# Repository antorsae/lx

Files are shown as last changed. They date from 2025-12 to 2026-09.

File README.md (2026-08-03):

# LX521 Polar Analysis Pipeline

A Python pipeline for processing acoustic polar response measurements from REW (Room EQ Wizard) and generating comprehensive visualizations for speaker driver analysis.

**Live Demo:** [https://antorsae.github.io/lx/](https://antorsae.github.io/lx/)

## Features

- Load and process `.mdat` measurement files via REW API
- Apply time gating to remove room reflections
- Support for multiple measurement sets with different naming conventions
- Full 360° polar plots when front and rear measurements are available
- Generate directivity analysis (DI, beamwidth)
- Interactive HTML plots (gzip compressed) and static PNG exports
- Interactive frequency response explorer with IIR EQ, per-driver gain/delay/invert, SUM view, and Hypex Filter Design `.dsp` + CamillaDSP YAML I/O (Config.xml conversion via external tools)
- Crossover match analysis for multi-driver systems
- **REW slot management**: Automatic batch unloading prevents hitting REW's ~100 measurement limit

## Requirements

- Python 3.11+
- [REW (Room EQ Wizard)](https://www.roomeqwizard.com/) with API enabled
- macOS (for automatic REW launch)

## Installation

```bash
# Create virtual environment with uv
uv venv
source .venv/bin/activate

# Install dependencies
uv pip install -r requirements.txt
```

## Configuration

Edit `config.py` to configure measurement sets:

```python
MEASUREMENT_SETS = {
    "andres": {
        "path": Path("measurements/andres"),
        "pattern_type": "andres",  # F{angle}-{driver}.mdat
        "has_rear": False,
        "hdf5_file": "polar_data_andres_l22mg_first_lobe.h5",
        "output_dir": OUTPUT_DIR / "andres",
    },
    "juan-baffleless": {
        # Combined Juan driver measurements (GRS PT6816, SS10F8414G10,
        # L22MG nude, ND25FW4 nude 18mm, L10NEO, MU10RB-SL,
        # SS10F8424G00, L26RO4Y).
        # Multi-source sets merge directories.
        "path": None,
        "sources": [
            {"path": Path("measurements/juan/GRS PT6816 A MIC ON AXIS"), "pattern_type": "juan"},
            {"path": Path("measurements/juan/ScanSpeak 10F8414G10"), "pattern_type": "scanspeak"},
            {"path": Path("measurements/juan/SEAS L22MG NUDE MIC ON AXIS"), "pattern_type": "juan"},
            {"path": Path("measurements/juan/DAYTON ND25FW4 ANIDADOS 18 MM NUDE"), "pattern_type": "juan"},
            {"path": Path("measurements/juan/POLARES L10NEO"), "pattern_type": "juan"},
            {"path": Path("measurements/juan/SEAS MU10RB SL POLARES"), "pattern_type": "juan"},
            {"path": Path("measurements/juan/ScanSpeak 10F8424G00"), "pattern_type": "juan_suffix"},
            {"path": Path("measurements/juan/L26RO4Y POLARES EN BAFFLE CILINDRICO VER NOTA"), "pattern_type": "juan"},
        ],
        "pattern_type": "juan",  # default (ignored when sources defined)
        "has_rear": True,
        "hdf5_file": "polar_data_juan_baffleless.h5",
        "output_dir": OUTPUT_DIR / "juan-baffleless",
        "measurement_metadata_overrides": {
            "L22MG (nude)": {
                "measurement_distance_m": 0.50,
                "measurement_height_reference": "l22mg",
                "notes": "Measurement distance: 50 cm from driver. Mic height: L22MG/LM.",
            },
        },
    },
    "lx521-system": {
        "path": Path("measurements/juan/LX521 POLARES 0_180 GRADOS"),
        "pattern_type": "lx521_system",  # {name} {angle} GRADOS {F|REAR}.mdat
        "has_rear": True,
        "hdf5_file": "polar_data_lx521_system.h5",
        "output_dir": OUTPUT_DIR / "lx521-system",
    },
}
```

### Supported Naming Conventions

| Pattern | Example | Description |
|---|---|---|
| `andres` | `F45-10F8424.mdat` | Front-only measurements |
| `kaspar` | `F0-UM MU10RB (Kaspar DSP).mdat` | Same shape as `andres`, kept separate from its combination-file and diagnostic-HDF5 rules |
| `juan` | `GRS PT6816 45 F.mdat` | Front (F) and Rear (R) measurements |
| `scanspeak` | `SS10F8414G10 45 F.mdat` | Same convention as `juan` |
| `juan_suffix` | `SS10F8424G00 45 F sn 074.mdat` | Same as `juan`, allowing text after `F`/`R` |
| `lx521_system` | `LX521 HIGH MID INV ORIGINAL 45 GRADOS F.mdat` | Full system measurements with GRADOS notation |

Measurement sources may be nested below each configured source directory. This supports source layouts such as `POLARES L10NEO/FRONTALES` and `POLARES L10NEO/TRASERAS`.

## Usage

### Enable REW API

1. Open REW
2. Go to Preferences → API
3. Enable the API server (default port: 4735)

### Run Pipeline

```bash
# Process default measurement set (andres)
python run_pipeline.py

# Process specific measurement set
python run_pipeline.py -m juan-baffleless

# Skip data loading (use existing HDF5)
python run_pipeline.py -m juan-baffleless --skip-loading

# Skip visualization generation
python run_pipeline.py --skip-viz

# Disable smoothing (raw data)
python run_pipeline.py --no-smoothing
```

### Command Line Options

| Option | Description |
|---|---|
| `-m, --measurement-set` | Which measurement set to process (default: andres) |
| `--skip-loading` | Skip REW loading, use existing HDF5 file |
| `--skip-viz` | Skip visualization generation |
| `--no-smoothing` | Disable frequency response smoothing (default: no smoothing) |

### Makefile Automation

```bash
make all              # Full rebuild: data + viz + sync
make data             # Load REW data → HDF5 (skips when HDF5 is newer than .mdat)
make viz              # Regenerate all visualizations (uses existing HDF5)
make viz-andres       # Regenerate only andres set
make sync             # Sync output/ to docs/ + regenerate landing pages
make deploy           # sync + commit + push to GitHub Pages
make help             # Show all targets
```

`make all` now runs `viz` and `sync` in parallel (default `JOBS=8`). Override with `JOBS=4 make all` or `make -j16 all`.

## Output Structure

```
output/
├── data/
│   ├── polar_data_andres_l22mg_first_lobe.h5 # Andres first-lobe validation target
│   ├── polar_data_andres.h5                  # Legacy strongest-lobe diagnostic
│   ├── polar_data_juan_baffleless.h5         # Processed data (juan-baffleless set)
│   ├── polar_data_kaspar.h5                  # Processed data (kaspar set, on-axis only)
│   └── polar_data_lx521_system.h5            # Processed data (lx521-system set)
├── andres/                            # Visualizations for andres set
│   ├── static_plots/
│   │   ├── core/                     # DI, beamwidth, contour plots
│   │   └── polar/                    # Polar diagrams
│   └── interactive/                  # HTML interactive plots (gzip compressed)
├── juan-baffleless/                   # Visualizations for juan-baffleless set
│   ├── static_plots/
│   └── interactive/
├── lx521-system/                      # Visualizations for lx521-system set
│   ├── static_plots/
│   └── interactive/
└── kaspar/                            # On-axis-only set: no static/polar plots
    └── interactive/                   # Frequency response explorer + summary
```

### On-Axis-Only Sets

A set with a single measurement angle sets `"single_angle": True` in its
config entry. Directivity, beamwidth, contour and polar output is skipped
(there is no angular coverage to compute it from), and only the frequency
response explorer and measurement summary are generated. Such a set is still
offered as a loadable overlay in every other set's explorer, but it is not
interpolated onto their angle grids — its curves are simply hidden at angles
it was not measured at.

Per-set `gate_left_ms`, `gate_right_ms` and `smoothing` keys override the
`config.py` defaults, for captures where the default 0.5/3.0 ms gate would
discard the band of interest.

## Pipeline Workflow

1. **Connect to REW API** - Launches REW if not running
2. **Load Measurements** - Reads `.mdat` files for each driver/angle
3. **Auto-fix Timing** - Aligns impulse response peak to t=0
4. **Apply Time Gating** - Removes room reflections (default: 0.5ms / 3.0ms)
5. **Get Frequency Response** - Retrieves magnitude/phase data
6. **Unload from REW** - Frees REW memory slots after each driver (batch unload)
7. **Save to HDF5** - Stores processed data for visualization
8. **Generate Visualizations** - Creates all plots and analysis

## REW Slot Management

REW has a limit of ~100 measurement slots. When processing many drivers, the pipeline automatically unloads measurements after each driver to prevent hitting this limit.

```python
# Manual control (if needed)
from polar_data_loader import PolarDataLoader

loader = PolarDataLoader(data_directory="path/to/data")

# Check current count
print(f"Loaded: {loader.get_measurement_count()}")

# Unload specific measurement
loader.unload_measurement(uuid)

# Unload all measurements
loader.unload_all_measurements()

# Disable batch unload (not recommended for large datasets)
data = loader.load_all_drivers(batch_unload=False)
```

## Generated Visualizations

### Static Plots (PNG)
- Directivity Index (DI) comparison
- Beamwidth curves (-3dB, -6dB)
- Dipole null analysis
- Normalized/Absolute contour plots
- Polar diagrams (single driver and overlaid)
- Crossover match analysis
- Frequency response by angle (absolute and normalized to 0°)

### Interactive Plots (HTML)
- DI comparison with hover info
- Beamwidth comparison
- Contour heatmaps
- Polar explorer with frequency slider and manual entry
- Crossover analysis per frequency
- **Multi-driver frequency response explorer** with:
  - Driver overlay comparison with distinct markers
  - Per-driver gain offsets, delay (us), and invert toggles
  - Angle toggle grid with quick-select buttons
  - SUM display (off / overlay / only) with optional phase
  - **IIR filter editor**: Peaking, HP, LP, Highshelf, Lowshelf filters
  - Visual crossover overlay (LR/BW) and auto-optimize tools
  - Real-time filter simulation on all angles
  - Hypex Filter Design `.dsp` import/export (not miniDSP), Config.xml conversion via external tools, and CamillaDSP-compatible YAML import/export
  - LocalStorage persistence for filters, crossovers, and UI state
  - Optional extra driver datasets (e.g., Juan baffleless) loaded on demand

## File Structure

| File | Description |
|---|---|
| `run_pipeline.py` | Main entry point |
| `config.py` | Configuration settings |
| `polar_data_loader.py` | REW API interface and data loading |
| `generate_visualizations.py` | Plot generation |
| `directivity_calculations.py` | Acoustic calculations |
| `Makefile` | Build automation (data → viz → docs → deploy) |
| `requirements.txt` | Python dependencies |

## Adding New Measurement Sets

1. Add entry to `MEASUREMENT_SETS` in `config.py`
2. If using a new naming pattern, add an entry to `_PATTERN_DEFS` (and/or `_PATTERN_ALIASES`) in `polar_data_loader.py`
3. Run: `python run_pipeline.py -m your_new_set`
4. Run `make sync` to publish regenerated output under `docs/`

## License

MIT

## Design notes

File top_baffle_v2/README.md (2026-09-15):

# Open-baffle experiments — Stock, Slim and Obiwan

Inspired by **Siegfried Linkwitz’s ideas and openness in sharing his work**,
this project explores a compromise in his design: the roughly **7.5 kHz
crossover between the upper midrange and tweeters**. A high crossover helped
preserve the intended dipole radiation pattern through that transition,
leaving the small upper-midrange driver covering roughly **1–7.5 kHz**.
See Linkwitz’s [design rationale](https://www.linkwitzlab.com/LX521/Description.htm)
and [frequency-range discussion](https://www.linkwitzlab.com/LX521/FAQ.htm).

The goal is to explore alternative tweeters, waveguides and baffle shapes
that support **a lower crossover while preserving dipole behavior**. By
handing more of the high-frequency work to the tweeters, we aim to reduce
upper-midrange distortion and improve the performance of the whole system.
Measurements of directivity and distortion, together with listening
comparisons, will determine whether that goal is achieved.

**Stock and Slim** closely follow Linkwitz’s baffle design. **Obiwan** is a
new modular design built as an experimentation platform: interchangeable
tweeter arrangements and quickly removable wings make it easier to compare
drivers, waveguides and acoustic boundaries without rebuilding the entire
baffle.

## Build and print

**The current manufacturing target is the Bambu H2C with two 0.6 mm High
Flow nozzles.** Start with the [H2C file guide](to_print/h2c/README.md) for
STLs, editable projects, audited slices, materials and per-speaker quantities.
`make` now builds the H2C shelf; `make PRINTER=P2S all` selects the earlier
pipeline. The pre-migration source checkpoint and rewritten commit references
are recorded in the [generated-file history guide](docs/GENERATED_HISTORY.md).

H2C uses one LM carrier for Obiwan and one full wing per side, including
Dayton ND25FN-4 waveguide wings. Stock/Slim use one complete LM without the stand, or two
LM pieces with the stand, plus their matching upper module. Driver spacing
and mounting seats remain unchanged. The Dayton ND25FN-4 waveguide has separate PETG-GF/PLA and
PETG Translucent/PLA Translucent projects.

Choose one mounting state and one complete configuration per speaker.

The earlier [P2S build guide](docs/BUILD_GUIDE.md) remains a hardware and
assembly reference. Its generated P2S
[file guide](to_print/FILE_GUIDE.md) lists all 42 choices and actual sliced
job estimates. There are 68 sliced projects and 8 projects requiring GUI
slicing across alternate nozzle/material lanes.

The [complete parts and magnet catalog (PNG)](images/generated/catalog/ALL_ITEMS_MAGNET_CATALOG.png)
shows the 78 pre-H2C part variants, their buried magnet locations and types,
shared parts, alternate tweeters and separate test fixtures. The accompanying
[file map](images/generated/catalog/README.md) identifies every source.

For H2C material mapping and process exceptions, use the generated
[H2C file guide](to_print/h2c/README.md). The shared [print and hardware
policies](docs/PRINT_POLICIES.md) retain the earlier printer details: structural LM/UM infill is 100%, wings
are 10%, and the Dayton ND25FN-4 waveguide uses M3 fasteners. The [current update
report](review/print_policy_update_20260912/SUMMARY.md) links the regenerated
print files, support exceptions and D6 magnet test pair.

Stock is the canonical CAD baseline. Slim is experimental. Obi-Wan and BMR
options are qualification candidates; printed fit, long-term loaded behavior
and acoustic performance are not established by CAD renders or passing code
checks. See the [current test procedure](docs/PETG_GF_QUALIFICATION.md).

## Product comparison

One row per product, each showing both stand states, then one row for the
tweeter options. Every render uses one camera and one declared frame per scale
group, so the panels within a row and the three product rows against each
other are directly comparable. Regenerate the product rows with
`make iso_matrix`; `make h2c_review` also refreshes the upper and wing comparisons.

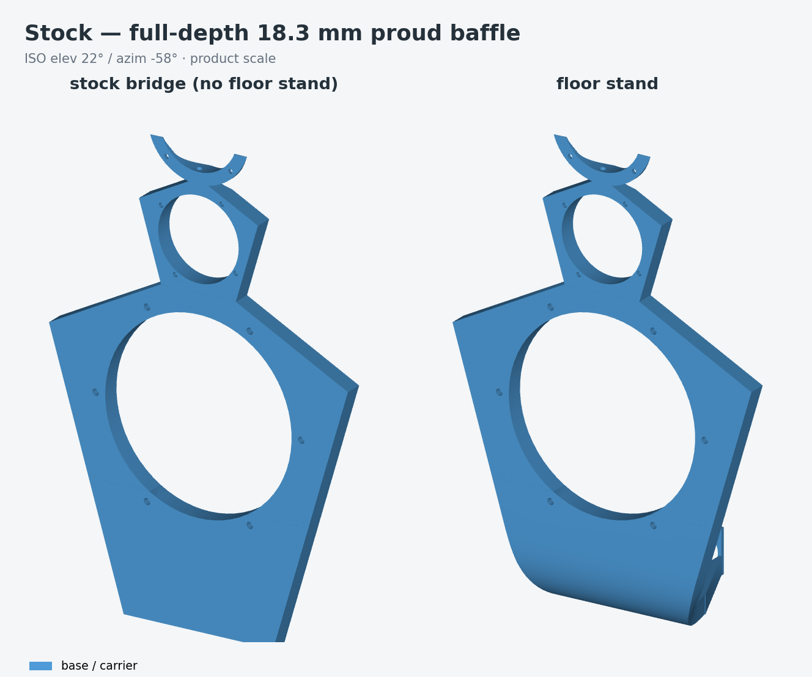
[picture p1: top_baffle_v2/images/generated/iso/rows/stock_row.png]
Stock, both stand states


Stock is the canonical product: the complete 18.3 mm outline, with two core
pieces on H2C without the stand or three with the stand. The earlier P2S
split uses four — [`docs/stock.md`](docs/stock.md).

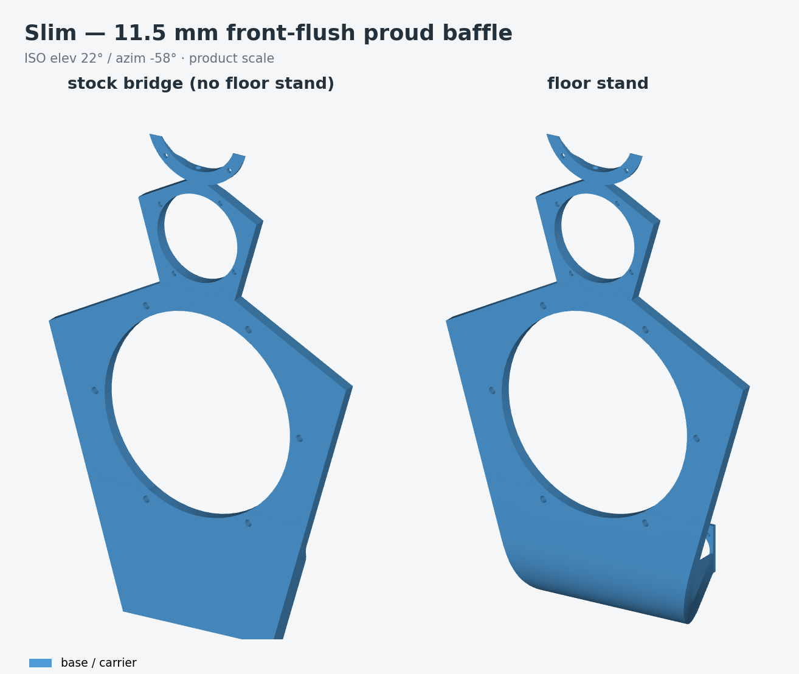
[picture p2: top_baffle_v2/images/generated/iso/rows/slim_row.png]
Slim, both stand states


Slim is the same outline with the acoustic field thinned to 11.5 mm, sharing
one front plane end to end — [`docs/slim.md`](docs/slim.md).

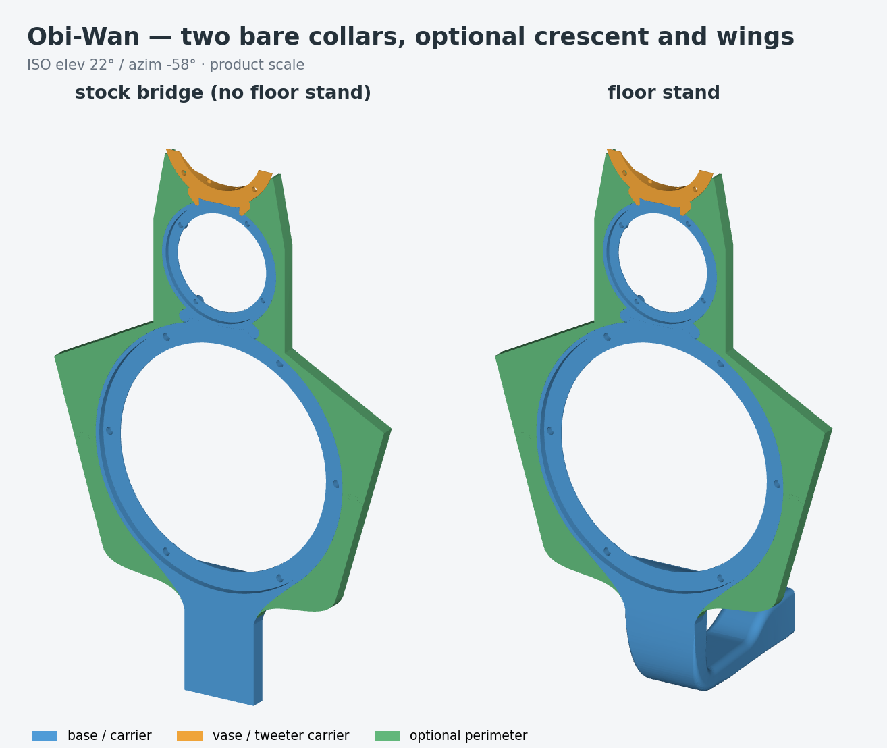
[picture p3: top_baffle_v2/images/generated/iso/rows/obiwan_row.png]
Obi-Wan, both stand states


These two Obiwan panels show the regular UM, ND25FW-4 crescent and flat
wings. The integrated ND25FN-4 upper is a second body choice on the same LM,
shown alongside the regular uppers below — [`docs/obiwan.md`](docs/obiwan.md).

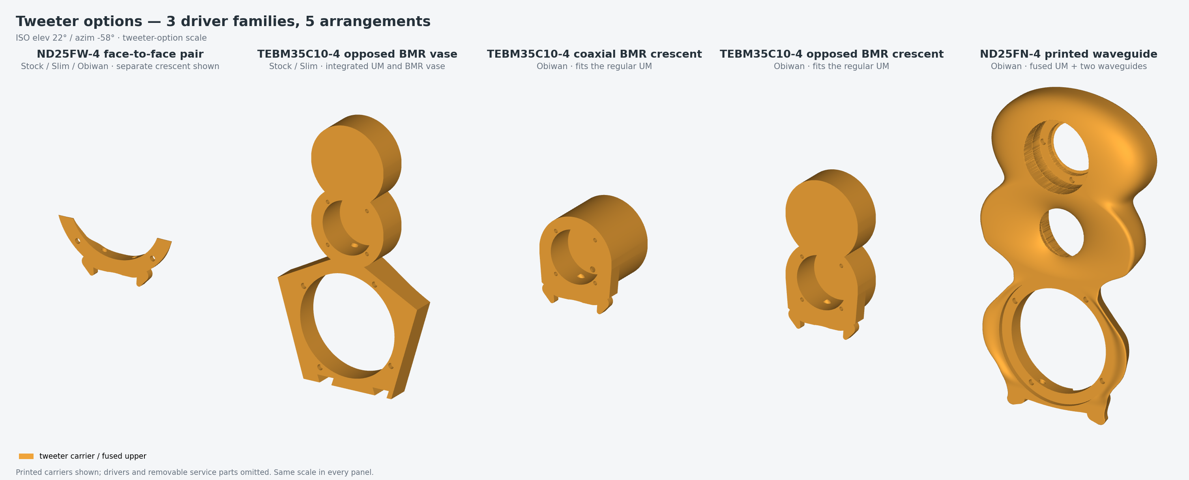
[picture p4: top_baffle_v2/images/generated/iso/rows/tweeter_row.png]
Three tweeter families, five arrangements, at the same scale


Left to right: ND25FW-4 crescent; BMR Stock/Slim vase; BMR Obiwan coaxial
crescent; BMR Obiwan opposed crescent; **ND25FN-4 integrated UM/waveguide**.
These are the actual printed carriers at one scale. Drivers and removable
service caps are omitted so their construction can be compared.

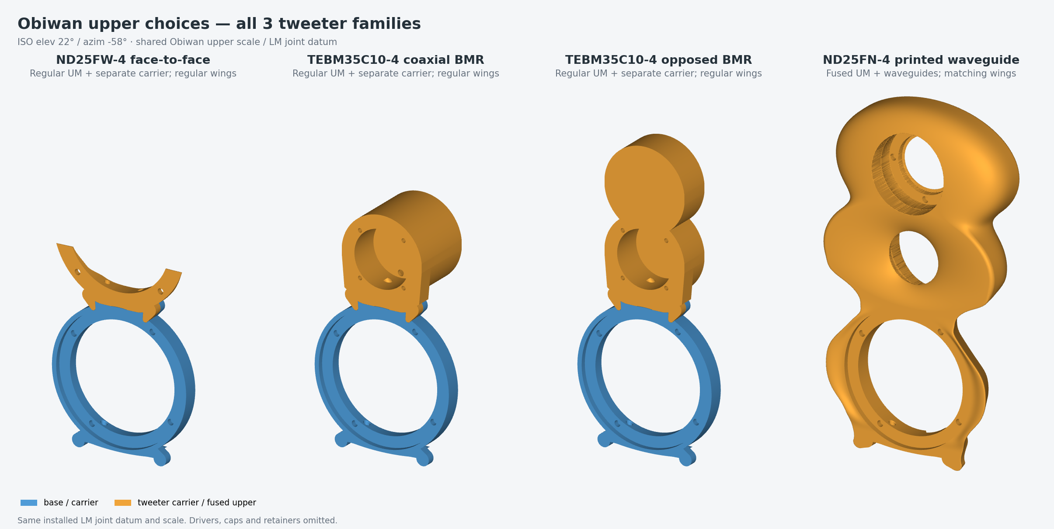
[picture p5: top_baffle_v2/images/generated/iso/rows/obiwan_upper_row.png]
Obiwan complete upper choices, aligned at the common LM joint


The complete Obiwan uppers share the same LM joint datum in this row:
ND25FW-4, coaxial BMR, opposed BMR and ND25FN-4 waveguide. The first three
retain the regular UM; the fourth includes its UM in the curved body.

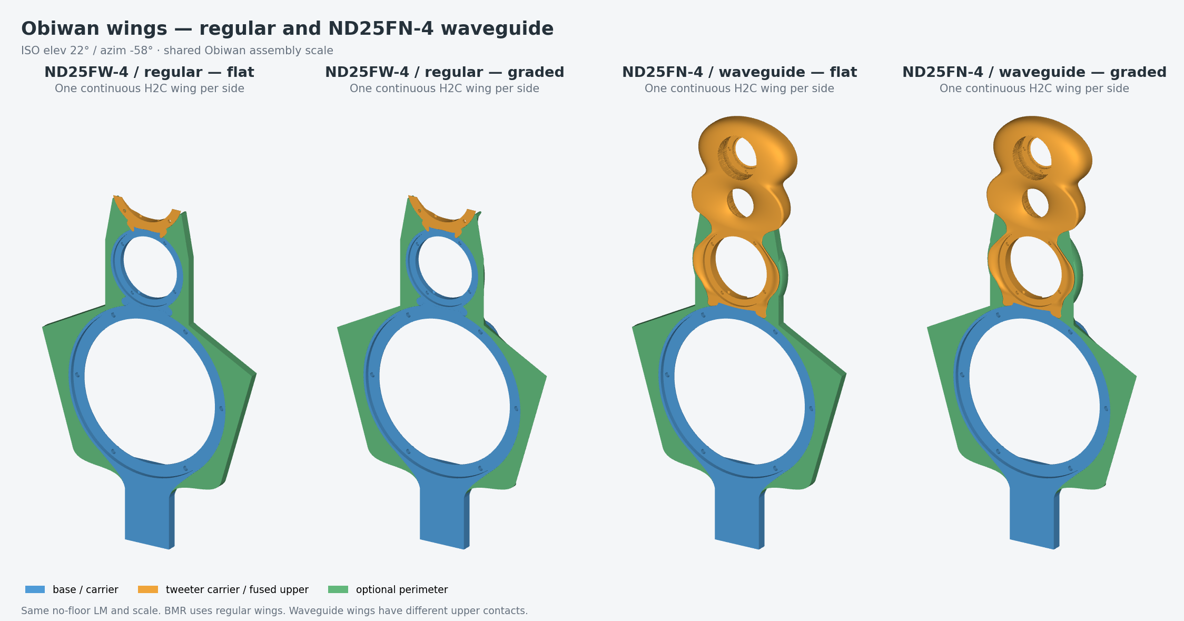
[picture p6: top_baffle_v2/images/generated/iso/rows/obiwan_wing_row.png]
Regular and ND25FN-4 Obiwan assemblies with flat and graded H2C wings


Choose flat or graded wings to match the selected upper. The two regular
wing styles fit ND25FW-4 and BMR. ND25FN-4 uses its own curved upper contacts
and matching wings, shown on the same no-floor-stand LM here.

## Tweeter options

The project offers **three tweeter families**. BMR has multiple mount layouts;
those layouts are alternatives within one driver family.

| Tweeter family | Construction | Stock / Slim | Obiwan |
|---|---|---|---|
| **Dayton ND25FW-4 face-to-face** | Two domes with factory waveguide faceplates | Standard upper module with integral crescent | Separate crescent on the regular UM |
| **Tectonic TEBM35C10-4 BMR** | Two balanced-mode radiators; opposed or coaxial layout | Replace the whole upper module with the opposed-BMR version | Choose the coaxial or opposed BMR crescent on the regular UM |
| **Dayton ND25FN-4 waveguide** | Two faceplate-free domes in printed front/rear waveguides | No compatible upper module currently provided | Replace the whole UM and crescent with one fused body; use the matching waveguide wings |

The **ND25FN-4 waveguide** is the former retained-package design, now named
for its driver and construction. Its organic MU10 surround and tweeter
waveguides form one piece, with an enclosed cable gallery, two service caps
and two M3 retainers. The same body fits both Obiwan stand configurations;
it retains the LM joint and meets the LM front flush without covering it.
H2C provides one continuous matching wing per side, in flat or graded form.
Regular Obiwan wings have different upper contacts and cannot substitute.
Stock/Slim BMR uppers also have different magnet stations: their matching
perimeter is not supplied, so use the standard shoulders or B1 wings only
with ND25FW-4.

Start with the [three-family selection guide](docs/TWEETER_OPTIONS.md) and
[Dayton ND25FN-4 waveguide assembly guide](docs/DAYTON_ND25FN4_WAVEGUIDE.md).
The [H2C file catalog](to_print/h2c/README.md) includes all three families,
with separate PETG-GF/PLA and PETG Translucent/PLA Translucent jobs for the
ND25FN-4 body, accessories and wings. BMR and ND25FN-4 remain qualification
candidates: inclusion and successful slice checks do not establish physical
fit, retention or acoustic performance. The earlier P2S catalog and CAD-only
BMR-slim variants are documented separately in [Variants](docs/VARIANTS.md).

The separate Purifi PTT1.3 experiment remains in
`build/ptt_crescent_PTT1.3T04-HAG-01/`; it is not one of the three supported
selection families in the current H2C print catalog.

## Products

The current print catalog is [H2C](to_print/h2c/README.md). The earlier
product-grouped CAD facade is:
[`artifacts/`](artifacts/README.md).

| Product | Geometry | Optional perimeter | Tweeter options | Status | Doc |
|---|---|---|---|---|---|
| [Stock](artifacts/stock/) | B2, 304.802 x 453.457 x 18.3 mm | A-comp shoulders **or** B1 wings | ND25FW-4 crescent (integral) or TEBM35C10-4 BMR vase | Canonical CAD | [`docs/stock.md`](docs/stock.md) |
| [Slim](artifacts/slim/) | V1L + V1; 11.5 mm front-flush acoustic field, full-depth bottom strip | matching V1 shoulders **or** V1 wings | ND25FW-4 crescent (integral) or TEBM35C10-4 BMR vase | Experimental | [`docs/slim.md`](docs/slim.md) |
| [Obiwan](artifacts/obiwan/) | LM + regular UM or integrated UM/waveguide; floor and stock-bridge states | flat or graded wings matched to the upper | ND25FW-4 crescent, coaxial/opposed BMR crescent, or fused ND25FN-4 waveguide + UM | Candidate; not release-authorized | [`docs/obiwan.md`](docs/obiwan.md) |

The original state-oriented build outputs remain in `build/floor_stand/`,
`build/no_floor_stand/`, and `build/wings/` because the validation pipeline depends on
them. `artifacts/` adds stable names, hashes, and product grouping through
relative links without duplicating large CAD files. See
[`docs/PROJECT_SCOPE.md`](docs/PROJECT_SCOPE.md) for the intent, assumptions,
and release boundary; [`docs/REPOSITORY_STRUCTURE.md`](docs/REPOSITORY_STRUCTURE.md)
documents the implemented source/package and generated-state boundary.

## Use the delivered files

Open the [H2C file guide](to_print/h2c/README.md), choose a compatible
configuration and material lane, and use its editable `.3mf` or audited
`.gcode.3mf`. Those projects retain the supports, infill modifiers and
measured magnet insertion pauses. An STL contains geometry only.

```sh
make h2c_prepare        # prepare H2C projects from current geometry
make h2c_validate       # slice and audit; reuse current verified results
make h2c_review         # upright assembly views
make h2c_docs           # refresh the file and tweeter-family guides
```

The [earlier P2S file guide](to_print/FILE_GUIDE.md) remains available for
that printer. Its material mapping and split wings are specific to P2S.
No ZIP is required for either workflow.

## Develop and regenerate

Use Python with the dependencies in `cad-remote-requirements.lock`. The
vendored driver references are self-contained under `vendor/SEAS/`; no
sibling checkout is needed for those inputs. VTK renders CAD with an actual
depth buffer, and Matplotlib/Pillow compose the comparison panels.

```sh
make PYTHON=<venv>/bin/python             # current H2C pipeline
make PRINTER=P2S artifacts          # relink and rehash the CAD facade
make PRINTER=P2S iso_matrix # regenerate the CAD comparison images
make PRINTER=P2S delivery_refresh # bind already-published files and regenerate the file guide
```

The current H2C pipeline runs locally. The earlier P2S CAD pipeline defaults
to the original maintainer's remote host `osado.lan`; select
`LX_CAD_EXECUTION=local` when running that pipeline on another workstation. Remote execution,
resource limits and promotion are documented in [REMOTE_BUILD.md](docs/REMOTE_BUILD.md).
A source change requires current CAD/slice provenance before republishing;
validation does not silently regenerate or re-certify old geometry.

## Generated artifact layout

Current H2C manufacturing outputs live in `build/h2c/`; the current print
catalog lives in `to_print/h2c/`. Both stand states are included. The earlier
P2S pipeline and the shared source authorities use the following layout:

    build/floor_stand/      LX_STAND_FOOT=1: Stock/Slim fused foot + NL8 panel;
      stl/  *.step  *.png     Obi-Wan integral LM-owned W64 floor stem/foot + NL8 panel
    build/no_floor_stand/   LX_STAND_FOOT=0: Stock/Slim flat piece_bottom + bridge;
      stl/  *.step  *.png     Obi-Wan solid bridge web fused into the LM core
    build/wings/{flat,graded}/    Obi-Wan acoustic wing families
    build/vase_TEBM35C10-4/{stock,slim}/   opposed-BMR vase, full Ø63 lands
    build/bmr_slim_TEBM35C10-4/proud/{stock,slim}/  Ø56-core/lobed vase alternatives
    build/bmr_crescent_TEBM35C10-4/       candidate BMR crescents, both variants
    build/bmr_slim_TEBM35C10-4/           lobed Obi-Wan CAD-only candidates
    build/common/           flag-independent shared outputs
    images/generated/iso/   the product-comparison cells and rows/ images

Each folder contains all proud-family variants and the matching Obi-Wan
core/add-on set. In Stock and Slim, `piece_bottom` is the only functionally
different base piece; the other base STLs can differ by <0.05 mm as
the foot-entry knots move. In Obi-Wan, the UM core is state-independent. The
floor LM owns the integral stand and only the shared upper shoulder; the
no-floor LM owns the complete fused bridge web. Their lower magnet axes are
coincident on that shoulder, but floor mode has no shallow skirt or rail below
it.
`build/common/attachments.step` is flag-independent and is
promoted as one shared file. The `LX_STAND_FOOT` environment flag defaults to 1.

Per-product printable-piece tables live in the product docs. The two
product-independent STL groups are:

| STL in `build/<state>/stl/` | Footprint (mm) | Used by |
|---|---|---|
| `lx521_coupon_*` | small blocks/gauges | calibration, routing, and clocking checks ([`docs/PRINTING.md`](docs/PRINTING.md)) |
| lx521_polar_base_1..2of2 | Ø216 / 169×185 | polar-measurement turntable under the stand foot (floor_stand only) |

## Shared source and evidence map

Geometry modules are listed in each product's doc. These are the shared
entry points:

| File | What |
|---|---|
| `scripts/export_piece_stls.py` | Exports the print-ready proud-family or Obi-Wan core/add-on STLs (`--variant`, `--outdir`) and one exact adjacent, hash-bound `.print.json` authority for every STL |
| `scripts/export_steps.py` | Exports a module's `gen_step()` to STEP via build123d's native exporter (`<module.py> --output <path>`) — no CAD-skill dependency |
| `scripts/gen_product_iso_matrix.py` | Renders the standardized product-comparison ISO set into `images/generated/iso/` from the promoted STEP files; one shared camera, one declared frame per scale group |
| `Makefile` | Generates STEPs/STLs/PNGs for both stand states into `build/floor_stand/` and `build/no_floor_stand/` (see "Generated artifact layout"). Local OCC jobs are serial; the remote executor uses bounded parallel slots, and every CAD subprocess runs through `scripts/run_memory_guarded.py`. |
| `scripts/remote_cad.py` / `cad-remote-requirements.lock` | Content-addressed SSH executor, resumable job control, verified artifact return, and exact remote Python environment |
| `review/captive_magnet_slice_audit/CAPTIVE_MAGNET_PAUSE_MANIFEST.md` | Authoritative per-STL front-face-down orientation, actual sliced open/closing layers, Bambu Custom park/pause/restore events, grouped magnet counts, and local-axis polarity |
| `review/CAPTIVE_MAGNET_ARTIFACT_INVENTORY.md` | Clickable inventory of all 58 magnet-bearing STL records, their 56 locally generated/directly loadable G-code-bearing Bambu 3MF projects, descriptive piece names, and exact magnet counts; also reconciles the 86 transverse and eight exact split-proxy stations |
| `build/<state>/stl/*.stl` and `build/wings/{flat,graded}/stl/*.stl` | The enforced acoustic-print inventory is 39 nonpolar front-face-down STL/sidecar pairs in each stand state plus ten flat and ten graded pairs: 98 exact pairs total. Every acoustic piece is source-X180 with only an optional in-bed Z rotation and its front datum at STL Z=0. A missing, orphaned, stale-hash, tilted, or translation-inconsistent `<stem>.print.json` fails release validation. The two floor polar-index jigs are the sole orientation-sidecar exclusions because they are fixtures with no acoustic front-face datum. |

The generated directories are **candidate packages**, not physical-release
authorization: even `make release` performs CAD, artifact and manifold checks
only, and the Obi-Wan state manifests record `release_authorized: false`.

## Documentation

Products:

- [`docs/stock.md`](docs/stock.md) — Stock: key dimensions, print split,
  proud cable routing, magnet attachment, assembly.
- [`docs/slim.md`](docs/slim.md) — Slim: V1 vase, V1L LM section, the
  keyed 283° UM outlet.
- [`docs/obiwan.md`](docs/obiwan.md) — Obi-Wan: two-collar geometry,
  buried routes, floor/no-floor structure, structural screens, assembly.

Cross-cutting authorities:

- [`docs/PROJECT_SCOPE.md`](docs/PROJECT_SCOPE.md) — intent, three-product
  inventory, CAD brief, assumptions, release boundary.
- [`docs/REPOSITORY_STRUCTURE.md`](docs/REPOSITORY_STRUCTURE.md) — layout and
  the source/generated-state boundary.
- [`docs/VARIANTS.md`](docs/VARIANTS.md) — variant/add-on catalog, envelope
  compatibility matrix, hardware, and retired C7/V0 design history.
- [`docs/PRINTING.md`](docs/PRINTING.md) — filament, slicer profile, coupons,
  fastener torques, insert installation, magnet pauses, print constraints.
- [`docs/REMOTE_BUILD.md`](docs/REMOTE_BUILD.md) — remote executor, cache
  seeding, promotion transaction, memory profiles.
- [`docs/CAPTIVE_MAGNET_SLICING.md`](docs/CAPTIVE_MAGNET_SLICING.md) — pause
  and embed workflow.
- [`docs/obiwan_acoustic_wings_spec.md`](docs/obiwan_acoustic_wings_spec.md) —
  flat/graded wing design authority.
- [`docs/obiwan_physical_qualification.md`](docs/obiwan_physical_qualification.md)
  — fail-closed physical qualification record.
- [`docs/README.md`](docs/README.md) — the complete documentation index.

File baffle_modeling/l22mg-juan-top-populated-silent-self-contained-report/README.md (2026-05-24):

# L22MG Juan Top-Baffle Populated-Silent Modeling Report

Generated: 2026-05-24

## Summary

No current populated-silent model passes the acceptance gate. The full 300-1200 Hz normalized-polar RMS target is `<= 1.5 dB`; the best full-band result is `4.088 dB`.

The dominant blocker is the measured Juan top-baffle target null at `300.293 Hz / 75 deg`. At that point the L22-alone target is `-29.894 dB` normalized, while the naked L22 measurement is `-9.594 dB`; the implied top-minus-nude transfer is `-20.300 dB`. The separate top-baffle combo capture is `-18.024 dB` at the same point, or `+11.870 dB` above the L22-alone target. This is a target-quality/repeatability warning, not an approved data exclusion.

Under the repo's existing diagnostic `target > -20 dB` mask, the best current model is `modal full2 populated` at `1.587 dB`, narrowly ahead of `compact2 populated` at `1.594 dB`. That diagnostic is close to the `1.5 dB` target, but it is not the acceptance calculation.

## Policy Alignment

- Validation source: `output/data/polar_data_juan_baffleless.h5`, driver `L22MG (nude)`.
- Validation target: `output/data/polar_data_juan_lx521_top_raw.h5`, driver `L22MG (LX521 top raw)`.
- Target angles: HDF5 target angles `[0, 15, 30, 45, 60, 75, 90]`; no angular interpolation.
- IR peak policy: `direct_ir_peak_policy=first-strong`, mirrored from the published target artifact.
- Passive treatment: `populated-silent`; passive UM/tweeter driver positions are modeled as populated/solid silent obstructions, not open holes.
- Validation alignment: one global scalar gain plus one global delay only; no angle, band, rear, or source dB fitting.

## Baffle and Measurement Renders

The modeled baffle is the LX521 top baffle with the L22 cutout and populated-silent passive positions. The 3D panel is the OBJ mesh emitted by the current compact2 artifact.

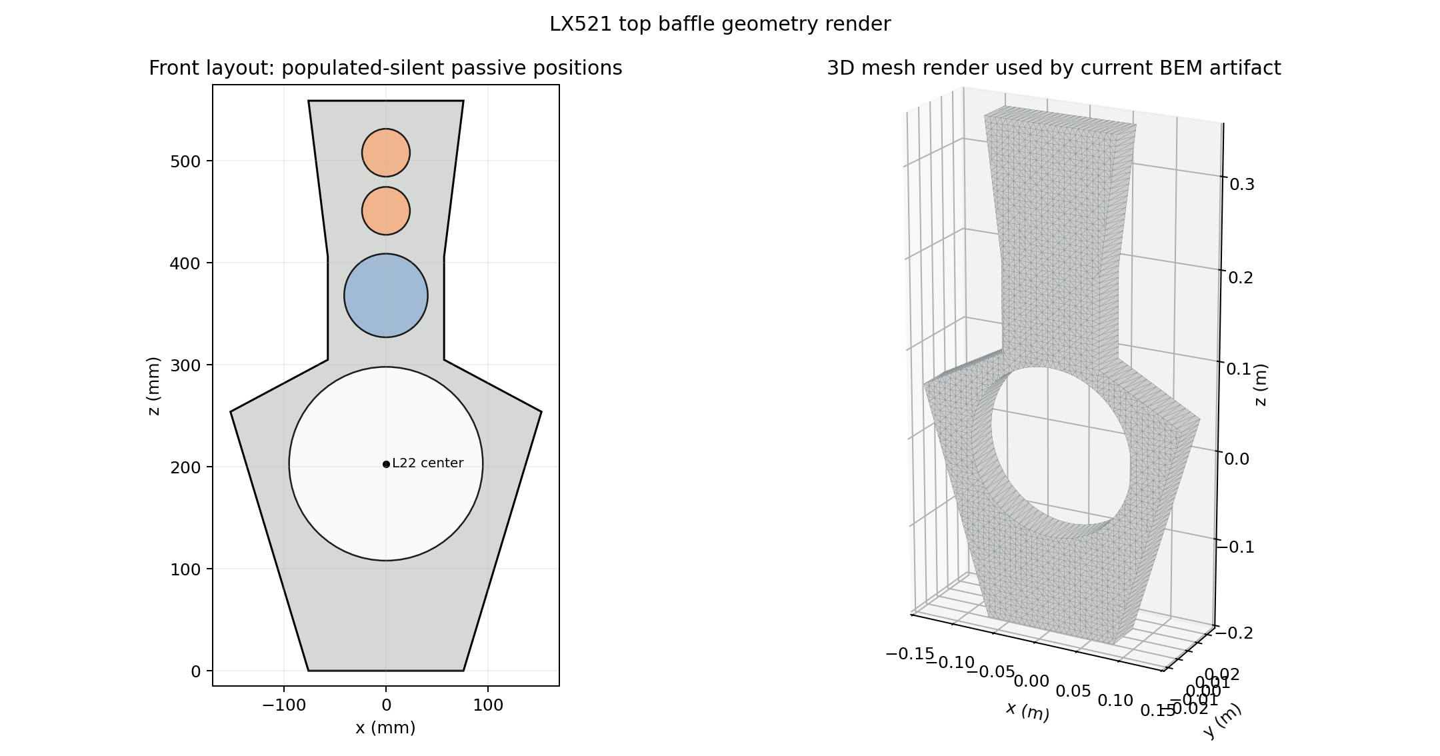
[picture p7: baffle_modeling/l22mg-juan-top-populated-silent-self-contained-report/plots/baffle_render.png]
LX521 top baffle render


The measurement render shows the naked L22 source measurement, the L22-only top-baffle target, the top-baffle combo capture, and the target-minus-naked transfer. The white/black `x` marks the `300.293 Hz / 75 deg` target null.

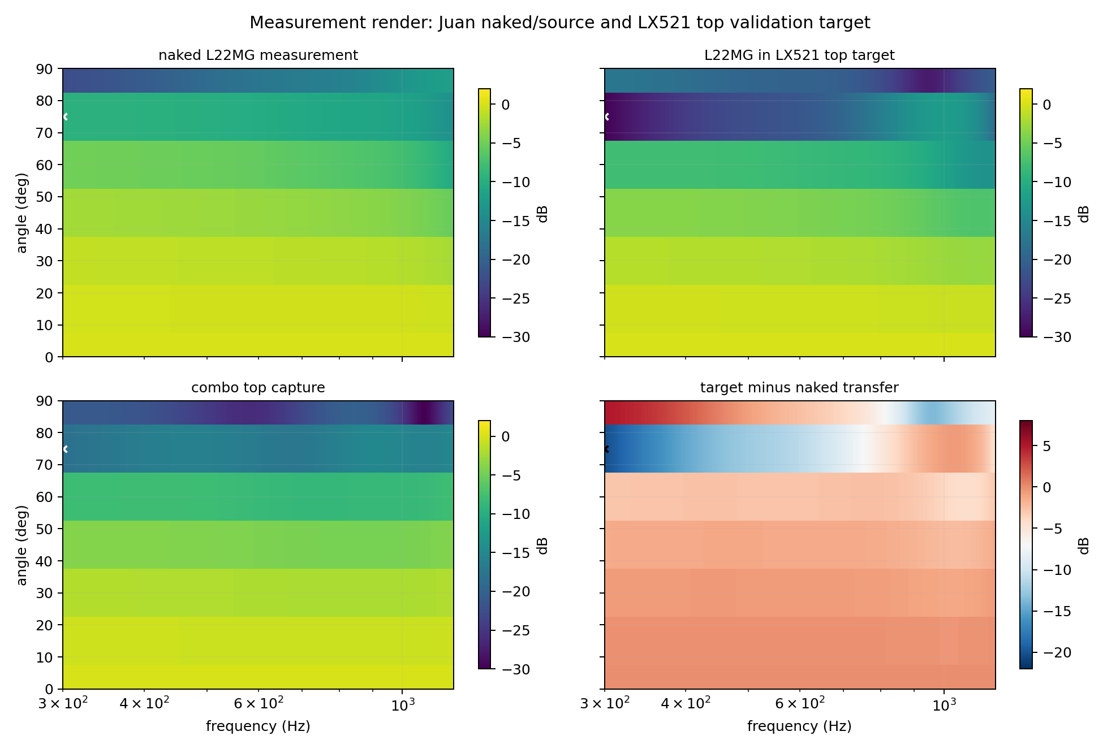
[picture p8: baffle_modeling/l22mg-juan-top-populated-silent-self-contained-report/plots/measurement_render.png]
Measurement render


## Models Tried

| model | intent | full RMS | exact 300/75 removed | deep-null cluster removed | target > -20 dB | <=60 deg | <=80 deg | worst residual |
| --- | --- | ---: | ---: | ---: | ---: | ---: | ---: | --- |
| axisym directivity populated | diagnostic axisymmetric directivity table | 4.088 | 4.086 | 3.702 | 1.792 | 1.383 | 3.302 | +18.779 dB @ 300 Hz / 75 deg |
| compact2 populated | canonical split axisymmetric H1659 compact2 source | 4.219 | 4.217 | 3.826 | 1.594 | 1.009 | 3.497 | +18.476 dB @ 300 Hz / 75 deg |
| modal full2 populated | fuller H1659 modal source | 4.244 | 4.242 | 3.852 | 1.587 | 1.001 | 3.507 | +18.487 dB @ 300 Hz / 75 deg |
| axisym thick30 | thickness sensitivity on axisymmetric source | 4.652 | 4.650 | 4.400 | 2.706 | 1.464 | 3.367 | +16.495 dB @ 300 Hz / 75 deg |
| D65 R25 ACM -20 mm | split discrete monopole cloud/acoustic-center probe | 5.707 | 5.707 | 5.668 | 4.639 | 4.409 | 4.471 | -16.075 dB @ 756 Hz / 60 deg |
| split active surface | split active surface Neumann source | 6.252 | 6.249 | 5.776 | 3.639 | 1.801 | 5.279 | +24.209 dB @ 300 Hz / 75 deg |
| active surface plain | active surface Neumann source | 8.334 | 8.334 | 8.347 | 5.538 | 3.300 | 5.575 | +23.619 dB @ 933 Hz / 90 deg |
| active feature proxy coarse | rear-basket/feature active proxy | 9.279 | 9.277 | 8.861 | 6.362 | 4.625 | 7.104 | +27.834 dB @ 300 Hz / 75 deg |
| active piston | piston-like active source diagnostic | 10.550 | 10.548 | 10.153 | 6.942 | 4.055 | 8.050 | +29.599 dB @ 300 Hz / 75 deg |

The stale width-sweep rerank contained a W405 row at `3.891 dB`, but that row predates the IR-policy metadata alignment and is not promoted here.

## Ranking Plot

The full-band rank favors the axisymmetric directivity diagnostic. The diagnostic `target > -20 dB` mask favors `modal full2 populated`, with `compact2 populated` effectively tied. All bars remain to the right of the `1.5 dB` acceptance gate except the non-acceptance diagnostic values that are still slightly above it.

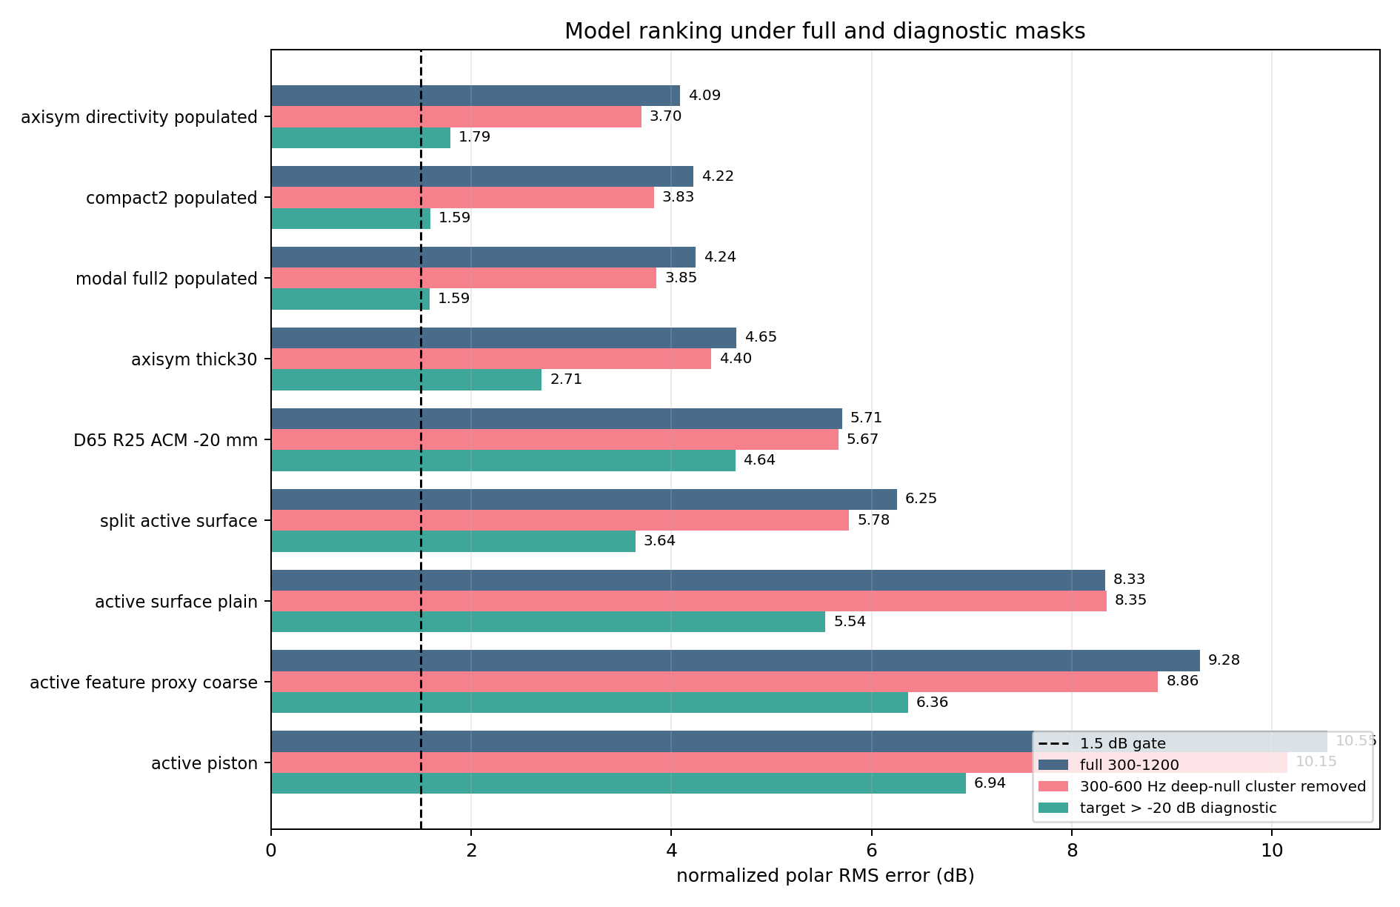
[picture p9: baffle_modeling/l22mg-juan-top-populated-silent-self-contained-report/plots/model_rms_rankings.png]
Model RMS rankings


## Error Maps

All credible current candidates share the same main residual: they do not reproduce the very deep 300 Hz high-angle target null. The active-surface and piston variants introduce larger residual structures elsewhere, so they are not viable improvements.

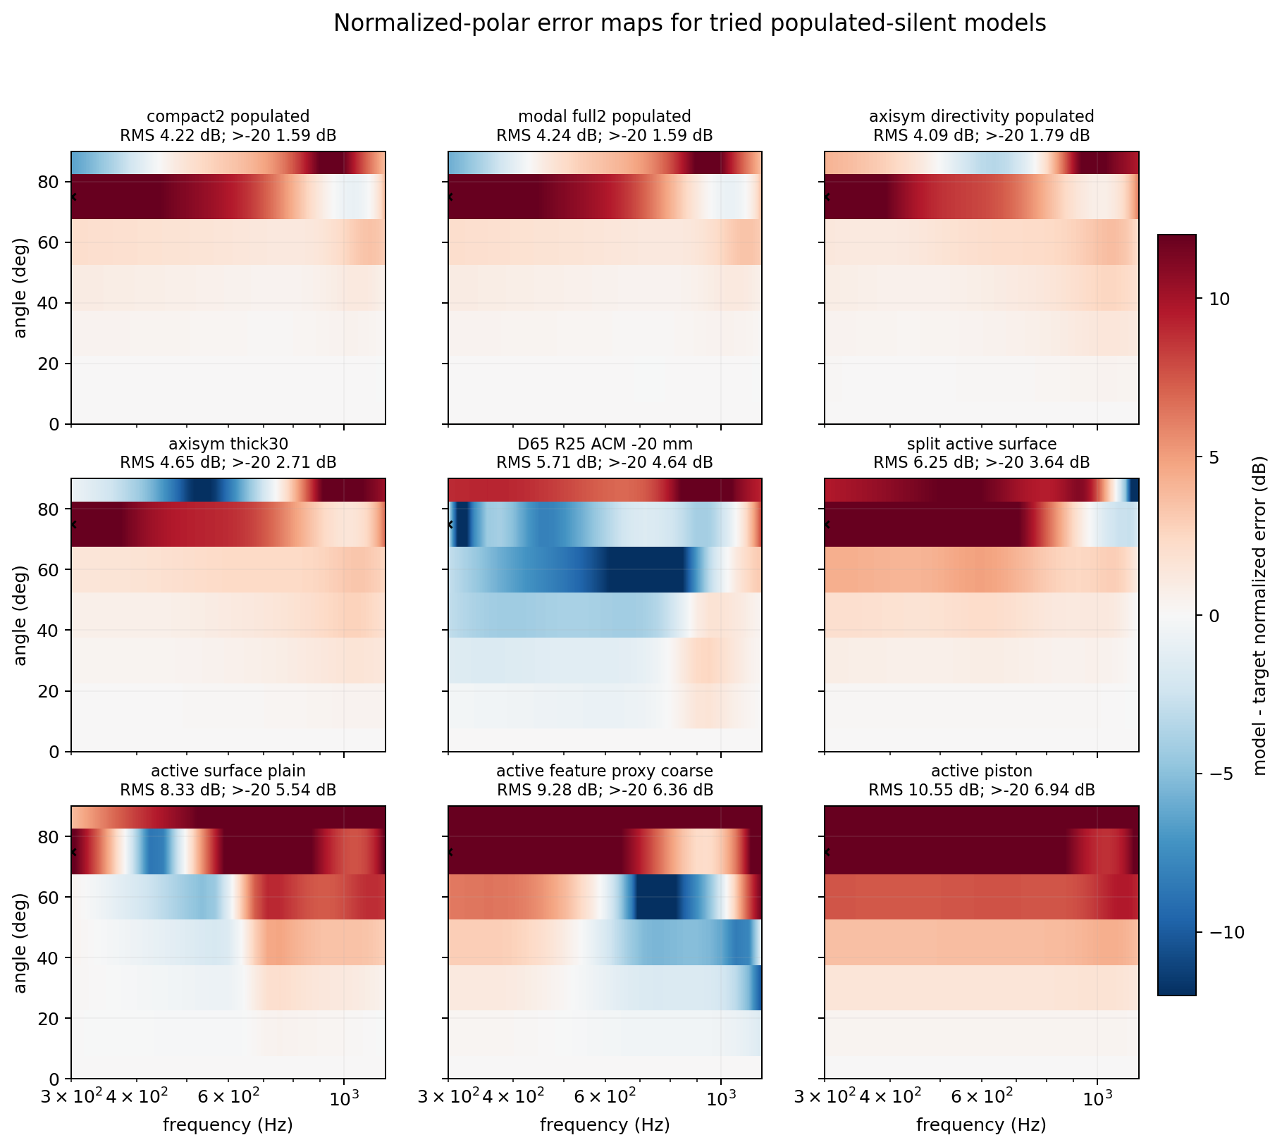
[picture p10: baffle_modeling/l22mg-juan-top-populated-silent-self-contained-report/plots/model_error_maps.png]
Model error maps


## High-Angle Curves

The 60 deg curves are already near the target. The failure starts at 75 deg and remains visible at 90 deg. The top three current candidates are close to each other at 75 deg and miss the 300 Hz null by roughly the same order.

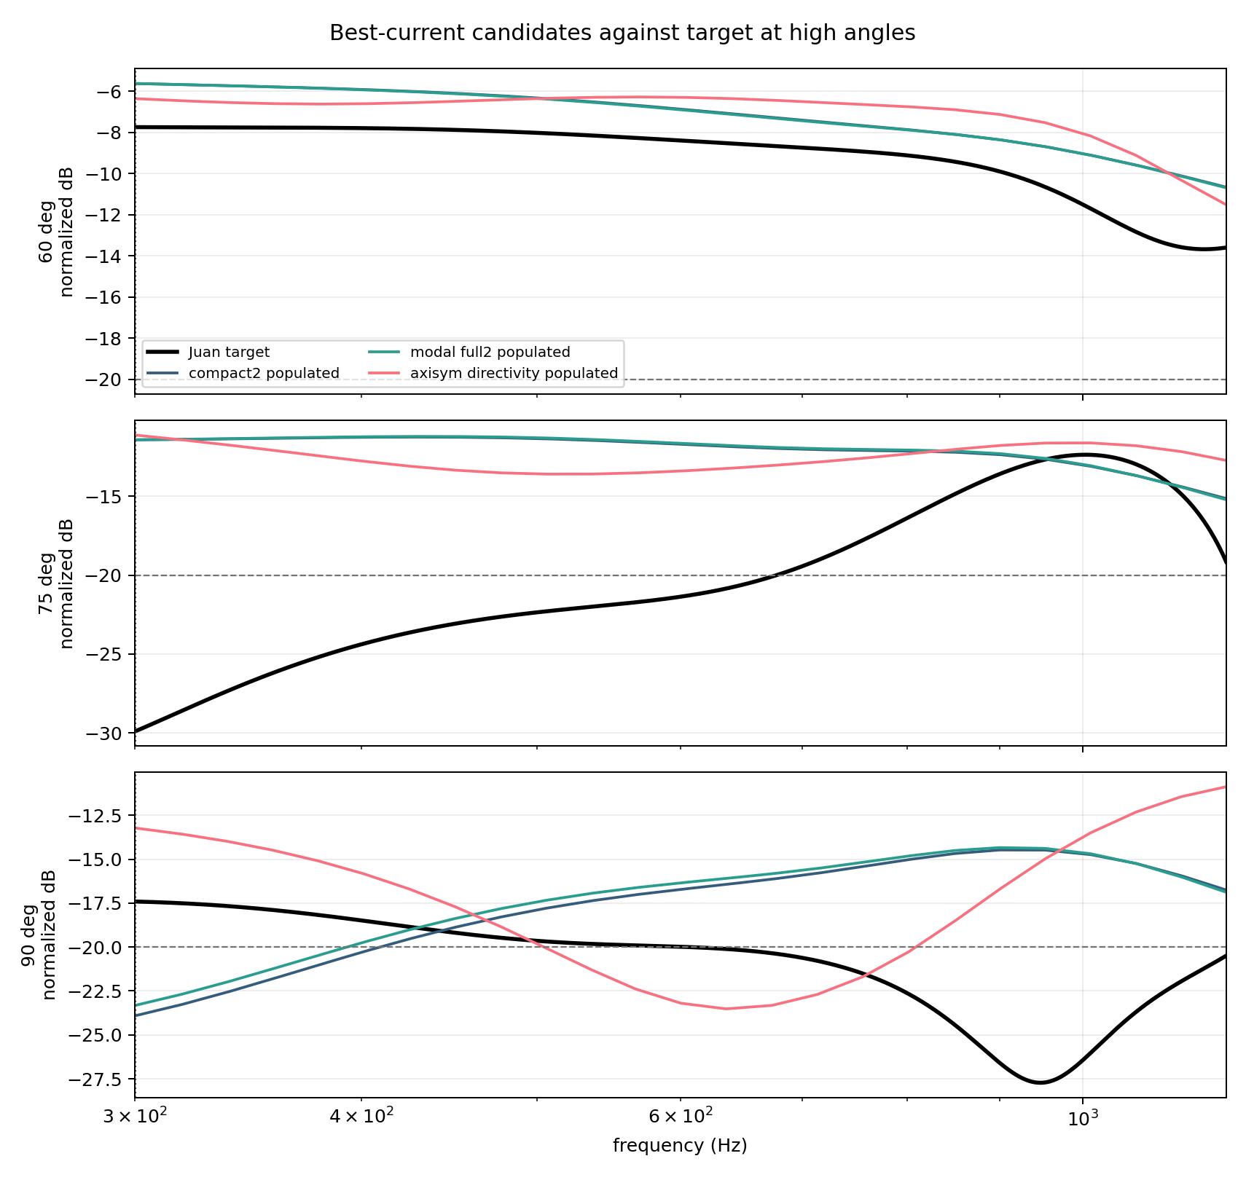
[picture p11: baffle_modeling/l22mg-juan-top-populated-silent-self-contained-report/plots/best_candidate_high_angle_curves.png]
Best candidate high-angle curves


## 300 Hz Target-Null Context

The L22-alone target, naked L22, and top-baffle combo captures disagree most strongly at `75 deg`. This is why removing only the single exact 300 Hz point barely changes the full RMS: the broader high-angle low-frequency region still carries the same target-quality signature.

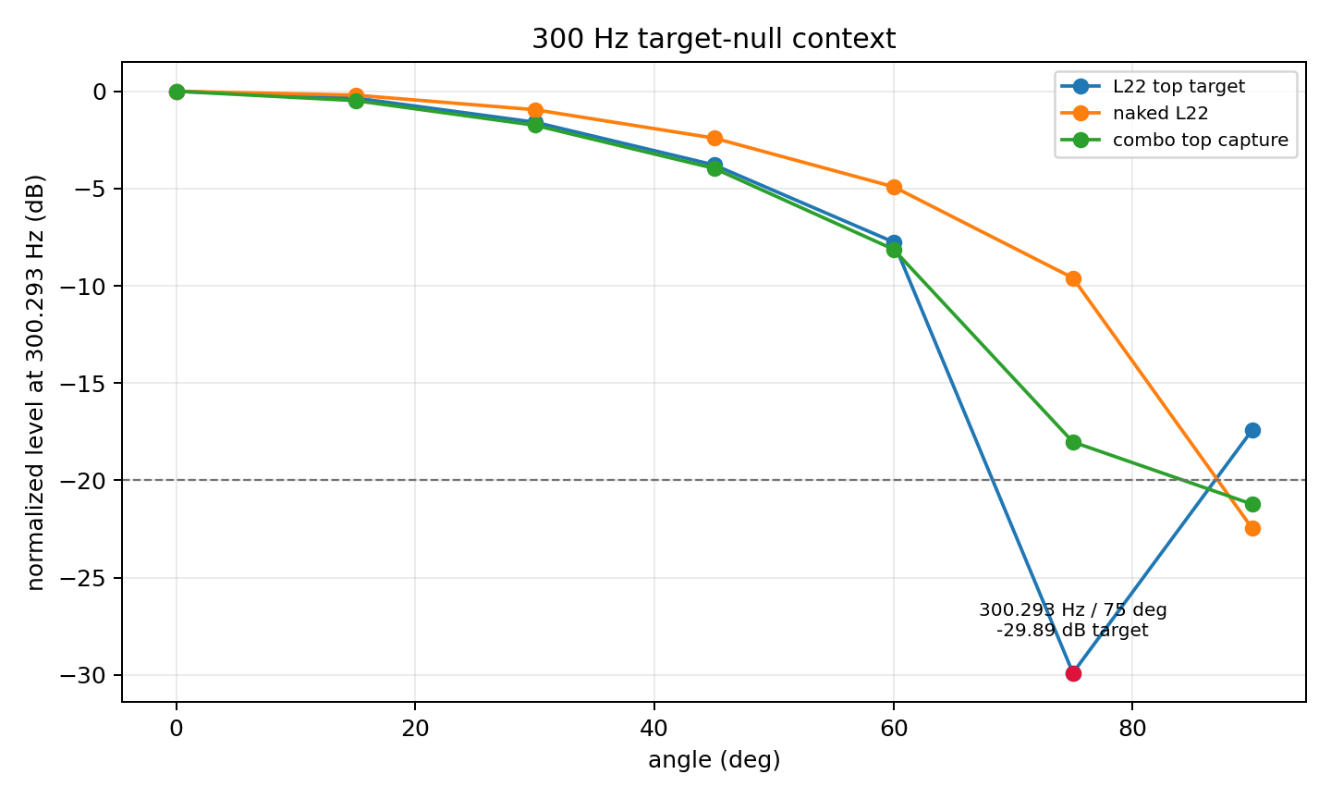
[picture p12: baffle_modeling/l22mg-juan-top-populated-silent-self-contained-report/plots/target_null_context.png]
Target null context


## Interpretation

The best full-band model after the latest iteration is `axisym directivity populated`, but it is diagnostic: the source CV/mesh evidence is not sufficient to treat it as accepted.

The best current candidate under the repo's published diagnostic null mask is `modal full2 populated` at `1.587 dB`. It is the closest to the `1.5 dB` shape gate when deep target nulls are de-emphasized, and it also keeps the through-60 deg RMS at `1.001 dB`. `compact2 populated` is practically tied at `1.594 dB` and remains a conservative baseline.

The active piston, active surface, split active surface, D65 discrete cloud, feature proxy, and thickness variants do not improve the core failure. They either leave the 300 Hz / 75 deg miss in place or add worse residuals elsewhere.

## Conclusion

Do not claim acceptance from this iteration. The honest result is:

- Best literal/full-band rank: `axisym directivity populated`, `4.088 dB` RMS, diagnostic only.
- Best current diagnostic masked rank: `modal full2 populated`, `1.587 dB` RMS with `target > -20 dB`, still above the `1.5 dB` target and not an acceptance mask.
- Best conservative baseline: `compact2 populated`, `1.594 dB` under the same diagnostic mask and `4.219 dB` full-band.

The next iteration should focus on explaining or replacing the Juan L22-only top-baffle high-angle low-frequency target before more source complexity is added. The existing modeling changes are not what limits the pass/fail outcome.

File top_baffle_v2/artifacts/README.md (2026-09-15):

# Product artifact catalog

This is the earlier product-oriented CAD facade. Use the
[current H2C manufacturing catalog](../to_print/h2c/README.md) for current
STLs, projects and slices. The [three-family tweeter guide](../docs/TWEETER_OPTIONS.md)
includes **Dayton ND25FN-4 waveguide**, an integrated Obiwan upper with
matching wings, alongside ND25FW-4 and TEBM35C10-4 BMR.

Three tweeter families and five carrier arrangements at one scale

This is the human-facing inventory for the three supported LX521.4 top-baffle
product choices. Relative symlinks point to validated generator outputs, so
the catalog does not duplicate large STEP or STL files.

| Product | Choose it for | Status |
|---|---|---|
| [`stock/`](stock/) | Full-depth B2 base with either A-comp shoulders or B1 wings | Canonical CAD; physical fit remains the builder's responsibility |
| [`slim/`](slim/) | V1L + V1 front-flush acoustic field with matching thin attachments | Experimental; structural and hardware qualification required |
| [`obiwan/`](obiwan/) | Common LM with regular UM/crescent or integrated ND25FN-4 UM/waveguide, and matching flat/graded wings | Candidate only; release authorization is false |

| Upper family | Printed construction | Current files and documentation |
|---|---|---|
| Dayton ND25FW-4 | Standard Stock/Slim upper or regular Obiwan UM + crescent | [H2C files](../to_print/h2c/README.md) · [Obiwan assembly](../docs/obiwan.md#dayton-nd25fw-4-crescent) |
| Tectonic BMR | Stock/Slim opposed vase or Obiwan coaxial/opposed crescent on regular UM | [H2C files](../to_print/h2c/README.md) · [Mount variants](../docs/TWEETER_OPTIONS.md) |
| Dayton ND25FN-4 waveguide | Obiwan fused UM/body + two caps + two M3 retainers; matching wings | [H2C files](../to_print/h2c/dayton_nd25fn4/) · [Assembly](../docs/DAYTON_ND25FN4_WAVEGUIDE.md) |

Each product directory has a generated `manifest.json` containing SHA-256,
byte size, source path, and role for every linked file. Rebuild or verify the
facade with:

```bash
python3 scripts/build_artifact_catalog.py
python3 scripts/build_artifact_catalog.py --check
```

For manufacturing, use the current H2C projects with their support settings
and magnet pauses. The older linked STLs use their adjacent `.print.json`
orientation authorities. STEP review assemblies are not print plates.

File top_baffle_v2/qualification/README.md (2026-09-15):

# Qualification fixtures — unsliced, not production parts

These fixtures turn the current review findings into measurable checks.
Follow [PETG_GF_QUALIFICATION.md](../docs/PETG_GF_QUALIFICATION.md), record
values in `results_template.csv`, and leave the release status pending until
real evidence supports it.

- `lm_registration.step.py` / `.step`: two native seam ends at the current
  pin pitch, joined by sacrificial braces; the separate STLs retain the
  standalone bottom/top Z rotations (26°/45°); `male_pin_pair.stl` and
  `female_socket_pair.stl` print in the stored front-down orientation.
- `process_witnesses.step.py` / `.step`: `native_route_cover.stl` is a crop
  of current LM CAD. `supported_roof_and_wall_steps.stl` is an accessible
  support-removal/purge specimen with a 0.8 mm roof and 0.8/1.2/1.6 mm walls.
- JSON records identify source hashes, geometry dimensions and STL hashes.
  PNGs are inspected CAD snapshots, not photos of printed results.
- `mesh_review.json` preserves the sampled production mesh review and its
  limitations. No fixture result or physical pass has been recorded.

Use the actual 0.6 mm high-flow GF/PLA process for supported tests and keep a
GF-only control. These STLs contain no supports, material changes or pauses;
slice and inspect them as test fixtures. They contain no captive magnets.
The two registration braces change stiffness and shrink behavior: follow a
coupon pass with full-carrier fit and loaded tests.

CAD brief: millimetres, build plate XY, +Z away from bed. Preserve current
production pin/socket surfaces and pitch; no production mating geometry is
modified. Validate one positive, closed solid per STL, bed fit and visual
snapshots. The native route crop is local evidence; every complete route
still needs a cable-fishing test. The support specimen's wall thicknesses
are deliberate experimental comparisons, not structural design limits.

STEP assemblies are spaced for review; print the separate STLs, each at the
bed origin. These match standalone part rotations. Combo plates add their
own Z rotations; repeat qualification at those placements before transferring
a coupon result to a combo process.

Inspected views: [registration pair](lm_registration_20260905T041039Z.png)
and [route/support witnesses](process_witnesses_20260905T041041Z.png).

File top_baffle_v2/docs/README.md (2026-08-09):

# Documentation index

## Products

- [`stock.md`](stock.md) — Stock: source modules, key dimensions, print
  split, proud cable routing, tweeter options, magnet attachment, assembly.
- [`slim.md`](slim.md) — Slim: the V1 vase, the V1L LM section, and the
  keyed 283° UM outlet. Everything else is inherited from Stock.
- [`obiwan.md`](obiwan.md) — Obi-Wan: two-collar geometry, buried routes,
  floor/no-floor structure, structural screens, wings, combined plates,
  tweeter crescents, assembly.

## Cross-cutting authorities

- [`PROJECT_SCOPE.md`](PROJECT_SCOPE.md) — concise intent, three-product
  inventory, CAD brief, assumptions, and release boundary.
- [`REPOSITORY_STRUCTURE.md`](REPOSITORY_STRUCTURE.md) — current layout,
  artifact contract, and safe source-migration target.
- [`VARIANTS.md`](VARIANTS.md) — detailed geometry, the envelope compatibility
  matrix, hardware, and the retired C7/V0 design history.
- [`PRINTING.md`](PRINTING.md) — material, slicer, insert, magnet, and
  assembly instructions plus the release-form print constraints.
- [`REMOTE_BUILD.md`](REMOTE_BUILD.md) — remote executor, job control, cache
  seeding, promotion transaction, and memory profiles.
- [`CAPTIVE_MAGNET_SLICING.md`](CAPTIVE_MAGNET_SLICING.md) — pause and
  embed workflow.
- [`obiwan_physical_qualification.md`](obiwan_physical_qualification.md) —
  fail-closed physical qualification record.
- [`obiwan_acoustic_wings_spec.md`](obiwan_acoustic_wings_spec.md) — flat/graded
  wing design authority.
- [`obiwan_cad_brief.md`](obiwan_cad_brief.md) — the Obi-Wan CAD brief.

## Historical

- [`SIMPLIFICATION.md`](SIMPLIFICATION.md) and
  [`SIMPLIFICATION_IMPL.md`](SIMPLIFICATION_IMPL.md) — the July 2026
  simplification survey and its implementation plan. Both describe the
  pre-migration tree.
- [`CAPTIVE_MAGNET_MIGRATION_REPORT.md`](CAPTIVE_MAGNET_MIGRATION_REPORT.md) —
  the captive-magnet migration record.

The Make DAG and source-attestation manifests hash these exact paths, so
moving or renaming a file here invalidates otherwise identical candidate
artifacts. Coordinate any move with the manifest migration.

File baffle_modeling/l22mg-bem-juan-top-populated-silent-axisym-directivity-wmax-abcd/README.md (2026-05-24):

# LX521.4 L22MG baffle simulation

This is the current automated workflow for SEAS/LINKWITZ L22MG mounted as the only active source in the LX521.4 top baffle.

## Solver status

- Solver: `dense_neumann_bem`.
- Fidelity label: dense constant-element exterior Neumann BEM for rigid finite-thickness baffle; bounded by panel count and collocation approximation.
- Geometry source: `linkwitz/lx521metric-baffle.pdf` plus the parameterized dimensions in the goal brief.
- Baffle geometry provenance: exact outline vertices, L22 cutout, optional passive holes, modeled cutouts, passive-geometry policy, edge policy, and width-sweep policy are exported as HDF5 metadata.
- Driver STL geometry provenance: `linkwitz/H1659-08_U22REX_P-SL_driver.stl` status `present`; OD 221.0 mm, depth 90.6 mm, front proud height 0.6 mm, rear depth 90.0 mm, and flange overlap past the 190 mm L22 cutout radius 15.5 mm. These dimensions are provenance for H1659-derived approximations, not raw-STL acceptance evidence.
- Frequency range exported: 300-1200 Hz. Results above 5 kHz are intentionally not generated by default.
- Frequency-scope policy: primary-scope diagnostic; acceptance still requires 300-1200 shape and mesh gates.
- Mesh handoff: 4885 vertices, 8204 triangles at h=6.5 mm using `delaunay`; lambda(1200 Hz)=285.8 mm; lambda/6=47.6 mm, lambda/10=28.6 mm.
- Mesh area check: front 0.08091 m2, analytic solid face 0.07223 m2 (front/side area includes added passive UM driver face and passive tweeter driver faces; analytic solid face is baffle only).
- BEM mesh quality: edge median 19.799 mm, p95 33.254 mm, max 39.830 mm; min triangle angle 14.052 deg (p01 14.052 deg); max edge ratio 4.083.
- BEM acoustic mesh: method `delaunay-local`, h=42.0 mm, quadrature order=7, max panels=4000, finite-difference normal-gradient step=1.50 mm. Adaptive controls: boundary h=28.0 mm, local h=28.0 mm, local refinement width=90.0 mm, feature clearance=0.25x local spacing. Near-panel quadrature: q7, subdivisions=1, distance factor=2.50. Target-panel normal-trace averaging: q7, chunk size=128. Linear solver: dense direct LU solve; max relative residual=1.883e-15 at 635.7 Hz (RMS relative residual=1.521e-15). Mesh target at exported max 1200 Hz (lambda=285.8 mm): actual broad/boundary/local h 42.0/28.0/28.0 mm vs lambda/6 47.6 mm and lambda/10 28.6 mm; status `pass` (actual BEM mesh spacing is within lambda/6 broad and lambda/10 boundary/local targets). This is sizing metadata, not convergence proof. Active driver face/frame/STL envelope not included. Passive UM rigid face included: diameter 82.0 mm, height 4.0 mm, mesh h 16.0 mm; the UM position remains a closed baffle patch under the silent-driver face. Passive tweeter rigid faces included: two positions, diameter 47.0 mm, height 3.0 mm, mesh h 12.0 mm; the tweeter baffle positions remain closed under the raised faces.
- Passive aperture treatment: `populated-silent`.
- Populated-silent passive approximation: UM position includes a raised rigid silent-driver face over a closed patch; tweeter positions include raised rigid silent-driver faces over closed patches; no passive holes. This is a rigid silent-driver scatterer approximation, not passive-cone elastic physics.
- Canonical BEM check: `scripts/validate_dense_bem.py` validates the same dense Neumann matrix against analytic rigid-sphere scattering; latest generated report is `docs/l22mg-baffle-bem-canonical/README.md`.
- LX521 BEM caution: canonical sphere validation does not prove the L22MG equivalent-source near field or the coarse rectangular baffle mesh are converged.
- LX521 BEM numeric probe: `scripts/probe_l22mg_bem_numerics.py` checks matrix conditioning at convergence hot spots; the current 1069 Hz / 70 deg lobe movement is not explained by a near-singular matrix in the latest q1/q3 probes.
- Solver upgrade path: `docs/l22mg-bem-upgrade-path/README.md` tracks the non-ad-hoc path: feature-preserving remesh, local hp refinement, and FMM/H-matrix or higher-order BEM before detailed STL acceptance claims.

## HDF5 provenance

### Naked source

- HDF5/driver: `output/data/polar_data_juan_baffleless.h5` / `L22MG (nude)`.
- Distance: 0.5; mic height/reference: l22mg; height note: Measurement distance: 50 cm from driver. Mic height: L22MG/LM..
- Frequency grid: 54559 points, 20.1416-19999.9 Hz, first/last 20.1416/19999.9 Hz.
- Sides/angles: front [0, 15, 30, 45, 60, 75, 90]; rear [0, 15, 30, 45, 60, 75, 90].
- SPL unit metadata: dB SPL; phase unit metadata: unknown; HDF5 has `phase` datasets but no phase-unit attr.
- Gate/window policy: gate_left_ms=0.5; gate_right_ms=3.
- IR peak/timing policy: unknown.
- Smoothing: smoothing_str=None; smoothing=0; front=None; rear=None; normalization: unknown.
- Processing notes: measurement_distance_note: Measurement distance: 50 cm from driver. | measurement_height_note: Measurement distance: 50 cm from driver. Mic height: L22MG/LM. | front: Measurement distance: 50 cm from driver. Mic height: L22MG/LM. | ... 1 more.

### Validation target

- HDF5/driver: `output/data/polar_data_juan_lx521_top_raw.h5` / `L22MG (LX521 top raw)`.
- Distance: 0.5; mic height/reference: l22mg; height note: Measurement distance: 50 cm. Mic height: L22MG/LM. LX521 top baffle mounted; raw/no crossover/no EQ..
- Frequency grid: 54559 points, 20.1416-19999.9 Hz, first/last 20.1416/19999.9 Hz.
- Sides/angles: front [0, 15, 30, 45, 60, 75, 90]; rear [0, 15, 30, 45, 60, 75, 90].
- SPL unit metadata: dB SPL; phase unit metadata: unknown; HDF5 has `phase` datasets but no phase-unit attr.
- Gate/window policy: gate_left_ms=0.5; gate_right_ms=3; timing_first_lobe_window_end_ms=0.8; timing_first_lobe_window_start_ms=-0.5.
- IR peak/timing policy: angles.timing_first_lobe_threshold_fraction=0.5; angles.timing_first_lobe_window_end_ms=0.8; angles.timing_first_lobe_window_start_ms=-0.5; angles.timing_peak_policy=first-strong; angles.timing_peak_selection_reason=first strong near-reference lobe; angles.timing_peak_time_ms=0; direct_ir_peak_policy=first-strong; rear_angles.timing_first_lobe_threshold_fraction=0.5; rear_angles.timing_first_lobe_window_end_ms=0.8; rear_angles.timing_first_lobe_window_start_ms=-0.5; rear_angles.timing_peak_policy=first-strong; rear_angles.timing_peak_selection_reason=first strong near-reference lobe; rear_angles.timing_peak_time_ms=-0.395833.
- Smoothing: smoothing_str=None; smoothing=0; front=None; rear=None; normalization: unknown.
- Processing notes: measurement_distance_note: Measurement distance: 50 cm. Mic height: L22MG/LM. LX521 top baffle mounted; raw/no crossover/no EQ. | measurement_height_note: Measurement distance: 50 cm. Mic height: L22MG/LM. LX521 top baffle mounted; raw/no crossover/no EQ. | front: PB -40 DB / Measurement distance: 50 cm. Mic height: L22MG/LM. LX521 top baffle mounted; raw/no crossover/no EQ. | ... 2 more.

## Source fit

- Nude source HDF5: `output/data/polar_data_juan_baffleless.h5` driver `L22MG (nude)`, front/rear 0-90 deg.
- Source-fit frequency grid: 300-1200 Hz at 12 points/octave.
- Juan front measurement notes: distance=0.5 m; height=reference l22mg; first note=Measurement distance: 50 cm from driver. Mic height: L22MG/LM..
- Juan rear measurement notes: distance=0.5 m; height=reference l22mg; first note=Measurement distance: 50 cm from driver. Mic height: L22MG/LM..
- Juan nude L22MG HDF5 measurement distance: front 0.5 m, rear 0.5 m; equivalent-source fitting uses 0.5 m. Radius policy: matched structured Juan HDF5 measurement_distance_m (front 0.5 m, rear 0.5 m).
- The naked data are treated as the measured field of the real driver on that radius and rotated into an axisymmetric directivity table for this diagnostic.
- Rear phase mode: `dipole`. Rear magnitudes come from Juan's rear capture, but phase is reconstructed as opposite polarity to the front capture because the HDF5 has no stable mutual front/rear timing.
- Rear level correction: none. Juan's rear magnitude is used as stored; no source-level gain knob is available.
- Equivalent source: Axisymmetric Juan directivity table, 13 polar samples, reference radius 0.5 m.
- Acoustic-center offset used by propagation: 0.0 mm.
- This diagnostic rotates Juan's measured complex front/rear angular field about the driver axis and propagates it with spherical spreading/phase from the measurement radius.
- It performs no Andres-derived fitting, no rear/source level correction, and no equivalent point-source inversion.
- Duplicate phi policy: `front` for the shared 90 deg front/rear sample.
- Limitation: a single horizontal naked polar still does not uniquely determine the driver's 3D near field at Andres' UM-height mic.
- Source cross-validation: matched `axisymmetric-directivity-table-front-duplicate` in `docs/l22mg-source-model-cross-validation/source_cv_summary.csv` (rank 1, failed folds 0).
- Source CV held-out normalized SPL RMS: front 1.229 dB, rear 0.984 dB, worst side 1.229 dB over 300-1200 Hz.
- Source CV in-sample fit over 300-1200 Hz: side-worst normalized 0.569 dB; side-worst absolute SPL 0.569 dB; side-worst phase 68.034 deg.
- Source CV interpretation: Juan-only held-out-angle source CV is within 1.5 dB over 300-1200 Hz.
- Source CV recommendation: `diagnostic_only`. Axisymmetric directivity-table propagation is a no-inversion diagnostic; it does not define a unique finite 3D source support for high-fidelity BEM source selection.
- Source CV acceptance gate: fail; Axisymmetric directivity-table propagation is a no-inversion diagnostic; it does not define a unique finite 3D source support for high-fidelity BEM source selection.
- Source off-plane acceptance gate: not required; validation target is at LM/L22MG height, so the Andres UM-height off-plane ambiguity audit is diagnostic only for this run.
- fit_complex_rel_rms_300_5000: 0.575
- fit_front_complex_rel_rms_2000_5000: nan
- fit_front_complex_rel_rms_300_1200: 0.000
- fit_front_complex_rel_rms_300_2000: 0.000
- fit_front_norm_rms_db_2000_5000: nan
- fit_front_norm_rms_db_300_1200: 0.000
- fit_front_norm_rms_db_300_2000: 0.000
- fit_front_phase_rms_deg_2000_5000: nan
- fit_front_phase_rms_deg_300_1200: 0.000
- fit_front_phase_rms_deg_300_2000: 0.000
- fit_front_rms_db_2000_5000: nan
- fit_front_rms_db_300_1200: 0.000
- fit_front_rms_db_300_2000: 0.000
- fit_rear_complex_rel_rms_2000_5000: nan
- fit_rear_complex_rel_rms_300_1200: 0.814
- fit_rear_complex_rel_rms_300_2000: 0.814
- fit_rear_norm_rms_db_2000_5000: nan
- fit_rear_norm_rms_db_300_1200: 0.573
- fit_rear_norm_rms_db_300_2000: 0.573
- fit_rear_phase_rms_deg_2000_5000: nan
- fit_rear_phase_rms_deg_300_1200: 68.034
- fit_rear_phase_rms_deg_300_2000: 68.034
- fit_rear_rms_db_2000_5000: nan
- fit_rear_rms_db_300_1200: 0.573
- fit_rear_rms_db_300_2000: 0.573
- fit_rms_db_2000_5000: nan
- fit_rms_db_300_1200: 0.405
- fit_rms_db_300_2000: 0.405

## Validation target, Wmax 305 mm

- Validation target: `output/data/polar_data_juan_lx521_top_raw.h5` driver `L22MG (LX521 top raw)`, front angles [0, 15, 30, 45, 60, 75, 90], measured distance 0.5 m.
- Validation preset: `juan-top-raw`.
- Validation model angle policy: `target_hdf5_angles` from `output/data/polar_data_juan_lx521_top_raw.h5:L22MG (LX521 top raw)/angles`; solver angles [0, 15, 30, 45, 60, 75, 90], target angles [0, 15, 30, 45, 60, 75, 90], angular interpolation used for validation: no.
- Validation target acceptance gate: pass; validation target is Juan L22MG LX521 top-baffle raw/no-crossover HDF5 at 50 cm and LM/L22MG height.
- Validation target policy: validation target is Juan L22MG LX521 top-baffle raw/no-crossover HDF5 at 50 cm and LM/L22MG height.
- Validation hypothesis: `juan_baffleless_to_juan_top_baffle_l22mg_raw`.
- Validation target processing policy: repo processed Juan LX521 top-baffle raw/no-crossover HDF5 measured at 50 cm and LM/L22MG height; same-room/same-driver comparison against Juan baffleless source data.
- Validation target peak-selection policy: standard Juan HDF5 export path; no Andres IR peak-selection policy is used.
- Direct IR peak policy mirrored into this simulation artifact: `first-strong` from `output/data/polar_data_juan_lx521_top_raw.h5:root direct_ir_peak_policy`. Naked source HDF5 root policy: `unknown`. This keeps generated simulation artifacts aligned with the validation/published HDF5 policy; it does not infer missing naked-source timing metadata.
- Validation target gate/window policy: gate/window policy as stored in the processed Juan HDF5.
- Validation target normalization policy: primary validation compares normalized polar shape, SPL(theta)-SPL(0), at each frequency.
- Andres published-explorer parity status for this target: not applicable/not proven; explorer `not recorded`; 1004 Hz max delta nan dB.
- Validation target measurement notes: distance=0.5 m; height=reference l22mg; first note=PB -40 DB / Measurement distance: 50 cm. Mic height: L22MG/LM. LX521 top baffle mounted; raw/no crossover/no EQ..
- Validation target passive-state provenance: `passive_state_status=unused_um_tweeter_state_unrecorded`, `passive_state_acceptance_use=current_l22_target_but_passive_geometry_not_proven`.
- Simulation mic horizontal polar radius used for validation: 0.5 m.
- Simulation mic z offset for validation: 0.0 mm relative to the L22 center plane, reference `l22`; 3D L22-axis distance at 0 deg is 0.500 m and vertical elevation is 0.00 deg.
- This validation mic height is separate from Juan's naked-source measurement radius and from the allowed scalar gain/delay alignment.
- Normalization rationale: source and target absolute SPL levels are not assumed matched, so primary acceptance compares normalized polar shape, SPL(theta)-SPL(0), at each frequency.
- The scalar gain/delay alignment is applied once for validation; it is not a source-fit knob and cannot change normalized polar/directivity errors.
- Baffle-transfer metrics subtract the nude equivalent source evaluated at the same validation mic height after the same dataset-level reference alignment used for validation.
- That reference alignment is not a rear/source level correction; Juan's rear magnitude remains used as stored, and normalized polar/directivity errors are unchanged.
- Validation target direct timing anchor warning: none in the HDF5 timing metadata. Late in-window target warning: none in the HDF5 timing metadata.
- Validation target high-angle IR peak audit: no Andres raw-IR peak audit is required for the Juan top-baffle target; no timing metadata flags are present in the processed HDF5.
- Allowed alignment applied: scalar gain 5.20 dB and delay 0.058 ms; delay fit uses angles through 60 deg for stable direct-arrival phase alignment.
- Alignment audit: gain is fit only on the 0 deg response over 300-1200 Hz; delay is searched over -1.0 to 1.0 ms across 801 global candidates; angle-dependent, band-specific, source-level, and rear-level correction counts are zero.
- baffle_transfer_rms_db_300_1200: 5.345
- baffle_transfer_rms_db_300_2000: 5.345
- band_2000_5000_covered_max_hz: nan
- band_2000_5000_covered_min_hz: nan
- band_2000_5000_full_coverage: 0.000
- band_2000_5000_point_count: 0.000
- band_2000_5000_requested_max_hz: 5000.000
- band_2000_5000_requested_min_hz: 2000.000
- band_300_1200_covered_max_hz: 1199.707
- band_300_1200_covered_min_hz: 300.293
- band_300_1200_full_coverage: 1.000
- band_300_1200_point_count: 2457.000
- band_300_1200_requested_max_hz: 1200.000
- band_300_1200_requested_min_hz: 300.000
- band_300_2000_covered_max_hz: 1199.707
- band_300_2000_covered_min_hz: 300.293
- band_300_2000_full_coverage: 0.000
- band_300_2000_point_count: 2457.000
- band_300_2000_requested_max_hz: 2000.000
- band_300_2000_requested_min_hz: 300.000
- beamwidth_6_db_rms_error_300_1200: 19.326
- beamwidth_6_db_rms_error_300_2000: 19.326
- complex_rel_rms_2000_5000: nan
- complex_rel_rms_300_1200: 1.761
- complex_rel_rms_300_2000: 1.761
- di_db_rms_error_300_1200: 1.760
- di_db_rms_error_300_2000: 1.760
- f90_f0_mean_error_db_2000_5000: nan
- f90_f0_mean_error_db_300_1200: 3.891
- f90_f0_mean_error_db_300_2000: 3.891
- f90_f0_rms_error_db_2000_5000: nan
- f90_f0_rms_error_db_300_1200: 8.566
- f90_f0_rms_error_db_300_2000: 8.566
- f90_f0_sim_mean_db_2000_5000: nan
- f90_f0_sim_mean_db_300_1200: -17.930
- f90_f0_sim_mean_db_300_2000: -17.930
- f90_f0_target_mean_db_2000_5000: nan
- f90_f0_target_mean_db_300_1200: -21.821
- f90_f0_target_mean_db_300_2000: -21.821
- normalized_polar_max_abs_error_angle_deg_2000_5000: nan
- normalized_polar_max_abs_error_angle_deg_2000_5000_target_above_minus20db: nan
- normalized_polar_max_abs_error_angle_deg_2000_5000_through_60deg: nan
- normalized_polar_max_abs_error_angle_deg_2000_5000_through_80deg: nan
- normalized_polar_max_abs_error_angle_deg_300_1200: 75.000
- normalized_polar_max_abs_error_angle_deg_300_1200_target_above_minus20db: 75.000
- normalized_polar_max_abs_error_angle_deg_300_1200_through_60deg: 60.000
- normalized_polar_max_abs_error_angle_deg_300_1200_through_80deg: 75.000
- normalized_polar_max_abs_error_angle_deg_300_2000: 75.000
- normalized_polar_max_abs_error_angle_deg_300_2000_target_above_minus20db: 75.000
- normalized_polar_max_abs_error_angle_deg_300_2000_through_60deg: 60.000
- normalized_polar_max_abs_error_angle_deg_300_2000_through_80deg: 75.000
- normalized_polar_max_abs_error_db_2000_5000: nan
- normalized_polar_max_abs_error_db_2000_5000_target_above_minus20db: nan
- normalized_polar_max_abs_error_db_2000_5000_through_60deg: nan
- normalized_polar_max_abs_error_db_2000_5000_through_80deg: nan
- normalized_polar_max_abs_error_db_300_1200: 16.984
- normalized_polar_max_abs_error_db_300_1200_target_above_minus20db: 9.396
- normalized_polar_max_abs_error_db_300_1200_through_60deg: 4.529
- normalized_polar_max_abs_error_db_300_1200_through_80deg: 16.984
- normalized_polar_max_abs_error_db_300_2000: 16.984
- normalized_polar_max_abs_error_db_300_2000_target_above_minus20db: 9.396
- normalized_polar_max_abs_error_db_300_2000_through_60deg: 4.529
- normalized_polar_max_abs_error_db_300_2000_through_80deg: 16.984
- normalized_polar_max_abs_error_freq_hz_2000_5000: nan
- normalized_polar_max_abs_error_freq_hz_2000_5000_target_above_minus20db: nan
- normalized_polar_max_abs_error_freq_hz_2000_5000_through_60deg: nan
- normalized_polar_max_abs_error_freq_hz_2000_5000_through_80deg: nan
- normalized_polar_max_abs_error_freq_hz_300_1200: 300.293
- normalized_polar_max_abs_error_freq_hz_300_1200_target_above_minus20db: 1199.707
- normalized_polar_max_abs_error_freq_hz_300_1200_through_60deg: 1077.026
- normalized_polar_max_abs_error_freq_hz_300_1200_through_80deg: 300.293
- normalized_polar_max_abs_error_freq_hz_300_2000: 300.293
- normalized_polar_max_abs_error_freq_hz_300_2000_target_above_minus20db: 1199.707
- normalized_polar_max_abs_error_freq_hz_300_2000_through_60deg: 1077.026
- normalized_polar_max_abs_error_freq_hz_300_2000_through_80deg: 300.293
- normalized_polar_max_abs_error_signed_db_2000_5000: nan
- normalized_polar_max_abs_error_signed_db_2000_5000_target_above_minus20db: nan
- normalized_polar_max_abs_error_signed_db_2000_5000_through_60deg: nan
- normalized_polar_max_abs_error_signed_db_2000_5000_through_80deg: nan
- normalized_polar_max_abs_error_signed_db_300_1200: 16.984
- normalized_polar_max_abs_error_signed_db_300_1200_target_above_minus20db: 9.396
- normalized_polar_max_abs_error_signed_db_300_1200_through_60deg: 4.529
- normalized_polar_max_abs_error_signed_db_300_1200_through_80deg: 16.984
- normalized_polar_max_abs_error_signed_db_300_2000: 16.984
- normalized_polar_max_abs_error_signed_db_300_2000_target_above_minus20db: 9.396
- normalized_polar_max_abs_error_signed_db_300_2000_through_60deg: 4.529
- normalized_polar_max_abs_error_signed_db_300_2000_through_80deg: 16.984
- normalized_polar_rms_db_2000_5000: nan
- normalized_polar_rms_db_2000_5000_clean_timing_angles: nan
- normalized_polar_rms_db_2000_5000_excluding_90deg: nan
- normalized_polar_rms_db_2000_5000_target_above_minus20db: nan
- normalized_polar_rms_db_2000_5000_through_60deg: nan
- normalized_polar_rms_db_2000_5000_through_80deg: nan
- normalized_polar_rms_db_300_1200: 4.503
- normalized_polar_rms_db_300_1200_clean_timing_angles: 4.503
- normalized_polar_rms_db_300_1200_excluding_90deg: 3.380
- normalized_polar_rms_db_300_1200_target_above_minus20db: 2.523
- normalized_polar_rms_db_300_1200_through_60deg: 1.894
- normalized_polar_rms_db_300_1200_through_80deg: 3.380
- normalized_polar_rms_db_300_2000: 4.503
- normalized_polar_rms_db_300_2000_clean_timing_angles: 4.503
- normalized_polar_rms_db_300_2000_excluding_90deg: 3.380
- normalized_polar_rms_db_300_2000_target_above_minus20db: 2.523
- normalized_polar_rms_db_300_2000_through_60deg: 1.894
- normalized_polar_rms_db_300_2000_through_80deg: 3.380
- nude_to_andres_gain_db_for_transfer: 5.799
- on_axis_mean_error_db_2000_5000: nan
- on_axis_mean_error_db_300_1200: 0.000
- on_axis_mean_error_db_300_2000: 0.000
- on_axis_rms_error_db_2000_5000: nan
- on_axis_rms_error_db_300_1200: 2.181
- on_axis_rms_error_db_300_2000: 2.181
- target_timing_clean_angle_count: 7.000
- target_timing_suspect_angle_count: 0.000
- validation_alignment_delay_count: 1.000
- validation_alignment_scalar_gain_count: 1.000
- validation_angle_dependent_gain_correction_count: 0.000
- validation_angular_interpolation_used: 0.000
- validation_band_specific_gain_correction_count: 0.000
- validation_delay_fit_max_angle_deg: 60.000
- validation_delay_fit_max_hz: 2000.000
- validation_delay_fit_min_hz: 300.000
- validation_delay_hit_search_bound: 0.000
- validation_delay_ms: 0.058
- validation_delay_search_max_ms: 1.000
- validation_delay_search_min_ms: -1.000
- validation_delay_search_step_count: 801.000
- validation_gain_db: 5.195
- validation_gain_fit_angle_deg: 0.000
- validation_gain_fit_max_hz: 1200.000
- validation_gain_fit_min_hz: 300.000
- validation_model_angle_count: 7.000
- validation_rear_level_correction_db: 0.000
- validation_source_level_correction_db: 0.000
- validation_target_angle_count: 7.000
- Acceptance check, all required gates (canonical validation target, full 300-1200 coverage, normalized polar RMS <= 1.5 dB, dense-BEM mesh change <= 0.5 dB, Juan-only source CV recommended, and off-plane source ambiguity only when the validation mic is off the L22 plane): fail for this baseline. Target acceptance gate: pass; validation target is Juan L22MG LX521 top-baffle raw/no-crossover HDF5 at 50 cm and LM/L22MG height. Direct timing anchor diagnostic: pass; no stored selected-peak early/rejected/not-first-lobe flags. Late-window target diagnostic: stored HDF5 metadata pass; no large late in-window target peaks. Shape gate: fail (4.503 dB). Mesh gate: not proven; no dense-BEM mesh convergence sweep was run in this invocation. Source CV gate: fail; Axisymmetric directivity-table propagation is a no-inversion diagnostic; it does not define a unique finite 3D source support for high-fidelity BEM source selection. Source off-plane gate: not_required; validation target is on the LM/L22MG height, so Andres UM-height off-plane ambiguity is diagnostic only.
- Shape diagnostic: normalized RMS through 60 deg over covered 300-1200 band is 1.894 dB; through 80 deg is 3.380 dB; all-angle clean-timing RMS is 4.503 dB. target F90-F0 mean -21.82 dB, sim F90-F0 mean -17.93 dB;  worst normalized error is +16.984 dB at 300.3 Hz / 75 deg; through-60 max is 4.529 dB at 1077.0 Hz / 60 deg. F90 remains a high-angle/null-sensitive diagnostic even without a timing flag.
- Primary-scope diagnostic, not acceptance: this invocation does not cover the full 300-2000 Hz primary scope; covered range is 300-1200 Hz.
- Width-sweep status: qualitative only. The 305 mm baseline has not passed all validation gates, so width changes cannot be read as accepted LX521 behavior.
- Width-sweep baseline context: normalized polar RMS 300-1200 Hz = 4.503 dB; through-60 = 1.894 dB; through-80 = 3.380 dB; baffle-transfer RMS = 5.345 dB; DI RMS error = 1.760 dB.
- Width-sweep blockers: mesh gate: not proven; no dense-BEM mesh convergence sweep was run in this invocation; source CV gate: fail; Axisymmetric directivity-table propagation is a no-inversion diagnostic; it does not define a unique finite 3D source support for high-fidelity BEM source selection; source off-plane gate: not_required; validation target is on the LM/L22MG height, so Andres UM-height off-plane ambiguity is diagnostic only.

## Qualitative width sweep

The sweep keeps all geometry fixed except the z=254 mm wide vertices at +/-Wmax/2.

| Wmax mm | F90-F0 mean 300-1200 dB | DI mean 300-1200 dB | -6 dB BW median 300-1200 deg | rear/front norm RMS 300-2000 dB |
| ---: | ---: | ---: | ---: | ---: |
| 205 | -19.65 | 4.73 | 120.6 | 2.46 |
| 305 | -18.42 | 4.90 | 116.6 | 4.15 |
| 405 | -18.48 | 4.63 | 118.2 | 4.69 |
| 505 | -18.86 | 4.15 | 120.6 | 5.51 |

## Convergence

No convergence sweep was run in this invocation. For BEM, repeat the run with multiple `--bem-mesh-h-mm` values and compare the exported normalized polars before treating the result as converged.

## Artifacts

- `output/l22mg-bem-juan-top-populated-silent-axisym-directivity-wmax-abcd/polar_data_l22mg_lx5214_baffle_sim.h5`: repo-compatible simulation HDF5, including `/validation_decomposition` datasets for the per-frequency/angle validation audit.
- `output/l22mg-bem-juan-top-populated-silent-axisym-directivity-wmax-abcd/hdf5_provenance.json`: inspected source/target HDF5 provenance sidecar.
- `output/l22mg-bem-juan-top-populated-silent-axisym-directivity-wmax-abcd/validation_metrics.csv`: metric table against the validation target.
- `output/l22mg-bem-juan-top-populated-silent-axisym-directivity-wmax-abcd/validation_decomposition.csv`: per-frequency/angle measured-baffle, model, synthetic-nude, normalized-error, and baffle-transfer decomposition.
- `output/l22mg-bem-juan-top-populated-silent-axisym-directivity-wmax-abcd/width_sweep_metrics.csv`: sweep table.
- `output/l22mg-bem-juan-top-populated-silent-axisym-directivity-wmax-abcd/lx5214_top_baffle_w305_mesh.obj`: mesh handoff for future BEM.
- `output/l22mg-bem-juan-top-populated-silent-axisym-directivity-wmax-abcd/plots/validation_vs_target.png`: SPL, normalized polar, baffle transfer, DI/beamwidth.
- `output/l22mg-bem-juan-top-populated-silent-axisym-directivity-wmax-abcd/plots/validation_vs_andres.png`: legacy filename alias for the same validation-target plot.
- `output/l22mg-bem-juan-top-populated-silent-axisym-directivity-wmax-abcd/plots/normalized_polar_error.png`: normalized polar error heatmap.
- `output/l22mg-bem-juan-top-populated-silent-axisym-directivity-wmax-abcd/plots/naked_baffle_model_contours.png`: single-image normalized contour comparison for Juan naked L22, the validation target, and the synthetic-baffle model.
- `output/l22mg-bem-juan-top-populated-silent-axisym-directivity-wmax-abcd/plots/width_sweep_summary.png`: sweep curves.
- `output/l22mg-bem-juan-top-populated-silent-axisym-directivity-wmax-abcd/plots/width_sweep_band_table_plot.png`: sweep band summaries.

## Known limits

- Validation alignment uses only one scalar gain and one delay.
- The default BEM source term is an equivalent source fitted from nude polars; source-surface coupling around the real L22 frame/flange is not explicitly modeled.
- `--source-model axisymmetric-directivity` rotates Juan's measured naked angular field into a directivity table and propagates it from the measurement radius. It is a no-inversion source diagnostic, not proof that Juan's horizontal polar uniquely determines Andres' off-plane incident field.
- `--bem-active-piston-source` switches to a flat prescribed-Neumann source disk. Its default strength follows Juan on-axis only and does not fit Juan polar directivity, so it is a source-surface diagnostic rather than an acceptance-grade driver model.
- `--source-model active-surface-modal` switches to a Juan-fitted H1659-shaped prescribed-Neumann source surface. It is a stronger driver-surface diagnostic, but it is still an open rigid acoustic surface, not coupled elastic cone/suspension physics.
- `--source-model split-active-surface-modal` fits independent front/rear H1659-shaped prescribed-Neumann source surfaces to Juan only. The side gap is a source-model discretization parameter, not an Andres-derived correction.
- Legendre BEM runs use a far-field angular model as a near-field multipole expansion; discrete-source BEM runs bound that near field, split-discrete runs separate front/rear components, and split-ring runs expand circular source rings.
- `--include-driver-face` adds a simple rigid surface-mounted annulus, but it is still not a detailed basket/cone/flange model.
- `--include-driver-stl-envelope` uses only a coarse revolved radius envelope from the driver STL for diagnostic obstruction sensitivity. It is not a raw-STL solve, not feature-preserving remeshing, and not an acceptance-grade model.
- `--include-driver-frame` adds a coarse feature-aware rigid frame/basket/motor obstruction from H1659 STL dimensions. `--driver-frame-include-mounting-holes` optionally cuts the STL-derived screw pockets into that flange, but the path still omits cone/surround compliance, elastic coupling, and feature-preserving STL remeshing.
- `--active-driver-feature-proxy` explicitly requests the H1659 acoustic feature-proxy path: rigid frame/flange/motor geometry plus a Juan-fitted prescribed-Neumann acoustic surface, with mounting pockets forced on. Combining `--include-driver-frame` with an active-surface source remains labelled as the same proxy path for legacy runs. The 0.6 mm flange sidewalls default off for this path as an explicit mesh-quality approximation; pass `--driver-frame-include-front-flange-sidewalls` to include them. It is not a scalar correction, not fitted to Andres, not a raw-STL dense solve, and not elastic FEM-BEM.
- Runtime note: the dense BEM cost is dominated by matrix assembly and O(N^3) linear solves per frequency. A Rust rewrite is not the first lever unless profiling shows Python overhead dominates; better mesh sizing, iterative solvers, or an accelerated BEM backend matter more.
- Linear-solver note: `--bem-linear-solver gmres` is an audit/control path in this dense backend. `gmres-matrix-free` avoids storing the dense matrix for targeted larger diagnostics, but it is still an O(N^2) dense-kernel matvec, not FMM-BEM or H-matrix acceleration, and it does not change the source model or validation alignment.
- Acoustic-center note: the automatic phase scan is conservative and falls back to 0 mm when the best fit lands on the +/-40 mm search boundary; use `--acoustic-center-offset-mm` for an explicit nonzero offset study.
- Mesh note: `delaunay-adaptive` keeps the interior at the requested h while sampling the outside edge, cutout, passive holes, and thickness walls at h/2. `delaunay-local` adds a finer point field only near baffle features, and `--bem-auto-mesh` derives broad/local spacings from wavelength plus baffle/cutout feature dimensions.
- Edge fallback strengths are fixed baseline coefficients, not fitted to Andres.
- True BEM acoustic mesh convergence is proven only when a BEM mesh sweep is run and compared; the fallback convergence table checks edge/cutout sampling density only.

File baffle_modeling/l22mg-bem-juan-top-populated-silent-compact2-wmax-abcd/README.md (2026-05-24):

# LX521.4 L22MG baffle simulation

This is the current automated workflow for SEAS/LINKWITZ L22MG mounted as the only active source in the LX521.4 top baffle.

## Solver status

- Solver: `dense_neumann_bem`.
- Fidelity label: dense constant-element exterior Neumann BEM for rigid finite-thickness baffle; bounded by panel count and collocation approximation.
- Geometry source: `linkwitz/lx521metric-baffle.pdf` plus the parameterized dimensions in the goal brief.
- Baffle geometry provenance: exact outline vertices, L22 cutout, optional passive holes, modeled cutouts, passive-geometry policy, edge policy, and width-sweep policy are exported as HDF5 metadata.
- Driver STL geometry provenance: `linkwitz/H1659-08_U22REX_P-SL_driver.stl` status `present`; OD 221.0 mm, depth 90.6 mm, front proud height 0.6 mm, rear depth 90.0 mm, and flange overlap past the 190 mm L22 cutout radius 15.5 mm. These dimensions are provenance for H1659-derived approximations, not raw-STL acceptance evidence.
- Frequency range exported: 300-1200 Hz. Results above 5 kHz are intentionally not generated by default.
- Frequency-scope policy: primary-scope diagnostic; acceptance still requires 300-1200 shape and mesh gates.
- Mesh handoff: 4885 vertices, 8204 triangles at h=6.5 mm using `delaunay`; lambda(1200 Hz)=285.8 mm; lambda/6=47.6 mm, lambda/10=28.6 mm.
- Mesh area check: front 0.08091 m2, analytic solid face 0.07223 m2 (front/side area includes added passive UM driver face and passive tweeter driver faces; analytic solid face is baffle only).
- BEM mesh quality: edge median 19.799 mm, p95 33.254 mm, max 39.830 mm; min triangle angle 14.052 deg (p01 14.052 deg); max edge ratio 4.083.
- BEM acoustic mesh: method `delaunay-local`, h=42.0 mm, quadrature order=7, max panels=4000, analytic source normal derivative. Adaptive controls: boundary h=28.0 mm, local h=28.0 mm, local refinement width=90.0 mm, feature clearance=0.25x local spacing. Near-panel quadrature: q7, subdivisions=1, distance factor=2.50. Target-panel normal-trace averaging: q7, chunk size=128. Linear solver: dense direct LU solve; max relative residual=1.610e-15 at 476.2 Hz (RMS relative residual=1.286e-15). Mesh target at exported max 1200 Hz (lambda=285.8 mm): actual broad/boundary/local h 42.0/28.0/28.0 mm vs lambda/6 47.6 mm and lambda/10 28.6 mm; status `pass` (actual BEM mesh spacing is within lambda/6 broad and lambda/10 boundary/local targets). This is sizing metadata, not convergence proof. Active driver face/frame/STL envelope not included. Passive UM rigid face included: diameter 82.0 mm, height 4.0 mm, mesh h 16.0 mm; the UM position remains a closed baffle patch under the silent-driver face. Passive tweeter rigid faces included: two positions, diameter 47.0 mm, height 3.0 mm, mesh h 12.0 mm; the tweeter baffle positions remain closed under the raised faces.
- Passive aperture treatment: `populated-silent`.
- Populated-silent passive approximation: UM position includes a raised rigid silent-driver face over a closed patch; tweeter positions include raised rigid silent-driver faces over closed patches; no passive holes. This is a rigid silent-driver scatterer approximation, not passive-cone elastic physics.
- Canonical BEM check: `scripts/validate_dense_bem.py` validates the same dense Neumann matrix against analytic rigid-sphere scattering; latest generated report is `docs/l22mg-baffle-bem-canonical/README.md`.
- LX521 BEM caution: canonical sphere validation does not prove the L22MG equivalent-source near field or the coarse rectangular baffle mesh are converged.
- LX521 BEM numeric probe: `scripts/probe_l22mg_bem_numerics.py` checks matrix conditioning at convergence hot spots; the current 1069 Hz / 70 deg lobe movement is not explained by a near-singular matrix in the latest q1/q3 probes.
- Solver upgrade path: `docs/l22mg-bem-upgrade-path/README.md` tracks the non-ad-hoc path: feature-preserving remesh, local hp refinement, and FMM/H-matrix or higher-order BEM before detailed STL acceptance claims.

## HDF5 provenance

### Naked source

- HDF5/driver: `output/data/polar_data_juan_baffleless.h5` / `L22MG (nude)`.
- Distance: 0.5; mic height/reference: l22mg; height note: Measurement distance: 50 cm from driver. Mic height: L22MG/LM..
- Frequency grid: 54559 points, 20.1416-19999.9 Hz, first/last 20.1416/19999.9 Hz.
- Sides/angles: front [0, 15, 30, 45, 60, 75, 90]; rear [0, 15, 30, 45, 60, 75, 90].
- SPL unit metadata: dB SPL; phase unit metadata: unknown; HDF5 has `phase` datasets but no phase-unit attr.
- Gate/window policy: gate_left_ms=0.5; gate_right_ms=3.
- IR peak/timing policy: unknown.
- Smoothing: smoothing_str=None; smoothing=0; front=None; rear=None; normalization: unknown.
- Processing notes: measurement_distance_note: Measurement distance: 50 cm from driver. | measurement_height_note: Measurement distance: 50 cm from driver. Mic height: L22MG/LM. | front: Measurement distance: 50 cm from driver. Mic height: L22MG/LM. | ... 1 more.

### Validation target

- HDF5/driver: `output/data/polar_data_juan_lx521_top_raw.h5` / `L22MG (LX521 top raw)`.
- Distance: 0.5; mic height/reference: l22mg; height note: Measurement distance: 50 cm. Mic height: L22MG/LM. LX521 top baffle mounted; raw/no crossover/no EQ..
- Frequency grid: 54559 points, 20.1416-19999.9 Hz, first/last 20.1416/19999.9 Hz.
- Sides/angles: front [0, 15, 30, 45, 60, 75, 90]; rear [0, 15, 30, 45, 60, 75, 90].
- SPL unit metadata: dB SPL; phase unit metadata: unknown; HDF5 has `phase` datasets but no phase-unit attr.
- Gate/window policy: gate_left_ms=0.5; gate_right_ms=3; timing_first_lobe_window_end_ms=0.8; timing_first_lobe_window_start_ms=-0.5.
- IR peak/timing policy: angles.timing_first_lobe_threshold_fraction=0.5; angles.timing_first_lobe_window_end_ms=0.8; angles.timing_first_lobe_window_start_ms=-0.5; angles.timing_peak_policy=first-strong; angles.timing_peak_selection_reason=first strong near-reference lobe; angles.timing_peak_time_ms=0; direct_ir_peak_policy=first-strong; rear_angles.timing_first_lobe_threshold_fraction=0.5; rear_angles.timing_first_lobe_window_end_ms=0.8; rear_angles.timing_first_lobe_window_start_ms=-0.5; rear_angles.timing_peak_policy=first-strong; rear_angles.timing_peak_selection_reason=first strong near-reference lobe; rear_angles.timing_peak_time_ms=-0.395833.
- Smoothing: smoothing_str=None; smoothing=0; front=None; rear=None; normalization: unknown.
- Processing notes: measurement_distance_note: Measurement distance: 50 cm. Mic height: L22MG/LM. LX521 top baffle mounted; raw/no crossover/no EQ. | measurement_height_note: Measurement distance: 50 cm. Mic height: L22MG/LM. LX521 top baffle mounted; raw/no crossover/no EQ. | front: PB -40 DB / Measurement distance: 50 cm. Mic height: L22MG/LM. LX521 top baffle mounted; raw/no crossover/no EQ. | ... 2 more.

## Source fit

- Nude source HDF5: `output/data/polar_data_juan_baffleless.h5` driver `L22MG (nude)`, front/rear 0-90 deg.
- Source-fit frequency grid: 300-1200 Hz at 12 points/octave.
- Juan front measurement notes: distance=0.5 m; height=reference l22mg; first note=Measurement distance: 50 cm from driver. Mic height: L22MG/LM..
- Juan rear measurement notes: distance=0.5 m; height=reference l22mg; first note=Measurement distance: 50 cm from driver. Mic height: L22MG/LM..
- Juan nude L22MG HDF5 measurement distance: front 0.5 m, rear 0.5 m; equivalent-source fitting uses 0.5 m. Radius policy: matched structured Juan HDF5 measurement_distance_m (front 0.5 m, rear 0.5 m).
- The naked data are treated as the measured field of the real driver on that radius and inverted into an equivalent source; they are not treated as a point-source directivity table.
- Rear phase mode: `dipole`. Rear magnitudes come from Juan's rear capture, but phase is reconstructed as opposite polarity to the front capture because the HDF5 has no stable mutual front/rear timing.
- Rear level correction: none. Juan's rear magnitude is used as stored; no source-level gain knob is available.
- Equivalent source: Split front/rear axisymmetric monopole rings, 292 points, reference radius 0.5 m, regularization 1e-06.
- Acoustic-center offset used by propagation: 0.0 mm.
- Axisymmetric source profile: `h1659-modal-compact-2`.
- Source placement uses smooth radial modal combinations of H1659 cone/surround circular rings rather than one free fitted strength per radius.
- The profile changes only the Juan-fitted equivalent source support; it is not an Andres-derived level/polar correction and it does not add a rigid active-driver scatterer.
- Source conditioning: ridge-regularized normal equations; no SVD truncation.
- Axisymmetric ring basis: 4 fitted ring strengths expanded with 24 azimuth samples per nonzero ring.
- The ring source assumes the naked driver is circularly symmetric; this is more physical than a horizontal-only point cloud but still does not model the frame/flange.
- design_cond_max: 53.5
- design_cond_median: 17.1
- dropped_singular_count_max: 0
- effective_cond_max: 53.5
- effective_cond_median: 17.1
- effective_rank_median: 2.000
- effective_rank_min: 2.000
- singular_min_over_max_min: 0.0187
- source_smoothness_regularization: 0
- source_smoothness_rows_median: 0.000
- source_smoothness_weight_median: 0
- source_svd_rcond: 0
- Source cross-validation: matched `h1659-modal-compact2-az24-reg1e-06` in `docs/l22mg-source-model-cross-validation/source_cv_summary.csv` (rank 3, failed folds 0).
- Source CV held-out normalized SPL RMS: front 3.298 dB, rear 2.877 dB, worst side 3.298 dB over 300-1200 Hz.
- Source CV in-sample fit over 300-1200 Hz: side-worst normalized 2.631 dB; side-worst absolute SPL 2.578 dB; side-worst phase 15.048 deg.
- Source CV interpretation: Juan-only held-out-angle source CV is useful but above the 1.5 dB validation target.
- Source CV recommendation: `recommended_juan_only`. Passes Juan-only thresholds: failed folds <= 0, in-sample side-worst <= 3.000 dB, in-sample absolute side-worst <= 3.000 dB, in-sample phase side-worst <= 30.000 deg, held-out side-worst <= 4.000 dB.
- Source CV acceptance gate: pass; Passes Juan-only thresholds: failed folds <= 0, in-sample side-worst <= 3.000 dB, in-sample absolute side-worst <= 3.000 dB, in-sample phase side-worst <= 30.000 deg, held-out side-worst <= 4.000 dB.
- Source off-plane acceptance gate: not required; validation target is at LM/L22MG height, so the Andres UM-height off-plane ambiguity audit is diagnostic only for this run.
- fit_complex_rel_rms_300_5000: 0.386
- fit_front_complex_rel_rms_2000_5000: nan
- fit_front_complex_rel_rms_300_1200: 0.483
- fit_front_complex_rel_rms_300_2000: 0.483
- fit_front_norm_rms_db_2000_5000: nan
- fit_front_norm_rms_db_300_1200: 2.637
- fit_front_norm_rms_db_300_2000: 2.637
- fit_front_phase_rms_deg_2000_5000: nan
- fit_front_phase_rms_deg_300_1200: 15.108
- fit_front_phase_rms_deg_300_2000: 15.108
- fit_front_rms_db_2000_5000: nan
- fit_front_rms_db_300_1200: 2.581
- fit_front_rms_db_300_2000: 2.581
- fit_rear_complex_rel_rms_2000_5000: nan
- fit_rear_complex_rel_rms_300_1200: 0.253
- fit_rear_complex_rel_rms_300_2000: 0.253
- fit_rear_norm_rms_db_2000_5000: nan
- fit_rear_norm_rms_db_300_1200: 1.257
- fit_rear_norm_rms_db_300_2000: 1.257
- fit_rear_phase_rms_deg_2000_5000: nan
- fit_rear_phase_rms_deg_300_1200: 13.873
- fit_rear_phase_rms_deg_300_2000: 13.873
- fit_rear_rms_db_2000_5000: nan
- fit_rear_rms_db_300_1200: 1.007
- fit_rear_rms_db_300_2000: 1.007
- fit_rms_db_2000_5000: nan
- fit_rms_db_300_1200: 1.959
- fit_rms_db_300_2000: 1.959

## Validation target, Wmax 305 mm

- Validation target: `output/data/polar_data_juan_lx521_top_raw.h5` driver `L22MG (LX521 top raw)`, front angles [0, 15, 30, 45, 60, 75, 90], measured distance 0.5 m.
- Validation preset: `juan-top-raw`.
- Validation model angle policy: `target_hdf5_angles` from `output/data/polar_data_juan_lx521_top_raw.h5:L22MG (LX521 top raw)/angles`; solver angles [0, 15, 30, 45, 60, 75, 90], target angles [0, 15, 30, 45, 60, 75, 90], angular interpolation used for validation: no.
- Validation target acceptance gate: pass; validation target is Juan L22MG LX521 top-baffle raw/no-crossover HDF5 at 50 cm and LM/L22MG height.
- Validation target policy: validation target is Juan L22MG LX521 top-baffle raw/no-crossover HDF5 at 50 cm and LM/L22MG height.
- Validation hypothesis: `juan_baffleless_to_juan_top_baffle_l22mg_raw`.
- Validation target processing policy: repo processed Juan LX521 top-baffle raw/no-crossover HDF5 measured at 50 cm and LM/L22MG height; same-room/same-driver comparison against Juan baffleless source data.
- Validation target peak-selection policy: standard Juan HDF5 export path; no Andres IR peak-selection policy is used.
- Direct IR peak policy mirrored into this simulation artifact: `first-strong` from `output/data/polar_data_juan_lx521_top_raw.h5:root direct_ir_peak_policy`. Naked source HDF5 root policy: `unknown`. This keeps generated simulation artifacts aligned with the validation/published HDF5 policy; it does not infer missing naked-source timing metadata.
- Validation target gate/window policy: gate/window policy as stored in the processed Juan HDF5.
- Validation target normalization policy: primary validation compares normalized polar shape, SPL(theta)-SPL(0), at each frequency.
- Andres published-explorer parity status for this target: not applicable/not proven; explorer `not recorded`; 1004 Hz max delta nan dB.
- Validation target measurement notes: distance=0.5 m; height=reference l22mg; first note=PB -40 DB / Measurement distance: 50 cm. Mic height: L22MG/LM. LX521 top baffle mounted; raw/no crossover/no EQ..
- Validation target passive-state provenance: `passive_state_status=unused_um_tweeter_state_unrecorded`, `passive_state_acceptance_use=current_l22_target_but_passive_geometry_not_proven`.
- Simulation mic horizontal polar radius used for validation: 0.5 m.
- Simulation mic z offset for validation: 0.0 mm relative to the L22 center plane, reference `l22`; 3D L22-axis distance at 0 deg is 0.500 m and vertical elevation is 0.00 deg.
- This validation mic height is separate from Juan's naked-source measurement radius and from the allowed scalar gain/delay alignment.
- Normalization rationale: source and target absolute SPL levels are not assumed matched, so primary acceptance compares normalized polar shape, SPL(theta)-SPL(0), at each frequency.
- The scalar gain/delay alignment is applied once for validation; it is not a source-fit knob and cannot change normalized polar/directivity errors.
- Baffle-transfer metrics subtract the nude equivalent source evaluated at the same validation mic height after the same dataset-level reference alignment used for validation.
- That reference alignment is not a rear/source level correction; Juan's rear magnitude remains used as stored, and normalized polar/directivity errors are unchanged.
- Validation target direct timing anchor warning: none in the HDF5 timing metadata. Late in-window target warning: none in the HDF5 timing metadata.
- Validation target high-angle IR peak audit: no Andres raw-IR peak audit is required for the Juan top-baffle target; no timing metadata flags are present in the processed HDF5.
- Allowed alignment applied: scalar gain 1.08 dB and delay 0.025 ms; delay fit uses angles through 60 deg for stable direct-arrival phase alignment.
- Alignment audit: gain is fit only on the 0 deg response over 300-1200 Hz; delay is searched over -1.0 to 1.0 ms across 801 global candidates; angle-dependent, band-specific, source-level, and rear-level correction counts are zero.
- baffle_transfer_rms_db_300_1200: 4.415
- baffle_transfer_rms_db_300_2000: 4.415
- band_2000_5000_covered_max_hz: nan
- band_2000_5000_covered_min_hz: nan
- band_2000_5000_full_coverage: 0.000
- band_2000_5000_point_count: 0.000
- band_2000_5000_requested_max_hz: 5000.000
- band_2000_5000_requested_min_hz: 2000.000
- band_300_1200_covered_max_hz: 1199.707
- band_300_1200_covered_min_hz: 300.293
- band_300_1200_full_coverage: 1.000
- band_300_1200_point_count: 2457.000
- band_300_1200_requested_max_hz: 1200.000
- band_300_1200_requested_min_hz: 300.000
- band_300_2000_covered_max_hz: 1199.707
- band_300_2000_covered_min_hz: 300.293
- band_300_2000_full_coverage: 0.000
- band_300_2000_point_count: 2457.000
- band_300_2000_requested_max_hz: 2000.000
- band_300_2000_requested_min_hz: 300.000
- beamwidth_6_db_rms_error_300_1200: 9.554
- beamwidth_6_db_rms_error_300_2000: 9.554
- complex_rel_rms_2000_5000: nan
- complex_rel_rms_300_1200: 1.657
- complex_rel_rms_300_2000: 1.657
- di_db_rms_error_300_1200: 0.724
- di_db_rms_error_300_2000: 0.724
- f90_f0_mean_error_db_2000_5000: nan
- f90_f0_mean_error_db_300_1200: 5.093
- f90_f0_mean_error_db_300_2000: 5.093
- f90_f0_rms_error_db_2000_5000: nan
- f90_f0_rms_error_db_300_1200: 7.160
- f90_f0_rms_error_db_300_2000: 7.160
- f90_f0_sim_mean_db_2000_5000: nan
- f90_f0_sim_mean_db_300_1200: -16.728
- f90_f0_sim_mean_db_300_2000: -16.728
- f90_f0_target_mean_db_2000_5000: nan
- f90_f0_target_mean_db_300_1200: -21.821
- f90_f0_target_mean_db_300_2000: -21.821
- normalized_polar_max_abs_error_angle_deg_2000_5000: nan
- normalized_polar_max_abs_error_angle_deg_2000_5000_target_above_minus20db: nan
- normalized_polar_max_abs_error_angle_deg_2000_5000_through_60deg: nan
- normalized_polar_max_abs_error_angle_deg_2000_5000_through_80deg: nan
- normalized_polar_max_abs_error_angle_deg_300_1200: 75.000
- normalized_polar_max_abs_error_angle_deg_300_1200_target_above_minus20db: 75.000
- normalized_polar_max_abs_error_angle_deg_300_1200_through_60deg: 60.000
- normalized_polar_max_abs_error_angle_deg_300_1200_through_80deg: 75.000
- normalized_polar_max_abs_error_angle_deg_300_2000: 75.000
- normalized_polar_max_abs_error_angle_deg_300_2000_target_above_minus20db: 75.000
- normalized_polar_max_abs_error_angle_deg_300_2000_through_60deg: 60.000
- normalized_polar_max_abs_error_angle_deg_300_2000_through_80deg: 75.000
- normalized_polar_max_abs_error_db_2000_5000: nan
- normalized_polar_max_abs_error_db_2000_5000_target_above_minus20db: nan
- normalized_polar_max_abs_error_db_2000_5000_through_60deg: nan
- normalized_polar_max_abs_error_db_2000_5000_through_80deg: nan
- normalized_polar_max_abs_error_db_300_1200: 18.476
- normalized_polar_max_abs_error_db_300_1200_target_above_minus20db: 8.037
- normalized_polar_max_abs_error_db_300_1200_through_60deg: 3.477
- normalized_polar_max_abs_error_db_300_1200_through_80deg: 18.476
- normalized_polar_max_abs_error_db_300_2000: 18.476
- normalized_polar_max_abs_error_db_300_2000_target_above_minus20db: 8.037
- normalized_polar_max_abs_error_db_300_2000_through_60deg: 3.477
- normalized_polar_max_abs_error_db_300_2000_through_80deg: 18.476
- normalized_polar_max_abs_error_freq_hz_2000_5000: nan
- normalized_polar_max_abs_error_freq_hz_2000_5000_target_above_minus20db: nan
- normalized_polar_max_abs_error_freq_hz_2000_5000_through_60deg: nan
- normalized_polar_max_abs_error_freq_hz_2000_5000_through_80deg: nan
- normalized_polar_max_abs_error_freq_hz_300_1200: 300.293
- normalized_polar_max_abs_error_freq_hz_300_1200_target_above_minus20db: 677.856
- normalized_polar_max_abs_error_freq_hz_300_1200_through_60deg: 1122.437
- normalized_polar_max_abs_error_freq_hz_300_1200_through_80deg: 300.293
- normalized_polar_max_abs_error_freq_hz_300_2000: 300.293
- normalized_polar_max_abs_error_freq_hz_300_2000_target_above_minus20db: 677.856
- normalized_polar_max_abs_error_freq_hz_300_2000_through_60deg: 1122.437
- normalized_polar_max_abs_error_freq_hz_300_2000_through_80deg: 300.293
- normalized_polar_max_abs_error_signed_db_2000_5000: nan
- normalized_polar_max_abs_error_signed_db_2000_5000_target_above_minus20db: nan
- normalized_polar_max_abs_error_signed_db_2000_5000_through_60deg: nan
- normalized_polar_max_abs_error_signed_db_2000_5000_through_80deg: nan
- normalized_polar_max_abs_error_signed_db_300_1200: 18.476
- normalized_polar_max_abs_error_signed_db_300_1200_target_above_minus20db: 8.037
- normalized_polar_max_abs_error_signed_db_300_1200_through_60deg: 3.477
- normalized_polar_max_abs_error_signed_db_300_1200_through_80deg: 18.476
- normalized_polar_max_abs_error_signed_db_300_2000: 18.476
- normalized_polar_max_abs_error_signed_db_300_2000_target_above_minus20db: 8.037
- normalized_polar_max_abs_error_signed_db_300_2000_through_60deg: 3.477
- normalized_polar_max_abs_error_signed_db_300_2000_through_80deg: 18.476
- normalized_polar_rms_db_2000_5000: nan
- normalized_polar_rms_db_2000_5000_clean_timing_angles: nan
- normalized_polar_rms_db_2000_5000_excluding_90deg: nan
- normalized_polar_rms_db_2000_5000_target_above_minus20db: nan
- normalized_polar_rms_db_2000_5000_through_60deg: nan
- normalized_polar_rms_db_2000_5000_through_80deg: nan
- normalized_polar_rms_db_300_1200: 4.219
- normalized_polar_rms_db_300_1200_clean_timing_angles: 4.219
- normalized_polar_rms_db_300_1200_excluding_90deg: 3.497
- normalized_polar_rms_db_300_1200_target_above_minus20db: 1.594
- normalized_polar_rms_db_300_1200_through_60deg: 1.009
- normalized_polar_rms_db_300_1200_through_80deg: 3.497
- normalized_polar_rms_db_300_2000: 4.219
- normalized_polar_rms_db_300_2000_clean_timing_angles: 4.219
- normalized_polar_rms_db_300_2000_excluding_90deg: 3.497
- normalized_polar_rms_db_300_2000_target_above_minus20db: 1.594
- normalized_polar_rms_db_300_2000_through_60deg: 1.009
- normalized_polar_rms_db_300_2000_through_80deg: 3.497
- nude_to_andres_gain_db_for_transfer: 3.897
- on_axis_mean_error_db_2000_5000: nan
- on_axis_mean_error_db_300_1200: -0.000
- on_axis_mean_error_db_300_2000: -0.000
- on_axis_rms_error_db_2000_5000: nan
- on_axis_rms_error_db_300_1200: 1.395
- on_axis_rms_error_db_300_2000: 1.395
- target_timing_clean_angle_count: 7.000
- target_timing_suspect_angle_count: 0.000
- validation_alignment_delay_count: 1.000
- validation_alignment_scalar_gain_count: 1.000
- validation_angle_dependent_gain_correction_count: 0.000
- validation_angular_interpolation_used: 0.000
- validation_band_specific_gain_correction_count: 0.000
- validation_delay_fit_max_angle_deg: 60.000
- validation_delay_fit_max_hz: 2000.000
- validation_delay_fit_min_hz: 300.000
- validation_delay_hit_search_bound: 0.000
- validation_delay_ms: 0.025
- validation_delay_search_max_ms: 1.000
- validation_delay_search_min_ms: -1.000
- validation_delay_search_step_count: 801.000
- validation_gain_db: 1.080
- validation_gain_fit_angle_deg: 0.000
- validation_gain_fit_max_hz: 1200.000
- validation_gain_fit_min_hz: 300.000
- validation_model_angle_count: 7.000
- validation_rear_level_correction_db: 0.000
- validation_source_level_correction_db: 0.000
- validation_target_angle_count: 7.000
- Acceptance check, all required gates (canonical validation target, full 300-1200 coverage, normalized polar RMS <= 1.5 dB, dense-BEM mesh change <= 0.5 dB, Juan-only source CV recommended, and off-plane source ambiguity only when the validation mic is off the L22 plane): fail for this baseline. Target acceptance gate: pass; validation target is Juan L22MG LX521 top-baffle raw/no-crossover HDF5 at 50 cm and LM/L22MG height. Direct timing anchor diagnostic: pass; no stored selected-peak early/rejected/not-first-lobe flags. Late-window target diagnostic: stored HDF5 metadata pass; no large late in-window target peaks. Shape gate: fail (4.219 dB). Mesh gate: not proven; no dense-BEM mesh convergence sweep was run in this invocation. Source CV gate: pass; Passes Juan-only thresholds: failed folds <= 0, in-sample side-worst <= 3.000 dB, in-sample absolute side-worst <= 3.000 dB, in-sample phase side-worst <= 30.000 deg, held-out side-worst <= 4.000 dB. Source off-plane gate: not_required; validation target is on the LM/L22MG height, so Andres UM-height off-plane ambiguity is diagnostic only.
- Shape diagnostic: normalized RMS through 60 deg over covered 300-1200 band is 1.009 dB; through 80 deg is 3.497 dB; all-angle clean-timing RMS is 4.219 dB. target F90-F0 mean -21.82 dB, sim F90-F0 mean -16.73 dB;  worst normalized error is +18.476 dB at 300.3 Hz / 75 deg; through-60 max is 3.477 dB at 1122.4 Hz / 60 deg. F90 remains a high-angle/null-sensitive diagnostic even without a timing flag.
- Primary-scope diagnostic, not acceptance: this invocation does not cover the full 300-2000 Hz primary scope; covered range is 300-1200 Hz.
- Width-sweep status: qualitative only. The 305 mm baseline has not passed all validation gates, so width changes cannot be read as accepted LX521 behavior.
- Width-sweep baseline context: normalized polar RMS 300-1200 Hz = 4.219 dB; through-60 = 1.009 dB; through-80 = 3.497 dB; baffle-transfer RMS = 4.415 dB; DI RMS error = 0.724 dB.
- Width-sweep blockers: mesh gate: not proven; no dense-BEM mesh convergence sweep was run in this invocation; source CV gate: pass; Passes Juan-only thresholds: failed folds <= 0, in-sample side-worst <= 3.000 dB, in-sample absolute side-worst <= 3.000 dB, in-sample phase side-worst <= 30.000 deg, held-out side-worst <= 4.000 dB; source off-plane gate: not_required; validation target is on the LM/L22MG height, so Andres UM-height off-plane ambiguity is diagnostic only.

## Qualitative width sweep

The sweep keeps all geometry fixed except the z=254 mm wide vertices at +/-Wmax/2.

| Wmax mm | F90-F0 mean 300-1200 dB | DI mean 300-1200 dB | -6 dB BW median 300-1200 deg | rear/front norm RMS 300-2000 dB |
| ---: | ---: | ---: | ---: | ---: |
| 205 | -19.33 | 5.30 | 113.0 | 0.89 |
| 305 | -17.75 | 5.43 | 111.7 | 1.25 |
| 405 | -18.70 | 5.71 | 107.7 | 2.06 |
| 505 | -19.48 | 5.80 | 105.7 | 2.66 |

## Convergence

No convergence sweep was run in this invocation. For BEM, repeat the run with multiple `--bem-mesh-h-mm` values and compare the exported normalized polars before treating the result as converged.

## Artifacts

- `output/l22mg-bem-juan-top-populated-silent-compact2-wmax-abcd/polar_data_l22mg_lx5214_baffle_sim.h5`: repo-compatible simulation HDF5, including `/validation_decomposition` datasets for the per-frequency/angle validation audit.
- `output/l22mg-bem-juan-top-populated-silent-compact2-wmax-abcd/hdf5_provenance.json`: inspected source/target HDF5 provenance sidecar.
- `output/l22mg-bem-juan-top-populated-silent-compact2-wmax-abcd/validation_metrics.csv`: metric table against the validation target.
- `output/l22mg-bem-juan-top-populated-silent-compact2-wmax-abcd/validation_decomposition.csv`: per-frequency/angle measured-baffle, model, synthetic-nude, normalized-error, and baffle-transfer decomposition.
- `output/l22mg-bem-juan-top-populated-silent-compact2-wmax-abcd/width_sweep_metrics.csv`: sweep table.
- `output/l22mg-bem-juan-top-populated-silent-compact2-wmax-abcd/lx5214_top_baffle_w305_mesh.obj`: mesh handoff for future BEM.
- `output/l22mg-bem-juan-top-populated-silent-compact2-wmax-abcd/plots/validation_vs_target.png`: SPL, normalized polar, baffle transfer, DI/beamwidth.
- `output/l22mg-bem-juan-top-populated-silent-compact2-wmax-abcd/plots/validation_vs_andres.png`: legacy filename alias for the same validation-target plot.
- `output/l22mg-bem-juan-top-populated-silent-compact2-wmax-abcd/plots/normalized_polar_error.png`: normalized polar error heatmap.
- `output/l22mg-bem-juan-top-populated-silent-compact2-wmax-abcd/plots/naked_baffle_model_contours.png`: single-image normalized contour comparison for Juan naked L22, the validation target, and the synthetic-baffle model.
- `output/l22mg-bem-juan-top-populated-silent-compact2-wmax-abcd/plots/width_sweep_summary.png`: sweep curves.
- `output/l22mg-bem-juan-top-populated-silent-compact2-wmax-abcd/plots/width_sweep_band_table_plot.png`: sweep band summaries.

## Known limits

- Validation alignment uses only one scalar gain and one delay.
- The default BEM source term is an equivalent source fitted from nude polars; source-surface coupling around the real L22 frame/flange is not explicitly modeled.
- `--source-model axisymmetric-directivity` rotates Juan's measured naked angular field into a directivity table and propagates it from the measurement radius. It is a no-inversion source diagnostic, not proof that Juan's horizontal polar uniquely determines Andres' off-plane incident field.
- `--bem-active-piston-source` switches to a flat prescribed-Neumann source disk. Its default strength follows Juan on-axis only and does not fit Juan polar directivity, so it is a source-surface diagnostic rather than an acceptance-grade driver model.
- `--source-model active-surface-modal` switches to a Juan-fitted H1659-shaped prescribed-Neumann source surface. It is a stronger driver-surface diagnostic, but it is still an open rigid acoustic surface, not coupled elastic cone/suspension physics.
- `--source-model split-active-surface-modal` fits independent front/rear H1659-shaped prescribed-Neumann source surfaces to Juan only. The side gap is a source-model discretization parameter, not an Andres-derived correction.
- Legendre BEM runs use a far-field angular model as a near-field multipole expansion; discrete-source BEM runs bound that near field, split-discrete runs separate front/rear components, and split-ring runs expand circular source rings.
- `--include-driver-face` adds a simple rigid surface-mounted annulus, but it is still not a detailed basket/cone/flange model.
- `--include-driver-stl-envelope` uses only a coarse revolved radius envelope from the driver STL for diagnostic obstruction sensitivity. It is not a raw-STL solve, not feature-preserving remeshing, and not an acceptance-grade model.
- `--include-driver-frame` adds a coarse feature-aware rigid frame/basket/motor obstruction from H1659 STL dimensions. `--driver-frame-include-mounting-holes` optionally cuts the STL-derived screw pockets into that flange, but the path still omits cone/surround compliance, elastic coupling, and feature-preserving STL remeshing.
- `--active-driver-feature-proxy` explicitly requests the H1659 acoustic feature-proxy path: rigid frame/flange/motor geometry plus a Juan-fitted prescribed-Neumann acoustic surface, with mounting pockets forced on. Combining `--include-driver-frame` with an active-surface source remains labelled as the same proxy path for legacy runs. The 0.6 mm flange sidewalls default off for this path as an explicit mesh-quality approximation; pass `--driver-frame-include-front-flange-sidewalls` to include them. It is not a scalar correction, not fitted to Andres, not a raw-STL dense solve, and not elastic FEM-BEM.
- Runtime note: the dense BEM cost is dominated by matrix assembly and O(N^3) linear solves per frequency. A Rust rewrite is not the first lever unless profiling shows Python overhead dominates; better mesh sizing, iterative solvers, or an accelerated BEM backend matter more.
- Linear-solver note: `--bem-linear-solver gmres` is an audit/control path in this dense backend. `gmres-matrix-free` avoids storing the dense matrix for targeted larger diagnostics, but it is still an O(N^2) dense-kernel matvec, not FMM-BEM or H-matrix acceleration, and it does not change the source model or validation alignment.
- Acoustic-center note: the automatic phase scan is conservative and falls back to 0 mm when the best fit lands on the +/-40 mm search boundary; use `--acoustic-center-offset-mm` for an explicit nonzero offset study.
- Mesh note: `delaunay-adaptive` keeps the interior at the requested h while sampling the outside edge, cutout, passive holes, and thickness walls at h/2. `delaunay-local` adds a finer point field only near baffle features, and `--bem-auto-mesh` derives broad/local spacings from wavelength plus baffle/cutout feature dimensions.
- Edge fallback strengths are fixed baseline coefficients, not fitted to Andres.
- True BEM acoustic mesh convergence is proven only when a BEM mesh sweep is run and compared; the fallback convergence table checks edge/cutout sampling density only.

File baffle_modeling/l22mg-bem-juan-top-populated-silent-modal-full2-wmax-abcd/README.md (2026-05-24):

# LX521.4 L22MG baffle simulation

This is the current automated workflow for SEAS/LINKWITZ L22MG mounted as the only active source in the LX521.4 top baffle.

## A/B/C/D Wmax Shoulder Sweep

This run uses the current best physically grounded candidate source, `h1659-modal-full-2`, with the `populated-silent` passive treatment. Only the symmetric LX521 `Wmax` shoulder point is moved; the L22 cutout, neck, top, bottom, passive locations, source fit, target, IR peak policy, and validation angle grid are unchanged.

| variant | Wmax | meaning | full RMS | exact 300/75 removed | deep-null cluster removed | target >= -20 dB | <=60 deg | <=80 deg | worst residual |
| --- | ---: | --- | ---: | ---: | ---: | ---: | ---: | ---: | --- |
| A | 205 mm | closest shoulder | 4.209 | 4.207 | 3.833 | 1.912 | 1.265 | 3.536 | +18.081 dB @ 300 Hz / 75 deg |
| B | 305 mm | actual LX521 | 4.244 | 4.242 | 3.852 | 1.587 | 1.001 | 3.507 | +18.487 dB @ 300 Hz / 75 deg |
| C | 405 mm | wide shoulder | 3.904 | 3.902 | 3.492 | 1.323 | 0.605 | 3.238 | +18.182 dB @ 300 Hz / 75 deg |
| D | 505 mm | widest shoulder | 3.780 | 3.777 | 3.352 | 1.374 | 0.524 | 3.156 | +18.234 dB @ 300 Hz / 75 deg |

Result: widening the shoulder helps. D gives the best full-band and deep-null-cluster-removed RMS, while C gives the best `target >= -20 dB` diagnostic RMS. None of the four passes the formal full-band gate because all still miss the 300 Hz / 75 deg target null by about 18 dB.

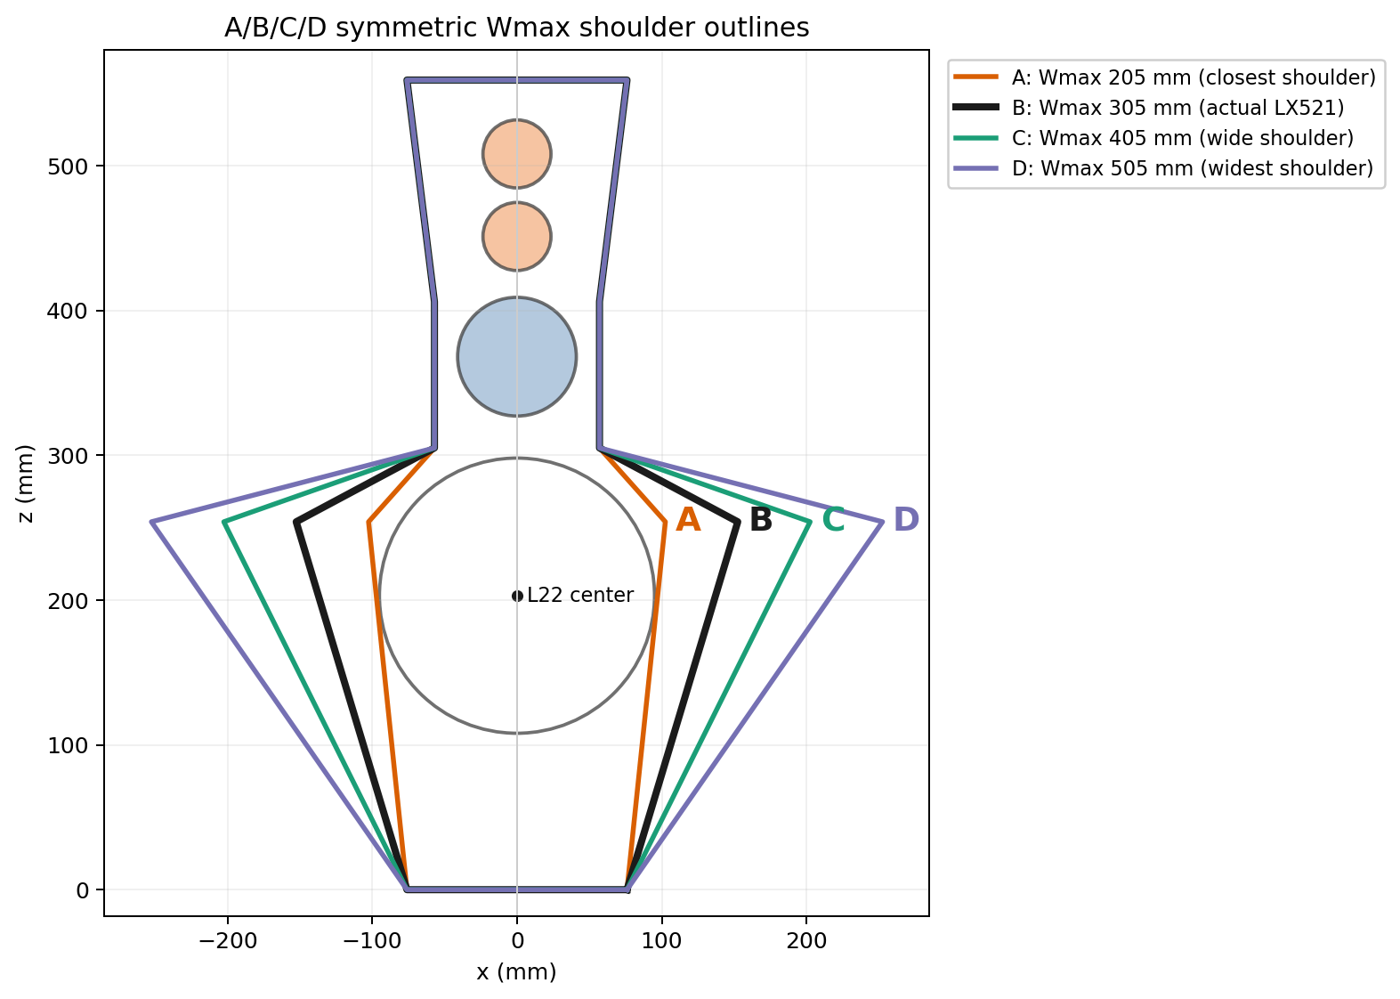
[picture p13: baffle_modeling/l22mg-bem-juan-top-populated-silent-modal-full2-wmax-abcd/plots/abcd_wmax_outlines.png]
A/B/C/D Wmax shoulder outlines


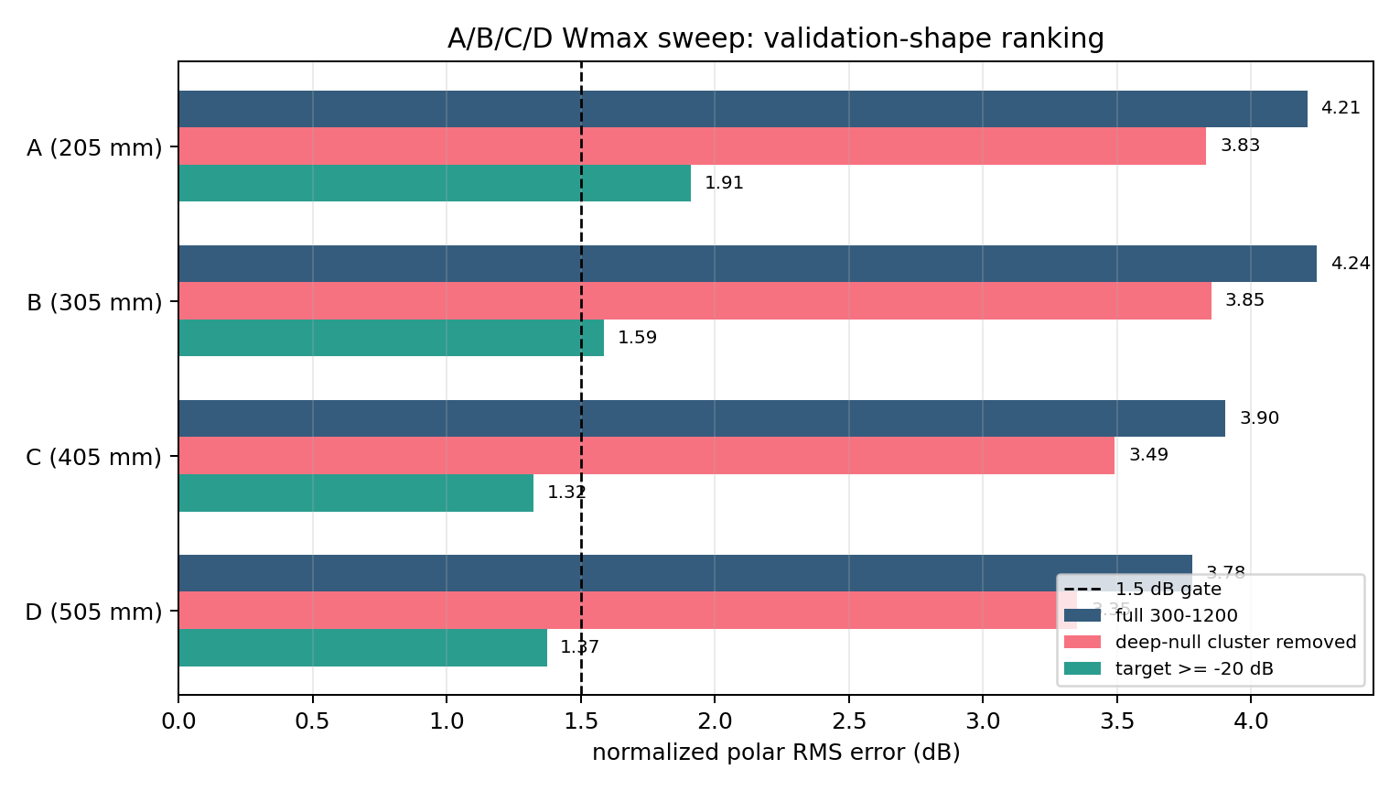
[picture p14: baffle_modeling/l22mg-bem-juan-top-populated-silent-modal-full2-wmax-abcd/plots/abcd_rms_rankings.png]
A/B/C/D RMS rankings


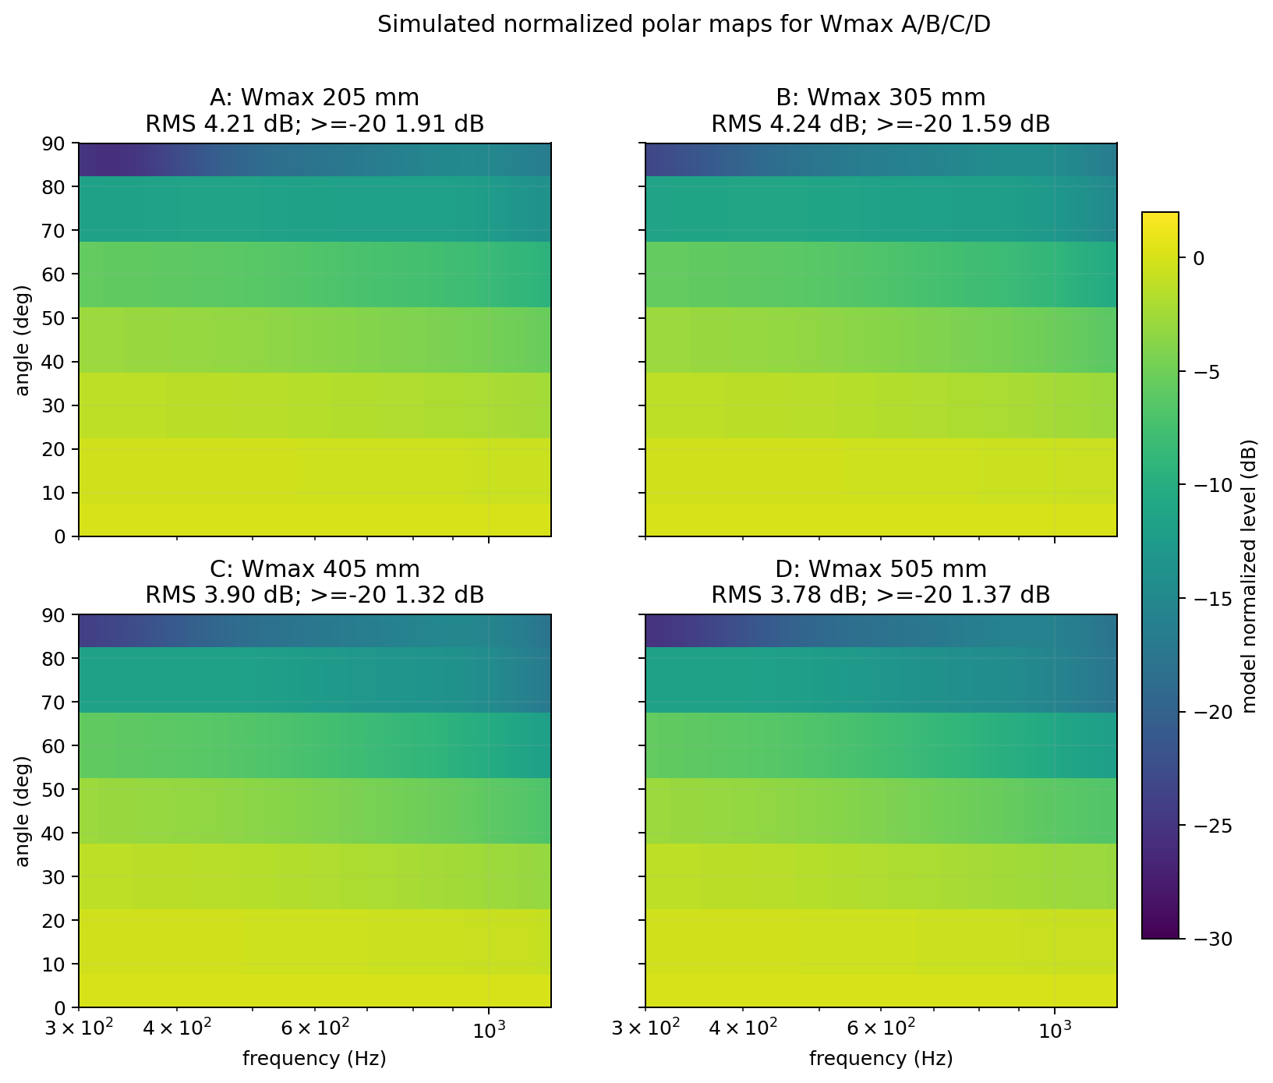
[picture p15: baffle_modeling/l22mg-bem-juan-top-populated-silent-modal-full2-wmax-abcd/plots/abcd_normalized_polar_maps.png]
A/B/C/D normalized polar maps


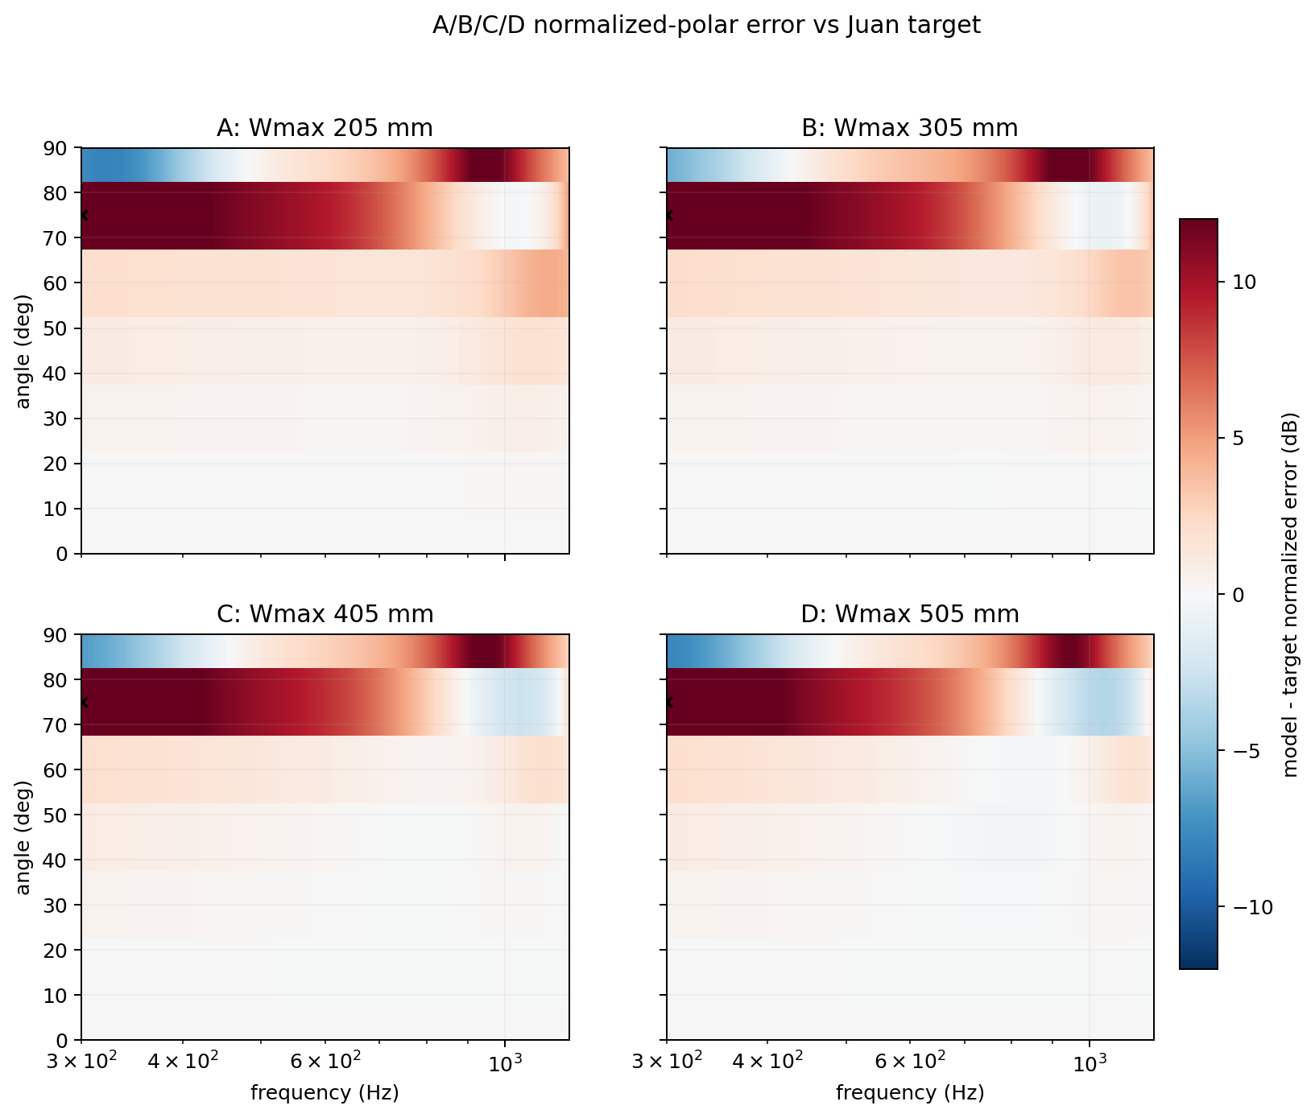
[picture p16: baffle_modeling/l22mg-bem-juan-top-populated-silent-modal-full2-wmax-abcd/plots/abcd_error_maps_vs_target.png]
A/B/C/D normalized-polar error maps


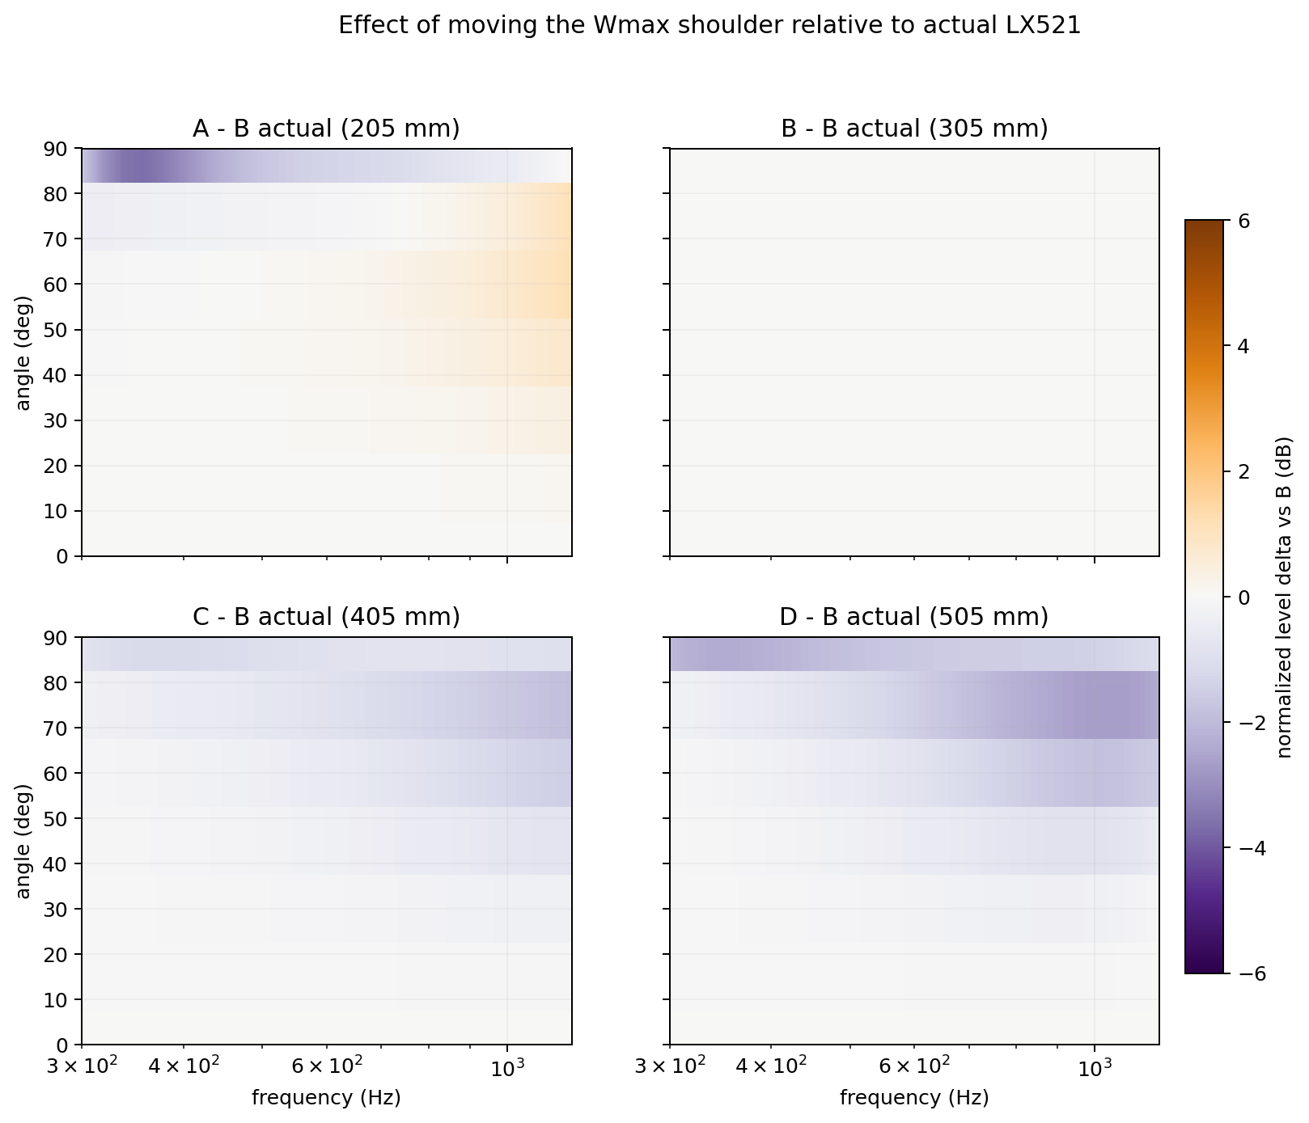
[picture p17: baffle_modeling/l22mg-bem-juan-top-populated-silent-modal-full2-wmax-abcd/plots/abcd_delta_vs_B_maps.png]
A/B/C/D delta versus B actual LX521


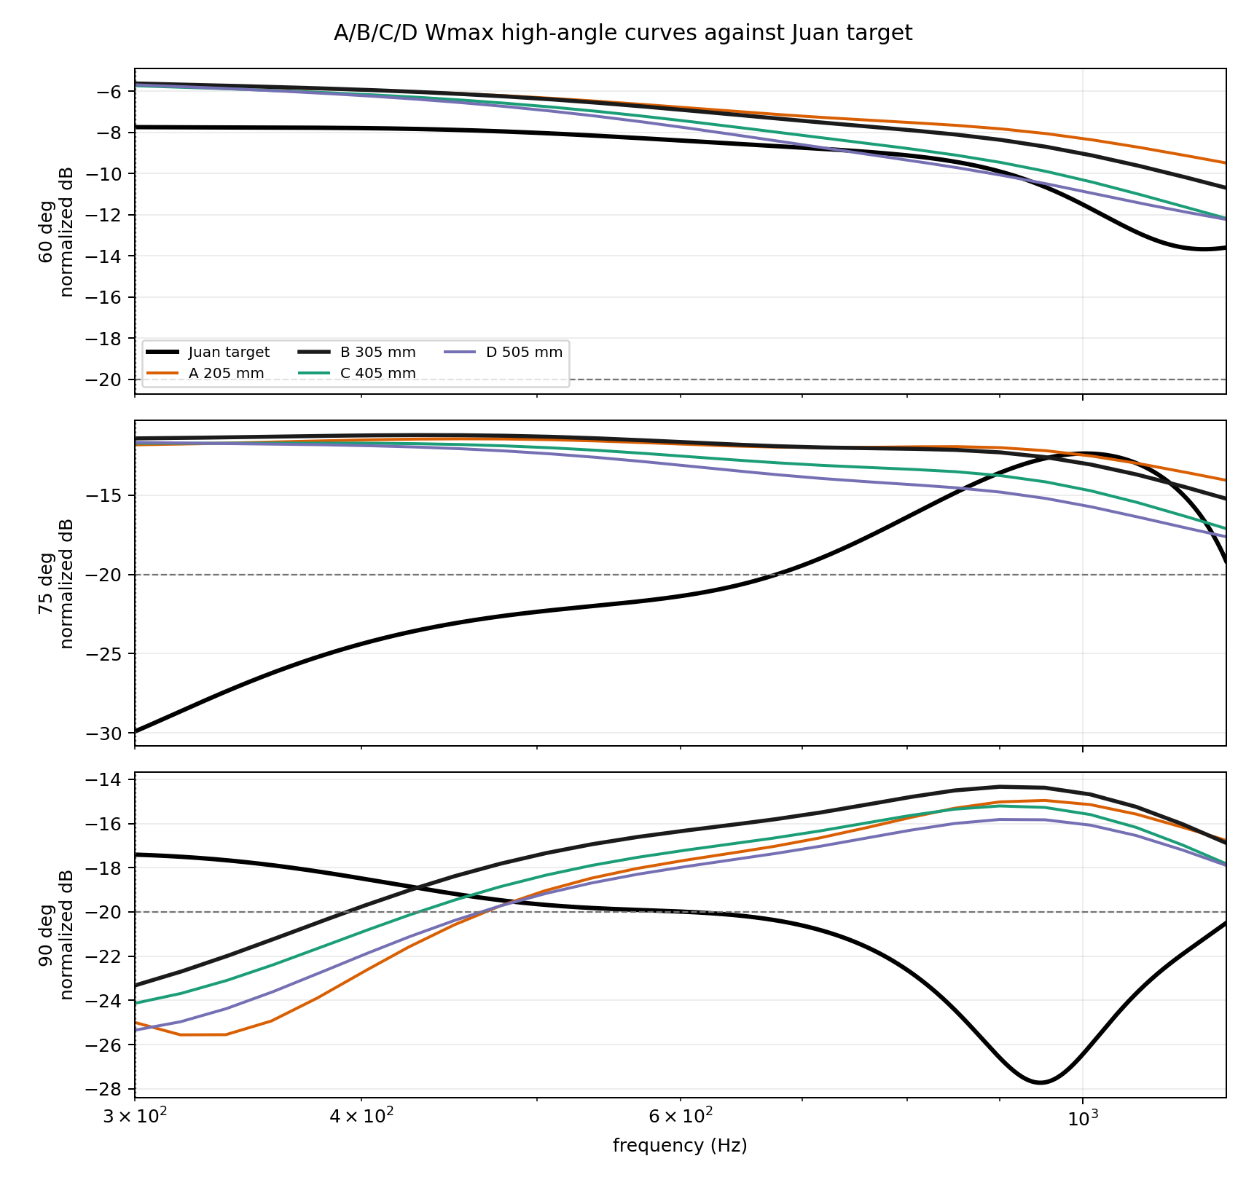
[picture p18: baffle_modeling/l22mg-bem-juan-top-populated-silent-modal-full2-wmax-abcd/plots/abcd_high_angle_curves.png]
A/B/C/D high-angle curves


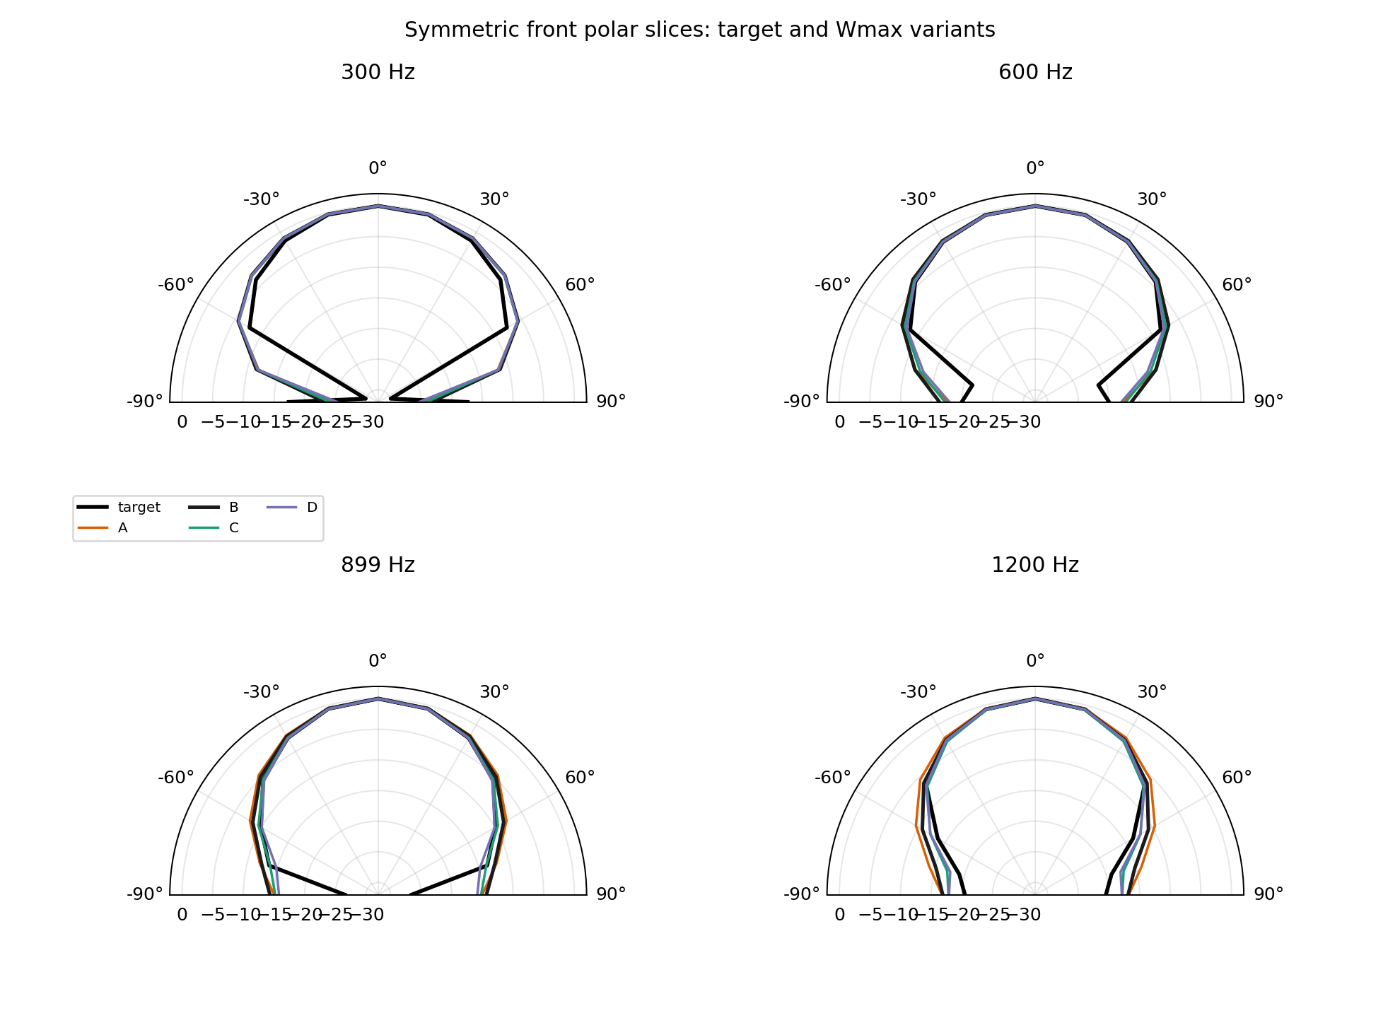
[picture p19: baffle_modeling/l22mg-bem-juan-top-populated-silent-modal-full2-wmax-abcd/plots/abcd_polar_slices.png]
A/B/C/D symmetric front polar slices


Supporting CSV: `abcd_width_validation_summary.csv`.

## Solver status

- Solver: `dense_neumann_bem`.
- Fidelity label: dense constant-element exterior Neumann BEM for rigid finite-thickness baffle; bounded by panel count and collocation approximation.
- Geometry source: `linkwitz/lx521metric-baffle.pdf` plus the parameterized dimensions in the goal brief.
- Baffle geometry provenance: exact outline vertices, L22 cutout, optional passive holes, modeled cutouts, passive-geometry policy, edge policy, and width-sweep policy are exported as HDF5 metadata.
- Driver STL geometry provenance: `linkwitz/H1659-08_U22REX_P-SL_driver.stl` status `present`; OD 221.0 mm, depth 90.6 mm, front proud height 0.6 mm, rear depth 90.0 mm, and flange overlap past the 190 mm L22 cutout radius 15.5 mm. These dimensions are provenance for H1659-derived approximations, not raw-STL acceptance evidence.
- Frequency range exported: 300-1200 Hz. Results above 5 kHz are intentionally not generated by default.
- Frequency-scope policy: primary-scope diagnostic; acceptance still requires 300-1200 shape and mesh gates.
- Mesh handoff: 4885 vertices, 8204 triangles at h=6.5 mm using `delaunay`; lambda(1200 Hz)=285.8 mm; lambda/6=47.6 mm, lambda/10=28.6 mm.
- Mesh area check: front 0.08091 m2, analytic solid face 0.07223 m2 (front/side area includes added passive UM driver face and passive tweeter driver faces; analytic solid face is baffle only).
- BEM mesh quality: edge median 19.799 mm, p95 33.254 mm, max 39.830 mm; min triangle angle 14.052 deg (p01 14.052 deg); max edge ratio 4.083.
- BEM acoustic mesh: method `delaunay-local`, h=42.0 mm, quadrature order=7, max panels=4000, analytic source normal derivative. Adaptive controls: boundary h=28.0 mm, local h=28.0 mm, local refinement width=90.0 mm, feature clearance=0.25x local spacing. Near-panel quadrature: q7, subdivisions=1, distance factor=2.50. Target-panel normal-trace averaging: q7, chunk size=128. Linear solver: dense direct LU solve; max relative residual=1.567e-15 at 476.2 Hz (RMS relative residual=1.280e-15). Mesh target at exported max 1200 Hz (lambda=285.8 mm): actual broad/boundary/local h 42.0/28.0/28.0 mm vs lambda/6 47.6 mm and lambda/10 28.6 mm; status `pass` (actual BEM mesh spacing is within lambda/6 broad and lambda/10 boundary/local targets). This is sizing metadata, not convergence proof. Active driver face/frame/STL envelope not included. Passive UM rigid face included: diameter 82.0 mm, height 4.0 mm, mesh h 16.0 mm; the UM position remains a closed baffle patch under the silent-driver face. Passive tweeter rigid faces included: two positions, diameter 47.0 mm, height 3.0 mm, mesh h 12.0 mm; the tweeter baffle positions remain closed under the raised faces.
- Passive aperture treatment: `populated-silent`.
- Populated-silent passive approximation: UM position includes a raised rigid silent-driver face over a closed patch; tweeter positions include raised rigid silent-driver faces over closed patches; no passive holes. This is a rigid silent-driver scatterer approximation, not passive-cone elastic physics.
- Canonical BEM check: `scripts/validate_dense_bem.py` validates the same dense Neumann matrix against analytic rigid-sphere scattering; latest generated report is `docs/l22mg-baffle-bem-canonical/README.md`.
- LX521 BEM caution: canonical sphere validation does not prove the L22MG equivalent-source near field or the coarse rectangular baffle mesh are converged.
- LX521 BEM numeric probe: `scripts/probe_l22mg_bem_numerics.py` checks matrix conditioning at convergence hot spots; the current 1069 Hz / 70 deg lobe movement is not explained by a near-singular matrix in the latest q1/q3 probes.
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

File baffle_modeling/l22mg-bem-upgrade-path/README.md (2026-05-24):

# L22MG BEM solver upgrade path

This note records the non-ad-hoc path for moving beyond the current dense constant-panel BEM validation backend. It is generated from the current driver-STL audit and acceptance scorecards so source radius, target geometry, and blocker status do not drift from the validation artifacts.
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

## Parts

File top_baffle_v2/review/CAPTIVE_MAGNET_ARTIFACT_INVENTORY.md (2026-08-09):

# Captive-magnet artifact inventory

Generated from the authoritative release catalog and the successful full
Bambu P2S slice release of 2026-07-24. There are no Rhino `.3dm` files in this
release; the directly loadable files are G-code-bearing Bambu
`.gcode.3mf` projects. Each ready project already contains its exact
`PausePrint` event, front-face-down arrangement, Arachne profile, and verified
process settings.

The 56 ready projects and their raw G-code live in the local, Git-ignored
`captive_magnet_slice_audit/slices/` workspace (about 1.3 GB). Regenerate that
workspace on a Bambu Studio host with `make bambu_slice_release`; the compact,
tracked manifest below is the release authority.

The machine-readable authority is
[`captive_magnet_pause_manifest.json`](captive_magnet_slice_audit/captive_magnet_pause_manifest.json),
with the human-readable insertion/polarity table in
[`CAPTIVE_MAGNET_PAUSE_MANIFEST.md`](captive_magnet_slice_audit/CAPTIVE_MAGNET_PAUSE_MANIFEST.md).

## Floor stand

| STL / directly loadable Bambu project | Descriptive piece | Magnets |
|---|---|---:|
| [`lx521_top_addonA_1of4_shoulder_top_left.stl`](../floor_stand/stl/lx521_top_addonA_1of4_shoulder_top_left.stl) · [ready 3MF](captive_magnet_slice_audit/slices/floor_stand_A_lx521_top_addonA_1of4_shoulder_top_left/ready/ready_to_print.gcode.3mf) | Stock A shoulder — top-left, 1 of 4 | 1 |
| [`lx521_top_addonA_2of4_shoulder_top_right.stl`](../floor_stand/stl/lx521_top_addonA_2of4_shoulder_top_right.stl) · [ready 3MF](captive_magnet_slice_audit/slices/floor_stand_A_lx521_top_addonA_2of4_shoulder_top_right/ready/ready_to_print.gcode.3mf) | Stock A shoulder — top-right, 2 of 4 | 1 |
| [`lx521_top_addonA_3of4_shoulder_bottom_left.stl`](../floor_stand/stl/lx521_top_addonA_3of4_shoulder_bottom_left.stl) · [ready 3MF](captive_magnet_slice_audit/slices/floor_stand_A_lx521_top_addonA_3of4_shoulder_bottom_left/ready/ready_to_print.gcode.3mf) | Stock A shoulder — bottom-left, 3 of 4 | 1 |
| [`lx521_top_addonA_4of4_shoulder_bottom_right.stl`](../floor_stand/stl/lx521_top_addonA_4of4_shoulder_bottom_right.stl) · [ready 3MF](captive_magnet_slice_audit/slices/floor_stand_A_lx521_top_addonA_4of4_shoulder_bottom_right/ready/ready_to_print.gcode.3mf) | Stock A shoulder — bottom-right, 4 of 4 | 1 |
| [`lx521_top_addonB1_1of2_wing_left.stl`](../floor_stand/stl/lx521_top_addonB1_1of2_wing_left.stl) · [ready 3MF](captive_magnet_slice_audit/slices/floor_stand_B1_lx521_top_addonB1_1of2_wing_left/ready/ready_to_print.gcode.3mf) | Stock B1 wing — left, 1 of 2 | 2 |
| [`lx521_top_addonB1_2of2_wing_right.stl`](../floor_stand/stl/lx521_top_addonB1_2of2_wing_right.stl) · [ready 3MF](captive_magnet_slice_audit/slices/floor_stand_B1_lx521_top_addonB1_2of2_wing_right/ready/ready_to_print.gcode.3mf) | Stock B1 wing — right, 2 of 2 | 2 |
| [`lx521_top_base_4of4_vase_b2.stl`](../floor_stand/stl/lx521_top_base_4of4_vase_b2.stl) · [ready 3MF](captive_magnet_slice_audit/slices/floor_stand_B2_lx521_top_base_4of4_vase_b2/ready/ready_to_print.gcode.3mf) | Stock B2 vase/top, 4 of 4 | 4 |
| [`lx521_top_obiwan_optional_lm_keyed_1of2_bottom.stl`](../floor_stand/stl/lx521_top_obiwan_optional_lm_keyed_1of2_bottom.stl) · [ready 3MF](captive_magnet_slice_audit/slices/floor_stand_Obi-Wan-split_lx521_top_obiwan_optional_lm_keyed_1of2_bottom/ready/ready_to_print.gcode.3mf) | Obi-Wan keyed LM bottom — LM-lower pair, integral floor state | 2 |
| [`lx521_top_obiwan_optional_lm_keyed_2of2_top.stl`](../floor_stand/stl/lx521_top_obiwan_optional_lm_keyed_2of2_top.stl) · [ready 3MF](captive_magnet_slice_audit/slices/floor_stand_Obi-Wan-split_lx521_top_obiwan_optional_lm_keyed_2of2_top/ready/ready_to_print.gcode.3mf) | Obi-Wan keyed LM top — LM-upper pair | 2 |
| [`lx521_top_obiwan_core_1of2_lm_carrier.stl`](../floor_stand/stl/lx521_top_obiwan_core_1of2_lm_carrier.stl) · **no direct P2S 3MF; use the two keyed LM projects above** | Obi-Wan LM monolith/core, P2S-oversize; exact split-proxy coverage | 4 |
| [`lx521_top_obiwan_core_2of2_um_carrier.stl`](../floor_stand/stl/lx521_top_obiwan_core_2of2_um_carrier.stl) · [ready 3MF](captive_magnet_slice_audit/slices/floor_stand_Obi-Wan_lx521_top_obiwan_core_2of2_um_carrier/ready/ready_to_print.gcode.3mf) | Obi-Wan UM carrier/core, 2 of 2 | 2 |
| [`lx521_top_v1addonA_shoulder_bottom_left.stl`](../floor_stand/stl/lx521_top_v1addonA_shoulder_bottom_left.stl) · [ready 3MF](captive_magnet_slice_audit/slices/floor_stand_V1-A_lx521_top_v1addonA_shoulder_bottom_left/ready/ready_to_print.gcode.3mf) | Slim V1 A shoulder — bottom-left | 1 |
| [`lx521_top_v1addonA_shoulder_bottom_right.stl`](../floor_stand/stl/lx521_top_v1addonA_shoulder_bottom_right.stl) · [ready 3MF](captive_magnet_slice_audit/slices/floor_stand_V1-A_lx521_top_v1addonA_shoulder_bottom_right/ready/ready_to_print.gcode.3mf) | Slim V1 A shoulder — bottom-right | 1 |
| [`lx521_top_v1addonA_shoulder_top_left.stl`](../floor_stand/stl/lx521_top_v1addonA_shoulder_top_left.stl) · [ready 3MF](captive_magnet_slice_audit/slices/floor_stand_V1-A_lx521_top_v1addonA_shoulder_top_left/ready/ready_to_print.gcode.3mf) | Slim V1 A shoulder — top-left | 1 |
| [`lx521_top_v1addonA_shoulder_top_right.stl`](../floor_stand/stl/lx521_top_v1addonA_shoulder_top_right.stl) · [ready 3MF](captive_magnet_slice_audit/slices/floor_stand_V1-A_lx521_top_v1addonA_shoulder_top_right/ready/ready_to_print.gcode.3mf) | Slim V1 A shoulder — top-right | 1 |
| [`lx521_top_v1addonB1_wing_left.stl`](../floor_stand/stl/lx521_top_v1addonB1_wing_left.stl) · [ready 3MF](captive_magnet_slice_audit/slices/floor_stand_V1-B1_lx521_top_v1addonB1_wing_left/ready/ready_to_print.gcode.3mf) | Slim V1 B1 wing — left | 2 |
| [`lx521_top_v1addonB1_wing_right.stl`](../floor_stand/stl/lx521_top_v1addonB1_wing_right.stl) · [ready 3MF](captive_magnet_slice_audit/slices/floor_stand_V1-B1_lx521_top_v1addonB1_wing_right/ready/ready_to_print.gcode.3mf) | Slim V1 B1 wing — right | 2 |
| [`lx521_top_v1l_4of4_vase_b2.stl`](../floor_stand/stl/lx521_top_v1l_4of4_vase_b2.stl) · [ready 3MF](captive_magnet_slice_audit/slices/floor_stand_V1L_lx521_top_v1l_4of4_vase_b2/ready/ready_to_print.gcode.3mf) | V1L full-slim-set vase/top, 4 of 4 | 4 |
| [`lx521_coupon_1_fit_plate.stl`](../floor_stand/stl/lx521_coupon_1_fit_plate.stl) · [ready 3MF](captive_magnet_slice_audit/slices/floor_stand_coupon1_lx521_coupon_1_fit_plate/ready/ready_to_print.gcode.3mf) | Captive-magnet fit plate, coupon 1 | 1 |

## No floor stand

| STL / directly loadable Bambu project | Descriptive piece | Magnets |
|---|---|---:|
| [`lx521_top_addonA_1of4_shoulder_top_left.stl`](../no_floor_stand/stl/lx521_top_addonA_1of4_shoulder_top_left.stl) · [ready 3MF](captive_magnet_slice_audit/slices/no_floor_stand_A_lx521_top_addonA_1of4_shoulder_top_left/ready/ready_to_print.gcode.3mf) | Stock A shoulder — top-left, 1 of 4 | 1 |
| [`lx521_top_addonA_2of4_shoulder_top_right.stl`](../no_floor_stand/stl/lx521_top_addonA_2of4_shoulder_top_right.stl) · [ready 3MF](captive_magnet_slice_audit/slices/no_floor_stand_A_lx521_top_addonA_2of4_shoulder_top_right/ready/ready_to_print.gcode.3mf) | Stock A shoulder — top-right, 2 of 4 | 1 |
| [`lx521_top_addonA_3of4_shoulder_bottom_left.stl`](../no_floor_stand/stl/lx521_top_addonA_3of4_shoulder_bottom_left.stl) · [ready 3MF](captive_magnet_slice_audit/slices/no_floor_stand_A_lx521_top_addonA_3of4_shoulder_bottom_left/ready/ready_to_print.gcode.3mf) | Stock A shoulder — bottom-left, 3 of 4 | 1 |
| [`lx521_top_addonA_4of4_shoulder_bottom_right.stl`](../no_floor_stand/stl/lx521_top_addonA_4of4_shoulder_bottom_right.stl) · [ready 3MF](captive_magnet_slice_audit/slices/no_floor_stand_A_lx521_top_addonA_4of4_shoulder_bottom_right/ready/ready_to_print.gcode.3mf) | Stock A shoulder — bottom-right, 4 of 4 | 1 |
| [`lx521_top_addonB1_1of2_wing_left.stl`](../no_floor_stand/stl/lx521_top_addonB1_1of2_wing_left.stl) · [ready 3MF](captive_magnet_slice_audit/slices/no_floor_stand_B1_lx521_top_addonB1_1of2_wing_left/ready/ready_to_print.gcode.3mf) | Stock B1 wing — left, 1 of 2 | 2 |
| [`lx521_top_addonB1_2of2_wing_right.stl`](../no_floor_stand/stl/lx521_top_addonB1_2of2_wing_right.stl) · [ready 3MF](captive_magnet_slice_audit/slices/no_floor_stand_B1_lx521_top_addonB1_2of2_wing_right/ready/ready_to_print.gcode.3mf) | Stock B1 wing — right, 2 of 2 | 2 |
| [`lx521_top_base_4of4_vase_b2.stl`](../no_floor_stand/stl/lx521_top_base_4of4_vase_b2.stl) · [ready 3MF](captive_magnet_slice_audit/slices/no_floor_stand_B2_lx521_top_base_4of4_vase_b2/ready/ready_to_print.gcode.3mf) | Stock B2 vase/top, 4 of 4 | 4 |
| [`lx521_top_obiwan_optional_lm_keyed_1of2_bottom.stl`](../no_floor_stand/stl/lx521_top_obiwan_optional_lm_keyed_1of2_bottom.stl) · [ready 3MF](captive_magnet_slice_audit/slices/no_floor_stand_Obi-Wan-split_lx521_top_obiwan_optional_lm_keyed_1of2_bottom/ready/ready_to_print.gcode.3mf) | Obi-Wan keyed LM bottom — LM-lower pair, no-floor bridge state | 2 |
| [`lx521_top_obiwan_optional_lm_keyed_2of2_top.stl`](../no_floor_stand/stl/lx521_top_obiwan_optional_lm_keyed_2of2_top.stl) · [ready 3MF](captive_magnet_slice_audit/slices/no_floor_stand_Obi-Wan-split_lx521_top_obiwan_optional_lm_keyed_2of2_top/ready/ready_to_print.gcode.3mf) | Obi-Wan keyed LM top — LM-upper pair | 2 |
| [`lx521_top_obiwan_core_1of2_lm_carrier.stl`](../no_floor_stand/stl/lx521_top_obiwan_core_1of2_lm_carrier.stl) · **no direct P2S 3MF; use the two keyed LM projects above** | Obi-Wan LM monolith/core, P2S-oversize; exact split-proxy coverage | 4 |
| [`lx521_top_obiwan_core_2of2_um_carrier.stl`](../no_floor_stand/stl/lx521_top_obiwan_core_2of2_um_carrier.stl) · [ready 3MF](captive_magnet_slice_audit/slices/no_floor_stand_Obi-Wan_lx521_top_obiwan_core_2of2_um_carrier/ready/ready_to_print.gcode.3mf) | Obi-Wan UM carrier/core, 2 of 2 | 2 |
| [`lx521_top_v1addonA_shoulder_bottom_left.stl`](../no_floor_stand/stl/lx521_top_v1addonA_shoulder_bottom_left.stl) · [ready 3MF](captive_magnet_slice_audit/slices/no_floor_stand_V1-A_lx521_top_v1addonA_shoulder_bottom_left/ready/ready_to_print.gcode.3mf) | Slim V1 A shoulder — bottom-left | 1 |
| [`lx521_top_v1addonA_shoulder_bottom_right.stl`](../no_floor_stand/stl/lx521_top_v1addonA_shoulder_bottom_right.stl) · [ready 3MF](captive_magnet_slice_audit/slices/no_floor_stand_V1-A_lx521_top_v1addonA_shoulder_bottom_right/ready/ready_to_print.gcode.3mf) | Slim V1 A shoulder — bottom-right | 1 |
| [`lx521_top_v1addonA_shoulder_top_left.stl`](../no_floor_stand/stl/lx521_top_v1addonA_shoulder_top_left.stl) · [ready 3MF](captive_magnet_slice_audit/slices/no_floor_stand_V1-A_lx521_top_v1addonA_shoulder_top_left/ready/ready_to_print.gcode.3mf) | Slim V1 A shoulder — top-left | 1 |
| [`lx521_top_v1addonA_shoulder_top_right.stl`](../no_floor_stand/stl/lx521_top_v1addonA_shoulder_top_right.stl) · [ready 3MF](captive_magnet_slice_audit/slices/no_floor_stand_V1-A_lx521_top_v1addonA_shoulder_top_right/ready/ready_to_print.gcode.3mf) | Slim V1 A shoulder — top-right | 1 |
| [`lx521_top_v1addonB1_wing_left.stl`](../no_floor_stand/stl/lx521_top_v1addonB1_wing_left.stl) · [ready 3MF](captive_magnet_slice_audit/slices/no_floor_stand_V1-B1_lx521_top_v1addonB1_wing_left/ready/ready_to_print.gcode.3mf) | Slim V1 B1 wing — left | 2 |
| [`lx521_top_v1addonB1_wing_right.stl`](../no_floor_stand/stl/lx521_top_v1addonB1_wing_right.stl) · [ready 3MF](captive_magnet_slice_audit/slices/no_floor_stand_V1-B1_lx521_top_v1addonB1_wing_right/ready/ready_to_print.gcode.3mf) | Slim V1 B1 wing — right | 2 |
| [`lx521_top_v1l_4of4_vase_b2.stl`](../no_floor_stand/stl/lx521_top_v1l_4of4_vase_b2.stl) · [ready 3MF](captive_magnet_slice_audit/slices/no_floor_stand_V1L_lx521_top_v1l_4of4_vase_b2/ready/ready_to_print.gcode.3mf) | V1L full-slim-set vase/top, 4 of 4 | 4 |
| [`lx521_coupon_1_fit_plate.stl`](../no_floor_stand/stl/lx521_coupon_1_fit_plate.stl) · [ready 3MF](captive_magnet_slice_audit/slices/no_floor_stand_coupon1_lx521_coupon_1_fit_plate/ready/ready_to_print.gcode.3mf) | Captive-magnet fit plate, coupon 1 | 1 |

## Shared Obi-Wan wings

| STL / directly loadable Bambu project | Descriptive piece | Magnets |
|---|---|---:|
| [`lx521_top_obiwan_wing_ac_left_1of3_lm_lower.stl`](../wings/ac/stl/lx521_top_obiwan_wing_ac_left_1of3_lm_lower.stl) · [ready 3MF](captive_magnet_slice_audit/slices/shared_Obi-Wan-Ac_obiwan_wing_ac_left_1of3_lm_lower/ready/ready_to_print.gcode.3mf) | Obi-Wan Ac wing — left LM-lower segment, 1 of 3 | 1 |
| [`lx521_top_obiwan_wing_ac_left_2of3_lm_upper.stl`](../wings/ac/stl/lx521_top_obiwan_wing_ac_left_2of3_lm_upper.stl) · [ready 3MF](captive_magnet_slice_audit/slices/shared_Obi-Wan-Ac_obiwan_wing_ac_left_2of3_lm_upper/ready/ready_to_print.gcode.3mf) | Obi-Wan Ac wing — left LM-upper segment, 2 of 3 | 1 |
| [`lx521_top_obiwan_wing_ac_left_3of3_um.stl`](../wings/ac/stl/lx521_top_obiwan_wing_ac_left_3of3_um.stl) · [ready 3MF](captive_magnet_slice_audit/slices/shared_Obi-Wan-Ac_obiwan_wing_ac_left_3of3_um/ready/ready_to_print.gcode.3mf) | Obi-Wan Ac wing — left UM segment, 3 of 3 | 1 |
| [`lx521_top_obiwan_wing_ac_left_b_1of2_lm_lower.stl`](../wings/ac/stl/lx521_top_obiwan_wing_ac_left_b_1of2_lm_lower.stl) · [ready 3MF](captive_magnet_slice_audit/slices/shared_Obi-Wan-Ac_obiwan_wing_ac_left_b_1of2_lm_lower/ready/ready_to_print.gcode.3mf) | Obi-Wan Ac wing B — left LM-lower segment, 1 of 2 | 1 |
| [`lx521_top_obiwan_wing_ac_left_b_2of2_lm_um_upper.stl`](../wings/ac/stl/lx521_top_obiwan_wing_ac_left_b_2of2_lm_um_upper.stl) · [ready 3MF](captive_magnet_slice_audit/slices/shared_Obi-Wan-Ac_obiwan_wing_ac_left_b_2of2_lm_um_upper/ready/ready_to_print.gcode.3mf) | Obi-Wan Ac wing B — left fused LM/UM upper, 2 of 2 | 2 |
| [`lx521_top_obiwan_wing_ac_right_1of3_lm_lower.stl`](../wings/ac/stl/lx521_top_obiwan_wing_ac_right_1of3_lm_lower.stl) · [ready 3MF](captive_magnet_slice_audit/slices/shared_Obi-Wan-Ac_obiwan_wing_ac_right_1of3_lm_lower/ready/ready_to_print.gcode.3mf) | Obi-Wan Ac wing — right LM-lower segment, 1 of 3 | 1 |
| [`lx521_top_obiwan_wing_ac_right_2of3_lm_upper.stl`](../wings/ac/stl/lx521_top_obiwan_wing_ac_right_2of3_lm_upper.stl) · [ready 3MF](captive_magnet_slice_audit/slices/shared_Obi-Wan-Ac_obiwan_wing_ac_right_2of3_lm_upper/ready/ready_to_print.gcode.3mf) | Obi-Wan Ac wing — right LM-upper segment, 2 of 3 | 1 |
| [`lx521_top_obiwan_wing_ac_right_3of3_um.stl`](../wings/ac/stl/lx521_top_obiwan_wing_ac_right_3of3_um.stl) · [ready 3MF](captive_magnet_slice_audit/slices/shared_Obi-Wan-Ac_obiwan_wing_ac_right_3of3_um/ready/ready_to_print.gcode.3mf) | Obi-Wan Ac wing — right UM segment, 3 of 3 | 1 |
| [`lx521_top_obiwan_wing_ac_right_b_1of2_lm_lower.stl`](../wings/ac/stl/lx521_top_obiwan_wing_ac_right_b_1of2_lm_lower.stl) · [ready 3MF](captive_magnet_slice_audit/slices/shared_Obi-Wan-Ac_obiwan_wing_ac_right_b_1of2_lm_lower/ready/ready_to_print.gcode.3mf) | Obi-Wan Ac wing B — right LM-lower segment, 1 of 2 | 1 |
| [`lx521_top_obiwan_wing_ac_right_b_2of2_lm_um_upper.stl`](../wings/ac/stl/lx521_top_obiwan_wing_ac_right_b_2of2_lm_um_upper.stl) · [ready 3MF](captive_magnet_slice_audit/slices/shared_Obi-Wan-Ac_obiwan_wing_ac_right_b_2of2_lm_um_upper/ready/ready_to_print.gcode.3mf) | Obi-Wan Ac wing B — right fused LM/UM upper, 2 of 2 | 2 |
| [`lx521_top_obiwan_wing_ae_left_1of3_lm_lower.stl`](../wings/ae/stl/lx521_top_obiwan_wing_ae_left_1of3_lm_lower.stl) · [ready 3MF](captive_magnet_slice_audit/slices/shared_Obi-Wan-Ae_obiwan_wing_ae_left_1of3_lm_lower/ready/ready_to_print.gcode.3mf) | Obi-Wan Ae wing — left LM-lower segment, 1 of 3 | 1 |
| [`lx521_top_obiwan_wing_ae_left_2of3_lm_upper.stl`](../wings/ae/stl/lx521_top_obiwan_wing_ae_left_2of3_lm_upper.stl) · [ready 3MF](captive_magnet_slice_audit/slices/shared_Obi-Wan-Ae_obiwan_wing_ae_left_2of3_lm_upper/ready/ready_to_print.gcode.3mf) | Obi-Wan Ae wing — left LM-upper segment, 2 of 3 | 1 |
| [`lx521_top_obiwan_wing_ae_left_3of3_um.stl`](../wings/ae/stl/lx521_top_obiwan_wing_ae_left_3of3_um.stl) · [ready 3MF](captive_magnet_slice_audit/slices/shared_Obi-Wan-Ae_obiwan_wing_ae_left_3of3_um/ready/ready_to_print.gcode.3mf) | Obi-Wan Ae wing — left UM segment, 3 of 3 | 1 |
| [`lx521_top_obiwan_wing_ae_left_b_1of2_lm_lower.stl`](../wings/ae/stl/lx521_top_obiwan_wing_ae_left_b_1of2_lm_lower.stl) · [ready 3MF](captive_magnet_slice_audit/slices/shared_Obi-Wan-Ae_obiwan_wing_ae_left_b_1of2_lm_lower/ready/ready_to_print.gcode.3mf) | Obi-Wan Ae wing B — left LM-lower segment, 1 of 2 | 1 |
| [`lx521_top_obiwan_wing_ae_left_b_2of2_lm_um_upper.stl`](../wings/ae/stl/lx521_top_obiwan_wing_ae_left_b_2of2_lm_um_upper.stl) · [ready 3MF](captive_magnet_slice_audit/slices/shared_Obi-Wan-Ae_obiwan_wing_ae_left_b_2of2_lm_um_upper/ready/ready_to_print.gcode.3mf) | Obi-Wan Ae wing B — left fused LM/UM upper, 2 of 2 | 2 |
| [`lx521_top_obiwan_wing_ae_right_1of3_lm_lower.stl`](../wings/ae/stl/lx521_top_obiwan_wing_ae_right_1of3_lm_lower.stl) · [ready 3MF](captive_magnet_slice_audit/slices/shared_Obi-Wan-Ae_obiwan_wing_ae_right_1of3_lm_lower/ready/ready_to_print.gcode.3mf) | Obi-Wan Ae wing — right LM-lower segment, 1 of 3 | 1 |
| [`lx521_top_obiwan_wing_ae_right_2of3_lm_upper.stl`](../wings/ae/stl/lx521_top_obiwan_wing_ae_right_2of3_lm_upper.stl) · [ready 3MF](captive_magnet_slice_audit/slices/shared_Obi-Wan-Ae_obiwan_wing_ae_right_2of3_lm_upper/ready/ready_to_print.gcode.3mf) | Obi-Wan Ae wing — right LM-upper segment, 2 of 3 | 1 |
| [`lx521_top_obiwan_wing_ae_right_3of3_um.stl`](../wings/ae/stl/lx521_top_obiwan_wing_ae_right_3of3_um.stl) · [ready 3MF](captive_magnet_slice_audit/slices/shared_Obi-Wan-Ae_obiwan_wing_ae_right_3of3_um/ready/ready_to_print.gcode.3mf) | Obi-Wan Ae wing — right UM segment, 3 of 3 | 1 |
| [`lx521_top_obiwan_wing_ae_right_b_1of2_lm_lower.stl`](../wings/ae/stl/lx521_top_obiwan_wing_ae_right_b_1of2_lm_lower.stl) · [ready 3MF](captive_magnet_slice_audit/slices/shared_Obi-Wan-Ae_obiwan_wing_ae_right_b_1of2_lm_lower/ready/ready_to_print.gcode.3mf) | Obi-Wan Ae wing B — right LM-lower segment, 1 of 2 | 1 |
| [`lx521_top_obiwan_wing_ae_right_b_2of2_lm_um_upper.stl`](../wings/ae/stl/lx521_top_obiwan_wing_ae_right_b_2of2_lm_um_upper.stl) · [ready 3MF](captive_magnet_slice_audit/slices/shared_Obi-Wan-Ae_obiwan_wing_ae_right_b_2of2_lm_um_upper/ready/ready_to_print.gcode.3mf) | Obi-Wan Ae wing B — right fused LM/UM upper, 2 of 2 | 2 |

## Count reconciliation

| Scope | Catalog artifacts | Catalog magnet stations | Direct ready projects | Direct insertions |
|---|---:|---:|---:|---:|
| Floor stand | 19 | 35 | 18 | 31 |
| No floor stand | 19 | 35 | 18 | 31 |
| Shared wings | 20 | 24 | 20 | 24 |
| **Total** | **58** | **94** | **56** | **86** |

All 86 directly sliced insertions are transverse sites. The remaining eight
catalog stations are the two four-magnet Obi-Wan
LM monoliths; they duplicate the exact keyed-half cavities for audit coverage
and have no P2S project. Floor/no-floor, Ac/Ae, and monolith/keyed split are
alternative choices, so 94 is an audit-inventory count rather than a bill of
materials. A physical Obi-Wan build using either LM form and one wing family
uses 12 magnets: six in the carrier and six in the wing receivers.

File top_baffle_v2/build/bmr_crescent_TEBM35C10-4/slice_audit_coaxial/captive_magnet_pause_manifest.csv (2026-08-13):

artifact_id | state | variant | part | print_orientation | group | sites | magnet_count | last_completely_open_layer_z_mm | cavity_bury_roof_start_plane_z_mm | first_closing_layer_z_mm | pause_marker_z_mm | minimum_seated_below_last_open_layer_mm | minimum_seated_below_first_closing_layer_mm | print_insertion_direction_xyz | insertion_instruction | stl | stl_sha256 | gcode | gcode_sha256 | audited_bambu_3mf | audited_bambu_3mf_sha256 | ready_project | ready_project_output_fingerprint | discovery_gcode | discovery_gcode_sha256 | discovery_bambu_3mf | discovery_bambu_3mf_sha256 | bambu_arrange_rz_degrees | polarity
shared:Obiwan-TEBM35C10-4-BMR-crescent:obiwan_bmr_crescent_TEBM35C10-4 | shared | Obiwan-TEBM35C10-4-BMR-crescent | obiwan_bmr_crescent_TEBM35C10-4 | front_face_down | 1 | tebm_front_left_base; tebm_front_right_base | 2 | 5.8 | 5.80 | 5.96 | 5.96 | 0.09999990000004733 | 0.25999990000004747 | [0.0,0.0,-1.0] | insert vertically downward from above the paused part (+Z side) through the open loading chimney along print -Z | /Users/antor/gh/lx/top_baffle_v2/build/bmr_crescent_TEBM35C10-4/obiwan_bmr_crescent_TEBM35C10-4.stl | 18ef6af2177b370238b49462ef77cf17faf0c55cf3cedf694e1681f2bb9b8d09 | /Users/antor/gh/lx/top_baffle_v2/build/bmr_crescent_TEBM35C10-4/slice_audit_coaxial/slices/shared_Obiwan-TEBM35C10-4-BMR-crescent_obiwan_bmr_crescent_TEBM35C10-4/ready/plate_1.gcode | 8b4ff38854e93fb8ecda76fd061ec24aa5a8546e68db7bf582e88e4342b8f90a | /Users/antor/gh/lx/top_baffle_v2/build/bmr_crescent_TEBM35C10-4/slice_audit_coaxial/slices/shared_Obiwan-TEBM35C10-4-BMR-crescent_obiwan_bmr_crescent_TEBM35C10-4/ready/ready_to_print.gcode.3mf | 1dd0e012b292f7af7a64b1bc720a5ce36610672bd9dddd95b8768e0e246c6cdb | True | 56b031462a3a4940632623f6143b1ef37d15b20fd94e130fac5ea46c45d4a5ec | /Users/antor/gh/lx/top_baffle_v2/build/bmr_crescent_TEBM35C10-4/slice_audit_coaxial/slices/shared_Obiwan-TEBM35C10-4-BMR-crescent_obiwan_bmr_crescent_TEBM35C10-4/plate_1.gcode | 58ebf9d05d939a55ea14be44346b2e8ac89862f87a252700d8e649c65d5d6d48 | /Users/antor/gh/lx/top_baffle_v2/build/bmr_crescent_TEBM35C10-4/slice_audit_coaxial/slices/shared_Obiwan-TEBM35C10-4-BMR-crescent_obiwan_bmr_crescent_TEBM35C10-4/audited_slice_project.3mf | be86408c4f0e6036dcdf5646e394da14a96c1ab827e15c2cd8a09e2f879d087c | 0.0 | [{"site":"tebm_front_left_base","print_marked_pole_axis_xyz":[-1.0,0.0,0.0],"installed_marked_pole_axis_xyz":[-1.0,0.0,0.0],"instruction":"marked/N pole points OUT from the pod along installed_marked_pole_axis_xyz; verify the future mating piece uses the opposite interface-facing pole before burial"},{"site":"tebm_front_right_base","print_marked_pole_axis_xyz":[1.0,0.0,0.0],"installed_marked_pole_axis_xyz":[1.0,0.0,0.0],"instruction":"marked/N pole points OUT from the pod along installed_marked_pole_axis_xyz; verify the future mating piece uses the opposite interface-facing pole before burial"}]

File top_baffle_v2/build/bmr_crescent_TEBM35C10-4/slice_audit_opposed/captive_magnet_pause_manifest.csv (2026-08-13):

artifact_id | state | variant | part | print_orientation | group | sites | magnet_count | last_completely_open_layer_z_mm | cavity_bury_roof_start_plane_z_mm | first_closing_layer_z_mm | pause_marker_z_mm | minimum_seated_below_last_open_layer_mm | minimum_seated_below_first_closing_layer_mm | print_insertion_direction_xyz | insertion_instruction | stl | stl_sha256 | gcode | gcode_sha256 | audited_bambu_3mf | audited_bambu_3mf_sha256 | ready_project | ready_project_output_fingerprint | discovery_gcode | discovery_gcode_sha256 | discovery_bambu_3mf | discovery_bambu_3mf_sha256 | bambu_arrange_rz_degrees | polarity
shared:Obiwan-TEBM35C10-4-BMR-crescent-opposed:obiwan_bmr_crescent_opposed_TEBM35C10-4 | shared | Obiwan-TEBM35C10-4-BMR-crescent-opposed | obiwan_bmr_crescent_opposed_TEBM35C10-4 | front_face_down | 1 | tebm_lower_left_base; tebm_lower_right_base; tebm_upper_left_base; tebm_upper_right_base | 4 | 5.8 | 5.80 | 5.96 | 5.96 | 0.09999990000005088 | 0.259999900000051 | [0.0,0.0,-1.0] | insert vertically downward from above the paused part (+Z side) through the open loading chimney along print -Z | /Users/antor/gh/lx/top_baffle_v2/build/bmr_crescent_TEBM35C10-4/obiwan_bmr_crescent_opposed_TEBM35C10-4.stl | 617bafd03e36d0db1e2f905303b45b3f16615ea16e075ddcb8dc4d40aed5ae65 | /Users/antor/gh/lx/top_baffle_v2/build/bmr_crescent_TEBM35C10-4/slice_audit_opposed/slices/shared_Obiwan-TEBM35C10-4-BMR-crescent-opposed_obiwan_bmr_crescent_opposed_TEBM35C10-4/ready/plate_1.gcode | ccbcb9432b293b1e0e190a6f21abbb5cf22e2a217b775c5b7412cc30c3e6ef4d | /Users/antor/gh/lx/top_baffle_v2/build/bmr_crescent_TEBM35C10-4/slice_audit_opposed/slices/shared_Obiwan-TEBM35C10-4-BMR-crescent-opposed_obiwan_bmr_crescent_opposed_TEBM35C10-4/ready/ready_to_print.gcode.3mf | d75b97f918d934deb68f1cb9454ff7aef40ce78c911e6b5ca21f76574c3d3b41 | True | ed8ac4fe4a1bba8082fc15a86b2276c41ed0960c786e2773f1f0c5f948dd5202 | /Users/antor/gh/lx/top_baffle_v2/build/bmr_crescent_TEBM35C10-4/slice_audit_opposed/slices/shared_Obiwan-TEBM35C10-4-BMR-crescent-opposed_obiwan_bmr_crescent_opposed_TEBM35C10-4/plate_1.gcode | 1533467c12bfa1900ecf82f5ec0e2e173f19dd3db8759fe52f0965dcba74c1ce | /Users/antor/gh/lx/top_baffle_v2/build/bmr_crescent_TEBM35C10-4/slice_audit_opposed/slices/shared_Obiwan-TEBM35C10-4-BMR-crescent-opposed_obiwan_bmr_crescent_opposed_TEBM35C10-4/audited_slice_project.3mf | 3ae1d8aaef2dd0e741ca9a2951a4a58ad03bbdaff90768e716eb17b746465a8d | 0.0 | [{"site":"tebm_lower_left_base","print_marked_pole_axis_xyz":[-1.0,0.0,0.0],"installed_marked_pole_axis_xyz":[-1.0,0.0,0.0],"instruction":"marked/N pole points OUT from the pod along installed_marked_pole_axis_xyz; verify the future mating piece uses the opposite interface-facing pole before burial"},{"site":"tebm_lower_right_base","print_marked_pole_axis_xyz":[1.0,0.0,0.0],"installed_marked_pole_axis_xyz":[1.0,0.0,0.0],"instruction":"marked/N pole points OUT from the pod along installed_marked_pole_axis_xyz; verify the future mating piece uses the opposite interface-facing pole before burial"},{"site":"tebm_upper_left_base","print_marked_pole_axis_xyz":[-1.0,0.0,0.0],"installed_marked_pole_axis_xyz":[-1.0,0.0,0.0],"instruction":"marked/N pole points OUT from the pod along installed_marked_pole_axis_xyz; verify the future mating piece uses the opposite interface-facing pole before burial"},{"site":"tebm_upper_right_base","print_marked_pole_axis_xyz":[1.0,0.0,0.0],"installed_marked_pole_axis_xyz":[1.0,0.0,0.0],"instruction":"marked/N pole points OUT from the pod along installed_marked_pole_axis_xyz; verify the future mating piece uses the opposite interface-facing pole before burial"}]

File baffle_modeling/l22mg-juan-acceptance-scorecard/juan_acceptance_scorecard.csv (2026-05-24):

criterion | status | blocks_acceptance | evidence
overall_acceptance | fail | yes | Selected artifact `compact2-h32-h21-h28-h18-targetavg7-meshtarget-conv-smoke` from `output/l22mg-bem-juan-top-h1659-modal-compact2-solid-passive-h32-h21-h28-h18-q7near-targetavg7-meshtarget-conv-smoke`; normalized polar RMS 3.920 dB over 300-1200 Hz.
target_provenance | pass | no | HDF5 `output/data/polar_data_juan_lx521_top_raw.h5`, driver `L22MG (LX521 top raw)`, hypothesis `juan_baffleless_to_juan_top_baffle_l22mg_raw`.
measurement_geometry | pass | no | Juan source radius 0.500 m; target distance 0.500 m; mic reference `l22`, horizontal radius 0.500 m, z offset 0.000 mm.
angle_grid | pass | no | Policy `target_hdf5_angles`; model angles [0, 15, 30, 45, 60, 75, 90]; target angles [0, 15, 30, 45, 60, 75, 90]; interpolation used `False`.
validation_alignment_policy | pass | no | Gain 1.362 dB and delay 0.000 ms; scalar gain count 1, delay count 1, angle-dependent gain count 0, band-specific gain count 0, rear/source level corrections 0.000 / 0.000 dB. exactly one global scalar gain and one global delay are allowed for validation alignment; no angle-dependent, band-specific, rear-level, or source-level dB corrections are applied
coverage | pass | no | Covered band 300.2929915487766-1199.7071272432804 Hz; full coverage `True`.
normalized_polar_shape | fail | yes | All-angle RMS 3.920 dB vs 1.5 dB target; through-60 0.875 dB; through-80 3.491 dB; worst +19.102 dB at 300 Hz / 75 deg.
target_quality_masked_shape_diagnostic | diagnostic_only | no | Diagnostic only, not an acceptance metric: excluding the stored target-polar-quality cluster at 75 deg from 300.293-383.423 Hz removes 228 points and gives all-angle RMS 3.461 dB, through-60 0.875 dB, through-80 2.858 dB; remaining worst +13.956 dB at 384 Hz / 75 deg. Full-data acceptance remains unchanged.
mesh_convergence | fail | yes | Max normalized-polar movement 0.672 dB vs 0.5 dB gate.
mesh_target_wavelength_sizing | pass | no | Reference 1200 Hz; actual broad/boundary/local h = 32.000/21.000/21.000 mm; limits broad lambda/6 47.639 mm and boundary/local lambda/10 28.583 mm. BEM mesh spacing is within the recorded wavelength sizing targets: actual BEM mesh spacing is within lambda/6 broad and lambda/10 boundary/local targets
bem_linear_solver | pass | no | Solver `direct`, max relative residual 1.049e-15.
source_cv | pass | no | Source model id `h1659-modal-compact2-az24-reg1e-06`; Juan-only held-out side-worst 3.298 dB; recommendation `recommended_juan_only`.
source_offplane_generalization | pass | no | not required for acceptance because validation target is on the LM/L22MG height; Andres UM-height off-plane ambiguity remains diagnostic
target_measurement_quality | not_proven | yes | Juan target-null repeatability: Juan measured target has -20.300 dB top-minus-nude transfer at 300.293 Hz / 75 deg; multi-driver top capture is +11.870 dB relative to L22-alone target; this is also the artifact's worst normalized-polar residual; Juan front/rear consistency: Juan measured front-minus-rear baffle-transfer delta is -21.300 dB at 300.293 Hz / 75 deg; front-minus-rear normalized delta is -20.440 dB; multi-driver top capture is +11.870 dB relative to L22-alone front; this is also the artifact's worst normalized-polar residual; target polar quality: measured target has -29.894 dB normalized null at 300.293 Hz / 75 deg; cluster width 83.1 Hz; adjacent-angle contrast 17.315 dB; same-angle local contrast -0.589 dB; this is also the artifact's worst normalized-polar residual
target_null_repeatability | warning | yes | Juan measured target has -20.300 dB top-minus-nude transfer at 300.293 Hz / 75 deg; multi-driver top capture is +11.870 dB relative to L22-alone target; this is also the artifact's worst normalized-polar residual
target_front_rear_consistency | warning | yes | Juan measured front-minus-rear baffle-transfer delta is -21.300 dB at 300.293 Hz / 75 deg; front-minus-rear normalized delta is -20.440 dB; multi-driver top capture is +11.870 dB relative to L22-alone front; this is also the artifact's worst normalized-polar residual
target_polar_quality | warning | yes | measured target has -29.894 dB normalized null at 300.293 Hz / 75 deg; cluster width 83.1 Hz; adjacent-angle contrast 17.315 dB; same-angle local contrast -0.589 dB; this is also the artifact's worst normalized-polar residual
passive_geometry | not_proven | yes | Juan L22MG top-baffle target is L22-only; the validation target HDF5 records `passive_state_status=unused_um_tweeter_state_unrecorded` and `passive_state_acceptance_use=current_l22_target_but_passive_geometry_not_proven`, which is an explicit unknown, not evidence for open holes, covered patches, or mounted inactive drivers. See `docs/l22mg-juan-top-passive-state-audit/README.md` and diagnostic sensitivity `docs/l22mg-juan-top-passive-state-band-sensitivity/README.md`
driver_stl_geometry_provenance | pass | no | STL `linkwitz/H1659-08_U22REX_P-SL_driver.stl` status `present`; OD 221.000 mm, depth 90.600 mm, front proud height 0.600 mm, rear depth 90.000 mm, flange overlap past L22 cutout radius 15.500 mm. STL dimensions are recorded for provenance of H1659-derived face/frame/source geometry; recording these dimensions is not a raw-STL solve, feature-preserving remesh, or acceptance proof
audit_outputs | pass | no | Contour plot present `True`; decomposition CSV `pass`; HDF5 group `pass`.
width_sweep_status | qualitative_only | no | Width sweep CSV `output/l22mg-bem-juan-top-h1659-modal-compact2-solid-passive-h32-h21-h28-h18-q7near-targetavg7-meshtarget-conv-smoke/width_sweep_metrics.csv`; interpretation: The 305 mm baseline did not pass all current validation gates, so this width sweep is diagnostic only and cannot be read as accepted LX521 width behavior. Required widths present `False`; widths 305; missing required widths `205,405`. Baseline 305 mm 300-1200 metrics: F90-F0 -18.108 dB, DI 5.590 dB, beamwidth 112.410 deg, sensitivity 75.047 dB, rear/front symmetry 1.540 dB. Separate qualitative width-sweep deliverable `output/l22mg-bem-juan-top-h1659-modal-compact2-current-width-sweep-h42-h28-q7near-targetavg7` reports widths 205,255,305,355,405 mm; required 205/305/405 present `True`; recommended 205/255/305/355/405 present `True`; current-radius evidence `True`; deliverable status `qualitative_only`; 305 mm all-angle RMS 4.214 dB. This separate sweep remains qualitative and does not change the selected artifact acceptance status.

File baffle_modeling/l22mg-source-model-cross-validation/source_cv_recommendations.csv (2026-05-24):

rank | model_id | source_model | rear_phase_mode | recommendation_status | recommendation_reason | cv_side_worst_fold_rms_db_300_1200 | in_sample_side_worst_norm_rms_db_300_1200 | in_sample_side_worst_abs_rms_db_300_1200 | in_sample_side_worst_phase_rms_deg_300_1200 | fit_front_norm_rms_db_300_1200 | fit_rear_norm_rms_db_300_1200 | fit_front_rms_db_300_1200 | fit_rear_rms_db_300_1200 | fit_front_phase_rms_deg_300_1200 | fit_rear_phase_rms_deg_300_1200 | failed_fold_count | source_count | basis_count | source_point_profile | half_depth_mm | ring_radii_mm | front_depth_mm | rear_depth_mm | front_ring_radii_mm | rear_ring_radii_mm | regularization | smoothness_regularization | svd_rcond | active_surface_mode_count | active_surface_basis_kind | active_surface_azimuth_count | active_surface_quadrature_order | active_surface_side_gap_mm | active_surface_rear_basket_mode_count
3 | h1659-modal-compact2-az24-reg1e-06 | split-profile-ring | dipole | recommended_juan_only | Passes Juan-only thresholds: failed folds <= 0, in-sample side-worst <= 3.000 dB, in-sample absolute side-worst <= 3.000 dB, in-sample phase side-worst <= 30.000 deg, held-out side-worst <= 4.000 dB. | 3.29837556830052 | 2.6313590599354084 | 2.5779584887807063 | 15.048220136071363 | 2.6313590599354084 | 1.2258531038469413 | 2.5779584887807063 | 0.9744356054264341 | 15.048220136071363 | 13.734357858633057 | 0 | 292 | 4 | h1659-modal-compact-2 |  |  |  |  |  |  | 1e-06 |  |  |  | modal
4 | h1659-modal-full2-az24-reg1e-06 | split-profile-ring | dipole | recommended_juan_only | Passes Juan-only thresholds: failed folds <= 0, in-sample side-worst <= 3.000 dB, in-sample absolute side-worst <= 3.000 dB, in-sample phase side-worst <= 30.000 deg, held-out side-worst <= 4.000 dB. | 3.3001618737677805 | 2.6822386556549738 | 2.628811786383559 | 15.13392272666505 | 2.6822386556549738 | 1.2614326095356279 | 2.628811786383559 | 1.0074197648570797 | 15.13392272666505 | 13.88907671239139 | 0 | 484 | 4 | h1659-modal-full-2 |  |  |  |  |  |  | 1e-06 |  |  |  | modal
6 | h1659-modal-compact3-az24-reg1e-06 | split-profile-ring | dipole | recommended_juan_only | Passes Juan-only thresholds: failed folds <= 0, in-sample side-worst <= 3.000 dB, in-sample absolute side-worst <= 3.000 dB, in-sample phase side-worst <= 30.000 deg, held-out side-worst <= 4.000 dB. | 3.768144015569058 | 2.2148930283780937 | 2.1835432699492974 | 14.029297746176718 | 2.2148930283780937 | 1.1713502189438696 | 2.1835432699492974 | 0.9336087957852311 | 14.029297746176718 | 13.529452509458283 | 0 | 438 | 6 | h1659-modal-compact-3 |  |  |  |  |  |  | 1e-06 |  |  |  | modal
7 | h1659-modal-full4-az24-reg1e-06-svd1e-05 | split-profile-ring | dipole | recommended_juan_only | Passes Juan-only thresholds: failed folds <= 0, in-sample side-worst <= 3.000 dB, in-sample absolute side-worst <= 3.000 dB, in-sample phase side-worst <= 30.000 deg, held-out side-worst <= 4.000 dB. | 3.799651035683976 | 1.050088912320182 | 1.0388725493052466 | 12.998901566223541 | 1.050088912320182 | 0.9523097814704011 | 1.0388725493052466 | 0.8683867136403252 | 12.998901566223541 | 12.920951074479007 | 0 | 968 | 8 | h1659-modal-full-4 |  |  |  |  |  |  | 1e-06 |  | 1e-05 |  | modal
8 | h1659-profile-ring-full-az24-reg1e-06-svd1e-05 | split-profile-ring | dipole | recommended_juan_only | Passes Juan-only thresholds: failed folds <= 0, in-sample side-worst <= 3.000 dB, in-sample absolute side-worst <= 3.000 dB, in-sample phase side-worst <= 30.000 deg, held-out side-worst <= 4.000 dB. | 3.841842676762428 | 1.0905265392069612 | 1.0303709149873315 | 12.298195305203269 | 0.8548204220443274 | 1.0905265392069612 | 0.8452311812700046 | 1.0303709149873315 | 12.297965536672582 | 12.298195305203269 | 0 | 242 | 12 | h1659-acoustic-full |  |  |  |  |  |  | 1e-06 |  | 1e-05 |  | modal
9 | h1659-profile-ring-full-az24-reg1e-06 | split-profile-ring | dipole | recommended_juan_only | Passes Juan-only thresholds: failed folds <= 0, in-sample side-worst <= 3.000 dB, in-sample absolute side-worst <= 3.000 dB, in-sample phase side-worst <= 30.000 deg, held-out side-worst <= 4.000 dB. | 3.8441835762148298 | 1.0902869353140128 | 1.0301010645195778 | 12.297853262050523 | 0.8547934313314776 | 1.0902869353140128 | 0.8452022319404184 | 1.0301010645195778 | 12.297853262050523 | 12.29738702440896 | 0 | 242 | 12 | h1659-acoustic-full |  |  |  |  |  |  | 1e-06 |  |  |  | modal
1 | axisymmetric-directivity-table-front-duplicate | axisymmetric-directivity | dipole | diagnostic_only | Axisymmetric directivity-table propagation is a no-inversion diagnostic; it does not define a unique finite 3D source support for high-fidelity BEM source selection. | 1.2292624299400832 | 0.5687227244669742 | 0.5687227244669747 | 68.0336051416609 | 7.269262770027132e-15 | 0.5687227244669742 | 5.132981030276421e-15 | 0.5687227244669747 | 1.978307069726565e-15 | 68.0336051416609 | 0 | 13 | 13 | measured_axisymmetric_directivity |  |  |  |  |  |  |  |  |  |  | modal
2 | diagnostic-legendre-o8 | legendre | dipole | diagnostic_only | Legendre angular smoothing can be useful as a diagnostic, but it is not a finite driver/source support for high-fidelity BEM source selection. | 2.2006585177202242 | 9.203238235802512 | 9.144851283078523 | 62.25220610629696 | 9.203238235802512 | 8.925349627952757 | 9.144851283078523 | 8.844030546885874 | 23.73809326506579 | 62.25220610629696 | 0 | 0 | 0 | symmetric-depth-rings |  |  |  |  |  |  |  |  |  |  | modal
5 | measured-phase-h1659-modal-full2-az24-reg1e-06 | split-profile-ring | measured | rejected_bad_insample_fit | Juan in-sample side-worst normalized RMS 5.967 dB exceeds 3.000 dB. | 3.4940176483861665 | 5.966672444121461 | 6.200199218100268 | 62.847174804023616 | 2.6822386556549738 | 5.966672444121461 | 2.628811786383559 | 6.200199218100268 | 15.13392272666505 | 62.847174804023616 | 0 | 484 | 4 | h1659-modal-full-2 |  |  |  |  |  |  | 1e-06 |  |  |  | modal
13 | split-active-surface-compact-m4-az16-gap30-q3-reg1e-06-svd1e-05 | split-active-surface-modal | measured | rejected_bad_insample_fit | Juan in-sample side-worst normalized RMS 3.766 dB exceeds 3.000 dB. | 4.531193744828727 | 3.7660813909885853 | 4.046282413554309 | 42.5701322794002 | 2.517849474082636 | 3.7660813909885853 | 2.5533264567297986 | 4.046282413554309 | 42.5701322794002 | 37.21709048858433 | 0 | 8 | 8 | h1659-acoustic-compact |  |  |  |  |  |  | 1e-06 |  | 1e-05 | 4 | modal | 16 | 3 | 30.0
14 | measured-phase-h1659-modal-full4-az24-reg1e-06-svd1e-05 | split-profile-ring | measured | rejected_bad_insample_fit | Juan in-sample side-worst normalized RMS 5.119 dB exceeds 3.000 dB. | 5.010712010410166 | 5.118591204425127 | 5.207304731894543 | 38.86057814438738 | 1.050088912320182 | 5.118591204425127 | 1.0388725493052466 | 5.207304731894543 | 12.998901566223541 | 38.86057814438738 | 0 | 968 | 8 | h1659-modal-full-4 |  |  |  |  |  |  | 1e-06 |  | 1e-05 |  | modal
15 | split-active-surface-compact-m4-az16-gap16-q3-reg1e-06-svd1e-05 | split-active-surface-modal | dipole | rejected_bad_insample_fit | Juan in-sample side-worst normalized RMS 7.807 dB exceeds 3.000 dB. | 5.468231913668781 | 7.80708846984502 | 7.740582124372561 | 54.561206434144324 | 7.80708846984502 | 7.623636288913384 | 7.740582124372561 | 7.509649833535143 | 29.49280724887613 | 54.561206434144324 | 0 | 8 | 8 | h1659-acoustic-compact |  |  |  |  |  |  | 1e-06 |  | 1e-05 | 4 | modal | 16 | 3 | 16.0
21 | active-surface-compact-m3-az16-q3-reg1e-06-svd1e-05 | active-surface-modal | dipole | rejected_bad_insample_fit | Juan in-sample side-worst normalized RMS 6.111 dB exceeds 3.000 dB. | 7.695928651581942 | 6.110858458899992 | 5.4729403020869825 | 67.33020682734711 | 2.1455372055423214 | 6.110858458899992 | 2.2234067564206614 | 5.4729403020869825 | 67.33020682734711 | 32.4059440907193 | 0 | 3 | 3 | h1659-acoustic-compact |  |  |  |  |  |  | 1e-06 |  | 1e-05 | 3 | modal | 16 | 3
23 | measured-phase-h1659-profile-ring-compact-az24-reg1e-06 | split-profile-ring | measured | rejected_bad_insample_fit | Juan in-sample side-worst normalized RMS 4.595 dB exceeds 3.000 dB. | 8.414833451881314 | 4.59509967195541 | 4.332562375989909 | 24.57179824348774 | 0.8653203154998468 | 4.59509967195541 | 0.8562072300949246 | 4.332562375989909 | 12.28264666638224 | 24.57179824348774 | 0 | 146 | 8 | h1659-acoustic-compact |  |  |  |  |  |  | 1e-06 |  |  |  | modal
24 | measured-phase-h1659-profile-ring-full-az24-reg1e-06 | split-profile-ring | measured | rejected_bad_insample_fit | Juan in-sample side-worst normalized RMS 4.653 dB exceeds 3.000 dB. | 8.557332024702612 | 4.652795109637316 | 4.383073273698403 | 24.630410022139017 | 0.8547934313314776 | 4.652795109637316 | 0.8452022319404184 | 4.383073273698403 | 12.297853262050523 | 24.630410022139017 | 0 | 242 | 12 | h1659-acoustic-full |  |  |  |  |  |  | 1e-06 |  |  |  | modal
10 | h1659-profile-ring-compact-az24-reg1e-06 | split-profile-ring | dipole | rejected_weak_cv | Juan held-out side-worst normalized RMS 4.090 dB exceeds 4.000 dB. | 4.0900264152490715 | 1.0925572044675098 | 1.0328271344427737 | 12.28264666638224 | 0.8653203154998468 | 1.0925572044675098 | 0.8562072300949246 | 1.0328271344427737 | 12.28264666638224 | 12.268863818042647 | 0 | 146 | 8 | h1659-acoustic-compact |  |  |  |  |  |  | 1e-06 |  |  |  | modal
11 | h1659-modal-full3-az24-reg1e-06 | split-profile-ring | dipole | rejected_weak_cv | Juan held-out side-worst normalized RMS 4.090 dB exceeds 4.000 dB. | 4.0904855311997395 | 2.18409462940999 | 2.155968641386649 | 13.920467476644095 | 2.18409462940999 | 1.2042961173057771 | 2.155968641386649 | 0.9654800131551793 | 13.920467476644095 | 13.60792656655033 | 0 | 726 | 6 | h1659-modal-full-3 |  |  |  |  |  |  | 1e-06 |  |  |  | modal
12 | h1659-profile-ring-compact-az24-reg1e-06-svd1e-05 | split-profile-ring | dipole | rejected_weak_cv | Juan held-out side-worst normalized RMS 4.092 dB exceeds 4.000 dB. | 4.091601022081739 | 1.0925572044660374 | 1.0328271344407687 | 12.282651230759521 | 0.8653177118419157 | 1.0925572044660374 | 0.8562046997773363 | 1.0328271344407687 | 12.282651230759521 | 12.26886381805273 | 0 | 146 | 8 | h1659-acoustic-compact |  |  |  |  |  |  | 1e-06 |  | 1e-05 |  | modal
16 | h1659-profile-compact-split-discrete-d45-r0_40_75-reg1e-06-svd1e-05 | split-discrete | dipole | rejected_weak_cv | Juan held-out side-worst normalized RMS 6.649 dB exceeds 4.000 dB. | 6.649235667020322 | 1.386646227987682 | 1.3723132558843645 | 11.159362042371033 | 1.386646227987682 | 1.1605338253872535 | 1.3723132558843645 | 1.1493190389509425 | 11.159362042371033 | 10.977509534404689 | 0 | 14 | 14 | h1659-acoustic-compact | 45.0 | 0,40,75 |  |  |  |  | 1e-06 |  | 1e-05 |  | modal
17 | asym-split-discrete-f45-r55-r0_35_70_95-reg1e-06-svd1e-05 | split-discrete | dipole | rejected_weak_cv | Juan held-out side-worst normalized RMS 6.793 dB exceeds 4.000 dB. | 6.793252571234323 | 2.65629404694396 | 2.6272062551136224 | 15.473842382008115 | 2.403629532132933 | 2.65629404694396 | 2.381093284497877 | 2.6272062551136224 | 14.888741264596408 | 15.473842382008115 | 0 | 14 | 14 | asymmetric_depth_rings |  |  | 45.0 | 55.0 | 0,35,70,95 | 0,35,70,95 | 1e-06 |  | 1e-05 |  | modal
18 | asym-split-discrete-f45-r55-front35-rear25-reg1e-06-svd1e-05 | split-discrete | dipole | rejected_weak_cv | Juan held-out side-worst normalized RMS 6.815 dB exceeds 4.000 dB. | 6.814654810505503 | 2.6386246441174777 | 2.6121304252683335 | 15.338327737679718 | 2.403629532132933 | 2.6386246441174777 | 2.381093284497877 | 2.6121304252683335 | 14.888741264596408 | 15.338327737679718 | 0 | 16 | 16 | asymmetric_depth_rings |  |  | 45.0 | 55.0 | 0,35,70,95 | 0,25,50,75,95 | 1e-06 |  | 1e-05 |  | modal
19 | d55-split-discrete-r0_25_50_75_95-reg1e-06-svd1e-05 | split-discrete | dipole | rejected_weak_cv | Juan held-out side-worst normalized RMS 6.874 dB exceeds 4.000 dB. | 6.874229771208863 | 2.6386246441174777 | 2.6121304252683335 | 15.338327737679718 | 2.53735215131827 | 2.6386246441174777 | 2.51777851859631 | 2.6121304252683335 | 15.283396428297948 | 15.338327737679718 | 0 | 18 | 18 | symmetric-depth-rings | 55.0 | 0,25,50,75,95 |  |  |  |  | 1e-06 |  | 1e-05 |  | modal
20 | h1659-profile-full-split-discrete-d45-r0_40_75-reg1e-06-svd1e-05 | split-discrete | dipole | rejected_weak_cv | Juan held-out side-worst normalized RMS 6.893 dB exceeds 4.000 dB. | 6.89261028372341 | 1.3970608352575566 | 1.3828032167795299 | 11.102550821775395 | 1.3970608352575566 | 1.1693387151462253 | 1.3828032167795299 | 1.1587163510772667 | 11.102550821775395 | 10.9897150682388 | 0 | 22 | 22 | h1659-acoustic-full | 45.0 | 0,40,75 |  |  |  |  | 1e-06 |  | 1e-05 |  | modal
22 | measured-phase-split-discrete-d45-r0_40_75-reg1e-06 | split-discrete | measured | rejected_weak_cv | Juan held-out side-worst normalized RMS 7.707 dB exceeds 4.000 dB. | 7.707403227127374 | 2.862234970147041 | 2.6669073048844703 | 27.75883123683443 | 2.5413041727005856 | 2.862234970147041 | 2.507494244720231 | 2.6669073048844703 | 16.23373975871606 | 27.75883123683443 | 0 | 10 | 10 | symmetric-depth-rings | 45.0 | 0,40,75 |  |  |  |  | 1e-06 |  |  |  | modal
25 | stable-split-discrete-d45-r0_40_75-reg1e-06 | split-discrete | dipole | rejected_weak_cv | Juan held-out side-worst normalized RMS 8.622 dB exceeds 4.000 dB. | 8.6219574254496 | 2.6417089752262717 | 2.597715541263958 | 16.308285322309622 | 2.5413041727005856 | 2.6417089752262717 | 2.507494244720231 | 2.597715541263958 | 16.23373975871606 | 16.308285322309622 | 0 | 10 | 10 | symmetric-depth-rings | 45.0 | 0,40,75 |  |  |  |  | 1e-06 |  |  |  | modal
26 | current-wide-split-discrete-d45-r0_35_70_95-reg1e-06-svd1e-05 | split-discrete | dipole | rejected_weak_cv | Juan held-out side-worst normalized RMS 8.810 dB exceeds 4.000 dB. | 8.810187953561085 | 2.4996240766548543 | 2.4694379891703324 | 14.960913682536928 | 2.403629532132933 | 2.4996240766548543 | 2.381093284497877 | 2.4694379891703324 | 14.888741264596408 | 14.960913682536928 | 0 | 14 | 14 | symmetric-depth-rings | 45.0 | 0,35,70,95 |  |  |  |  | 1e-06 |  | 1e-05 |  | modal
27 | wide-split-discrete-d45-r0_35_70_95-reg1e-06 | split-discrete | dipole | rejected_weak_cv | Juan held-out side-worst normalized RMS 8.810 dB exceeds 4.000 dB. | 8.810212182470925 | 2.4995958805861838 | 2.4694070971981357 | 14.960163100042283 | 2.4035884360917716 | 2.4995958805861838 | 2.381049112033957 | 2.4694070971981357 | 14.887999593471601 | 14.960163100042283 | 0 | 14 | 14 | symmetric-depth-rings | 45.0 | 0,35,70,95 |  |  |  |  | 1e-06 |  |  |  | modal
28 | split-ring-d45-r0_25_50_75_95-az48-reg1e-06-svd1e-05 | split-ring | dipole | rejected_weak_cv | Juan held-out side-worst normalized RMS 9.274 dB exceeds 4.000 dB. | 9.2742085969056 | 2.936219347092238 | 2.951808628913937 | 17.49722465689258 | 2.789678661570972 | 2.936219347092238 | 2.8270908428411983 | 2.951808628913937 | 17.49722465689258 | 17.449164796044524 | 0 | 386 | 10 | symmetric-depth-rings | 45.0 | 0,25,50,75,95 |  |  |  |  | 1e-06 |  | 1e-05 |  | modal
29 | split-ring-d45-r0_35_70_95-az24-reg1e-06 | split-ring | dipole | rejected_weak_cv | Juan held-out side-worst normalized RMS 9.279 dB exceeds 4.000 dB. | 9.279425642743409 | 2.944094740572186 | 2.9580075344487335 | 17.54463056530474 | 2.797038515610811 | 2.944094740572186 | 2.8330822109954843 | 2.9580075344487335 | 17.54463056530474 | 17.49899792781987 | 0 | 146 | 8 | symmetric-depth-rings | 45.0 | 0,35,70,95 |  |  |  |  | 1e-06 |  |  |  | modal

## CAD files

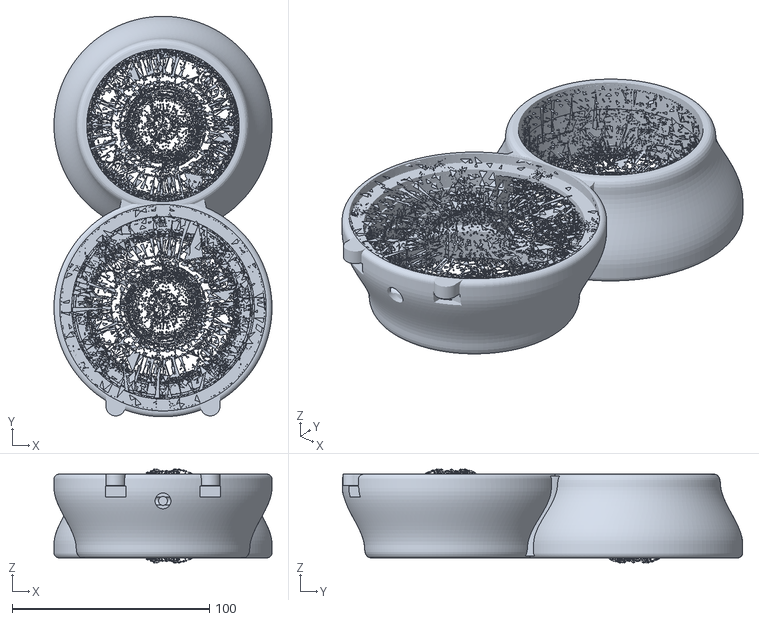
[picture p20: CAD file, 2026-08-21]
top_baffle_v2/build/ptt_crescent_PTT1.3T04-HAG-01/review_assembly.stl
110.6 x 203.1 x 47.6

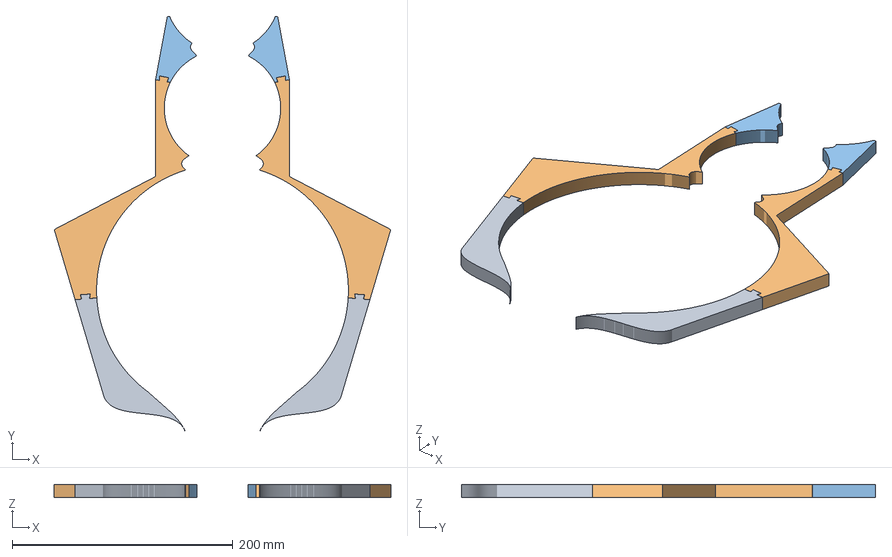
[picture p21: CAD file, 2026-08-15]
top_baffle_v2/build/wings/flat/obiwan_wing_flat_assembled.step
304.8 x 374.9 x 11.5 mm
obiwan_wing_flat_left_1_of_3_lm_lower
obiwan_wing_flat_left_2_of_3_lm_upper
obiwan_wing_flat_left_3_of_3_um
obiwan_wing_flat_right_1_of_3_lm_lower
obiwan_wing_flat_right_2_of_3_lm_upper
obiwan_wing_flat_right_3_of_3_um

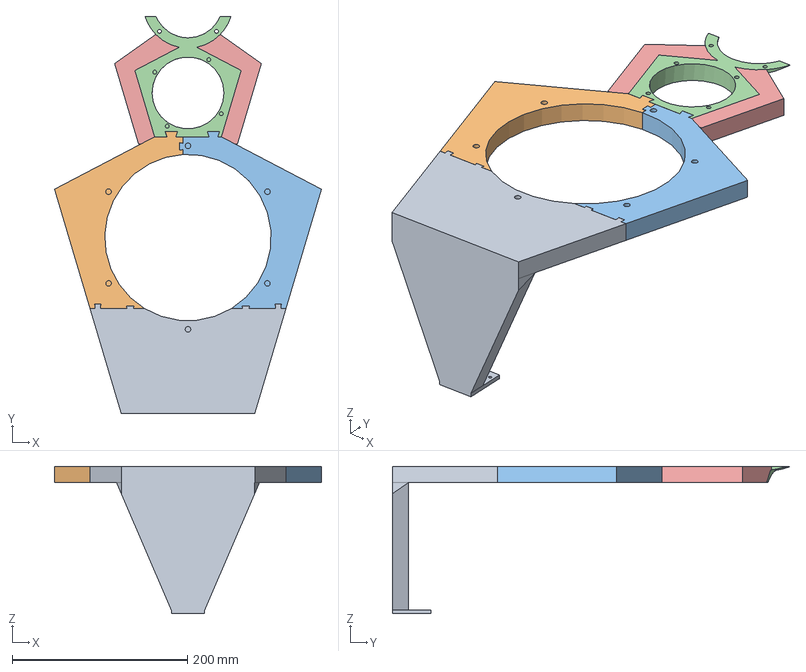
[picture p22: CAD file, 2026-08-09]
top_baffle_v2/floor_stand/top_baffle_nd25fw4_b1_assembled.step
304.8 x 453.5 x 168.3 mm
piece_bottom
piece_mid_left
piece_mid_right
piece_top_b2
attach_b1_wing_left
attach_b1_wing_right

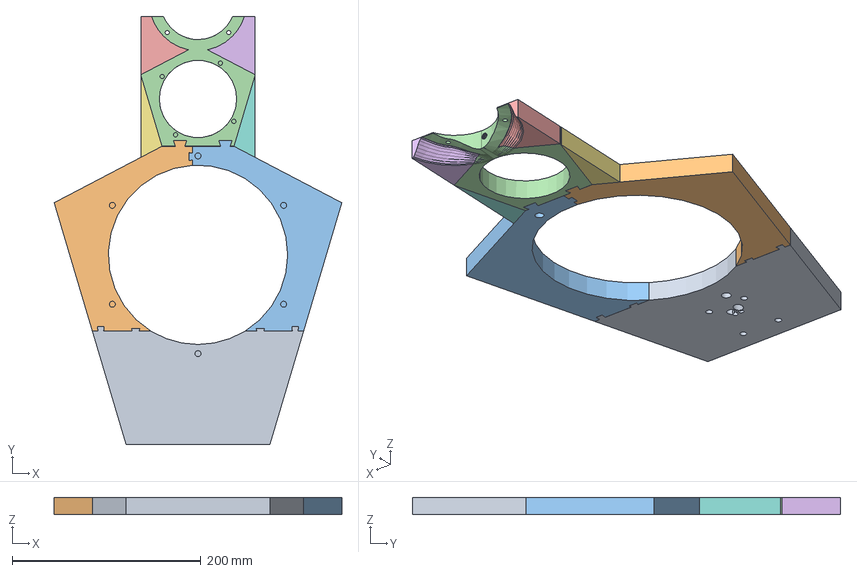
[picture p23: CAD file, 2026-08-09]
top_baffle_v2/no_floor_stand/top_baffle_nd25fw4_a_comp_assembled.step
304.8 x 453.5 x 18.3 mm
piece_bottom
piece_mid_left
piece_mid_right
piece_top_b2
attach_a_shoulder_top_left
attach_a_shoulder_top_right
attach_a_shoulder_bottom_left
attach_a_shoulder_bottom_right

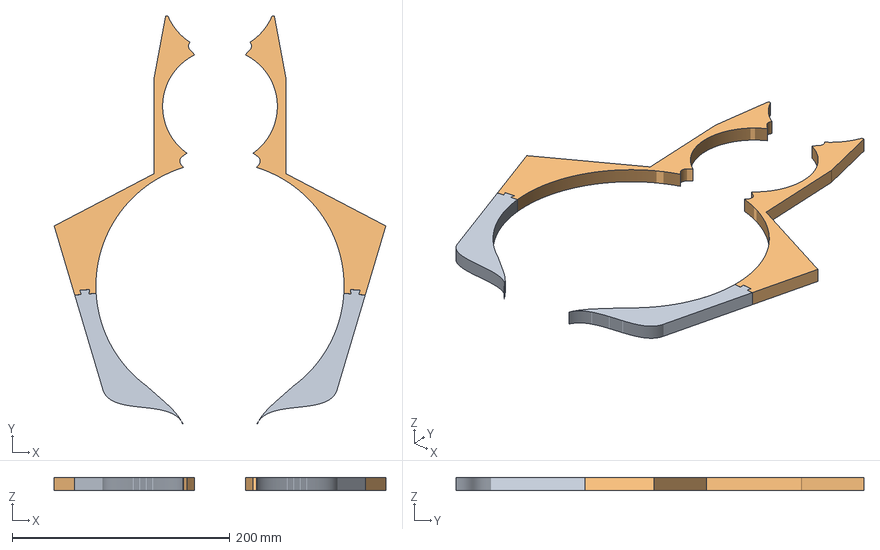
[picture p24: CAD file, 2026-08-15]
top_baffle_v2/build/wings/flat/obiwan_wing_flat_assembled_split2.step
304.8 x 374.9 x 11.5 mm
obiwan_wing_flat_left_split2_1_of_2_lm_lower
obiwan_wing_flat_left_split2_2_of_2_lm_um_upper
obiwan_wing_flat_right_split2_1_of_2_lm_lower
obiwan_wing_flat_right_split2_2_of_2_lm_um_upper

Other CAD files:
top_baffle_v2/artifacts/obiwan/wings/flat/cad/print_assembly.step
top_baffle_v2/artifacts/stock/cad/base_print_assembly.step
top_baffle_v2/artifacts/obiwan/states/no_floor/cad/review_assembly.step
top_baffle_v2/artifacts/obiwan/wings/graded/cad/print_assembly.step
top_baffle_v2/artifacts/slim/cad/base_print_assembly.step
top_baffle_v2/artifacts/stock/cad/shoulders_assembly.step
top_baffle_v2/floor_stand/top_baffle_nd25fw4_a_comp_assembled.step
top_baffle_v2/artifacts/obiwan/states/floor/cad/review_assembly.step
top_baffle_v2/artifacts/stock/cad/wings_assembly.step
top_baffle_v2/no_floor_stand/top_baffle_nd25fw4_b1_assembled.step
top_baffle_v2/artifacts/obiwan/states/floor/cad/attachments.step
top_baffle_v2/artifacts/obiwan/states/floor/stl/obiwan_core_2_of_2_um_carrier.stl
top_baffle_v2/artifacts/obiwan/states/no_floor/cad/core.step
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

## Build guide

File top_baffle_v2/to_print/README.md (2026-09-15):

# P2S print shelf

**Current printer: [H2C](h2c/README.md).** Its catalog includes all three
tweeter families: ND25FW-4, TEBM35C10-4 BMR and ND25FN-4 printed waveguide.
This page retains the earlier P2S files and split arrangement.

Three tweeter families and five arrangements at the same scale

Start with the [build guide](../docs/BUILD_GUIDE.md), then use the generated
[file guide and estimates](FILE_GUIDE.md) to choose exact files.

| Tweeter family | Earlier P2S selection | Files |
|---|---|---|
| Dayton ND25FW-4 | Standard Stock/Slim upper or regular Obiwan UM + crescent | [Regular shelf and estimates](FILE_GUIDE.md) |
| Tectonic TEBM35C10-4 BMR | Regular Obiwan UM + coaxial/opposed crescent; Stock/Slim BMR vase has separate source delivery | [Obiwan shelf](FILE_GUIDE.md) · [Other BMR mounts](../docs/VARIANTS.md) |
| Dayton ND25FN-4 waveguide | Fused UM/body + two caps + two M3 retainers + matching optional upper wings | [PETG-GF + PLA jobs](../candidates/nd25fn4_crescent/print/README.md) · [PETG Translucent + PLA jobs](../candidates/nd25fn4_crescent/print_translucent/README.md) |

ND25FN-4 keeps 15% tweeter gyroid / 100% UM infill and native magnet
pauses. Its six-job material bundles have their own manifests; the regular
shelf counts below cover the earlier ND25FW-4/BMR selection inventory.

The shelf contains **42 choices**: 11 Stock, 11 Slim and 20 Obi-Wan. Across
alternative material/nozzle lanes there are **68 sliced projects and
8 GUI projects**. These are alternatives, not the number to print.
`delivery_manifest.json` binds every project to its source STL and authority,
records hashes and settings, and includes geometry audits for GUI projects.
Existing slice provenance is retained in the lane manifests.

| Directory | Delivery |
|---|---|
| `<family>/stl` | Shared source meshes, one per choice |
| `<family>/3mf_04` | Audited PLA Basic jobs for a 0.4 mm nozzle |
| `<family>/3mf_06hf` | Audited PLA Basic jobs for a 0.6 mm high-flow nozzle |
| `obiwan/3mf_06hf_petg-gf` | Audited PETG-GF wing combos for 0.6 mm high flow |
| `obiwan/3mf_06hf_petg-gf_pla` | PETG-GF core projects requiring GUI slicing; PLA interfaces where support is enabled |

Open sliced `.gcode.3mf` jobs with the matching nozzle and preserve the
audited orientation/pauses. Open `_GUI.3mf` projects, assign material slots,
slice and inspect/export the result. A geometry-audited GUI project has no
audited toolpaths until this last step is completed. Core combos contain
four parts without a floor stand and five with one, including its NL8 lid.
They replace the corresponding individual files. Wing combos replace four
split2 pieces; flat and graded are mutually exclusive.

Obi-Wan remains a physical-qualification candidate. See the
[PETG-GF test procedure](../docs/PETG_GF_QUALIFICATION.md). No printer is
contacted by these commands.

```sh
make PRINTER=P2S to_print_validate  # read-only: inventory, hashes, source and GUI geometry
make PRINTER=P2S delivery_refresh  # bind an audited shelf and update the file guide
make PRINTER=P2S delivery_package  # validate, zip actual files and verify checksums
```

Publishers remain available through `make PRINTER=P2S to_print`, `make PRINTER=P2S to_print_06hf`,
`make PRINTER=P2S obiwan_petg_gui_projects` and `make PRINTER=P2S obiwan_petg_wing_plates`. They may
regenerate files and require current CAD/slice provenance. Run
`make PRINTER=P2S delivery_refresh` after publishing. Validation never repairs files,
creates slice workspaces, or touches promotion stamps.

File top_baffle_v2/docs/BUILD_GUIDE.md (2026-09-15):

# Build your top baffle — earlier P2S arrangement

For the current H2C printer, start with the [H2C file guide](../to_print/h2c/README.md)
and [three-family tweeter selection](TWEETER_OPTIONS.md). The integrated
[Dayton ND25FN-4 waveguide](DAYTON_ND25FN4_WAVEGUIDE.md) is an Obiwan upper
option with its own matching wings. Quantities and splits below describe
the earlier P2S arrangement.

Obiwan upper choices: ND25FW-4, coaxial BMR, opposed BMR and ND25FN-4 waveguide

Choose the shape, mounting state and tweeter before opening a print file.
These are DIY CAD designs for an LX521.4 modification. Stock is the canonical
CAD baseline; Slim is experimental; Obi-Wan and the BMR options require
physical qualification. No measured acoustic advantage is claimed here.

| Choice | What you get | Main parts for one speaker on P2S |
|---|---|---|
| Stock | Full-depth 18.3 mm baffle | 01 bottom in one stand state, 02 and 03 middle pieces, 04 vase |
| Slim | 11.5 mm acoustic field with a full-depth lower strip | The matching Slim 01, 02, 03 and 04 |
| Obiwan / ND25FW-4 | Regular UM and separate crescent | Keyed LM bottom + top, regular UM + ND25FW-4 crescent |
| Obiwan / TEBM35C10-4 BMR | Regular UM and chosen BMR crescent | Same keyed LM pair + regular UM + coaxial **or** opposed BMR crescent |
| Obiwan / ND25FN-4 waveguide | Fused organic UM/waveguide | Same keyed LM pair + fused body + 2 caps + 2 M3 retainers; [print files](../candidates/nd25fn4_crescent/print/README.md) |

Add the NL8 service lid to each Obiwan floor configuration. Stock/Slim rows
use ND25FW-4 by default; their opposed-BMR upper replaces the whole vase.

Stock and Slim can be bare, or use their matching four A shoulders,
or their matching pair of B1 wings. Choose one perimeter system. Obi-Wan can
be bare, or use four flat split2 pieces, or four graded split2 pieces. Its
wing combo replaces those four separate jobs. Split3 is retired from the shelf.

For regular ND25FW-4 Obiwan, the core combo replaces 01+02+03+04. The floor combo also
contains the NL8 service lid (five parts). Print a combo or its contents,
then repeat that selection for the second speaker. A complete winged
regular ND25FW-4 Obiwan has eight printed parts without a floor stand,
nine with one. ND25FN-4 uses its fused body and accessories instead of
the regular UM/crescent, and matching upper wing sections above the common
lower wing sections. Its accessories plate already contains both caps and
both retainers. Do not also print the regular core combo for that upper.

## Pick the files

Use the generated [file guide](../to_print/FILE_GUIDE.md) for exact links,
lane, stand state, slicer time and filament estimates. Estimates are
per job; GUI jobs have no estimate until sliced. The catalog has 42 choices
and 76 projects across alternate lanes. This is not a shopping quantity.

| Folder | Material / nozzle | What to do |
|---|---|---|
| `3mf_04` | PLA Basic / 0.4 mm | Open the sliced `.gcode.3mf`; preserve its orientation and magnet pauses |
| `3mf_06hf` | PLA Basic / 0.6 mm high flow | Same workflow, with the matching installed nozzle |
| `3mf_06hf_petg-gf` | TINMORRY PETG-GF / 0.6 mm high flow | Sliced flat or graded wing combo; support is off |
| `3mf_06hf_petg-gf_pla` | TINMORRY PETG-GF / 0.6 mm high flow, PLA interface where support is enabled | Open `_GUI.3mf`, assign slots, slice and audit the exported result before printing |

GUI core combos, LM bottoms and UM carriers use six walls and 100% zig-zag infill,
normal/snug support, PETG-GF support bodies and PLA interfaces at zero top
Z gap. The standalone LM top also uses 100% structural infill with support; the crescent and lid
use 30% gyroid with support off.
Saved settings and the delivery manifest are the exact authority.
Do not substitute a generic PETG profile or an installed same-name preset.

## Hardware to prepare

Counts below are **one speaker / stereo pair**, with the default ND25FW-4 pair.
The [insert catalog](INSERT_CATALOG.md) identifies each bore and insert size.
Confirm screw engagement with the actual driver flange and washer stack;
do not bottom a screw in a blind insert.

| Configuration | M5 inserts | M3 inserts | M2 inserts |
|---|---|---|---|
| Stock or Slim, bridge | 10 / 20 | 5 / 10 | 0 / 0 |
| Obi-Wan, bridge | 10 / 20 | 8 / 16 | 3 / 6 |
| Obi-Wan, floor | 8 / 16 | 12 / 24 | 3 / 6 |

For each Obi-Wan speaker, prepare six LM driver screws (M5), four UM driver
screws (M3), two LM–UM and two UM–crescent joint screws (M3), and three
M2 × 8 ties. The floor adds four NL8 screws (M3) and two floor-anchor
fasteners (M5); the bridge adds four bridge fasteners (M5). Stock/Slim
use the corresponding driver/bridge fasteners and one M3 vase-seam fastener.
Their integral-floor mounting hardware depends on the external stand and
must be counted from that stand's drawing.

The ND25FW-4 pair uses four M4 through-clamp screws and nuts per speaker (eight
for stereo), not heat-set inserts. Prepare one LM driver, one UM driver and
 two tweeters per speaker, the chosen connector, actual speaker leads and
compatible external stand/bridge. CAD driver references are fit proxies;
confirm the installed driver's terminals and flange.

A winged regular Obiwan uses twelve D5 × 2 magnets per speaker (24 stereo): six
in the core and six in the wings. Bare collars can retain their six buried
magnets for future wings. For Stock/Slim, count the selected jobs' sites in
the pause manifest; unused alternative files do not add hardware.
An opposed-BMR vase or either two-driver BMR crescent adds eight M2 driver
inserts and screws per speaker (16 stereo) and replaces the ND25 carrier
and pair. Stock/Slim BMR vases are separate CAD deliverables outside this
42-choice shelf. BMR-slim and PTT1.3 remain separate candidates.

| Upper-specific hardware | ND25FW-4 | TEBM35C10-4 BMR | ND25FN-4 waveguide |
|---|---|---|---|
| Tweeter retention per speaker | Four M4 through-clamps | Eight M2 driver inserts and screws | Two retainers, six M3 × 8 screws and six Hanglife M3 × 5 × 4 inserts |
| UM/crescent connection | Separate M3 half-laps and M2 ties | Same regular UM service joint | Fused; no separate upper joint hardware |
| Wing interface magnets | D5: Ø5 × 2 N52 | Same regular UM/wings; extra BMR pod magnets have no supplied mate | Four D6: Ø6 × 3 N45 in body; four mating D6 across wing pair; LM and lower-wing contacts remain D5 |

The ND25FN-4 body has twelve M3 insert sites in total: four MU10, two LM
receivers and six retainers. Its common LM/UM M2 tie remains. A complete
winged speaker uses eight D6 plus eight D5 magnets. Follow its
[assembly order](DAYTON_ND25FN4_WAVEGUIDE.md#assembly-order) and selected
material guide; the regular-upper assembly steps below do not describe its caps.

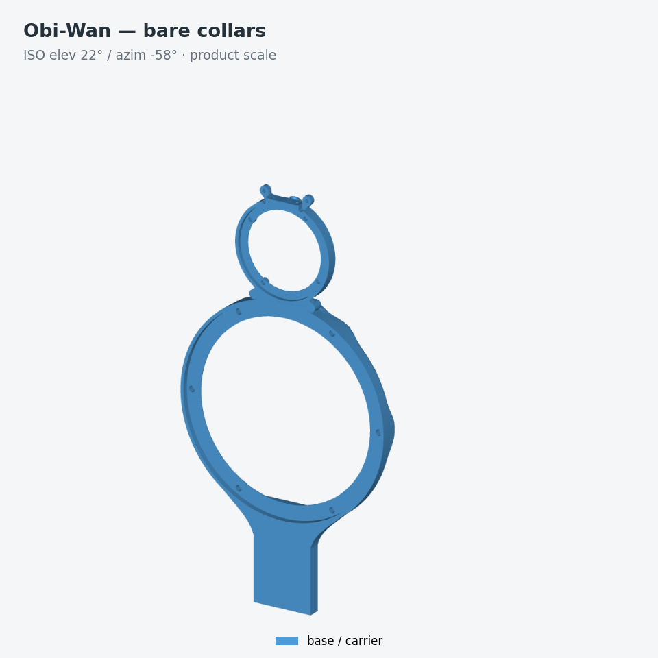
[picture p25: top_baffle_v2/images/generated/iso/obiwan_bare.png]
Bare Obi-Wan collars


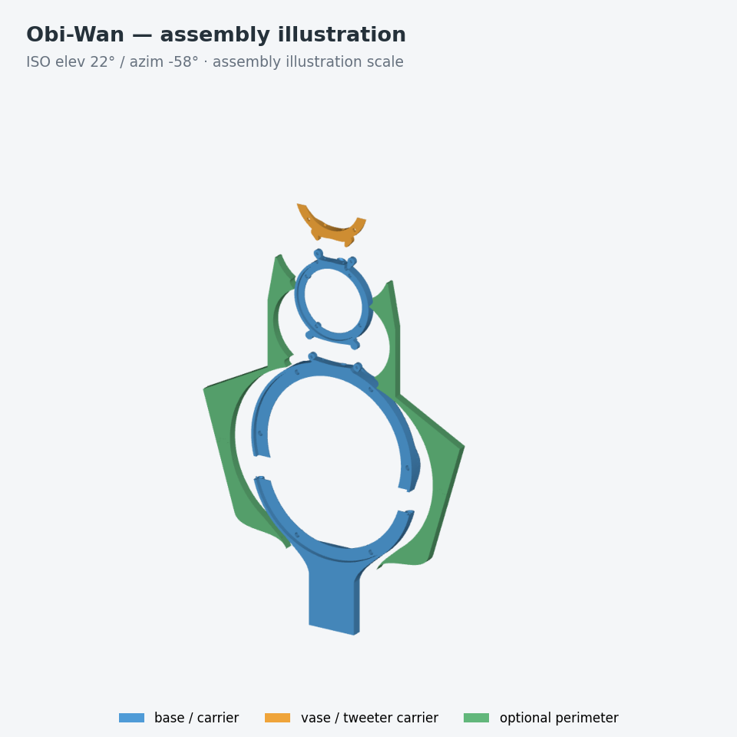
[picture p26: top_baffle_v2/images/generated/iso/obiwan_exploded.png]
Exploded assembly illustration


Exploded offsets are illustrative, not assembly clearances.

## Print and assemble

1. Record the project hash, printer/nozzle, filament lot and drying history.
   Run the [PETG-GF qualification procedure](PETG_GF_QUALIFICATION.md)
   before committing to a structural build.
2. Preserve front-face-down orientation. For a GUI project, inspect both
   pin paths, blind insert bores, cable mouths, support removal access,
   material changes, prime-tower clearance and the pause in sliced preview.
3. Follow the selected job's pause count. Core combos pause at Z=5.96 mm
   for six magnets; standalone core parts have only their own sites.
   Mark a reference magnet, test every mating pair for attraction, and use
   the site's marked-pole direction in the pause manifest. Seat magnets
   below the next extrusion before resuming; do not infer polarity from
   left/right appearance. Photograph placements before burial.
4. Remove accessible support and fish the actual cables through every
   route before installing drivers. Reject a blocked route or trapped
   support. Install heat-set inserts in individual parts before assembly.
5. Dry-fit the keyed LM seam on a flat reference surface. Pins register
   the halves; the driver flange and its normal fasteners complete the load
   path. Fit LM–UM and UM–crescent joints and their ties without forcing.
6. Join wing dovetails coplanar on the same flat reference. Follow the wing
   adhesive-gallery procedure in [Obi-Wan](obiwan.md), then test magnetic
   attachment. Magnets receive no structural load credit.
7. Check screw engagement, cable clearance and front-plane alignment with
   the real drivers. Complete separate floor/bridge loaded tests and
   photograph the assembly before recording a physical pass.

## Evidence and sharing

The [qualification record](obiwan_physical_qualification.md) is pending.
The test worksheet records measured values and photo/measurement paths.
CAD renders illustrate configuration and assembly; they are not photographs
or acoustic test results. Publish response/polar comparisons only after
recording driver, crossover, microphone geometry and the baseline.

`make delivery_package` creates `dist/lx521-print-pack.zip` with actual STL
and 3MF bytes, this guide, estimates, qualification assets and SHA-256
checksums. Extracting it does not require the repository's symlinks.
The `artifacts/` facade is for browsing the source checkout; do not distribute
that symlink tree on its own.

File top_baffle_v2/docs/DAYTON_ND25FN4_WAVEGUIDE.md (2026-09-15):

# Dayton ND25FN-4 waveguide — integrated Obiwan upper

The **Dayton ND25FN-4 waveguide** is the project's third tweeter family,
alongside the Dayton ND25FW-4 face-to-face pair and Tectonic TEBM35C10-4 BMR.
It combines the MU10 upper-mid (UM) carrier and two printed tweeter
waveguides into one organic body. The lower tweeter faces front; the upper
one faces rear. Two removable caps and two retainers provide service access.

Obiwan upper comparison: ND25FW-4, coaxial BMR, opposed BMR and ND25FN-4 waveguide

The ND25FN-4 is the rightmost upper, aligned to the same LM joint and scale
as the other three arrangements. These views show the exported printed
parts with drivers and service caps omitted. See the
[three-family selection table](TWEETER_OPTIONS.md) for compatibility.

The ND25FN-4 is a 4-ohm, 25 mm silk-dome element supplied without a
faceplate, intended for custom mounting. Its nominal envelope is Ø41 mm
with a 21 mm depth and Ø34 mm cutout. The ND25FW-4 has a different mounting
arrangement; the two drivers are not interchangeable in these printed parts.
[Dayton Audio specifications and 3D reference](https://www.daytonaudio.com/product/1194/nd25fn-4-1-neo-silk-dome-tweeter-element-4-ohm).

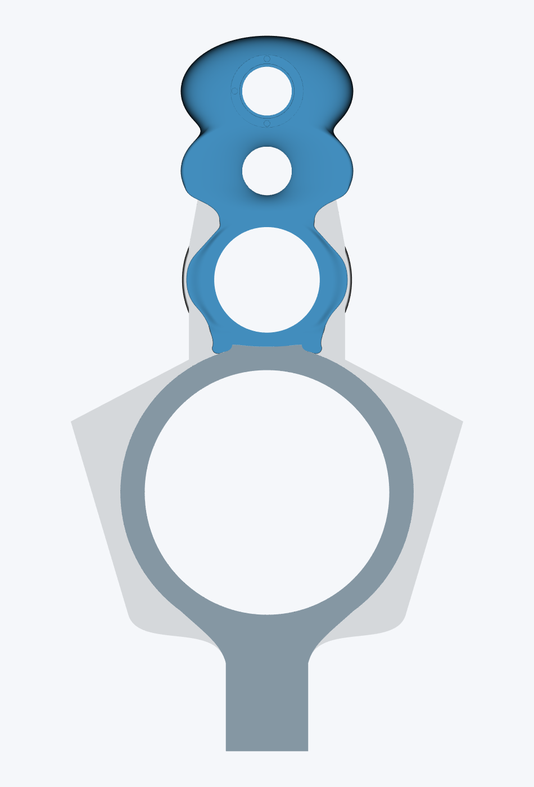
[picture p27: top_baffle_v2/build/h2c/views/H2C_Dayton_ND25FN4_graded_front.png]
Actual H2C assembly with matching continuous graded wings


## Compatibility and quantities

Use this upper with **Obiwan only**. No Stock or Slim adapter is currently
provided. It replaces both the regular UM collar and its separate tweeter
crescent. The fused body is identical for the floor-stand and no-floor-stand
configurations; choose the appropriate LM carrier underneath it.

| Part per speaker | Quantity | Selection |
|---|---:|---|
| Obiwan H2C LM carrier | 1 | Floor stand or no floor stand |
| ND25FN-4 fused UM/waveguide body | 1 | Shared between stand states |
| ND25FN-4 service cap | 2 | Included on one accessories plate |
| ND25FN-4 M3 retainer | 2 | Included on the same accessories plate |
| Matching continuous left and right wings | 1 of each, optional | Choose flat **or** graded |
| Dayton ND25FN-4 tweeter element | 2 | Front/rear pair |
| MU10 UM driver | 1 | Existing project driver |

Print one accessories plate per speaker: it already contains two caps and
two retainers. Double the quantities for a stereo pair. Caps and retainers
remain separate service parts.

**Regular Obiwan wings do not match this upper.** The ND25FN-4 wings follow
the curved body and have two Ø6 mm UM contacts per side. Regular wings
have a different upper interface. The H2C matching wing is continuous from
LM to UM; the older P2S delivery used separate upper and lower sections.

## H2C print files

Open the [current H2C file catalog](../to_print/h2c/README.md) and select the
`dayton_nd25fn4` group. It contains separate projects and audited slices for:

- **Tinmorry PETG-GF + PLA:** [file folder](../to_print/h2c/dayton_nd25fn4/petg_gf_pla/).
- **PETG Translucent + PLA Translucent:** [file folder](../to_print/h2c/dayton_nd25fn4/petg_translucent_pla/).

The canonical body is
[`h2c_dayton_nd25fn4_body.stl`](../to_print/h2c/STL/dayton_nd25fn4/h2c_dayton_nd25fn4_body.stl).
The [cap](../to_print/h2c/STL/dayton_nd25fn4/h2c_dayton_nd25fn4_cap.stl) and
[retainer](../to_print/h2c/STL/dayton_nd25fn4/h2c_dayton_nd25fn4_retainer.stl)
are single-part STLs. The full wing filenames begin
`h2c_dayton_nd25fn4_wing_` in the [H2C STL folder](../to_print/h2c/STL/).

Use the prepared `.3mf` or audited `.gcode.3mf` to retain the material mapping,
modifiers, support exclusions and measured magnet pauses. An imported STL
alone does not carry those settings. No ZIP is needed.

The H2C jobs use two **0.6 mm High Flow nozzles**: model material on the
left and PLA interfaces on the right. They use an Engineering Plate with
glue at 70 °C, a 5 mm outer brim and no raft. Earlier P2S AMS slot numbers
are not H2C nozzle assignments. The H2C jobs retain native machine priming
and standby programs; the earlier same-nozzle purge workaround is specific
to P2S.

| Region | Current infill policy |
|---|---|
| Structural UM portion | 100% zig-zag, matching the regular UM |
| Tweeter portion of the same body | 15% gyroid, applied by a modifier |
| Matching wings | 10% gyroid |
| Caps and retainers | 15% gyroid |

Six walls are used throughout. PETG forms support bases; PLA forms three
dense, zero-gap interface layers above and below. Both cap ceilings receive
PLA directly underneath them; retainers print without support. The red
nonprinting volumes exclude supports from the cable gallery, magnet loading
paths and all 12 insert interiors. Actual extrusion is audited after slicing.

The translucent body uses Classic, outer-first walls to reduce exterior
line-width changes around buried magnets. A smooth physical finish remains
a print qualification item. PETG Translucent with PLA Translucent is an
explicit custom-material exception to Bambu's narrower mutual-support guide;
it is not vendor-qualified by that guide. See the generated
[H2C policies and exceptions](../to_print/h2c/README.md#policy-exceptions).

## Magnets and fasteners

| Location | Magnets |
|---|---|
| Fused body | 4 × Ø6 × 3 mm N45, buried at the curved UM shoulders |
| Each matching full wing: upper contacts | 2 × Ø6 × 3 mm N45 |
| Each matching full wing: LM contacts | 2 × Ø5 × 2 mm N52 |
| Obiwan LM contacts | Existing Ø5 × 2 mm N52 |

One body plus a wing pair takes **eight Ø6 × 3 mm magnets**. The Ø5 and Ø6
sizes are not substitutes. The larger upper pockets follow the sloping
surface and preserve an uninterrupted exterior cover. Install the magnets
at the embedded, slice-derived pauses, with matching polarity and full
seating. Do not copy pause heights from older P2S files: H2C wing orientation
and closure timing differ. [Selection and pocket details](../candidates/nd25fn4_crescent/MAGNET_SELECTION.md).

Use the existing **Hanglife HLTI-M3-001, M3 × 5 × 4 mm inserts**: M3 thread,
Ø5 mm metal outside diameter and 4 mm length. The shared printed pilot is
Ø4.6 × 4 mm. The body contains 12 M3 insert sites: four for MU10, two for
LM receivers and six for tweeter retainers. The two retainers use **six
M3 × 8 mm socket-head screws** in total. The original LM/UM M2 tie remains
its documented separate exception. Retain the cap seals, two 53 × 2 mm
O-rings and the specified driver gasket/pad sets.
[Hardware measurements](../candidates/nd25fn4_crescent/hardware_validation.json)
and [insert inventory](INSERT_CATALOG.md).

## Assembly order

1. Print one body, one accessories plate and the optional matching wing pair
   from a single material lane. Install the magnets at the embedded pauses,
   checking polarity against their mates before burial.
2. Remove supports and confirm that the enclosed cable gallery, cap seats
   and insert interiors are clear. Install the twelve M3 inserts in the
   individual body, using the specified Ø5 × 4 mm metal inserts and blind
   Ø4.6 × 4 mm pilots. Keep the common LM/UM M2 tie as its separate hardware
   convention.
3. Rehearse the actual UM terminals and tweeter leads before closing the
   assembly. Route the shared tweeter cable through the covered LM handoff
   and enclosed upper gallery, keeping the UM lead on its own service path.
4. Mate the body to the selected LM at the preserved half-laps. Fit the
   existing LM-to-UM fasteners and service tie, retain the 0.20 mm axial
   clearance, and verify the lower front is flush and leaves the LM face
   uncovered. The H2C LM is one piece; older P2S LM halves must first be
   assembled according to their keyed-split instructions.
5. Fit the MU10 and both ND25FN-4 elements with their specified gaskets and
   pads. Secure the two retainers with six M3 × 8 screws, then fit the two
   service caps and 53 × 2 mm O-rings. Check screw engagement and cap sealing
   on the real parts before final tightening.
6. Fit the optional ND25FN-4 wings and check all upper and LM magnetic
   contacts. Complete the actual driver, cable, material and loaded-retention
   checks recorded by the project before treating the assembly as qualified.

## Geometry and verification

The surround has a broad shallow bowl, front wider than rear, with an
inclined outer wall, rounded lower waist and a smooth UM-to-tweeter loft.
The cable gallery is enclosed inside the surround. Solid backing beneath
the MU10 seat and a covered LM cable handoff are retained.

Installed axes are X lateral, Y up and Z forward. The LM and lower UM front
faces meet at Z18.30 mm. The shared receiver axes, 0.20 mm half-lap clearance,
driver seats and service tie are preserved. Native H2C LM checks verify
both stand states for interference, screw alignment, front-face step and
LM front occlusion. [Interface report](../build/h2c/obiwan_interface_validation.json).

The tweeter axes are 62 mm apart. The lower tweeter axis is approximately
84.57 mm above the MU10 axis. Tweeter depth is 35.8 mm; the UM's projecting
bowl makes the complete body approximately 38.2 mm deep. The tightened
spacing and altered flare/surround require acoustic validation; the shape
alone does not establish directivity or crossover performance.

[Front view](../build/h2c/views/H2C_Dayton_ND25FN4_graded_front.png) ·
[Rear oblique view](../build/h2c/views/H2C_Dayton_ND25FN4_flat_rear_oblique.png) ·
[Original surface and routing evidence](../candidates/nd25fn4_crescent/README.md).
The H2C views use the actual exported geometry, with drivers omitted.

The current catalog reports digital slice qualification separately from
physical qualification. The user has printed an earlier body, but the
H2C hardware/material trial, loaded retention and acoustic qualification
remain pending.

## Source identity and rebuilding

“V4” was the supplied package's revision label, not a separate product name.
Current H2C deliverables use **Dayton ND25FN-4 waveguide** and
`dayton_nd25fn4`. Historical source/archive filenames retain their original
revision strings so the approved input hashes and prior print evidence
remain traceable. The rename does not alter the approved body, cap or
retainer geometry.

The naming/provenance mapping lives in
[`h2c/dayton.py`](../src/lx521_baffle/h2c/dayton.py); the three-family registry
lives in [`tweeter_options.py`](../src/lx521_baffle/tweeter_options.py).
The H2C build produces the continuous matching wings and verifies the
retained meshes against their original sources. From the project root:

```sh
make h2c_prepare
make h2c_validate
make h2c_review
make h2c_docs
```

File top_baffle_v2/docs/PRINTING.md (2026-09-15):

# Printing the top baffle — current selections and earlier PLA reference

For current **H2C / 0.6 HF** files, use the [H2C print catalog](../to_print/h2c/README.md)
and [generated print policies](PRINT_POLICIES.md). The earlier P2S selection
and assembly reference is [BUILD_GUIDE.md](BUILD_GUIDE.md).

ND25FW-4, coaxial BMR, opposed BMR and ND25FN-4 waveguide Obiwan uppers

| Upper family | H2C main prints | Upper hardware / infill |
|---|---|---|
| ND25FW-4 | Stock/Slim vase or regular Obiwan UM + crescent | M4 driver clamp; structural UM 100%, regular crescent 30% |
| TEBM35C10-4 BMR | Stock/Slim opposed vase or regular Obiwan UM + coaxial/opposed crescent | Documented M2 driver hardware exception; use the selected job's policy |
| ND25FN-4 waveguide | Fused Obiwan UM/body + two caps + two M3 retainers | Hanglife M3 × 5 × 4 inserts; 100% UM / 15% tweeter region and accessories; [complete guide](DAYTON_ND25FN4_WAVEGUIDE.md) |

All H2C wings use 10% gyroid and must match the selected upper interface.
ND25FN-4 has separate PETG-GF/PLA and PETG Translucent/PLA Translucent projects.
The project files retain supports, modifiers and measured magnet pauses.

## Earlier 0.4 mm PLA reference

Use
[PETG_GF_QUALIFICATION.md](PETG_GF_QUALIFICATION.md) for current material testing.
The PLA strength calculations below are historical analytical screens, not
physical qualification of the PETG-GF process.

Settings and engineering numbers for printing the piece sets in
Bambu PLA Tough+, PLA Basic, PLA Lite, PLA Matte, or PLA Silk+ on a 0.4 mm
nozzle, for both `build/floor_stand/` and
`build/no_floor_stand/`. Proud-family pieces and the Obi-Wan collars are
covered separately where their geometry diverges. Everything here
combines manufacturer data, published reference tests, conservative
assumptions and analytical screens. None substitutes for owner-specific
coupon and assembly proof. PLA's governing weakness for this job is
**preload creep**.

## Loads and fasteners

Drivers are the LX521.4 production SEAS customs: "W22" rows = the
U22REX/P-SL (H1659-08), "10F" rows = the MU10RB-SL (H1658-04) — same
cutout/pilot geometry, real flanges O220.6 x 6.0 / O98 x 4.0
(owner-measured; see the Obi-Wan recess note below).

The baffle carries ~3.2 kg of drivers: W22 ~2.6 kg on six inserts,
10F 0.43 kg on four, and the ND25 pair ~0.2 kg clamped. Static load per
W22 driver insert is ~5 N against an assumed 600 N conservative pull-out
capacity for an M5 x 5.8 x O6.3 heat-set in PLA (published reference tests:
900-1400 N), so the analytic driver-mount margin is >100x. The Obi-Wan
bridge-web load case is treated explicitly below. PLA still relaxes
30-50 % of bolt preload over the first days.

| Fastener | Spec | Torque | Notes |
|---|---|---|---|
| W22 | M5 x 14 pan + flat washer into M5 x 5.8 x O6.3 heat-set (unchanged 6.8 mm total bore: O6.5 x 2.0 entry, then O6.4) | 0.8–1.0 N·m | Stock, Slim and Obi-Wan share the 0/60/120/180/240/300° clock; wave washers; re-torque at 24 h and ~2 weeks |
| W22 on **Obi-Wan** | **M5 x 12** pan + flat washer into carrier heat-sets | 0.8–1.0 N·m | all six 0/60/120/180/240/300° sites are ordinary blind carrier inserts in both states; each keeps its 6.2 mm total depth and uses an O6.5 x 2.0 entry followed by O6.4; floor mode has no secondary support inserts or long through-screws |
| 10F | M3 x 8 into M3 thread × Ø5 × L4 heat-set (bore O4.6 x 4.0) | 0.30–0.40 N·m | short engagement — do not overdrive |
| Proud bridge (no-stand) | M5 machine screw from the bridge (behind) into M5 x 5.8 x O6.3 heat-set (unchanged 6.8 mm total: O6.5 x 2.0 entry, then O6.4, from the REAR face) | hand-snug | 4 off; same insert as the W22, set from the rear. Stock/Slim use Obi-Wan's exact three-port D20 cable interface relative to these inserts: LM `(-0.35,64.76)`, shared T `(-4.75,55.91)`, UM `(3.17,55.91)`. |
| Proud mid-right-to-vase seam | **M3 x 20 socket-cap**, no washer, through a Ø3.4 radial passage into one M3 thread × Ø5 × L4 heat-set in a blind Ø4.6 x 4.0 vase receiver | hand-snug | axis `(x,z)=(0,12.55)`, +Y from the LM cutout. Ø6.2 x 3.4 head pocket clears a normal D5.5 x H3.0 socket head and hides it completely after W22 installation. Nominal insert engagement 3.381 mm; tip-to-floor margin 0.619 mm. Do not substitute M3 x 25. |
| Obi-Wan LM-to-UM half-laps | 2 x rear-driven M3 screws through the LM's standalone Ø3.4 clearance bores into M3 thread × Ø5 × L4 heat-set inserts installed in the UM's standalone rear-opening Ø4.6 x 4.0 blind receivers | hand-snug | x=±32, y=315.770; the closure-web/base teardrops remain nominal Ø9, while the complete Z-owned cylindrical functional bosses are locally Ø9.8. The UM receivers retain a 1.9 mm acoustic-front floor and the Z-halves retain a 0.20 mm axial gap. Select screw length for full insert engagement without bottoming. No washer, nut, or front bolt head belongs to this interface. |
| Obi-Wan fused bridge plate | four stock holes at (±20,20)/(±20,70), rear-opening unchanged 6.8 mm-total bores with Ø6.5 x 2.0 entries followed by Ø6.4 | hand-snug for fit; final torque only after proof test | no-floor LM only; 62 mm insert core with soft cubic shoulders; LM/T/UM entries packed inside the D20 support opening as LM above, T lower-left, UM lower-right at z=5.3; solid acoustic front; immutable 40 × 50 pattern; no geometry behind the existing LM pads; magnets receive zero load credit |
| Obi-Wan optional LM keyed seam | Ø1.60 pins; right Ø1.80 socket, left 1.84 × 1.80 socket; 0.10 radial / 0.25 end clearance; ≥0.38 radial / ≥0.50 end wall in native ring, no exterior lands | registration only | Current dimensions and 0.6-mm coupon acceptance: [qualification procedure](PETG_GF_QUALIFICATION.md). Driver flange and normal fasteners splice the seam. |
| Regular Obiwan UM-to-tweeter half-laps (ND25FW-4/BMR) | 2 x rear-driven M3 screws through the UM's standalone Ø3.4 clearance bores into M3 thread × Ø5 × L4 heat-set inserts installed in the crescent's standalone rear-opening Ø4.6 x 4.0 blind receivers | hand-snug | x=±24, y=421.5; nominal Ø9 closure-base teardrops, complete local Ø9.8 Z-owned functional bosses, 0.20 mm axial gap, complete 360° receiver walls, and 1.9 mm acoustic-front floors. Install both inserts in the individual crescent before assembly; no front bolt head or cross-owner receiver wall. |
| Regular Obiwan LM/UM alignment magnets | Six D5 × 2 N52 magnets in captive Ø5.20 × 2.10 surface-normal cavities | — | LM has four: preserve the upper ring-radial 64°/116° axes and the lower pair at cubic parameter `u=0.50` on the shared curved shoulder. The right visible datum is `(x,y,z)=(45.285011,89.190370,15.10)` with outward normal `(0.706451,-0.707762)`; the left is its exact X mirror. UM keeps its 50.5°/129.5° axes; all six stations share source Z=15.10. Every station has 0.52 mm axial skins (the dual 0.4/0.6-nozzle single-bead value) and a 45° support-free roof. The R113.0/R51.7 structural rings have continuous exposed R113.94/R52.64 side fairings, clipped only inside the existing LM--UM and T--UM cusp/service regions; the LM--UM stop preserves the 0.40 mm gap. Ring cavity datums sit at structural radius +0.79 mm; ring and shoulder cavity datums are 0.15 mm beneath their exposed surfaces. There is no magnet-local backing, boss, relief, rear cap, flat, or visible cue: the magnet-free exterior is immutable. Magnets are fully buried at the manifest pause, never glued or externally accessible. Flat/graded have matching captive LM-lower, LM-upper, and UM receivers. Their mating surfaces are flush with zero physical air gap; the receiver's 0.05 mm allowance is a solid standoff. Nominal paired magnet-face separation is 1.24 mm at LM-lower, LM-upper, and UM. Alignment/anti-rattle only: **zero structural load credit**. |
| ND25FW-4 tweeter pair | M4 through-bolts + nyloc + wave washer; length = septum + faceplates (stock 18.3 septum → ~M4 x 35; V1/Obi-Wan crescent → ~M4 x 30 — verify stacked) | snug, ~0.5 N·m | clamps the 4.0 mm crescent seat; recheck after a week |
| Optional TEBM35C10-4 BMR pair | 8 × M2 screws into M2 × 4 × Ø3.2 heat-set inserts | hand-snug; establish on a coupon | lower BMR mounts from the acoustic front and upper BMR from the rear; each pocket has a 1.2 mm blind opposite wall. Use the Stock BMR vase only with Stock receivers and the Slim BMR vase only with Slim/V1L receivers. Both print front-face-down with supports explicitly disabled; four same-height captive side magnets share one audited insertion pause. |
| ND25FN-4 waveguide pair | Six M3 × 8 screws and six Hanglife HLTI-M3-001 M3 × 5 × 4 inserts across two retainers | Verify actual engagement; do not bottom out | Ø4.6 × 4 mm printed pilots; fused body has twelve M3 insert sites including MU10 and LM receivers. Separate UM-to-tweeter half-laps are absent. |
| ND25FN-4 upper/wing magnets | Four Ø6 × 3 N45 in body; two matching D6 in each full wing | — | Each full wing also has two Ø5 × 2 N52 LM contacts. Complete winged speaker: eight D6 + eight D5. Install at the selected project’s measured pauses; [assembly guide](DAYTON_ND25FN4_WAVEGUIDE.md). |

**Installing the inserts:** soldering iron at 230–250 °C, press
slowly and square, stop flush. The bores carry +1.0 mm melt room by
design. For the regular UM and separate crescent, before bringing any joint halves together, install both LM-to-UM M3
inserts through the rear/mating openings of the individual UM print and both
UM-to-tweeter M3 inserts through the rear/mating openings of the individual
crescent. Every Ø4.6 x 4.0 receiver must remain fully surrounded by its local
Ø9.8 functional boss and retain its 1.9 mm solid front floor; reject any
insert that cracks, laterally opens, moves, or marks the acoustic face.

For the integrated ND25FN-4 body, use its [insert inventory and assembly
order](DAYTON_ND25FN4_WAVEGUIDE.md#assembly-order): its retainer pilots are
4 mm blind bores and it has no UM-to-crescent half-laps. The regular
joint-boss dimensions above do not describe all twelve body insert sites.

### Obi-Wan structural screens

The fused bridge web and four-hole group use a conservative **4.0 kg**
installed mass, y=230 mm center of mass, and 70 mm rear offset.
Bambu's published XY flexural
strength is 65 MPa for PLA Tough+; this screen deliberately uses much
lower 18 MPa short-duration and 8 MPa sustained allowables for printed
anisotropy, stress concentrations, and creep. The softly blended plate has a
62 mm insert core and occupies z=5.3..18.3, ending at the deepest existing
LM-pad rear datum with no added rear projection. The structural model deducts
the complete Ø9/Ø8.2/Ø6.0 D20-packed entry lumens and credits only a
**38.8 × 13.0 mm** section; exact 0.01 mm sampled cuts retain at least 45.73 mm.
Its in-plane/rear section moduli are **3261.8/1092.9 mm³**. Conservatively
summing the two bending stresses gives about **4.40/13.19/21.99 MPa** and
safety factors **1.82/1.36/0.82** at sustained 1g/8 MPa, transient 3g/18 MPa,
and transient 5g/18 MPa. The physical 68° lower-ring cradle
extends to z=5.3 with the web, but the existing ring lip starts at z=6.8;
the calculation therefore credits only the actual 11.5 mm-deep monolithic
interface. After conservatively deducting one Ø8.2 UM tunnel plus the
complete Ø6.0 tweeter tunnel, its effective width is **118.5 mm**, with
in-plane/rear section moduli of **26908.4/2611.6 mm³** and biaxial safety
factors of approximately **6.37/4.78/2.87**. The combined
normal-plus-rear worst insert reaction is **434.2 N** at 5g, retaining
**1.38** assumed pull-out safety factor. Magnets contribute 0 N. The
material-property reference is the
[Bambu PLA Tough+ data sheet](https://us.store.bambulab.com/products/pla-tough-upgrade?id=624483921975980068).

The floor state has no separate support. Its LM carrier owns a full-depth W64
stem, W64 × 18.3 foot over z=−150..18.3, convex constant-thickness Option-B
transition with a 41 mm minimum centreline radius, three buried lanes and
rear NL8 panel. World floor Y=0 puts the LM axis exactly **200.981 mm** above
the floor. A closed-form rectangle-minus-lumens screen deducts the complete
Ø9 LM, Ø8.2 UM and Ø6 shared-T lane sections from the root and uses the
same 4.0 kg/y=230/rear-offset=70 mm load model:

| Material | Vertical 1g/3g/5g SF | Anchored lateral 1g/3g/5g SF | 1g diagnostic deflection | Result |
|---|---:|---:|---:|---|
| Bambu PLA Tough+ | 3.05 / 1.97 / 1.18 | 4.22 / 2.73 / 1.64 | 1.18 mm | analytical pass |
| Bambu PLA Basic | 4.39 / 2.78 / 1.67 | 6.09 / 3.85 / 2.31 | 1.05 mm | analytical pass |
| Bambu PLA Lite | 2.69 / 1.73 / **1.04** | 3.73 / 2.40 / 1.44 | 1.40 mm | **FAIL at vertical 5g; provisional data** |
| Bambu PLA Matte | 2.78 / 1.79 / 1.08 | 3.85 / 2.49 / 1.49 | 1.49 mm | analytical pass |
| Bambu PLA Silk+ | 3.23 / 2.09 / 1.25 | 4.47 / 2.90 / 1.74 | 1.17 mm | analytical pass |

These use deliberately derated project allowables, not unmodified Bambu
coupon values. PLA Lite is provisional because no product-specific official
TDS was available. Source records are Bambu's
[Tough+ V3](https://store.bblcdn.eu/s8/default/f0874452d01249dba4ab6fc68ca972e4/BambuPLA_Tough_TechnicalData_Sheet_%282%29.pdf),
[Basic V3](https://store.bblcdn.eu/s8/default/073e722a4aa44f7cbfdc419d597475cc/Bambu_PLA_Basic_Technical_Data_Sheet.pdf),
[Matte V3](https://store.bblcdn.eu/s8/default/82bab351a9494e318ab485f7c31a01b3/Bambu_PLA_Matte_Technical_Data_Sheet.pdf),
[Silk+ V1](https://store.bblcdn.eu/s8/default/d0de0f57694b406dbf3e9b2345b7dbb9/Bambu_PLA_Silk__Technical_Data_Sheet.pdf),
and the provisional
[PLA Pure comparison sheet](https://store.bblcdn.com/s7/default/ecb663b46ebb4fb984786d33befb8d2f/PLA_Pure_TDS.pdf)
used as a fail-closed Lite proxy. The screen is **closed-form analytical work, not FEA,
certification, or release authority**. All stresses include an explicit
**1.25 root geometry/model factor**. PLA Lite fails the 1.05 vertical-5g
threshold and is not accepted; the other four meet the 2.0/1.5/1.05 at
1g/3g/5g and ≤2.0 mm at 1g only with the required **100% local-solid modifier
through the complete stem/root**. Sparse infill receives no structural credit.
Magnets and both optional concealed split pins/sockets receive 0 N structural
credit.

The two LM-to-UM insert-fastened ears and the two tweeter-interface ears carry
only the upper assembly, not the LM/stand.
The ledgered 0.43 kg MU + 0.20 kg tweeters plus printed/hardware allowance
gives a **0.85 kg** case over conservative 120 mm plan and 70 mm rear
levers. Both D4.6-receiver interfaces co-govern with contact factors of about
**2.85/2.14/1.28** at 1g/3g/5g; the M3 screw-tension factor is about **1.28**
at 5g. Those numbers are analytical screens, not qualification of either
heat-set installation, receiver wall, or 1.9 mm front floor. Each interface
reaches approximately **393.9 N per insert** in the 5g pullout-demand case
and therefore remains subject to physical pullout qualification. Magnets
contribute 0 N to every
calculation.

These screens cover the modeled bridge/integral-root reactions, minimum
printed transfer sections, ear neck/net/bearing areas and M3 shear. They
do **not** independently qualify the NL8 panel, stock bridge,
installation substrate, real insert process, or a changed print orientation.
Those items remain inside the system proof-test boundary.

They also do not transfer automatically from the canonical monolithic LM to
the optional LM keyed split. Its two concealed Ø1.60 +Y pins and
right-round/left-X-relieved blind sockets are registration aids with no
standalone retention/load credit. The round+relieved pair prevents redundant
pitch constraint. The horizontal pins are four nominal 0.4 mm nozzle widths
and their sockets sit in small exterior lands outside the LM recess. That
print form remains pending until sliced pin/land/wall paths, actual U22 fit,
process-matched fit, full seating, front-datum coplanarity, UM/T route-seam
continuity and cable pull-through, and the complete driver-installed 1g/3g/5g
proof have passed and been recorded.

This calculation is a screening model, not permission to hang drivers
from an untested print. Before service, every final combination of
filament batch, slicer settings, frame, carrier, inserts, and fasteners must
pass a documented physical proof test through the distributed 4 kg
sustained-1g, 3g and 5g bridge/integral-stand cases in the governing normal and
rear-moment directions. The upper joints must simultaneously carry their
actual 0.85 kg distributed mass at the stated lever arms.
Prefer a dummy mass rather than valuable drivers. Apply **39.23 / 117.68 /
196.13 N** (4/12/20 kgf equivalent) through the modeled center of mass,
including its 230 mm
plan coordinate and 70 mm rear offset; simply hanging 4 kg at a mount
does not reproduce the screened moments. Record load, fixture, duration,
temperature, deflection, insert motion, cracks, and post-test torque.
Ramp each load over at least 10 s; hold sustained 1g for 24 h, 3g for
60 s, and 5g for 10 s before the unloaded inspection; reject any
permanent movement or damage. The integral floor candidate must additionally
hold **2× service load for 24 h at 35 °C**, with no crack or whitening and
unloaded residual set no greater than **0.5 mm or 10% of loaded deflection**,
then hold **1.5× service load for at least 168 h** for the creep gate.
Record the exact per-state candidate identity, print/insert process,
fixture, load history, temperature, deflection, damage inspection and
release signoff in `obiwan_physical_qualification.md`.

**Temperature limit:** Bambu publishes a **61 °C heat-deflection
temperature (0.45 MPa)** for PLA Tough+; that is not a guaranteed Tg or
an assembly service rating. Indoors near room temperature is the only
condition screened here.
Direct summer sun on a dark baffle or a closed car will creep the W22
mounts, bridge-web interface, and tweeter clamp. The safety factors above are
room-temperature values and are invalid near 60 °C. If the speakers may
see elevated temperatures, choose a suitable material before printing
and repeat the structural proof test at the actual maximum service
temperature; substituting PETG/ASA does not preserve the PLA calculation
automatically.

**Anti-tip is mandatory.** The W64 foot reaches material-strength limits only
after the assembly has already become unstable: calculated free-standing tip
thresholds are about **0.139g lateral, 0.348g rearward, and 0.384g forward**.
Install a positively attached tether or anchor before fitting valuable
drivers or putting the speaker into service. The foot and magnets are not a
safety restraint.

## Orientation — the setting that matters most

**Proud family:** print every baffle piece front face down. The front plane is
the reliable datum while V1/V1L sculpt or step the rear. For the
floor-stand `piece_bottom` (223.8 × 125 × 168.3), front-down leaves the
150 mm foot rising as a self-standing wall. Smooth/satin PEI gives a
clean front; textured PEI gives uniform grain.

Current LM registration: Ø1.60 pins at x=±108.920904, z=14.30 mm, 2.40 mm engagement and 0.50 mm root overlap. Right socket Ø1.80; left 1.84 × 1.80 mm with 0.02 mm X relief per side. Radial clearance 0.10 mm, blind-end clearance 0.25 mm, pitch 217.841807 mm. The native ring retains ≥0.38 mm radial and ≥0.50 mm blind-end wall without exterior lands. Preserve lumens, driver/recess and wing clearance; verify the 0.6 mm GF toolpaths and the actual coupon/full assembly. The pins register only; the driver flange and normal LM fasteners complete the load path. See [the current qualification procedure](PETG_GF_QUALIFICATION.md).

For the keyed split, the shelf also provides the mutually exclusive
`obiwan_01_02_03_04_LM_UM_combo_no_floor_stand` and
`obiwan_01_02_03_04_LM_UM_combo_floor_stand` single-plate alternatives to
the corresponding four individual 01/02/03/04 projects. They do not
regenerate or fuse geometry: four released, same-state front-down STLs are
translated to locked positions inside one Bambu object. Each project carries
the three released state-specific duct blockers, all four support fields
pinned globally and per object, and one six-magnet pause at Z=5.96 mm. Both
combined core projects use the hash-pinned saved TINMORRY PETG-GF preset and
six walls. Both projects print 100% zig-zag: the floor project always did,
to preserve its integral-floor bottom's contract, and the no-floor project was
raised from 40% gyroid to match, which leaves its 100%-solid zig-zag parameter
modifier through the complete `01a` bridge/root redundant rather than wrong.
Promotion requires exact four-volume (no-floor) or five-volume (floor, including lid)
project/STL equivalence, actual support under every carrier, no support under
the tweeter footprint, and zero support-bead collisions against every LM/UM
functional duct. Never print a combined plate with its individual 01, 02, 03,
or 04 files, and never mix the two stand states.

**Support may not be sealed into a blind pocket, and the blockers now cover
the joint ears.** Printed front-face-down, the M3 joint receivers open toward
the plate, so `support_on_build_plate_only` does not protect them. Measured
on the four-piece core plate, each of the six D4.6 ears carried a support
column fully enclosed on every layer from Z 7.08 to 12.20 mm -- 5.1 mm of
PETG welded to PETG exactly where a heat-set insert goes. The duct and
cavity audits could not see it: they check named geometry, and nothing named
the bores. `obiwan_support_blocker.py` now emits one tool per ear over the
whole joint span, alongside the duct tools it always had.

Two things follow. Support type is back to `normal(auto)` + `snug`: tree at
a 1 mm branch distance drove 139_325 support extrusions into closed pockets
against 14_307 for normal -- ten times the material packed into those bores,
because tree branches lean into cavities while normal support projects
straight down -- and it cost 2.6 h of print time. And
`_enclosed_support_audit` in `artifact_emit.py` measures the shape directly
rather than trusting names: at each layer it marks where the part extrudes,
then asks of every support point whether part material exists on both sides
in X *and* Y. Both plate builders fail closed on it, bounding the height of
a fully-enclosed run (3 mm) and the bulk of enclosed support relative to the
part's own extrusion count (0.06). The first bound catches a packed bore,
the second catches tree-style bulk; the tree and normal slices measured
0.187 and 0.019 respectively.

**The wing combo plates print PETG-GF too, and they are ordinary ready-to-
print deliveries.** `make obiwan_petg_wing_plates` slices both split2 wing
plates -- flat and graded, four pieces and one six-magnet pause each -- into
`to_print/obiwan/3mf_06hf_petg-gf/`. The wings print support-off by their own
contract: their profile,
`captive_magnet_slicing_profile_petg_gf_wings_06hf.json`, carries no support
recipe and therefore no PLA interface filament, so one filament is loaded
and the CLI slices normally. Each profile is scoped by `artifact_scope` to
the artifacts it may print -- six structural pieces, eight split2 wing
pieces, disjoint -- and `build_obiwan_wing_plate.py` now enforces that
scope, which it previously did not: the structural profile could be pointed
at a wing plate and would slice it under a support recipe the wings never
wanted.

**Flow ceilings come from TINMORRY's own profile, mirrored into both
variant columns.** Their store page states 240--270 °C, a 65--75 °C bed and
"< 250 mm/s", but no volumetric figure; the authoritative numbers live in
their Bambu profile, vendored verbatim with its hash under
`vendor/TINMORRY/` (see that directory's `PROVENANCE.md`). Every filament
value there is a two-slot vector -- Standard variant, then High Flow -- and
TINMORRY filled only the Standard slot, leaving High Flow as `nil` so it
inherits `Generic PETG-CF @BBL P2S`: 11.5 mm³/s, 255 °C and a 0.95 flow
ratio, none of it measured on this material. Because the lane pins the
hotend to High Flow, that is exactly the column being selected, so
`repo_overrides.filament` mirrors the vendor's Standard figures into both
slots: 12 mm³/s, 260 °C, 0.93 flow ratio. Do not read the ceiling as a
speed lever -- 12 is 4% above the 11.5 it replaces, worth 116 → 121 mm/s at
0.62 × 0.16 mm. Wall count, infill density and support density set the
print time.

**PETG-GF + PLA mapping is normalized and checked against actual extrusion.**
The shared adapter completes all four per-filament map vectors, pins High
Flow and sizes the purge matrix for the loaded materials. Native slices now
produce GF model/support paths and PLA contact paths. Changing only the
variant fields is insufficient. The regular core shelf still supplies
unsliced GUI projects; use the slice audit after exporting them. See
[generated print policies](PRINT_POLICIES.md) for the recipe, exceptions,
source ownership and the linked Bambu issue. Slicer exit status alone does
not establish correct material use.

For the flat and graded B wing splits, the shelf also provides
`obiwan_flat_wings_split2_combo` and
`obiwan_graded_wings_split2_combo` as mutually exclusive single-plate
alternatives to their four individual B projects. Each rigidly rotates and
translates the four exact released front-face-down STLs without
regenerating, changing, or fusing their geometry. The locked footprint is
248.813 × 248.815 mm on the 256 mm bed, with 3.587 mm minimum inter-part gap
and 3.592 mm minimum edge clearance. Use the ready project: it has 10% gyroid,
all four support fields pinned off globally and per object, zero support
feature blocks, and one Z=5.96 mm pause for all six wing magnets. Promotion
requires exact 3MF/STL equivalence (15,692 triangles for flat; 958,546 for graded),
an identity outer
placement, and passing toolpath audits for all four captive-cavity regions.
Never print either plate together with its four individual B files.
Flat/graded wings and shoulders do not carry the LM/UM cantilever load.
PLA Basic is the standard wing/shoulder lane; the two wing combos also have
a separate support-free PETG-GF lane. Do not apply the structural-core
support recipe to wings.

The UM route is covered only in LM, T is covered in
LM/UM, and their specified rear continuations are free; the short LM lead is
also intentionally free inside a rear-open subtractive clearance, not a
printed micro-duct. Keep generated support out of functional buried-route
mouths/free-cable clearance, the NL8 service cavity, and every rear bump.

Every released nonpolar STL—including all ten production coupons and every
flat/graded segment—must travel with its exact adjacent `<stem>.print.json`. That
record hash-binds the mesh to its X180 plus optional in-bed-Z transform and
origin translation. Treat a missing, extra/orphaned, hash-stale, tilted, or
translation-inconsistent sidecar as a hard stop; run `scripts/check_manifold.py` on
the release STL directory before slicing. Do not substitute a sidecar from
another state or a similarly named piece.

## Bambu Studio profile (0.4 nozzle)

The settings below are the general structural profile. For every captive-
magnet part, the authoritative pause audit overrides the general layer height:
use the pinned **P2S 0.4 mm / 0.16 mm High Quality / Arachne wall** profile and
the exact first-closing-layer Z values in the generated pause manifest. Do not
reuse a 0.20-mm pause height or derive one by scaling.

* **Layer height:** **0.16 mm** for every generated captive-magnet job.
* **Walls: 6 loops maximum** (2.4 mm where geometry permits) for ordinary
  parts. Both standalone Obi-Wan keyed LM bottoms (`01a` no-floor and `01b`
  floor) and both combined `01+02+03+04` core plates use **8 loops** under
  their PETG-GF structural profile. The wall setting makes the material
  around every insert bore, dovetail key, and knife edge fully solid.
  Every 0.52 mm captive-magnet retaining skin is the exception: Arachne must
  slice it as exactly one bounded variable-width bead/traversal, never six
  paths. *Detect thin wall: on* remains pinned and the actual toolpath is
  audited independently. Transverse skin widths have a nominal
  0.42--0.78 mm bound (0.78 is the inset/curved-face wedge ceiling; the
  per-lane pinned Arachne minimum bead — 100% of nozzle at 0.4 mm, 85%
  at 0.6 mm — keeps every wedge a single bead); the audit permits only a 0.005 mm lower-side Arachne
  tolerance (effective floor 0.415 mm), and the pinned release reaches
  0.415656 mm at its narrowest path. The orthogonal 0.45 mm-era coupon spacing was
  deterministically 0.484336 mm at 0.16 mm layers; angled Obi-Wan LM/UM skins
  reached 0.586 mm and the legacy V1 adaptive inner bead reached the full-run
  maximum of 0.661027 mm. The audit selects a skin by its cavity-facing bead
  edge within 0.06 mm of nominal, then still requires exactly one path in
  every scan bin; a secondary overlapping-path guard rejects anything except
  the bounded same-path V1 edge return. Each transverse station must retain at least 2.0 mm of
  path-width-aware free loading slot (observed full-run range
  2.047--2.083 mm). Axial skin widths remain nominally 0.42--0.65 mm with only
  a 0.000005 mm lower serialization tolerance (observed maximum 0.631 mm), and
  only while the sliced loading aperture remains
  at least D5.0. A two-component axial ring is accepted only as two long,
  non-overlapping cyclic intervals with complementary ray coverage and
  endpoint-local seam anomalies whose two physical junctions retain bead-
  footprint contact within the 0.52 mm connectivity cap—not as disconnected
  arcs or a full ring plus a stray path.
  Top/bottom **6/5** layers; *Ensure vertical shell thickness: All*.
* **Infill:** gyroid, **30 %** for proud mids/vase and the Obi-Wan collars,
  **40 % for the proud piece_bottom in both stand states** (foot standing
  moment ~8 N·m, or bridge bolts), and **40 % for the Obi-Wan fused bridge
  web and tweeter crescent/direct joint ears**. For the no-floor Obi-Wan
  `01a`, use six walls and a **100% local-solid modifier** through the
  complete W64 stem/root; do not depend on nominal infill through the root or around
  the three buried lanes. *Detect narrow internal solid
  infill: on.* The generated job embeds and audits that **100% zig-zag
  parameter modifier**, and now runs global **100% zig-zag** as well, so the
  modifier pins the root region to what the whole part already prints. The
  integral-floor keyed-bottom job always used global **100% zig-zag**; note
  that zig-zag rather than gyroid is mandatory at 100%, because Bambu
  rejects gyroid at that density.
* **Support:** off for every job except both optional keyed LM halves and the
  UM carrier in both floor states. Those generated projects pin **Enable
  support: on**,
  **On build plate only: on**, **Support critical regions only: on**, and
  **Remove small overhangs: on**, both globally and per object. Each project
  embeds a hash-bound blocker over every functional duct segment owned by that
  carrier. Do not broaden support manually: promotion requires a zero-collision
  audit between deposited support beads and the functional duct volumes.
  Bambu Studio's `floating cantilever` warning is a hard release failure even
  though the CLI describes it as non-critical.
  Every other generated project pins the same four settings off globally and
  per object, then verifies that its G-code emits no support feature.
* **Strength tuning:** nozzle 225 °C (top-middle of the Tough range —
  hotter = better layer adhesion), bed 55–60 °C, **max fan 60 %**
  (overhang fan 100 %), outer wall <=120 mm/s, keep the filament
  profile's volumetric limit (~12–16 mm³/s). Strength lives in layer
  adhesion, not speed. The PETG-GF structural-core jobs instead use the
  vendor's own figures, taken from TINMORRY's Bambu profile at
  <https://github.com/TINMORRY/TINMORRY-filament-profile-for-Bambu-printers>
  and vendored with its hash under `vendor/TINMORRY/` — 260 °C nozzle, 80 °C
  textured bed, 0.93 flow ratio, and 12 mm³/s maximum volumetric speed. Do
  not copy this material/profile to flat/graded wings or shoulders.
* **Dimensional fits:** proud regular through-thickness dovetails use 0.05 mm
  in-plan female clearance; tune compensation until coupon 2 slides snugly
  through coupon 1 without forcing the seam open. Insert bores
  are nominal. Use *Precise wall: on*, **elephant-foot compensation
  0.15 mm**, and start X-Y hole compensation at **+0.05** for general fit
  coupons only. Captive-magnet artifacts require **0.00 mm**: +0.05 mm was
  observed to delete the then-0.45 mm retaining skin.

### Captive-magnet pause procedure

All released magnet-bearing parts print **front-face-down**. The approved
system encloses each actual D5.0 × 2.0 disc in an Ø5.20 × 2.10 cavity with
0.52 mm plastic at each axial face, a vertically open loading cradle, and a
self-supporting 45° roof. There is no magnet glue and no external access
opening. Stock, slim, and Obi-Wan paired transverse stations all use source
Z=**15.10 mm**. Their magnet-free exterior is immutable: no cavity operation
may add a local backing, boss, relief, rear cap, flat, or visible pocket cue.
The mating surfaces are flush with **0 mm physical air gap**. The receiver's
0.05 mm allowance is a solid internal spacing standoff, not an air-gap cutter.
Stock lower stations are therefore **1.09 mm** apart. The `standard_curved`
upper base datum is recessed 0.14 mm inside
the unchanged host, giving **1.23 mm**. Obi-Wan LM-upper and UM ring datums are
0.15 mm beneath their smooth carrier fairings, and the Obi-Wan LM-lower datum
is 0.15 mm beneath its smooth shared shoulder; all three interfaces therefore
give **1.24 mm** to matching flat/graded receivers. The slim upper station is
contained by a broad, symmetric,
smooth rear-taper shelf rather than a local magnet-shaped patch. The D5 × 2
cavities and both 0.52 mm Arachne one-bead skins are unchanged.

Use the exact part/variant rows in
[`CAPTIVE_MAGNET_PAUSE_MANIFEST.md`](../review/captive_magnet_slice_audit/CAPTIVE_MAGNET_PAUSE_MANIFEST.md). Pause at the listed
Bambu Studio marker—the first layer whose toolpath begins closing the roof,
after the last completely open layer—not at a height inferred from CAD alone.
Before starting, mark one pole of every magnet and stage each site in manifest
order. At the pause:

1. From above the paused part (its print +Z side), insert exactly the listed
   count vertically downward along print -Z
   (`print_insertion_direction_xyz = [0, 0, -1]`), with the listed
   local-axis polarity.
2. Confirm every disc lies fully seated below the completed layer and cannot
   protrude into the next-layer nozzle path.
3. Remove tools and loose magnets from the build volume, then resume.

Polarity cannot be inspected or corrected after burial. Mirrored parts do not
automatically use the same visible face. The physically validated coupon
regression for the P2S 0.4 mm nozzle / 0.16 mm profile is the common
**LM/UM Z=5.96 mm** marker; never reuse it for a different geometry or
orientation. V0 also prints front-face-down. Its legacy orphan sites at
`(±46.000, 324.000)` were completely detached from the B2 flare, so—there
being no released mate—the first correction moved both to
`(±37.697, 326.470)`. Do not use that interim pair: the left station violated
the T-route rule, while the outboard right land required a visible rear-bevel
backfill. The release uses symmetric **`(±6.690, 321.290)`** centres below the
D82 cutout and between the seam-B integral-joint stations. The minimum qualified residuals
across the pair are 1.088 mm beyond the cutout rule, 12.847 mm beyond the
nearest-pilot rule, 1.089 mm beyond the grown seam rule, and 18.579 mm beyond
every route rule. Each complete R3.20 land already exists in the immutable
post-bevel host; the cavity operation adds no local keep, backing, boss, rear
block, or visible location cue. The rear axes, 45° conical closures, both
0.52 mm skins, and provisional marked-pole directions remain unchanged. V0
still has no released mating part or pairing polarity.

The floor and no-floor canonical Obi-Wan LM monoliths intentionally have no P2S
pause rows: neither fits the bed front-face-down. The manifest identifies each
as not P2S-printable and binds its four source-identical cavity contracts to
the same-state keyed bottom/top halves. Use only the actual keyed-half pause
rows on a P2S. A monolith proxy-coverage row is not a G-code pause and must
never be entered manually in Bambu Studio.

Print the applicable stable `stl/lx521_coupon_*.stl` files before the
large parts:

1. `lx521_coupon_1_fit_plate.stl` — clearance-grown regular female dovetail,
   stepped M5 bore (Ø6.5 for the first 2.0 mm, then Ø6.4 to the unchanged
   6.8 mm total depth), Ø4.6 insert bore, and the released
   V1-upper captive-magnet regression station. Print
   it front-face-down and use the exact pause generated for its own sliced
   G-code; its former exposed-pocket inspection notch has been deleted so the
   45° roof retains the full post-apex seal. This is an **unpaired** regression
   station: install the marked/N pole along source -Y, which is print +Y under
   its X180/Z0 transform. There is no mating magnet and no attraction claim.
2. `lx521_coupon_2_fit_key.stl` — matching loose full-thickness male dovetail.
   It contains no magnet and does not define a polarity pair with coupon 1.
3. `lx521_coupon_3_fish_entry.stl` — no-foot entry cluster and Ø6.8
   tweeter-pair merge.
4. `lx521_coupon_4_um_outlet_proud.stl` — the real B2 outline and the
   complete stock B2/V1 proud Ø8.2/G1/R14 rear outlet at
   (33.446, 301.492). It does **not** represent the keyed V1L outlet.
5. `lx521_coupon_5_fish_ts_dive.stl` — proud-family tweeter notch
   passage.
6. `lx521_coupon_6_fish_foot.stl` — stand-foot R14 elbow pair.
7. `lx521_coupon_7_recess_seat.stl` — actual Obi-Wan LM-core seat sector
   and rear insert pad.
   Put the U22 cone-up on its magnet and
   lower the coupon front-face-down over the flange edge; check
   face-to-flange level with a straightedge, then perform the real
   M5×12 insert/pad clamp test.
8. `lx521_coupon_8_fish_ts_oval_proud.stl` — complete proud-family
   round-to-oval tweeter passage; dry-fish both AWG24 pairs.
9. `lx521_coupon_9_um_faston_clocking.stl` — D104 gauge marking the
   238/328-degree mounting screws and their 283-degree terminal
   midpoint. Place it against the physical MU and record where the
   actual tabs, boots, and carrier land.
12. `lx521_coupon_12_obiwan_closed_bore_bump.stl` — state-specific Obi-Wan
    LM-collar sector around the 300° axis, including the enclosed tunnel and
    full-width solid saddle from conduit roof to the ordinary blind insert
    floor; there is no trapped hollow and no cable is exposed.

Before any captive-magnet production run, also print and slice the dedicated
reference in `coupons/obiwan_ae_embed/`. Its source and README define the proven
cradle/skin/roof implementation and the common 5.96 mm regression marker.
The proud family uses a short curved split grommet that follows the final R14 bore;
print `stock_um_grommet_half_{a,b}.stl` and test it with
coupon 4. That grommet fits B2/C7/V0/V1 only; do not fit it to V1L.
V1L has no separate coupon in this set: its printed `mid_right` is the
dry-fishing and physical service-fit article for the 283-degree exit.
Use `slim_um_grommet_half_{a,b}.stl`, not the proud
halves. The V1L TPU insert follows the keyed R14 with a Ø8 body around a
Ø7.1 bore, enters 2.5 mm, and seats its Ø13 × 2 flange on the z=6.8 rear
face. Test both halves around the measured cable and in the printed
`mid_right`; the analytic model clears the Faston motion box, but the
real terminals and boots remain the release gate.
Obi-Wan has no printed grommet or tunnel clip. Any selected external cable
retention remains **physical-fit pending** and must clear the buried-route
mouth, free cable, driver and Faston service envelopes with the measured UM cable.

* **Proud internal voids:** the cable ducts (Ø3.8–9.3, arched ceilings)
  self-support on the flat pieces. For the floor-stand bottom, preview
  the connector channel's ~38 mm ceiling. The generated projects keep support
  disabled; they are rejected if any support feature is emitted. If a future
  revision enables support, it must first add a hash-bound blocker for every
  duct and pass the support-toolpath-versus-duct collision gate.
* **Obi-Wan collar recesses (front-down = seat floor is a ceiling over
  the bed):** the LM and UM annuli bridge 6.0 / 4.0 mm above the bed.
  Use the generated, audited project rather than repainting support. Its
  remove-small-overhang/critical-region/build-plate-only policy and embedded
  duct blockers are part of the release contract. The seat surface is a
  supported face: expect ±0.1–0.2 roughness — the drivers hide it,
  but FLUSHNESS depends on the real seat depth. Print coupon block
  **7_recess_seat** first, drop the actual driver flange edge into
  it, and caliper front-face-to-flange: adjust `LM_FLANGE_T_MM` /
  `UM_FLANGE_T_MM` in `src/lx521_baffle/flush.py` and rebuild if
  either sits proud or sunk. The datasheets disagree with the measured
  thicknesses (U22 drawing 5.5±0.2 vs 6.0 measured; MU10 drawing
  5.4±0.2 vs 4.0 measured), so re-measure both physical flanges. The
  mirrored Ø6 tweeter tunnel runs in the rear web and does not
  reduce the flush seating surface.
* **Obi-Wan routes:** preview the physical Ø7.0 UM cable inside its Ø8.2
  LM-owned passage and the Ø5.2 T cable inside its Ø6.0 LM/UM-owned passage
  at fine layer resolution. The UM cable must run free behind the UM carrier
  with no printed rear duct; T must run free behind the tweeter crescent with
  no crescent-owned printed arc. The true minimum non-load wall on each
  surviving buried span is 0.8 mm and the seat roof is 0.85 mm. In no-floor
  state verify all three LM/T/UM entries are open inside the D20 support
  opening, with LM above, T lower-left, and UM lower-right. Pull the D7.8 LM
  reference through its nominal Ø9 branch and common R14 handoff; in floor
  state verify the corresponding buried Ø9 continuation through the integral
  stem. Confirm the LM-owned UM/T lumens finish at R112.95 and their covers at
  R113.75 beneath the uninterrupted R113.8 carrier exterior, retaining a
  0.85 mm solid outside skin with no groove. Block support from every
  functional mouth/free-cable span and
  inspect the complete solid-backed rear bumps. Use the routing PNG's nominal
  diametric u-z sections—not only its longitudinal station plot—to confirm each
  conduit roof is joined solidly to its blind-bore floor. Verify the 82.95°
  physical crown crossing has T above UM and retains the 2.00 mm
  physical-cable gap; there is no two-duct separator web to inspect. Then
  follow T around the covered 328°/58° UM-carrier bumps to its flush exit,
  after which it remains free behind the crescent. All six LM insert bypasses
  retain ordinary blind-bore floors and all surrounding saddle material
  remains solid. Any support strand
  left in a tunnel reduces cable space. Measure the actual cables before
  relying on a retainer or strain relief.
* **Obi-Wan terminal gate:** do not treat the STEP proxy as hardware CAD.
  Use coupon 9 and the real MU driver to verify the 283-degree clock,
  tab/boot volume, polarity order, and real withdrawal direction before
  printing the UM collar and any nearby add-ons. There is no printed
  UM-carrier rear duct or D82 mouth: the free cable follows the modeled R15
  approach to that immutable service axis with a clockwise circumferential
  193° tangent, then continues exact-G1 through R20. The fit
  STEP's closed Ø98/Ø80/Ø60 body keep-out proves clearance to the known
  terminal-less body, but cannot prove the omitted tabs. Its W22 keepout
  records a conservative proxy placement from hash-pinned
  `E0022_W22EX001.stp` SHA-256
  `7fc2be551c86006e11c32a570b046772987cb86dcf65350f77c6e34709aa5ab6`,
  using +90° about X and translation `(0,200.981,-47.498931)`: native +Y
  maps to world +Z, native +Z maps to world -Y, and native max-Y lands at
  front z=18.3. The cached native bounds map to world
  `(-110.5,90.481,-84.498931)..(110.5,311.481,18.3)`. The guarded W22
  geometry phase imports that exact STEP, verifies the transform/bounds, and
  proves the stepped proxy contains it. This still does not qualify the
  installed custom U22 or any leads.
  `PHYSICAL_MEASURE_REQUIRED = True`. The 12 mm maximum modeled pull
  equals the provisional exposed-tab length, so it has zero positive
  release overtravel margin and qualification remains pending.
  Complete `obiwan_physical_qualification.md` against the real hardware and
  structural proof loads for each stand state; the pending record is
  checksum-bound into generated candidate manifests but authorizes no release.
* **Proud seam:** align it on the outline's rear/hidden edges —
  keep it off the V0/C7 knife bevels and the front perimeter.
* **Proud floor-stand foot junction (required):** the foot meets the plate
  at a SHARP 90° inside corner with no gusset (the duct elbows own the
  corner interior), and printed front-down the joint loads layer
  adhesion in tension with a x2-3 stress concentration. At 30-40 %
  infill a hard knock or carrying the speaker by the baffle peaks the
  corner near the layer-adhesion limit. Fix in the slicer: add a
  **height-range modifier over print-z 12-32 mm with 100 % infill**
  (Bambu Studio: right-click the part > Add height range). That makes
  the joint cross-section solid (~5x the bending margin) for ~60 g.
  Handle the finished speaker by the FOOT, not the baffle top.

## Polar-index base (measurement turntable)

`build/floor_stand/stl/lx521_polar_base_{1of2_base,2of2_rotor}.stl`: print
both flat, no supports, PLA+ (30 % infill, 4-5 walls). The rotor's
fenced pocket takes the foot's floor footprint (0.4/side clearance;
NL8 plug gap at the rear); the base's two flex-arm noses click into
the rotor's 72-socket underside ring: 5-deg steps, firmer at the
10-deg majors, scale readable against the rotor's front notch. The
rotation axis sits 84.15 mm behind the front baffle plane (footprint
center — stability over eccentricity); correct per-angle mic distance
in post with r = 84.15 if you want absolute polars, or ignore it for
variant-vs-variant comparisons (identical bias). Double-side tape the
base to the stand; mark tape position for cross-session repeats.

These are non-acoustic measurement-jig parts with no baffle/front-face datum;
they are outside the acoustic build-plate texture contract. Do not X180 either
jig part: that would put the base spigot/detent noses or rotor fence into the
build plate. Accordingly these two floor-only polar STLs are the sole release
exception and intentionally have no `.print.json` sidecars.

## Cable fishing protocol

### Proud family

1. **Dry-fish each piece immediately after printing.** Every duct is
   open at a seam, so a collapsed segment should cost one piece rather
   than an assembled baffle.
2. **Thread during glue-up.** Keep `mid_right` front-face-down on a flat datum;
   slide `mid_left` along local Z to engage seam C, then engage the bottom's
   four seam-A males and lower the vase's two female seam-B pockets onto the
   mid-piece males. The regular dovetails align mating duct mouths while the
   crossings retain funnel relief. Never flex a tooth sideways.
3. Use ~1.5 mm nylon trimmer line or a guitar string as the leader,
   soldered and heat-shrunk to the pair; do not create a taped lump.
   The LM bundle remains the tightest nominal fit. Use only a
   plastic-safe dry lubricant or a small amount of silicone grease.
4. In floor-stand form, fish T2 first (the higher z=9.5 feeder), then T1
   beside it through the shared Ø6.8 step. In no-floor form, both pairs use
   the one Ø6 rear mouth at `(-4.75,55.91)`, matching Obi-Wan; pull them
   sequentially through that shared trunk rather than looking for the deleted
   legacy second T entry.
5. For B2/C7/V0/V1, dry-fish
   `lx521_coupon_4_um_outlet_proud.stl` with the actual UM cable. The
   route is Ø8.2 from main through its G1 R14 rear turn, so the estimated
   Ø7 cable has 0.6 mm nominal radial slack and no discrete corner. Then
   rehearse the snug LM segment and the second tweeter pair through the
   merge.
6. For V1L, dry-fish the actual printed `piece_mid_right`; coupon 4 and
   its curved R14 grommet are the wrong geometry. Verify that the
   physical aperture is centered at Q=(13.497063, 307.618796, 6.8),
   radius 60.0 mm on the 283-degree terminal axis. The nominal cutter
   continues outside to (11.080158, 308.797599, −2.0); do not use that
   endpoint as the aperture center. Rehearse the measured cable, edge
   protection, dedicated V1L split TPU grommet, service loop, boots, and
   physically measured Faston withdrawal against the real MU. Install the two grommet
   halves only after the cable passes the dry-fishing rehearsal. The
   tail is wholly in `piece_mid_right`, so no special fishing or
   modification of the top/vase is required.

### Obi-Wan

Obi-Wan has a UM passage buried only in LM, a T passage buried in LM/UM, free
rear spans behind UM and the tweeter crescent, and a separate un-ducted LM
lead. Rehearse every cable before the drivers or optional modules hide the
working area:

Before cable fishing, install the two LM-to-UM inserts in the standalone UM
carrier, then dry-assemble LM, UM, and the tweeter crescent on one flat
front-face datum. The complementary full-depth junction webs must meet
with only their designed fit seams; reject a visible triangular/cusp void,
front step, thin membrane, or enclosed pocket at either LM–UM or T–UM. The
central T free-cable mouth is intentional and must remain unobstructed. At
x=±32, verify that each LM Ø3.4 passage is open in the individual LM print,
each UM Ø4.6 x 4.0 receiver is fully enclosed by its local Ø9.8 functional
boss in the individual UM print, and the UM acoustic face remains closed by its
1.9 mm floor.

1. Place the measured D7.8 LM cable over the modeled 20.15 mm free span at 269.5°
   behind the carrier; do not add a printed micro-duct. Confirm it seats in the
   rear-open subtractive clearance, remains clear of the LM/web and, in floor
   state, pulls freely through its Ø9 buried
   integral-stem continuation. Add external retention that does not refill
   the modeled clearance or load the cable termination.
2. In no-floor mode, begin the UM cable at the centered bridge rear mouth
   `(5,82,5.3)`; floor mode begins in the Ø8.2 buried stem lane. Fish it through
   each covered LM-owned pad bump, then let it exit to a free span behind the
   UM carrier. Confirm the UM carrier has no printed rear duct or D82 mouth.
   Keep the free Ø7.0 cable below the physical crown crossing, follow its R15
   terminal approach to the 283° reference, and continue through R20 to
   the named Y breakout. Verify its 4 mm-long OD8 collar and both OD4
   branches fit, then verify the provisional Ø3.2/R8 slack leads enter
   their own low-profile flag Fastons. Exercise one connector at a time at
   0/3/6/9/12 mm while the other stays installed, without loading either
   tab.
3. In no-floor mode, begin the tweeter bundle at `(-5,82,5.3)`; floor mode
   begins in the Ø6 buried stem lane. Fish it through the crown above the UM
   cable and the covered 328°/58° pilot bumps. Confirm the LM-to-UM T
   ownership mouths are flush, then let T exit the UM-owned passage and run
   free behind the tweeter crescent. The crescent has no printed cable arc,
   conduit, socket, or horn. If the crescent is used, position the free cable
   before bolting the direct ears at x=±24, y=421.5; do not trap it behind the
   blind-M3 joint.
4. Obi-Wan has no printed UM grommet. Fit only the selected external cable
   retention after successful dry-fishing, and keep it out of the buried-route
   mouths, free cable paths, and Faston pull envelope.

The CAD proxy assumes non-overlapping 8.5 mm receptacles and 9.5 mm
low-profile flag boots at 11 mm pitch. `PHYSICAL_MEASURE_REQUIRED` remains
true because the MU mesh omits the terminals. Connect physical hardware
only after measuring those widths, terminal clock, polarity order, flag
orientation, cable and Y-breakout fit, and pull-off stroke. The 12 mm
modeled endpoint is equal to the provisional 12 mm exposed tab and has no
positive release overtravel; it is not proof of disengagement. Oversize
straight boots are not equivalent: choose a measured compatible flag
connector or revise the service geometry.

## Assembly notes that interact with the material

### Proud family

* Glue the seams with 5–30 min **epoxy** (open time to seat the
  dovetail keys). Magnets are not glued: they must already be captive under
  their printed roofs using the manifest pause procedure above. No solvent
  bonding — PLA ignores acetone.
* After the first loud listening session, re-torque all driver screws
  once — that is when the PLA under the flanges finishes settling.
* For V1/V1L: knock-test the assembled trunk before trusting the W22
  on the 11.5 mm section long-term. At ~25 % of stock bending
  stiffness the bridge or integral stand remains important.
* For V1L specifically: inspect and dry-fish its keyed 283-degree outlet
  before seam glue or driver installation. The real MU terminal tabs are
  absent from the reference mesh, so the physical Fastons, boots,
  removal stroke, cable, and dedicated V1L split grommet remain
  mandatory release checks even when the analytic route checks pass.

### Obi-Wan barebone

Before hardware assembly, inspect
`obiwan_split.step` for the mandatory core,
`obiwan_lm_split.step` if the optional two-print LM form is
selected,
`obiwan_attachments.step` for the selected printed
modules, and `obiwan_assembled.step` with
`um_fit.step` for the service keep-clear. The last
two contain reference geometry and are not an instruction to print the
Faston proxy.

Current LM registration: Ø1.60 pins at x=±108.920904, z=14.30 mm, 2.40 mm engagement and 0.50 mm root overlap. Right socket Ø1.80; left 1.84 × 1.80 mm with 0.02 mm X relief per side. Radial clearance 0.10 mm, blind-end clearance 0.25 mm, pitch 217.841807 mm. The native ring retains ≥0.38 mm radial and ≥0.50 mm blind-end wall without exterior lands. Preserve lumens, driver/recess and wing clearance; verify the 0.6 mm GF toolpaths and the actual coupon/full assembly. The pins register only; the driver flange and normal LM fasteners complete the load path. See [the current qualification procedure](PETG_GF_QUALIFICATION.md).

For the P2S, choose the two keyed halves: the canonical monolith is retained
for a verified larger-format printer only and is not sliced by the P2S captive
magnet pipeline. The split stations are exact same-state cavity-audit proxies
for the monolith as well as the actual P2S prints; follow their own G-code
pause rows. No monolith pause is synthesized.

1. Complete coupons 7, 9, and 12, then measure the real MU
   terminal carrier, tabs, boots, and cable. Stop if the physical parts
   exceed the modeled service space.
2. Install all six rotated LM carrier inserts at 0/60/120/180/240/300° in
   both states; every site is an ordinary blind carrier bore. Floor mode has
   no secondary support heat-sets or through-clearance sites. Install the four
   UM driver inserts, then install two additional M3 inserts through the
   standalone UM carrier's rear/mating openings at x=±32, y=315.770. Those
   joint inserts belong wholly to the UM print in blind Ø4.6 x 4.0 receivers
   inside local Ø9.8 functional bosses, with a 1.9 mm front floor. Install the
   two crescent M3 inserts through that standalone print's rear/mating
   openings at x=±24, y=421.5; each must likewise sit in a complete local
   Ø9.8 boss with an independently printable 360° receiver wall and 1.9 mm
   front floor. No-floor
   additionally owns four rear-opening bridge inserts in the 62 mm solid web;
   each unchanged 6.8 mm-total bore starts at z=5.3 with a Ø6.5 × 2.0
   rear entry followed by Ø6.4 and leaves the existing 6.2 mm front floor. Set every
   insert square and reject any cracked, loose, or over-melted boss.
3. During printing, bury six D5×2 magnets in the Ø5.20×2.10
   surface-normal captive cavities at the exact manifest pauses. LM uses
   four: preserve the upper ring-radial 64°/116° axes and the validated
   nearest-insert/route clearances, then fit the lower captive pair at the
   shared shoulder's cubic midpoint. The right visible datum is
   `(x,y,z)=(45.285011,89.190370,15.10)` with outward normal
   `(0.706451,-0.707762)`; the left is its exact X mirror. Confirm that these
   coincident floor/no-floor datums remain clear of lower inserts, buried
   routes, and the
   bridge/integral-stand load path. Upper LM and UM use that same source
   Z=15.10; UM keeps the 50.5°/129.5° axes. Verify the R113.0/R51.7 structural rings and continuous exposed
   R113.8/R52.5 side fairings, clipped only inside the existing LM--UM and
   T--UM cusp/service regions, with the 0.40 mm LM--UM inter-carrier gap open.
   Each ring cavity datum is structural radius
   +0.65 mm, 0.15 mm beneath the exposed surface; there must be no
   magnet-local backing, boss, relief, rear cap, flat, or visible cue. Verify
   unchanged 0.52 mm axial skins, a
   continuous loading cradle, and the support-free 45° closing roof in sliced
   preview with Arachne. The mating surfaces must remain flush with zero air
   gap; the receiver's 0.05 mm spacing allowance is solid material. Nominal
   paired magnet-face separation is 1.10 mm at LM-lower, LM-upper, and UM.
   Use the manifest's marked local-axis polarity for
   every carrier and mating receiver; do not infer it from mirroring. These magnets
   align and suppress rattle only;
   assign them **zero load capacity** in every assembly and test. For flat/graded,
   verify three coaxial receiver pairs per side: LM lower, LM upper, and UM.
4. After the two UM-owned joint inserts have been installed and inspected in
   the individual UM print, put both collars front-face-down on one flat
   reference. Engage the two rounded half-lap ears at x=±32.0, y=315.770;
   preserve their 0.20 mm axial gap. Drive two M3 screws from the LM rear,
   through the LM's Ø3.4 clearance bores, into the UM inserts. Tighten evenly
   without bottoming the screws while holding both front faces coplanar. Do
   not add washers/nuts or drill through the UM front floor. Verify
   the 165.100 mm driver-center spacing before loading the drivers.
5. In floor mode, inspect the integral W64 stem/foot and convex R41-minimum
   Option-B transition, fish all
   three buried floor lanes, fit the NL8 receptacle through the rear panel and
   confirm the service cavity remains usable. Install a positive anti-tip
   tether or anchor before loading the assembly; the W64 foot is not a safety
   restraint. In no-floor mode, bolt the stock bridge directly to the immutable
   (±20,20)/(±20,70) pattern in the fused front-flush web; there is no separate
   no-floor keel. Feed UM/T through the plate's centered rear mouths before
   the bridge blocks access. The floor LM has no bridge tail. Confirm every closed
   solid-backed cable bump clears real hardware before tightening. Magnets
   remain alignment/anti-rattle aids, never a load path. Add only the remaining
   optional modules needed. Attach the tweeter
   crescent directly at x=±24, y=421.5, preserve the 0.20 mm axial gap, and
   drive two M3 screws through the UM's standalone Ø3.4 passages into the
   pre-installed crescent inserts; no bolt head
   may break the acoustic front. Obi-Wan has no printed grommet; keep the
   selected external cable retention outside the buried-route mouths and free
   cable paths; do not rely on it until its physical cable/retention fit passes.
   Keep every module clear of all driver, service, buried-route, and free
   cable envelopes.
6. Rotate the physical MU to the equivalent mounting orientation that
   puts its terminal carrier on the free rear-UM lead and the
   **283-degree service axis**, verified with coupon 9 and the routing sheet,
   exactly between the 238- and 328-degree screw positions. Fit and
   remove each measured low-profile flag Faston separately with the
   cables and adjacent modules in place; its polarity-specific Ø3.2 lead
   must clear the installed opposite connector and both drivers at each
   one-at-a-time 0/3/6/9/12 mm review state. Record the physical release
   stroke: the modeled 12 mm endpoint has zero positive overtravel beyond
   the provisional exposed tab and does not itself prove disengagement.
7. Follow the Obi-Wan cable-fishing protocol above. Confirm every covered
   LM-pad bump, the physical T-over-UM crown crossing, and the covered
   328°/58° T-route bumps follow the modeled smooth curves without a kink.
   Confirm the UM span is free behind the UM carrier and the T span is free
   behind the crescent, with neither deleted duct recreated by support or
   retention. Use the true
   local u-z views to confirm the full solid saddle to each bore floor. Add the
   chosen retention/strain relief (one form is mandatory) and connect the
   Fastons only after this inspection. Cable load must be reacted away
   from the MU tabs.
8. Before entrusting drivers to the carrier, proof-test the finished
   carrier/web-or-integral-stand/insert/fastener system with a dummy 4.0 kg mass through the
   sustained-1g, 3g, and 5g cases in the governing normal and
   rear-moment directions. Follow the documentation and rejection
   criteria in “Obi-Wan structural screens”; magnets receive no credit.
   For floor mode, also complete the 2×/24 h/35 °C proof and the
   1.5×/≥168 h creep gate, and record the installed anti-tip anchor/tether.
   For the optional LM split, install the representative LM driver or an
   equivalent flange-and-all-fasteners splice during the complete 1g/3g/5g
   proof; give both concealed pins/sockets no standalone retention or load
   credit and record the prior slicer-path gate, two-pin fit, full-seat,
   coplanarity, route-seam and cable-pull-through evidence with the result.
   Repeat after any filament, slicer, material, insert-process, or
   service-temperature change.
9. Mount the drivers, apply the same low torques in the table, and
   re-check collar coplanarity and all fasteners after 24 hours and the
   first loud session.

## Release-form print constraints

These constraints moved here from the project README during the product-first restructure. The per-product geometry they refer to lives in [`stock.md`](stock.md), [`slim.md`](slim.md), and [`obiwan.md`](obiwan.md).

Current LM registration: Ø1.60 pins at x=±108.920904, z=14.30 mm, 2.40 mm engagement and 0.50 mm root overlap. Right socket Ø1.80; left 1.84 × 1.80 mm with 0.02 mm X relief per side. Radial clearance 0.10 mm, blind-end clearance 0.25 mm, pitch 217.841807 mm. The native ring retains ≥0.38 mm radial and ≥0.50 mm blind-end wall without exterior lands. Preserve lumens, driver/recess and wing clearance; verify the 0.6 mm GF toolpaths and the actual coupon/full assembly. The pins register only; the driver flange and normal LM fasteners complete the load path. See [the current qualification procedure](PETG_GF_QUALIFICATION.md).

### Magnet insertion and the print sidecar

Print every released baffle/acoustic part front-face-down, including
non-magnet pieces such as the Obi-Wan tweeter crescent. For magnet-bearing parts,
pause at the listed Bambu Studio marker, which is the first layer whose
toolpath begins closing the roof after the last fully open layer. At the pause, insert the exact
count vertically downward from the +Z side along print -Z, with the polarity
shown in the manifest; ensure every disc is fully seated below the completed
layer, clear the toolpath, and resume. Do not use the
coupon's common **LM/UM 5.96 mm** regression marker for unrelated parts; that
value applies only to matching Obi-Wan coupon geometry on the tested P2S 0.4
mm / 0.16 mm profile.

The sibling `.print.json` beside each released nonpolar STL is mandatory
machine-readable print authority, not optional documentation. It binds the
exact STL hash and size to X180 plus an optional bed-normal Z rotation and the
origin translation. Keep each pair together and rerun `scripts/check_manifold.py`
after copying artifacts; do not print a missing, orphaned, hash-stale, tilted,
or translation-inconsistent pair. The only release STLs intentionally without
this acoustic/front-down sidecar are the floor-state polar base and rotor,
which are measurement jigs with their own flat orientation.

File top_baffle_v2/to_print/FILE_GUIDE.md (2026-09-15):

# P2S files and slicer estimates

Generated from `catalog.json` and `delivery_manifest.json`; run `make PRINTER=P2S delivery_refresh` to update.

For the current printer, use the [H2C file catalog](h2c/README.md). The three families below are alternative upper selections, with their own compatible parts.

Three tweeter families and five carrier arrangements at one scale

| Tweeter family | Earlier P2S selection | Print guide |
|---|---|---|
| Dayton ND25FW-4 | Stock/Slim standard vase or regular Obiwan UM + crescent | Jobs below |
| Tectonic TEBM35C10-4 BMR | Obiwan coaxial/opposed crescent on regular UM; separate Stock/Slim BMR vase delivery | Obiwan jobs below; [other mounts](../docs/VARIANTS.md) |
| Dayton ND25FN-4 waveguide | Fused Obiwan UM/body + two caps + two M3 retainers; matching optional wings | [PETG-GF + PLA](../candidates/nd25fn4_crescent/print/README.md) · [PETG Translucent + PLA](../candidates/nd25fn4_crescent/print_translucent/README.md) |

The ND25FN-4 material bundles have their own manifests and estimates. Counts below describe the earlier regular ND25FW-4/BMR shelf.

42 choices; 68 sliced projects and 8 GUI projects across all lanes. These are alternatives, not a per-speaker part count.

Times and grams are slicer estimates per job, including its encoded setup/purge where reported. GUI estimates remain pending until sliced. Multiply the chosen jobs by two for stereo.

| Part / plate | Lane | State | Delivery | Time | Filament (g) |
|---|---|---|---|---|---|
| [Stock LM lower, 1 of 3 — no-floor stand](stock/3mf_04/stock_01_LM_bottom_1_of_3_no_floor_stand.gcode.3mf) | pla04 | no_floor_stand | Sliced | 10h 38m 9s | 218.59 |
| [Stock LM lower, 1 of 3 — no-floor stand](stock/3mf_06hf/stock_01_LM_bottom_1_of_3_no_floor_stand_06hf.gcode.3mf) | pla06hf | no_floor_stand | Sliced | 5h 37m 38s | 216.11 |
| [Stock LM lower, 1 of 3 — floor stand](stock/3mf_04/stock_01_LM_bottom_1_of_3_floor_stand.gcode.3mf) | pla04 | floor_stand | Sliced | 18h 15m 36s | 367.37 |
| [Stock LM lower, 1 of 3 — floor stand](stock/3mf_06hf/stock_01_LM_bottom_1_of_3_floor_stand_06hf.gcode.3mf) | pla06hf | floor_stand | Sliced | 10h 1m 58s | 353.22 |
| [Stock LM middle-left, 2 of 3](stock/3mf_04/stock_02_LM_mid_left_2_of_3.gcode.3mf) | pla04 | shared | Sliced | 5h 22m 25s | 115.84 |
| [Stock LM middle-left, 2 of 3](stock/3mf_06hf/stock_02_LM_mid_left_2_of_3_06hf.gcode.3mf) | pla06hf | shared | Sliced | 3h 2m 30s | 113.87 |
| [Stock LM middle-right, 3 of 3 — shared](stock/3mf_04/stock_03_LM_mid_right_3_of_3.gcode.3mf) | pla04 | shared | Sliced | 5h 30m 28s | 119.49 |
| [Stock LM middle-right, 3 of 3 — shared](stock/3mf_06hf/stock_03_LM_mid_right_3_of_3_06hf.gcode.3mf) | pla06hf | shared | Sliced | 3h 9m 33s | 116.92 |
| [Stock UM vase/top, 1 of 1](stock/3mf_04/stock_04_UM_vase_1_of_1.gcode.3mf) | pla04 | shared | Sliced | 3h 15m 11s | 68.21 |
| [Stock UM vase/top, 1 of 1](stock/3mf_06hf/stock_04_UM_vase_1_of_1_06hf.gcode.3mf) | pla06hf | shared | Sliced | 1h 59m 0s | 66.32 |
| [Stock A shoulder bottom-left, 1 of 4](stock/3mf_04/stock_05_A_shoulder_bottom_left_1_of_4.gcode.3mf) | pla04 | shared | Sliced | 46m 51s | 14.85 |
| [Stock A shoulder bottom-left, 1 of 4](stock/3mf_06hf/stock_05_A_shoulder_bottom_left_1_of_4_06hf.gcode.3mf) | pla06hf | shared | Sliced | 30m 1s | 14.18 |
| [Stock A shoulder top-left, 2 of 4](stock/3mf_04/stock_06_A_shoulder_top_left_2_of_4.gcode.3mf) | pla04 | shared | Sliced | 55m 14s | 17.38 |
| [Stock A shoulder top-left, 2 of 4](stock/3mf_06hf/stock_06_A_shoulder_top_left_2_of_4_06hf.gcode.3mf) | pla06hf | shared | Sliced | 35m 2s | 16.98 |
| [Stock A shoulder bottom-right, 3 of 4](stock/3mf_04/stock_07_A_shoulder_bottom_right_3_of_4.gcode.3mf) | pla04 | shared | Sliced | 46m 43s | 14.86 |
| [Stock A shoulder bottom-right, 3 of 4](stock/3mf_06hf/stock_07_A_shoulder_bottom_right_3_of_4_06hf.gcode.3mf) | pla06hf | shared | Sliced | 29m 55s | 14.18 |
| [Stock A shoulder top-right, 4 of 4](stock/3mf_04/stock_08_A_shoulder_top_right_4_of_4.gcode.3mf) | pla04 | shared | Sliced | 55m 32s | 17.37 |
| [Stock A shoulder top-right, 4 of 4](stock/3mf_06hf/stock_08_A_shoulder_top_right_4_of_4_06hf.gcode.3mf) | pla06hf | shared | Sliced | 34m 55s | 16.97 |
| [Stock B1 wing left, 1 of 2](stock/3mf_04/stock_09_B1_wing_left_1_of_2.gcode.3mf) | pla04 | shared | Sliced | 1h 48m 56s | 36.99 |
| [Stock B1 wing left, 1 of 2](stock/3mf_06hf/stock_09_B1_wing_left_1_of_2_06hf.gcode.3mf) | pla06hf | shared | Sliced | 1h 3m 39s | 36.17 |
| [Stock B1 wing right, 2 of 2](stock/3mf_04/stock_10_B1_wing_right_2_of_2.gcode.3mf) | pla04 | shared | Sliced | 1h 48m 55s | 37.00 |
| [Stock B1 wing right, 2 of 2](stock/3mf_06hf/stock_10_B1_wing_right_2_of_2_06hf.gcode.3mf) | pla06hf | shared | Sliced | 1h 3m 53s | 36.19 |
| [Slim LM lower, 1 of 3 — no-floor stand](slim/3mf_04/slim_01_LM_bottom_1_of_3_no_floor_stand.gcode.3mf) | pla04 | no_floor_stand | Sliced | 9h 36m 20s | 200.59 |
| [Slim LM lower, 1 of 3 — no-floor stand](slim/3mf_06hf/slim_01_LM_bottom_1_of_3_no_floor_stand_06hf.gcode.3mf) | pla06hf | no_floor_stand | Sliced | 5h 6m 47s | 197.83 |
| [Slim LM lower, 1 of 3 — floor stand](slim/3mf_04/slim_01_LM_bottom_1_of_3_floor_stand.gcode.3mf) | pla04 | floor_stand | Sliced | 16h 12m 51s | 334.10 |
| [Slim LM lower, 1 of 3 — floor stand](slim/3mf_06hf/slim_01_LM_bottom_1_of_3_floor_stand_06hf.gcode.3mf) | pla06hf | floor_stand | Sliced | 9h 7m 18s | 320.51 |
| [Slim LM middle-left, 2 of 3](slim/3mf_04/slim_02_LM_mid_left_2_of_3.gcode.3mf) | pla04 | shared | Sliced | 3h 37m 0s | 81.85 |
| [Slim LM middle-left, 2 of 3](slim/3mf_06hf/slim_02_LM_mid_left_2_of_3_06hf.gcode.3mf) | pla06hf | shared | Sliced | 2h 8m 38s | 80.41 |
| [Slim LM middle-right, 3 of 3 — shared](slim/3mf_04/slim_03_LM_mid_right_3_of_3.gcode.3mf) | pla04 | shared | Sliced | 3h 40m 30s | 84.69 |
| [Slim LM middle-right, 3 of 3 — shared](slim/3mf_06hf/slim_03_LM_mid_right_3_of_3_06hf.gcode.3mf) | pla06hf | shared | Sliced | 2h 13m 2s | 82.60 |
| [Slim UM vase/top, 1 of 1](slim/3mf_04/slim_04_UM_vase_1_of_1.gcode.3mf) | pla04 | shared | Sliced | 2h 19m 5s | 46.81 |
| [Slim UM vase/top, 1 of 1](slim/3mf_06hf/slim_04_UM_vase_1_of_1_06hf.gcode.3mf) | pla06hf | shared | Sliced | 1h 27m 27s | 45.70 |
| [Slim A shoulder bottom-left, 1 of 4](slim/3mf_04/slim_05_A_shoulder_bottom_left_1_of_4.gcode.3mf) | pla04 | shared | Sliced | 33m 43s | 9.83 |
| [Slim A shoulder bottom-left, 1 of 4](slim/3mf_06hf/slim_05_A_shoulder_bottom_left_1_of_4_06hf.gcode.3mf) | pla06hf | shared | Sliced | 22m 48s | 9.43 |
| [Slim A shoulder top-left, 2 of 4](slim/3mf_04/slim_06_A_shoulder_top_left_2_of_4.gcode.3mf) | pla04 | shared | Sliced | 40m 36s | 11.94 |
| [Slim A shoulder top-left, 2 of 4](slim/3mf_06hf/slim_06_A_shoulder_top_left_2_of_4_06hf.gcode.3mf) | pla06hf | shared | Sliced | 26m 48s | 11.71 |
| [Slim A shoulder bottom-right, 3 of 4](slim/3mf_04/slim_07_A_shoulder_bottom_right_3_of_4.gcode.3mf) | pla04 | shared | Sliced | 33m 40s | 9.84 |
| [Slim A shoulder bottom-right, 3 of 4](slim/3mf_06hf/slim_07_A_shoulder_bottom_right_3_of_4_06hf.gcode.3mf) | pla06hf | shared | Sliced | 22m 43s | 9.44 |
| [Slim A shoulder top-right, 4 of 4](slim/3mf_04/slim_08_A_shoulder_top_right_4_of_4.gcode.3mf) | pla04 | shared | Sliced | 40m 35s | 11.93 |
| [Slim A shoulder top-right, 4 of 4](slim/3mf_06hf/slim_08_A_shoulder_top_right_4_of_4_06hf.gcode.3mf) | pla06hf | shared | Sliced | 26m 49s | 11.71 |
| [Slim B1 wing left, 1 of 2](slim/3mf_04/slim_09_B1_wing_left_1_of_2.gcode.3mf) | pla04 | shared | Sliced | 1h 13m 59s | 24.39 |
| [Slim B1 wing left, 1 of 2](slim/3mf_06hf/slim_09_B1_wing_left_1_of_2_06hf.gcode.3mf) | pla06hf | shared | Sliced | 45m 34s | 23.95 |
| [Slim B1 wing right, 2 of 2](slim/3mf_04/slim_10_B1_wing_right_2_of_2.gcode.3mf) | pla04 | shared | Sliced | 1h 13m 37s | 24.39 |
| [Slim B1 wing right, 2 of 2](slim/3mf_06hf/slim_10_B1_wing_right_2_of_2_06hf.gcode.3mf) | pla06hf | shared | Sliced | 45m 32s | 23.96 |
| [Obi-Wan keyed LM bottom, 1 of 2 — no-floor stand](obiwan/3mf_06hf_petg-gf_pla/obiwan_01_LM_bottom_keyed_1_of_2_no_floor_stand_GUI.3mf) | petg_gf_gui | no_floor_stand | Slice in GUI | Pending slice | Pending slice |
| [Obi-Wan keyed LM bottom, 1 of 2 — floor stand](obiwan/3mf_06hf_petg-gf_pla/obiwan_01_LM_bottom_keyed_1_of_2_floor_stand_GUI.3mf) | petg_gf_gui | floor_stand | Slice in GUI | Pending slice | Pending slice |
| [Obi-Wan keyed LM top, 2 of 2 — shared](obiwan/3mf_06hf_petg-gf_pla/obiwan_02_LM_top_keyed_2_of_2_GUI.3mf) | petg_gf_gui | shared | Slice in GUI | Pending slice | Pending slice |
| [Obi-Wan UM carrier, 1 of 1 — shared](obiwan/3mf_06hf_petg-gf_pla/obiwan_03_UM_carrier_1_of_1_GUI.3mf) | petg_gf_gui | shared | Slice in GUI | Pending slice | Pending slice |
| [Obi-Wan tweeter crescent, 1 of 1](obiwan/3mf_06hf_petg-gf_pla/obiwan_04_T_tweeter_crescent_1_of_1_GUI.3mf) | petg_gf_gui | shared | Slice in GUI | Pending slice | Pending slice |
| [Obi-Wan NL8 service-trough snap lid, 1 of 1 — floor stand](obiwan/3mf_06hf_petg-gf_pla/obiwan_NL8_service_lid_1_of_1_GUI.3mf) | petg_gf_gui | floor_stand | Slice in GUI | Pending slice | Pending slice |
| [Obi-Wan no-floor-stand 01+02+03+04 locked combo plate](obiwan/3mf_06hf_petg-gf_pla/obiwan_01_02_03_04_LM_UM_combo_no_floor_stand_GUI.3mf) | petg_gf_gui | no_floor_stand | Slice in GUI | Pending slice | Pending slice |
| [Obi-Wan floor-stand 01+02+03+04 locked combo plate](obiwan/3mf_06hf_petg-gf_pla/obiwan_01_02_03_04_LM_UM_combo_floor_stand_GUI.3mf) | petg_gf_gui | floor_stand | Slice in GUI | Pending slice | Pending slice |
| [Obi-Wan flat wing split2, LM lower-left, 1 of 2](obiwan/3mf_04/obiwan_05_split2_flat_wing_LM_lower_left_1_of_2.gcode.3mf) | pla04 | shared | Sliced | 48m 29s | 19.71 |
| [Obi-Wan flat wing split2, LM lower-left, 1 of 2](obiwan/3mf_06hf/obiwan_05_split2_flat_wing_LM_lower_left_1_of_2_06hf.gcode.3mf) | pla06hf | shared | Sliced | 33m 7s | 18.86 |
| [Obi-Wan flat wing split2, fused LM/UM upper-left, 2 of 2](obiwan/3mf_04/obiwan_06_split2_flat_wing_LM_UM_upper_left_2_of_2.gcode.3mf) | pla04 | shared | Sliced | 1h 29m 8s | 40.33 |
| [Obi-Wan flat wing split2, fused LM/UM upper-left, 2 of 2](obiwan/3mf_06hf/obiwan_06_split2_flat_wing_LM_UM_upper_left_2_of_2_06hf.gcode.3mf) | pla06hf | shared | Sliced | 57m 54s | 38.78 |
| [Obi-Wan flat wing split2, LM lower-right, 1 of 2](obiwan/3mf_04/obiwan_08_split2_flat_wing_LM_lower_right_1_of_2.gcode.3mf) | pla04 | shared | Sliced | 48m 21s | 19.64 |
| [Obi-Wan flat wing split2, LM lower-right, 1 of 2](obiwan/3mf_06hf/obiwan_08_split2_flat_wing_LM_lower_right_1_of_2_06hf.gcode.3mf) | pla06hf | shared | Sliced | 32m 57s | 18.89 |
| [Obi-Wan flat wing split2, fused LM/UM upper-right, 2 of 2](obiwan/3mf_04/obiwan_09_split2_flat_wing_LM_UM_upper_right_2_of_2.gcode.3mf) | pla04 | shared | Sliced | 1h 30m 34s | 40.34 |
| [Obi-Wan flat wing split2, fused LM/UM upper-right, 2 of 2](obiwan/3mf_06hf/obiwan_09_split2_flat_wing_LM_UM_upper_right_2_of_2_06hf.gcode.3mf) | pla06hf | shared | Sliced | 58m 23s | 38.84 |
| [Obi-Wan flat split2 left/right wings, locked four-piece combo plate](obiwan/3mf_04/obiwan_flat_wings_split2_combo.gcode.3mf) | pla04 | shared | Sliced | 6h 30m 33s | 147.31 |
| [Obi-Wan flat split2 left/right wings, locked four-piece combo plate](obiwan/3mf_06hf/obiwan_flat_wings_split2_combo_06hf.gcode.3mf) | pla06hf | shared | Sliced | 3h 45m 51s | 144.60 |
| [Obi-Wan flat split2 left/right wings, locked four-piece combo plate](obiwan/3mf_06hf_petg-gf/obiwan_flat_wings_split2_combo_06hf_petg-gf.gcode.3mf) | petg_gf_wings | shared | Sliced | 4h 29m 57s | 137.11 |
| [Obi-Wan graded wing split2, LM lower-left, 1 of 2](obiwan/3mf_04/obiwan_11_split2_graded_wing_LM_lower_left_1_of_2.gcode.3mf) | pla04 | shared | Sliced | 47m 1s | 17.74 |
| [Obi-Wan graded wing split2, LM lower-left, 1 of 2](obiwan/3mf_06hf/obiwan_11_split2_graded_wing_LM_lower_left_1_of_2_06hf.gcode.3mf) | pla06hf | shared | Sliced | 31m 21s | 16.62 |
| [Obi-Wan graded wing split2, fused LM/UM upper-left, 2 of 2](obiwan/3mf_04/obiwan_12_split2_graded_wing_LM_UM_upper_left_2_of_2.gcode.3mf) | pla04 | shared | Sliced | 1h 24m 18s | 34.18 |
| [Obi-Wan graded wing split2, fused LM/UM upper-left, 2 of 2](obiwan/3mf_06hf/obiwan_12_split2_graded_wing_LM_UM_upper_left_2_of_2_06hf.gcode.3mf) | pla06hf | shared | Sliced | 53m 30s | 31.95 |
| [Obi-Wan graded wing split2, LM lower-right, 1 of 2](obiwan/3mf_04/obiwan_14_split2_graded_wing_LM_lower_right_1_of_2.gcode.3mf) | pla04 | shared | Sliced | 46m 30s | 17.67 |
| [Obi-Wan graded wing split2, LM lower-right, 1 of 2](obiwan/3mf_06hf/obiwan_14_split2_graded_wing_LM_lower_right_1_of_2_06hf.gcode.3mf) | pla06hf | shared | Sliced | 31m 35s | 16.66 |
| [Obi-Wan graded wing split2, fused LM/UM upper-right, 2 of 2](obiwan/3mf_04/obiwan_15_split2_graded_wing_LM_UM_upper_right_2_of_2.gcode.3mf) | pla04 | shared | Sliced | 1h 24m 34s | 34.16 |
| [Obi-Wan graded wing split2, fused LM/UM upper-right, 2 of 2](obiwan/3mf_06hf/obiwan_15_split2_graded_wing_LM_UM_upper_right_2_of_2_06hf.gcode.3mf) | pla06hf | shared | Sliced | 53m 32s | 31.91 |
| [Obi-Wan graded split2 left/right wings, locked four-piece combo plate](obiwan/3mf_04/obiwan_graded_wings_split2_combo.gcode.3mf) | pla04 | shared | Sliced | 5h 13m 55s | 118.72 |
| [Obi-Wan graded split2 left/right wings, locked four-piece combo plate](obiwan/3mf_06hf/obiwan_graded_wings_split2_combo_06hf.gcode.3mf) | pla06hf | shared | Sliced | 3h 5m 15s | 114.02 |
| [Obi-Wan graded split2 left/right wings, locked four-piece combo plate](obiwan/3mf_06hf_petg-gf/obiwan_graded_wings_split2_combo_06hf_petg-gf.gcode.3mf) | petg_gf_wings | shared | Sliced | 3h 57m 1s | 115.16 |
| [CANDIDATE Obi-Wan BMR crescent, coaxial TEBM35C10-4 pair, 1 of 1 — both drivers on one axis 86.413 mm from the MU10 axis; buries two captive magnets. Not release-authorized: absent from the released catalog and the release inventory, pending physical qualification.](obiwan/3mf_04/obiwan_17_BMR_crescent_coaxial_1_of_1.gcode.3mf) | pla04 | shared | Sliced | 3h 29m 36s | 80.17 |
| [CANDIDATE Obi-Wan BMR crescent, opposed TEBM35C10-4 pair, 1 of 1 — the two drivers fire back to back across a shared 2.40 mm partition; buries four captive magnets. Not release-authorized: absent from the released catalog and the release inventory, pending physical qualification.](obiwan/3mf_04/obiwan_18_BMR_crescent_opposed_1_of_1.gcode.3mf) | pla04 | shared | Sliced | 3h 14m 14s | 74.09 |

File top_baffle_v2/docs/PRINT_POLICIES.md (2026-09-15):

# Shared print roles and hardware — earlier P2S process

For current H2C nozzle mapping, materials and support settings, use the [H2C file guide](../to_print/h2c/README.md). The shared infill and hardware roles below also apply to H2C; the single-nozzle process details are the earlier P2S calibration. [Three tweeter families](TWEETER_OPTIONS.md) · [ND25FN-4 waveguide](DAYTON_ND25FN4_WAVEGUIDE.md).

Generated by `scripts/generate_print_policy_docs.py` from [print_policy.json](../print_policy.json).
Policy SHA-256: `6f618bf4754fa1343e3721655b608370cbc1dd4731c77432eb32aa49d170a84c`.

Bambu Lab P2S, hardened 0.6 mm High Flow nozzle; 0.16 mm layers, 0.20 mm first layer. 6 walls, 10 top layers and 5 bottom layers come from the shared Tinmorry profile. Infill percentages describe sparse regions; the slicer still makes skins and narrow regions solid.

| Part / region | Infill | Pattern |
|---|---:|---|
| lm bottom | 100% | zig-zag |
| lm top | 100% | zig-zag |
| Regular UM | 100% | zig-zag |
| core combo | 100% | zig-zag |
| regular wing | 10% | gyroid |
| ND25FN-4 matching wings | 10% | gyroid |
| ND25FN-4 structural UM | 100% | zig-zag |
| ND25FN-4 tweeter region | 15% | gyroid |
| ND25FN-4 caps / retainers | 15% | gyroid |
| ND25FW-4 / BMR separate crescent | 30% | gyroid |

## Materials and support

| Material role | Material | Slicer filament | G-code tool |
|---|---|---:|---|
| model | TINMORRY PETG-GF | 1 | T0 |
| interface | Bambu PLA Basic | 2 | T1 |

GF forms the model and support body; PLA forms the dense top contact. 3 PLA contact layers, 0 mm top gap and 0 mm contact spacing are configured. A preview showing one selected layer is not a count of the complete interface stack. Material assignment is also checked against positive extrusion under the actual T0/T1 commands.

Purge is 560 mm³ in each direction. Flushing: objects disabled, infill disabled, supports disabled. PLA flushing is limited to 12 mm³/s, independently of PLA's printing flow limit. Bottom contact retains 3 layers with a 0.18 mm gap and 0.5 mm spacing; it is a recorded exception, not the same finish as top contact.

The [reported Bambu workaround](https://github.com/bambulab/BambuStudio/issues/11893#issuecomment-5575014503) concerns nozzle variant/mapping inconsistencies. Here all four per-filament maps are completed together, High Flow is pinned, and purge dimensions match the loaded filament count. Merely changing the variant fields was insufficient in our reproduction. Native export XML newlines are encoded so GUI reopening retains magnet pauses.

The Tinmorry recipe is frozen in `vendor/TINMORRY/resolved_P2S_06HF_PETG_GF.json` and hash-checked. The GUI user preset can change without silently changing this recipe.

User-requested calibration after a PETG-GF to PLA blockage: double the previous 280 mm3 purge in both directions and limit PLA flushing to 12 mm3/s. Printing flow limits and temperatures are unchanged. Physical changeover test pending. Actual native changeover requests are checked by `scripts/audit_changeover.py`.

## Inserts and screws

The Dayton ND25FN-4 waveguide now uses 6 M3×8 socket-head screws, Ø3.4 mm retainer clearance holes and Ø4.6 mm × 4 mm blind insert bores, matching the shared M3 bore convention. The screw circle is Ø50.2 mm. The new retainer is Ø55.9 mm and passes through the unchanged Ø56.4 mm cap entry. The driver-side insert ligament is 1.60 mm; the retainer clearance-hole edge ligament is 1.15 mm. The cap, O-ring and driver seating surfaces are retained. Use the new body and retainers together; the imported M2 retention coupon is historical and does not qualify this M3 revision.

Use the existing **Hanglife HLTI-M3-001 — M3 x 5 x 4** inserts: M3 internal thread, Ø5 mm outside and 4 mm long. The Ø4.6 mm value describes our printed pilot, not the metal insert diameter. It leaves 0.4 mm nominal diametral interference for heat-setting. This records the established project bore convention; the supplied package drawing specifies the insert dimensions. The 4 mm inserts match the existing 4 mm-deep bores. The M3×8 screw engages 3.7 mm and stops 0.3 mm before the blind floor; 8 mm is the screw length under its head. The actual Ø5 mm insert envelope leaves 1.40 mm to the Dayton ND25FN-4 waveguide driver cavity. [User-supplied package drawing](../vendor/HANGLIFE/M3x5x4_reference.png).

Regular LM M5 stepped insert bores, M3 driver/joint bores, and M2 auxiliary ties remain their own functional interfaces. Through holes and thread-forming pilots are not insert pockets. See [the insert inventory](INSERT_CATALOG.md) for those separate counts.

There is no universal solid-infill modifier around every insert or magnet. Structural LM/UM regions use the densities above; a 6-wall shell still applies in the 15% tweeter region and 10% wings. The no-floor bridge-root 100% modifier is retained as an explicit structural safeguard.

## Magnets

| Location | Disc | Grade | Selection |
|---|---|---|---|
| Regular Obi-Wan and preserved LM connections | Ø5 × 2 mm | N52 | Superimanes D-05-02-N52 |
| Crescent UM and matching upper wing connections; eight discs per assembly | Ø6 × 3 mm | N45 | Superimanes D-06-03 |

**The magnets are not all the same model.** The preserved LM connections remain D5×2 N52. The crescent UM/upper-wing pairs use D6×3 N45: four in the body and two in each selected upper wing. Do not substitute one size into the other pocket. Both are alignment/retention features with zero structural load credit.

D5 uses the shared qualified roof/skin geometry and single-traversal toolpath checks. D6 uses inclined, buried pockets and a swept loading-path check. The new D6 gate samples every cavity layer at ≤0.06 mm boundary spacing and verifies actual model beads, width bounds and insertion timing. In the seated-disc working region, the cavity-facing wall must have 1 connected footprint and at least 50% footprint overlap with the prior model layer. These are digital screening criteria, not bond-strength measurements. A same-geometry crop coupon is provided separately. Digital passage does not establish physical extrusion, pause bonding, insertion or retention; those remain pending a coupon print.

## Exceptions and blocker review

| Exception | Scope | Reason / required check |
|---|---|---|
| `regular_wings_no_support` | regular_wing | Existing print pose and D5 roof contract; no PLA is loaded or required. Fail if support extrusion exists. |
| `crescent_wings_supported` | crescent_wing | Curved replacement wings have different geometry. GF supports with PLA contact; cavity blockers must exclude trapped support. |
| `caps_full_ceiling` | crescent_accessories | Disable critical-only and small-overhang removal so the entire 44.6 mm cap ceiling receives three full PLA contact layers. |
| `tweeter_lightweight` | crescent_body | Nonprinting modifier above installed Y=421 mm overrides UM 100% with tweeter 15% gyroid. |
| `bottom_contact_legacy` | supported | Bottom contact retains 0.18 mm gap and 0.5 mm spacing. It is not equivalent to the dense zero-gap top contact; review if supports are allowed to start on model surfaces. |
| `bridge_root_solid` | no_floor_stand_lm_bottom | Local 100% bridge-root modifier remains as an explicit structural safeguard; redundant with current global 100%. |
| `insert_and_duct_blockers` | supported | Block only functional bore and route volumes. Check actual support bead intersection, not blocker count or colour. |
| `rear_T_bore_layer_boundary` | crescent_body | Report sub-half-layer PLA contact at the mouth separately from support inside the cylindrical bore; retain a numerical bound and witness. |
| `D6_physical_qualification` | crescent_D6 | Digital boundary, width and loading checks plus a same-geometry coupon are necessary; extrusion, insertion, pause bonding and retention require a physical print. |
| `service_entry_support_columns` | crescent_body | Block the complete projected cable entry until it leaves the enlarged M3 service chamber; a short fixed sample range allowed adjacent support to grow sideways into the bore. Actual duct clearance is a mandatory gate. |
| `auxiliary_bores_orientation` | regular_NL8_and_M2_ties | These holes lack dedicated bore blockers. NL8 opens away from the bed; ties rely on their enclosed position and support settings. Fresh slices are checked by scripts/audit_auxiliary_support.py. Recheck if orientation or support scope changes. |

The crescent body has 12 insert sites: four UM, two LM receivers and six tweeter M3 bores. Its support exclusions follow each complete bore to the blind floor; the obsolete narrow tip cavities are gone. Cable passages and magnet loading cavities are excluded separately. Native red blocker volumes are nonprinting tools, not physical plugs.

Remaining physical checks: insert installation, retaining-wall extrusion, magnet seating/polarity, bonding after each pause, PLA removal and cap/LM assembly fit. Acoustic performance is not qualified by mesh or slicer checks.

## Code ownership

| Responsibility | Authority |
|---|---|
| Material indices, mapping, purge volumes, PLA flush flow, infill roles, exceptions, Dayton ND25FN-4 waveguide M3 dimensions | `print_policy.json`; `src/lx521_baffle/print_policy.py` |
| Native changeover volume and flow requests | `scripts/audit_changeover.py` |
| Frozen filament and complete process overrides | `captive_magnet_slicing_profile_petg_gf_06hf.json`; separate support-off wing profile |
| Regular cavity geometry and qualification | `magnet_contract.py`, `magnets.py`, `gcode_analysis.py`, `artifact_emit.py` |
| Regular support exclusions | `scripts/obiwan_support_blocker.py` |
| Dayton ND25FN-4 waveguide bore, duct and angled magnet exclusions | `candidates/nd25fn4_crescent/prepare_print.py` |
| Dayton ND25FN-4 waveguide caps: full ceiling coverage | `cap_support_check.py` |
| D6 model-bead boundary/width gate | `scripts/captive_wall_audit.py` |
| Dayton ND25FN-4 waveguide insertion and internal loading relief | `print_magnets.py`, `prepare_magnet_loading.py` |
| Source-bound D5 release inventory | `generate_captive_magnet_catalog.py --existing-local`; no remote rebuild claimed |
| Shelf geometry/process catalog | `manage_delivery.py refresh` |

The original [September 12 audit](../review/print_policy_audit_20260912/SUMMARY.md) remains historical. Current regeneration evidence is in `review/print_policy_update_20260912/`.

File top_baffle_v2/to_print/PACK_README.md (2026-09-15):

# LX521.4 top-baffle print pack

Start with [the build guide](docs/BUILD_GUIDE.md), then choose exact jobs from
[the file guide and estimates](to_print/FILE_GUIDE.md).

This pack contains actual STL/3MF files and adjacent orientation/plate
records. There are 42 choices: 68 sliced projects and eight GUI projects
across alternate lanes. Print a selected configuration, not every file.
PETG-GF `_GUI.3mf` projects require slicing and auditing in Bambu Studio.

The [qualification fixtures and procedure](docs/PETG_GF_QUALIFICATION.md)
are included. Obi-Wan remains a candidate: physical fit, print-process,
loaded and acoustic measurements are pending. Rendered images are CAD
illustrations, not photos of printed results.

Verify the downloaded archive with `python verify_package.py <archive.zip>`
and compare its external `.sha256` file. `SHA256SUMS.json` identifies the
individual payload files. Keep STL orientation records beside their meshes.

This is a print pack, not the complete source/CAD build repository. Some
engineering-reference links in the detailed docs require that repository.
The GUI slice audit command likewise requires its code, pinned Bambu
profiles and G-code validator. No printer is contacted by verification.

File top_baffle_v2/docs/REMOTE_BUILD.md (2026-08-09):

# Remote build execution, caching, and memory profiles

The ordinary interface is remote-first: `make` snapshots the working tree,
runs the same Makefile on `osado.lan`, and promotes only hash-verified
artifacts back. This file is the authority for that executor, its cache
semantics, and the memory profiles that bound it. The public target list and
the local-only goals are summarised in the
[project README](../README.md#quickstart).

## Public remote targets

Regenerate through the remote executor (the default):

    make
    make floor_stand
    make floor_obiwan  # focused integral-floor Obi-Wan release and strict QA
    make obiwan_release  # both Obi-Wan states + flat/graded, concurrent on osado
    make obiwan_wings  # flat + graded STEP/STL families, built concurrently
    make vase_tebm35c10_4_cad  # both Stock and Slim BMR-vase CAD children

## Job control and snapshot semantics

`make` snapshots the exact current working-tree inputs, runs in an isolated
job on `osado.lan`, and promotes only hash-verified artifacts back into this
directory. The pinned Python 3.12.12 environment is content-addressed and
reused remotely. Jobs survive a lost SSH connection; the printed job id can
be inspected or resumed with:

    python3 scripts/remote_cad.py status JOB_ID
    python3 scripts/remote_cad.py resume JOB_ID
    python3 scripts/remote_cad.py cancel JOB_ID

For a deliberately detached launch use
`python3 scripts/remote_cad.py run --detach TARGET`; ordinary `make` waits and fetches
automatically, while Ctrl-C detaches without killing the remote cgroup.

The client accepts only documented public Make targets; Make-variable
assignments and private file targets are rejected. `make manifold` includes
the current local candidate in its content-addressed snapshot so osado checks
those exact files. `make clean` mirrors the local target and preserves
`review/` snapshots.

The remote job has a hard 512 GiB aggregate systemd cgroup limit and a 64 GiB
host-free floor. It uses sixteen parallel guarded recipe slots by default,
with the remaining 448 GiB divided equally (28 GiB each). Set
`LX_CAD_REMOTE_JOBS=N` to tune the slot count; the aggregate cap cannot be
relaxed. `LX_CAD_REMOTE_HOST` and `LX_CAD_REMOTE_ROOT` override `osado.lan`
and `~/temp/lx-cad` respectively.

## Incremental cache seeding

Successful remote builds are incremental across isolated jobs.  After an
artifact archive has passed hash verification, local promoted-root QA and the
atomic local promotion transaction, its complete remote worktree is published
as a verified Make-cache seed keyed by both the environment lock identity and
the measured Python/runtime attestation.  A
fresh job clones that seed (using a filesystem reflink when available), checks
every cached byte, mode and mtime, then overlays the exact immutable source
snapshot.  Unchanged source mtimes are retained; changed/new sources are made
newer than every cached target; a removed source rejects the seed and leaves
the job's source-only cold tree intact.  GNU Make remains the sole dependency
engine—checksums only establish a trustworthy input tree.

The first build for an environment is cold.  Later no-change builds reuse
generated CAD and the remote-only selector `.ok` targets; a source edit
invalidates only the Make prerequisite groups it reaches.  Obi-Wan-only carrier,
attachment, bridge and split edits no longer invalidate legacy-family CAD.
Focused jobs return generated files whose bytes changed plus the explicit
public result of the requested target.  In particular, `floor_obiwan` and
`no_floor_obiwan` always return every file named by their hash-bound release
manifest, `common` always returns its STEP, and `obiwan_wings` always returns
the flat/graded design map and both wing artifact trees; a warm-cache Make no-op
therefore also reconstructs a fresh or locally deleted output tree. Complete
targets return their declared
output roots in full and always include their top-level PNG/STEP/catalog
outputs.  Cache corruption is deleted and falls back to the source-only cold
snapshot.  For the exact same immutable source hash, a newer successful
focused job publishes a coverage union: its own files, modes and mtimes win,
while files absent from it are retained from the previous verified seed.  A
narrow concurrent job therefore cannot evict richer CAD or check coverage.
Complete-root targets remain authoritative for their roots, `clean` never
unions, and source-hash changes replace rather than combine cache worktrees, so
represented deletions are not resurrected.  Any source-file deletion also
forces a true cold build, because generic Make prerequisites cannot prove which
inherited generated files belonged only to that source.  A focused job that
removes an inherited generated artifact fails closed instead of publishing an
unrepresentable per-file deletion, and cache publication recomputes the exact
artifact delta.  Failed, canceled, unfetched or locally rejected jobs never
publish a cache, and completion ordering prevents a late fetch from replacing
a newer seed.  This does not change job IDs, snapshot immutability,
status/resume/cancel behavior, artifact hashing or promotion rollback
semantics.

After verified download, promoted STL topology is checked again locally. That
defense-in-depth pass uses eight Make-jobserver workers inside the existing
single 8 GiB aggregate promotion guard. This private mesh-only path cannot run
CAD/OCC targets; ordinary `LX_CAD_EXECUTION=local` remains strictly serial.

The osado profile also removes workstation-only computational fragmentation:
the clearance and Obi-Wan selectors are ordinary Make prerequisites, so the same
jobserver bounds checks and artifact writers together. The Obi-Wan suite imports
LM, UM and tweeter BREPs only from each state's Make-owned, hash-validated native
stage; its private cache contains only test-only shell witnesses absent from that
stage, so assertion-only edits cannot rebuild carriers. It then evaluates
complete shell/cable/service witnesses. The exact assembled-junction sweep
still checks every Bambu 0.20/0.16-mm layer in both stand states, but Make
owns sixteen complementary state/layer-shard stamps. Each shard checks both
junctions and sections their shared UM owner/route only once, while the
sixteen guarded slots remain full instead of running serially. The two
state-specific base BREP gates are independent Make stamps as well;
V1L builds its shared split geometry once; and each state's V1L/Obi-Wan STLs are
meshed in one guarded process. Physical print-bed splits and mating interfaces
remain unchanged. Explicit local mode keeps the segmented, one-heavy-part-at-
a-time implementations needed by the 8 GiB workstation process-tree cap.

Strict STL topology QA is likewise one GNU Make stamp target per mesh, so
osado checks independent meshes concurrently through that same jobserver.
Each state's sweep starts as soon as that state's last artifact lands, so its
47 floor or 45 no-floor mesh checks can overlap remaining work in the other
state. The final combined node does metadata only: it still validates exact
inventories, print sidecars, review artifacts, manifests, and cross-state
differences every time without repeating any of the 92 state mesh checks.
Focused `floor_obiwan`/`no_floor_obiwan` sweeps expand only `*obiwan*.stl` Make
nodes, so verified legacy meshes inherited by a warm cache are not rechecked.

Before launch, the executor measures and hashes the actual Linux x86_64
Python ABI, interpreter binary, uv version and complete installed-package
freeze. The running job attests its real cgroup-v2 `memory.max` and zero-swap
limit. Download, source-drift rechecks, both state-directory swaps and the
local portable manifold check form one locked promotion transaction; any
failure restores the prior floor/no-floor pair.

## Local execution

Running OCC on the current machine requires an explicit opt-in:

    LX_CAD_EXECUTION=local make PYTHON=<venv>/bin/python

## Opposed-BMR vase targets

The opposed-BMR alternative is a complete two-profile family rather than a
Stock-only one-off. Its public CAD target emits independent BREP/STEP/STL,
print sidecar, facts, catalog, slicing-profile, and manifest roots under
`build/vase_TEBM35C10-4/{stock,slim}/`. Explicit profile targets are
`vase_tebm35c10_4_stock_cad` and `vase_tebm35c10_4_slim_cad`. Local Bambu
packaging is likewise available per profile through
`vase_tebm35c10_4_{stock,slim}_3mf`, or together through
`vase_tebm35c10_4_3mf`; those slicing targets never dispatch to osado. Each
validated project is promoted to the stable path
`build/vase_TEBM35C10-4/{stock,slim}/vase_TEBM35C10-4.gcode.3mf`.

## Candidate, release, and provenance boundary

The generated directories are **candidate packages**, not physical-release
authorization. Even the Make target named `release` performs CAD, artifact
and manifold checks only; while the state manifests say
`release_authorized: false`, neither state may be put into service. Complete
and sign the state-specific physical qualification record separately.
Each candidate also retains `.obiwan_stage/`: the hash-validated native BREP
transaction behind its Obi-Wan STEP/STL exports. Its manifest records the exact
Python/package identity, selected memory profile, per-tree cap, free-memory
floor, guard-slot count and any remote aggregate cgroup cap. Those records are
portable, so the local checker can verify a promoted osado build without
pretending it was generated under the macOS profile. It is provenance
evidence, not a printable part, and the strict checker intentionally requires
it. A recorded free-memory floor of `0` means that host-free monitoring was
disabled; RSS monitoring remains active.

## Memory guard

Do not bypass the guard with direct bulk Python invocations. The local profile
stops a CAD process tree above 8 GiB RSS, has no host-free-memory floor, and
keeps local builds serialized. Set a positive `LX_CAD_MIN_FREE_MB` to opt a
local invocation into a stricter floor. The high-memory profile refuses to
load on non-Linux or undersized hosts, retains its mandatory 64 GiB host-free
floor, and is selected by the remote executor only. Limit variables can
tighten their selected profile but cannot relax it.

Self-contained — the direct pip dependencies are
`build123d`, `shapely`, `matplotlib`, `numpy`, and `Pillow` (no external CAD
tooling). `make check` runs `tests/test_clearances.py` for proud-family
regressions and `tests/test_obiwan_r6f.py` for guarded Obi-Wan BREP contracts
(that file keeps its internal name).
Together they cover duct/pilot separation, flange-seat containment,
service envelopes, proud grommet regressions, complete-route smoothness, exact
normal/eroded-outline containment, closed assembled shells, hardware
clearance, and structural/bed screens. `make manifold` (also run at the
end of `make all`) proves candidate-mesh topology; final Obi-Wan BREP shell
tests, rather than manifoldness alone, prove that no rear cable window
is present.

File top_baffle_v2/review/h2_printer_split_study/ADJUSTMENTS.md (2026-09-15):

# Follow-up: what H2D adds, and smaller changes that remove more pieces

14 September 2026. This extends the [initial study](README.md), which deliberately assumed a 5 mm brim and kept the complete job within the area shared by the two nozzles. Production CAD and printer files remain unchanged.

**H2D does not unlock an additional recommended split over H2C.** Its useful size advantage is 20 mm more right-nozzle reach. H2C already has the same 325 × 320 mm area on the left, and both offer the same 300 × 320 mm shared area. H2D therefore gives more freedom to put the model material on either side when using the larger area. It does not give a larger shared PETG/PLA footprint. See the [official H2D machine profile](https://raw.githubusercontent.com/bambulab/BambuStudio/master/resources/profiles/BBL/machine/Bambu%20Lab%20H2D%200.4%20nozzle.json) and the H2C area diagrams in [Bambu's manual, pages 90–91](https://csm.bblcdn.com/hub/eff78da43720461787dc8bbe5fa0372d.pdf).

The H2C can also assign materials to separate interchangeable right-side hotends. That bank has 305 × 320 mm reach. It is a different arrangement from using the fixed left and right nozzles together; Bambu describes left/right switching as faster than exchanging induction hotends because the latter still involves AMS loading and unloading. [H2C manual, pages 77–86](https://csm.bblcdn.com/hub/eff78da43720461787dc8bbe5fa0372d.pdf).

For your alternating PETG-GF, translucent PETG and PLA jobs, separate assigned H2C hotends could reduce cleaning between those materials across jobs as well as within a job. That is an inference from the dedicated-hotend mechanism, not a measured waste or reliability comparison. H2D can already dedicate one nozzle to the model material and the other to PLA. I would prefer H2D if its price saving matters more than the additional hotends; I would not prefer it for a claimed reduction in this project's piece count.

## Smallest promising change: Stock/Slim LM in one piece

The current complete LM reaches **Y321.95**, partly because its two top registration keys project **6 mm above the actual Y315.95 joint**. Replace those projecting keys with registration contained inside the existing part envelope and the complete lower body becomes approximately **304.8 × 315.95 mm**. Driver positions and the exterior outline can remain unchanged.

Rotated 90 degrees on the **325 × 320 mm area**, with a **2 mm brim**, its footprint is **319.95 × 308.80 mm**. That leaves **2.53 mm edge clearance on the limiting axis**, and space for a separate 50 × 50 mm prime-tower reserve in the shared area. The envelope passes for Stock and Slim, with and without the floor stand.

This could take Stock/Slim from **3 LM pieces to 1**, and the core baffle from **4 pieces to 2: complete LM plus upper vase**.

The qualifications matter:

- The 2 mm brim is a proposed adhesion experiment for the glued plate, not a claim that it is equivalent to the current 5 mm brim.
- On H2C, use the left nozzle for this model envelope. On H2D, either nozzle has the necessary reach. PLA support and priming must remain reachable by their assigned nozzle.
- Registration needs a proper contained/rear joint design and a matching upper module. Simply deleting or flipping the existing dovetails is not a mounting solution: flipping them downward can intrude into the driver-seat region.
- Keeping the full 5 mm brim and forcing a rectangular top limit at Y311 would cut the protected driver-seat envelope, which reaches **Y311.581**. That shortcut is rejected.

This is the most promising small adjustment. It avoids scaling the entire model, changing driver cutouts, or moving the driver centers. It is more conditional than the original shared-area two-piece LM proposal.

## Obiwan: fewer pieces without making the drivers smaller

The initial recommendation already produces one complete LM and one full detachable wing per side. There is no need to shrink those parts.

**A simple additional consolidation is to fuse the regular UM and regular crescent**, as already done in V4. Their existing combined envelope fits even the present 256 mm printer. With detachable wings retained, regular Obiwan would then have **4 main pieces**, matching V4: LM, fused upper, left wing and right wing.

If minimum piece count takes priority over removable wings, a more ambitious configuration is possible:

| Arrangement | Main pieces per speaker | Envelope finding |
|---|---:|---|
| Regular Obiwan, permanent wings | **2** | LM + lower wing regions; fused UM/crescent + upper wing regions. Both fit the shared 300 × 320 area with 5 mm brims. |
| V4 Obiwan, permanent wings | **Potentially 2** | The corresponding two envelopes fit the 325 × 320 nozzle area with 2 mm brims. They fail the original shared-area/5 mm-brim rule. |

A common wing cut at approximately **Y222** works for both stand states of regular Obiwan. On the no-floor version, the two rotated body envelopes are approximately **273.7 × 293.6 mm** and **274.0 × 293.9 mm**, before brims. The floor version also fits. The proposed division leaves the whole LM ring on one piece; it divides the lateral wing material separately.

For V4, a common wing cut around **Y257** gives the more conditional larger-nozzle-area option. Using one cut for both stand states preserves an identical upper-body envelope across those states. Both variants retain the current driver positions.

These permanent-wing options are a product redesign, not merely a slicer merge. Wing-to-carrier clearances must become solid material; obsolete magnetic joints and split features need removal; the new side joints and upper-module installation path need design. A 2 mm brim and a prime-tower reserve fitting on the plate do not qualify all generated supports. Caps and retainers remain separate for driver access. Counts above exclude them and all hardware.

## What should stay fixed

Keep the driver seats and center spacing. Current LM/UM centers are **165.1 mm apart**; the clearance between their protected circular seat envelopes is only **5.2 mm** before surrounding wall material. A tens-of-millimetres reduction in spacing is therefore not a small cosmetic adjustment.

The full current baffles still do not become front-face-down monoliths through a few millimetres of trimming. The useful opportunities are contained registration, an appropriate brim, and choosing which surfaces belong to each printed part.

## Evidence

[Adjustment results](adjustments.json) include the unchanged-driver envelope checks, brim comparisons, local side-trim thresholds, wing seam sweeps and tower reserves. [Reproduction script](adjustment_study.py) reads the same hash-checked STLs as the initial study. Convex projected outlines are conservative envelope screens, not CAD solids or sliced support footprints.

The side-trim sweep held the top joint and base fixed; it did not find a width-only clipping solution inside the shared-area rules without exceeding the protected-seat clipping limit. This does not rule out a more extensive curved-outline redesign. The regular two-piece permanent-wing option, and the conditional Stock/Slim one-piece LM option, are the useful next design targets from this follow-up.

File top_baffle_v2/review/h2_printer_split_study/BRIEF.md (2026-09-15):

# H2C / H2D split feasibility study

Read-only purchasing assessment of stock, slim and Obi-Wan speaker baffles, in both stand states. Restore the exact current print STLs to assembly coordinates using their hash-bound print sidecars; inspect the current canonical STEP where the legacy toolchain allows. Study merging the LM pieces, moving seams below the driver, merging wing segments and retaining serviceable upper modules. No production CAD, current slicer project or printer command will be changed.

Dimensions are millimetres; installed X is lateral, Y upward, Z forward. Preserve front-face-down printing and captive-magnet loading; allow only rotation in the bed plane. Compare current P2S 256x256x256, both printers' shared dual-nozzle XY area of 300x320, both fixed left nozzles' 325x320, H2C right Vortek nozzle 305x320, and H2D right nozzle 325x320. The inherited machine profile limits the fixed left nozzle to Z320 and the right nozzle to Z325; use Z320 for shared/left screening. Treat advertised combined reach separately. Use a planning allowance of 5 mm brim plus 2 mm bed-edge margin on each side, and screen space for a separate prime tower where practical. These are planning allowances, not a slicer qualification.

Deliver a measured fit table and a scaled PNG comparison plus a concise recommendation. Do not scale, tilt or print the acoustic surfaces upright merely to fit. Do not imply identical support placement in both nozzle-exclusive strips; a part outside the shared area needs per-nozzle slicer validation. A conceptual merged set's hull is an envelope study, not a fused print-ready solid.

Follow-up: distinguish the H2D's additional right-nozzle reach from reach shared with H2C. Screen smaller joint projections, local outline trimming, narrower brims and wing-to-carrier consolidation as ways to remove another piece. Keep driver centers, driver seats and existing hardware datums fixed when identifying low-impact options. Treat permanent wings as a separate product tradeoff. Record numerical envelope thresholds, without modifying production CAD or claiming support qualification.

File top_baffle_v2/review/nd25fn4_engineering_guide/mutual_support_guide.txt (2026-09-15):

Printing guide for using PLA Basic and PETG HF/PETG Basic for support | Bambu Lab Wiki
¶ Using PLA Basic & PETG as Mutual Supports
Why this works: PLA and PETG don't bond well to each other — and that's exactly what makes them a great support pair. Supports snap off cleanly, leaving a much better surface finish.
¶ Overview
Let's look at the three examples below, using the incompatible filament techniques covered in this section.
In the image below, we can see 3 support approaches. The model was always printed in PETG, but the support filament varied between samples:
¶ Support Configurations Compared
¶ 1 — PETG model + PETG supports
Using PETG for both the model and the supports provides the shortest print time and the highest filament efficiency.
¶ 2 — PETG model + PLA supports
Only PLA is used for the supports. This results in the longest print time (5 h 3 min) and the highest filament usage. During printing, the toolhead needs to switch nozzles at almost every layer. Each nozzle change takes approximately 5 seconds, plus additional time to pressurize the nozzle at the purge tower.
¶ 3 — PETG model + PETG support base + PLA interface
The support base is printed with PETG, while the support interface is printed with PLA. This reduces the total print time by 1 hour and 20 minutes compared to the previous example. The time savings come mainly from fewer nozzle switches. The purge tower also uses significantly less filament — approximately half of the previous case.
¶ Surface Finish Results
Below, we can see the supported section. The image sequence is the same as above.
❌ PETG supports on PETG model
The bond between them is stronger. This makes the supports more difficult to remove and may leave marks or defects on the model surface.
✅ PLA supports on PETG model
The surface finish is improved. The supports are easier to remove, and the model surface remains clean and well-defined.
¶ ⚠️ Before You Start
This guide only applies to:
Bambu PLA Basic
Bambu PETG HF and Bambu PETG Basic
The following are not supported by this guide:
PLA Matte, PLA Silk, PLA-CF, or any third-party PLA
PETG Translucent, PETG-CF, or any third-party PETG
💧 Dry your filaments first. PETG runs at a high enough temperature that any moisture in PLA will cause stringing and oozing.
See → Filament Drying Recommendations
¶ Which Scenario Are You Printing?
My model is...
My support is...
Jump to
PETG HF or PETG Basic |
PLA Basic |
Scenario A |
PLA Basic |
PETG HF or PETG Basic |
Scenario B |
¶ Scenario A — PETG Model + PLA Basic Support
PLA Basic acts as the support/interface. It prints cleanly under PETG and breaks away easily.
¶ 🌡️ Temperature Settings
Filament
Nozzle Temp
Bed Temp
PETG HF / PETG Basic (model) |
Default |
60 °C |
PLA Basic (support) |
230 °C (all layers) |
60 °C |
Required print plate: Smooth PEI, High Temp Plate, or Textured PEI
Enclosed printers (X1, P1S, P2S): Open the door and/or top cover to prevent the chamber from getting too hot for PLA.
|
|
1. Filament options
2. Edit
3. Filament tab
4. Select Support hotend - Auxiliary extruder in this case.
5. Adjust filament temperatures
6. Save the PLA support profile
|
1. Filament options
2. Edit
3. Filament tab
4. Select hotend - Main extruder in this case.
5. Adjust filament temperatures
6. Save the PETG profile
|
¶ ⚙️ Support Configuration in Bambu Studio
We recommend using PLA Basic only as the support interface (not the full support base). Using it as the full base increases print time and risks the support falling off.
Recommended setup:
¶ Scenario B — PLA Basic Model + PETG Support
PETG acts as the support/interface. It handles the higher bed temps needed for PLA adhesion and still releases cleanly.
¶ 🌡️ Temperature Settings
Filament
Nozzle Temp
Bed Temp
PLA Basic (model) |
230 °C (all layers) |
60 °C |
PETG HF (support) |
265 °C (all layers) |
60 °C |
PETG Basic (support) |
Default |
60 °C |
Required print plate: Smooth PEI, High Temp Plate, or Textured PEI
Enclosed printers: Open the door and/or top cover during printing.
Additional setting for PETG as support:
Max volumetric speed → 10 mm³/s
|
|
1. Filament options
2. Edit
3. Filament tab
4. Select hotend - Main extruder in this case.
5. Adjust filament temperatures
6. Save the PLA support profile
|
1. Filament options
2. Edit
3. Filament tab
4. Select Support hotend - Auxiliary extruder in this case.
5. Adjust filament temperatures
6. Set the max. Volumetric speed to 10mm³/s
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

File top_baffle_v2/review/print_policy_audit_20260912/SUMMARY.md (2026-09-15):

# Print-policy audit — Obi-Wan and ND25FN-4 crescent

Audit date: 2026-09-12. Scope: current delivered 0.6 mm High Flow Tinmorry PETG-GF/PLA projects, their source policies, and actual sliced extrusion. This is an inspection report. No production STL, preset, or print project was changed; no printer was contacted.

**The supplied crescent body G-code contains retaining walls at all four magnet pockets. The current regular Obi-Wan projects specify three PLA interface layers, and fresh review slices reproduce three beneath their main supported surfaces.** The user's photograph documents a physical surface concern, but the actual file/version and printing layer have not been identified, so the cause of the photographed missing material remains unconfirmed.
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

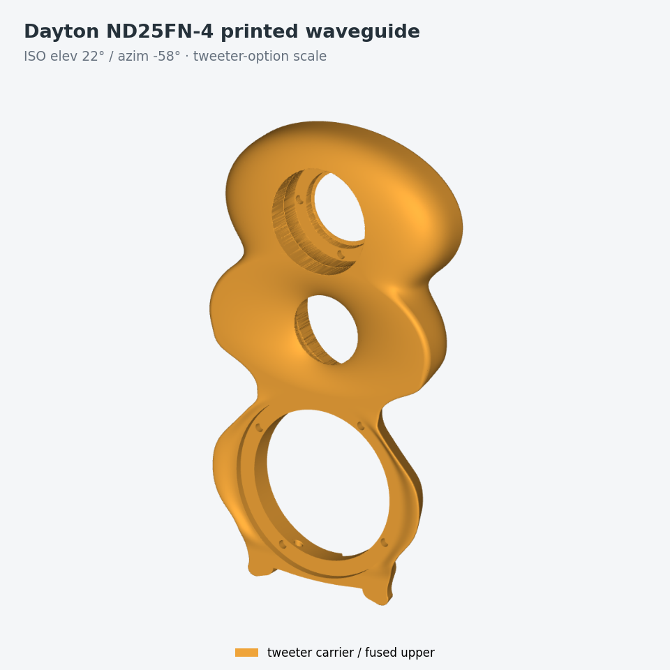
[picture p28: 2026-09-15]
top_baffle_v2/images/generated/iso/tweeter_nd25fn4_waveguide.png

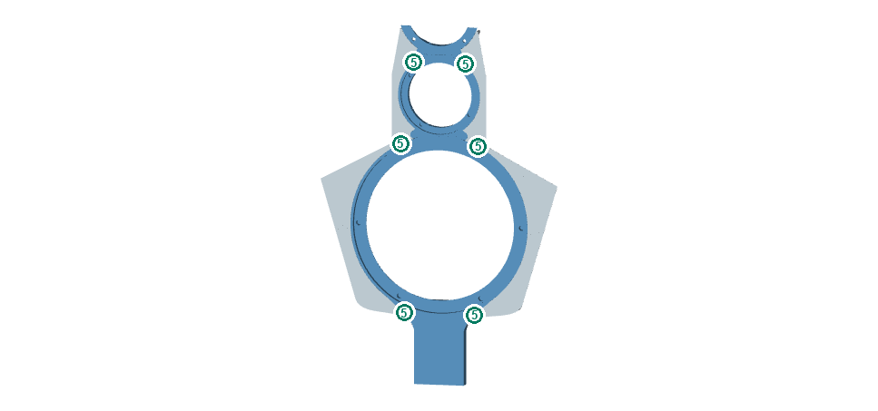
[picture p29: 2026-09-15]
top_baffle_v2/images/generated/catalog/tiles/assembly_obiwan_967x453.png

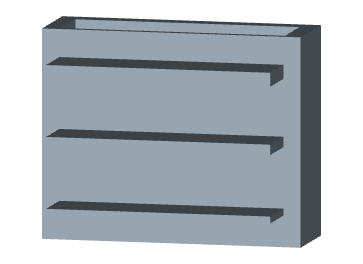
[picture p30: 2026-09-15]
top_baffle_v2/images/generated/catalog/tiles/supported_roof_and_wall_steps_363x264.png

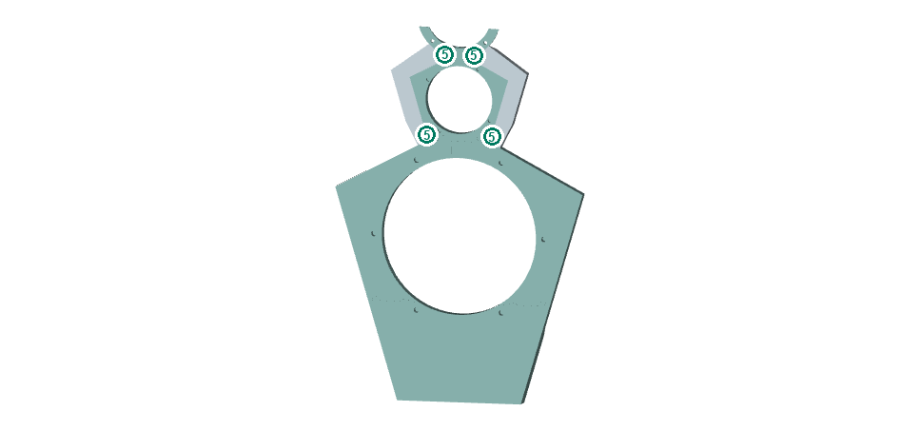
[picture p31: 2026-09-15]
top_baffle_v2/images/generated/catalog/tiles/assembly_slim_967x453.png

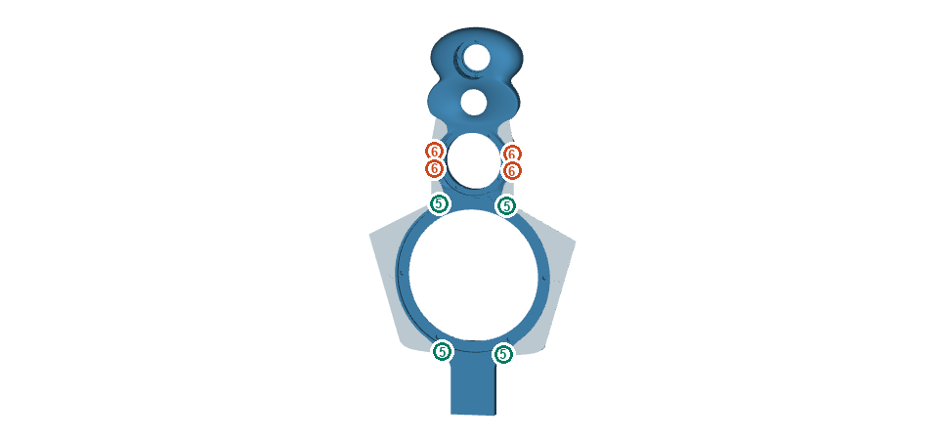
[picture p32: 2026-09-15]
top_baffle_v2/images/generated/catalog/tiles/assembly_v4_967x453.png

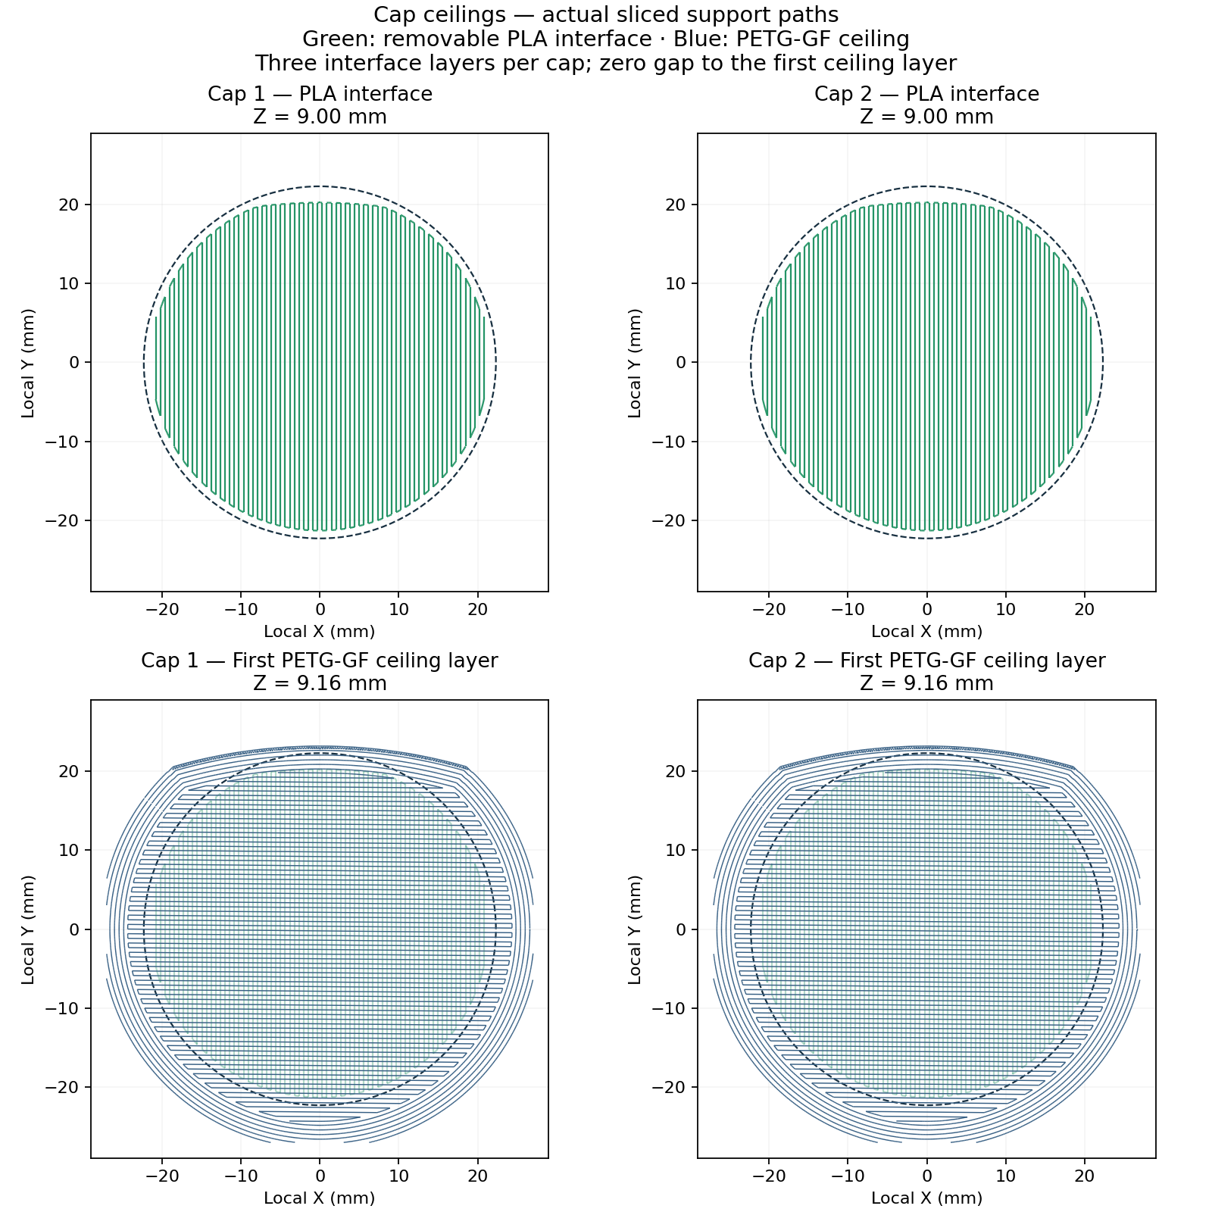
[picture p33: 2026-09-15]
top_baffle_v2/candidates/nd25fn4_crescent/print/cap_ceiling_support.png

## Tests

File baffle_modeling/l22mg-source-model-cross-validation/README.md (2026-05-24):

# L22MG naked-source cross-validation

This is a Juan-only leave-one-angle-out audit of equivalent-source models. Andres' mounted-baffle measurements are not read, fitted, or used for ranking.

## Method

- For each fold, one nonzero Juan angle is withheld from one side, while 0 deg remains in the training set as the normalization anchor.
- The source is fitted to the remaining naked front/rear polars and then evaluated at 0 deg plus the held-out angle.
- The scored quantity is normalized SPL, `SPL(theta)-SPL(0)`, so this checks angular source shape rather than absolute level.
- In-sample absolute source-fit RMS is reported separately because normalized shape cannot detect a uniform front/rear source gain error.
- In-sample phase RMS is reported separately because absolute SPL cannot detect a uniform rear timing or phase error.
- Asymmetric split-discrete rows use independent front/rear source depths and ring radii fitted from Juan only.
- Smoothness rows, when present, are adjacent-source Tikhonov penalties fitted from Juan only; they are not Andres-derived corrections.
- Active-surface annular rows fit normal-velocity amplitudes on an H1659-shaped source surface from Juan only. `annular` uses the H1659 profile annuli; `uniform-annular` uses configurable equal-area radial bands.
- Physical-diaphragm rows fit a single H1659 cone/surround prescribed-Neumann surface with four capped radial velocity shapes: piston, two cone bending/tilt shapes, and surround. They are Juan-only and do not use a rear scalar or Andres data.
- Physical rear-basket rows keep those four diaphragm modes coupled front/rear and add only a small low-order rear-side basket/directivity block. The rear block is Juan-only and cannot affect the front fit.
- Rear magnitude correction: none. The `dipole` rows only reconstruct rear phase as opposite polarity to front; magnitudes remain Juan's measured magnitudes.
- No Andres-derived gain, delay, rear correction, or baffle result is used.

## Inputs

- Juan source HDF5: `output/data/polar_data_juan_baffleless.h5` driver `L22MG (nude)`.
- Juan front notes: distance=0.5 m; height=unknown; first note=Measurement distance: 50 cm from driver..
- Juan rear notes: distance=0.5 m; height=unknown; first note=Measurement distance: 50 cm from driver..
- Equivalent-source reference radius: 0.5 m.
- Frequency grid: 300-2000 Hz at 24 points/octave.
- Candidate set: `compact`.

## Ranking

| Rank | Model | Phase | CV worst 300-1200 | CV front | CV rear | In-sample norm front/rear | In-sample abs front/rear | Phase front/rear deg | Failed folds |
|---:|---|---|---:|---:|---:|---:|---:|---:|---:|
| 1 | `axisymmetric-directivity-table-front-duplicate` | dipole | 1.229 | 1.229 | 0.984 | 0.000/0.569 | 0.000/0.569 | 0.000/68.034 | 0 |
| 2 | `diagnostic-legendre-o8` | dipole | 2.201 | 2.201 | 1.437 | 9.203/8.925 | 9.145/8.844 | 23.738/62.252 | 0 |
| 3 | `h1659-modal-compact2-az24-reg1e-06` | dipole | 3.298 | 3.298 | 2.877 | 2.631/1.226 | 2.578/0.974 | 15.048/13.734 | 0 |
| 4 | `h1659-modal-full2-az24-reg1e-06` | dipole | 3.300 | 3.300 | 2.911 | 2.682/1.261 | 2.629/1.007 | 15.134/13.889 | 0 |
| 5 | `measured-phase-h1659-modal-full2-az24-reg1e-06` | measured | 3.494 | 3.494 | 2.743 | 2.682/5.967 | 2.629/6.200 | 15.134/62.847 | 0 |
| 6 | `h1659-modal-compact3-az24-reg1e-06` | dipole | 3.768 | 3.768 | 3.300 | 2.215/1.171 | 2.184/0.934 | 14.029/13.529 | 0 |
| 7 | `h1659-modal-full4-az24-reg1e-06-svd1e-05` | dipole | 3.800 | 2.767 | 3.800 | 1.050/0.952 | 1.039/0.868 | 12.999/12.921 | 0 |
| 8 | `h1659-profile-ring-full-az24-reg1e-06-svd1e-05` | dipole | 3.842 | 3.288 | 3.842 | 0.855/1.091 | 0.845/1.030 | 12.298/12.298 | 0 |
| 9 | `h1659-profile-ring-full-az24-reg1e-06` | dipole | 3.844 | 3.286 | 3.844 | 0.855/1.090 | 0.845/1.030 | 12.298/12.297 | 0 |
| 10 | `h1659-profile-ring-compact-az24-reg1e-06` | dipole | 4.090 | 3.290 | 4.090 | 0.865/1.093 | 0.856/1.033 | 12.283/12.269 | 0 |
| 11 | `h1659-modal-full3-az24-reg1e-06` | dipole | 4.090 | 4.090 | 3.827 | 2.184/1.204 | 2.156/0.965 | 13.920/13.608 | 0 |
| 12 | `h1659-profile-ring-compact-az24-reg1e-06-svd1e-05` | dipole | 4.092 | 3.291 | 4.092 | 0.865/1.093 | 0.856/1.033 | 12.283/12.269 | 0 |

## Current BEM Source Rows

- Stable corrected-geometry source: `stable-split-discrete-d45-r0_40_75-reg1e-06` rank 25, CV worst-side RMS 8.622 dB over 300-1200 Hz (8.245 dB over 300-2000 Hz), in-sample normalized front/rear 2.541/2.642 dB and absolute front/rear 2.507/2.598 dB; phase front/rear 16.234/16.308 deg.
- Current wide/SVD diagnostic source: `current-wide-split-discrete-d45-r0_35_70_95-reg1e-06-svd1e-05` rank 26, CV worst-side RMS 8.810 dB over 300-1200 Hz (8.167 dB over 300-2000 Hz), in-sample normalized front/rear 2.404/2.500 dB and absolute front/rear 2.381/2.469 dB; phase front/rear 14.889/14.961 deg.
- Best asymmetric split-discrete source in this candidate set: `asym-split-discrete-f45-r55-r0_35_70_95-reg1e-06-svd1e-05` rank 17, CV worst-side RMS 6.793 dB over 300-1200 Hz (7.441 dB over 300-2000 Hz), in-sample normalized front/rear 2.404/2.656 dB and absolute front/rear 2.381/2.627 dB; phase front/rear 14.889/15.474 deg.
- Best active-surface radial source in this candidate set: not included in this candidate set.
- Best physical-diaphragm active source in this candidate set: not included in this candidate set.
- Best physical rear-basket active source in this candidate set: not included in this candidate set.

## Juan-Only Recommendation

- Thresholds: finite non-Legendre source, failed folds <= 0, in-sample side-worst normalized RMS <= 3.000 dB, in-sample side-worst absolute SPL RMS <= 3.000 dB, in-sample side-worst phase RMS <= 30.000 deg, and held-out side-worst normalized RMS <= 4.000 dB over 300-1200 Hz.
- First Juan-only recommended source candidate: `h1659-modal-compact2-az24-reg1e-06` rank 3; CV worst-side RMS 3.298 dB; in-sample side-worst normalized/absolute 2.631/2.578 dB; phase 15.048 deg.
- Current wide/SVD source recommendation status: `rejected_weak_cv`; Juan held-out side-worst normalized RMS 8.810 dB exceeds 4.000 dB.
- Recommendation is not Andres acceptance: any recommended source still needs a full mounted-baffle BEM run, mesh convergence, and validation against Andres before it can replace the current baseline.
- Active-surface rows are Juan-fitted H1659 prescribed-Neumann source surfaces. They are finite source models, but still acoustic open-surface fits rather than coupled elastic cone/suspension simulations.
- The axisymmetric directivity-table row is diagnostic-only: it rotates Juan's measured angular field, but does not resolve a unique finite 3D source distribution.

## Interpretation

- A low in-sample Juan fit with a high held-out-angle error is a source-model overfit warning before any baffle simulation is considered.
- This audit does not prove Andres acceptance. It only checks whether the naked-source representation generalizes across Juan's measured angles.
- If the current BEM source is not among the better cross-validated rows, source support/regularization should be treated as an active uncertainty in the mounted-baffle residuals.

## Files

- `source_cv_summary.csv` summarizes each candidate.
- `source_cv_recommendations.csv` records the Juan-only recommendation status and reason for each candidate.
- `source_cv_folds.csv` contains every held-out-angle fold.
- `plots/source_cv_worst_side_300_1200.png` ranks candidates by held-out normalized-polar error.
- `plots/source_cv_vs_insample.png` compares in-sample fit to cross-validation error.

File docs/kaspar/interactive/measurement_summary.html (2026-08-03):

# Measurement Summary

### Processing Configuration

Time Gating: Left: 0.0 ms, Right: 0.0 ms

Smoothing: 1/12

## LM L22MG (Kaspar DSP)

Angle | Measurement Name | Notes | Date | Processing Notes
F0 | LM 22MG | Delay 0.0231 ms (7.9 mm, 0.31 in) using estimated IR delay relative to Acoustic reference played from SPEAKER R with no timing offset Clock adjustment: 12.8 ppm Kaspar Reili LX521, outdoors, 1 m on-axis, 18-Oct-2022. UMIK-1 (18 dB gain, cal 7057283) with REW acoustic timing reference, ungated. Measured downstream of the active crossover/EQ: acoustic channel outputs, not raw drivers. Lower midrange alone, DSP channel gains at 0. | 2022-Oct-18 08:54:26

## System P1 (Kaspar DSP)

Angle | Measurement Name | Notes | Date | Processing Notes
F0 | All drivers Gain Profile 1 | RME=0, REW=-10dBFS P1, Woofer=-4.8, LM=-4.6, UM=2, Hi=-2 Delay -0.0190 ms (-6.5 mm, -0.26 in) using estimated IR delay relative to Acoustic reference played from SPEAKER R with no timing offset Clock adjustment: 13.7 ppm Kaspar Reili LX521, outdoors, 1 m on-axis, 18-Oct-2022. UMIK-1 (18 dB gain, cal 7057283) with REW acoustic timing reference, ungated. Measured downstream of the active crossover/EQ: acoustic channel outputs, not raw drivers. All drivers, gain profile 1: Woofer -4.8, LM -4.6, UM +2, HI -2 dB. | 2022-Oct-18 08:57:50

## System P2 (Kaspar DSP)

Angle | Measurement Name | Notes | Date | Processing Notes
F0 | All drivers Gain Profile 2 | RME=0, REW=-10dBFS P1, Woofer=-4.8, LM=-6.2, UM=2, Hi=-2 Delay -0.0183 ms (-6.3 mm, -0.25 in) using estimated IR delay relative to Acoustic reference played from SPEAKER R with no timing offset Clock adjustment: 14.1 ppm Kaspar Reili LX521, outdoors, 1 m on-axis, 18-Oct-2022. UMIK-1 (18 dB gain, cal 7057283) with REW acoustic timing reference, ungated. Measured downstream of the active crossover/EQ: acoustic channel outputs, not raw drivers. All drivers, gain profile 2: Woofer -4.8, LM -6.2, UM +2, HI -2 dB. | 2022-Oct-18 09:00:36

## System P3 (Kaspar DSP)

Angle | Measurement Name | Notes | Date | Processing Notes
F0 | All drivers Gain Profile 3 | RME=0, REW=-10dBFS P1, Woofer=-4.8, LM=-6.2, UM=-2.8, Hi=0 Delay -0.0146 ms (-5.0 mm, -0.2 in) using estimated IR delay relative to Acoustic reference played from SPEAKER R with no timing offset Clock adjustment: 14.7 ppm Kaspar Reili LX521, outdoors, 1 m on-axis, 18-Oct-2022. UMIK-1 (18 dB gain, cal 7057283) with REW acoustic timing reference, ungated. Measured downstream of the active crossover/EQ: acoustic channel outputs, not raw drivers. All drivers, gain profile 3: Woofer -4.8, LM -6.2, UM -2.8, HI 0 dB. | 2022-Oct-18 09:02:31

## Tweeter 27TFFNC (Kaspar DSP)

Angle | Measurement Name | Notes | Date | Processing Notes
F0 | Tweeter 27TFFNC | RME -2 REW -12dbfs GAIN=0 Delay -0.0412 ms (-14 mm, -0.56 in) using estimated IR delay relative to Acoustic reference played from SPEAKER R with no timing offset Clock adjustment: 12.4 ppm Kaspar Reili LX521, outdoors, 1 m on-axis, 18-Oct-2022. UMIK-1 (18 dB gain, cal 7057283) with REW acoustic timing reference, ungated. Measured downstream of the active crossover/EQ: acoustic channel outputs, not raw drivers. Tweeter alone, DSP channel gains at 0. | 2022-Oct-18 08:53:19

## UM MU10RB (Kaspar DSP)

Angle | Measurement Name | Notes | Date | Processing Notes
F0 | UM MU10RB | RME -2 REW -12dbfs GAIN=0 Delay -0.0482 ms (-17 mm, -0.65 in) using estimated IR delay relative to Acoustic reference played from SPEAKER R with no timing offset Clock adjustment: 11.6 ppm Kaspar Reili LX521, outdoors, 1 m on-axis, 18-Oct-2022. UMIK-1 (18 dB gain, cal 7057283) with REW acoustic timing reference, ungated. Measured downstream of the active crossover/EQ: acoustic channel outputs, not raw drivers. Upper midrange alone, DSP channel gains at 0. | 2022-Oct-18 08:51:41

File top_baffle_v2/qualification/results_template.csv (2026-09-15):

state | test | status | project_sha256 | slice_sha256 | filament_lot | drying | nozzle | test_conditions | acceptance_limit_before_test | measured_value | units | evidence_path | operator | date | notes
floor_stand | registration_coupon | PENDING
floor_stand | full_LM_fit | PENDING
floor_stand | native_cover_section | PENDING
floor_stand | support_removal | PENDING
floor_stand | purge_GF_to_PLA | PENDING
floor_stand | purge_PLA_to_GF | PENDING
floor_stand | magnet_skin_section | PENDING
floor_stand | magnetic_pull | PENDING
floor_stand | M2_insert | PENDING
floor_stand | M3_insert | PENDING
floor_stand | M5_insert | PENDING
floor_stand | cable_fishing | PENDING
floor_stand | coplanarity | PENDING
floor_stand | preload_creep | PENDING
floor_stand | loaded_1h | PENDING
floor_stand | loaded_24h | PENDING
floor_stand | loaded_long_term | PENDING
floor_stand | finished_photos | PENDING
floor_stand | acoustic_baseline_comparison | PENDING
no_floor_stand | registration_coupon | PENDING
no_floor_stand | full_LM_fit | PENDING
no_floor_stand | native_cover_section | PENDING
no_floor_stand | support_removal | PENDING
no_floor_stand | purge_GF_to_PLA | PENDING
no_floor_stand | purge_PLA_to_GF | PENDING
no_floor_stand | magnet_skin_section | PENDING
no_floor_stand | magnetic_pull | PENDING
no_floor_stand | M2_insert | PENDING
no_floor_stand | M3_insert | PENDING
no_floor_stand | M5_insert | PENDING
no_floor_stand | cable_fishing | PENDING
no_floor_stand | coplanarity | PENDING
no_floor_stand | preload_creep | PENDING
no_floor_stand | loaded_1h | PENDING
no_floor_stand | loaded_24h | PENDING
no_floor_stand | loaded_long_term | PENDING
no_floor_stand | finished_photos | PENDING
no_floor_stand | acoustic_baseline_comparison | PENDING

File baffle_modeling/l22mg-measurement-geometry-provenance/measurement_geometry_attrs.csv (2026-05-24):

target | hdf5_path | driver | group | angle_deg | notes_distance_m | attr_distance_m_before | attr_distance_m_final | distance_status | notes_height_m | attr_height_m_before | attr_height_m_final | notes_height_reference | attr_height_reference_before | attr_height_reference_final | height_reference_status | wrote_distance_attr | wrote_height_attr | wrote_height_reference_attr | note_excerpt
juan_l22mg_naked_front | output/data/polar_data_juan_baffleless.h5 | L22MG (nude) | angles | 0 | 0.5 | 0.5 | 0.5 | matches_expected | nan | nan | nan | l22mg | l22mg | l22mg | present | False | False | False | Measurement distance: 50 cm from driver. Mic height: L22MG/LM.
juan_l22mg_naked_front | output/data/polar_data_juan_baffleless.h5 | L22MG (nude) | angles | 15 | 0.5 | 0.5 | 0.5 | matches_expected | nan | nan | nan | l22mg | l22mg | l22mg | present | False | False | False | Measurement distance: 50 cm from driver. Mic height: L22MG/LM.
juan_l22mg_naked_front | output/data/polar_data_juan_baffleless.h5 | L22MG (nude) | angles | 30 | 0.5 | 0.5 | 0.5 | matches_expected | nan | nan | nan | l22mg | l22mg | l22mg | present | False | False | False | Measurement distance: 50 cm from driver. Mic height: L22MG/LM.
juan_l22mg_naked_front | output/data/polar_data_juan_baffleless.h5 | L22MG (nude) | angles | 45 | 0.5 | 0.5 | 0.5 | matches_expected | nan | nan | nan | l22mg | l22mg | l22mg | present | False | False | False | Measurement distance: 50 cm from driver. Mic height: L22MG/LM.
juan_l22mg_naked_front | output/data/polar_data_juan_baffleless.h5 | L22MG (nude) | angles | 60 | 0.5 | 0.5 | 0.5 | matches_expected | nan | nan | nan | l22mg | l22mg | l22mg | present | False | False | False | Measurement distance: 50 cm from driver. Mic height: L22MG/LM.
juan_l22mg_naked_front | output/data/polar_data_juan_baffleless.h5 | L22MG (nude) | angles | 75 | 0.5 | 0.5 | 0.5 | matches_expected | nan | nan | nan | l22mg | l22mg | l22mg | present | False | False | False | Measurement distance: 50 cm from driver. Mic height: L22MG/LM.
juan_l22mg_naked_front | output/data/polar_data_juan_baffleless.h5 | L22MG (nude) | angles | 90 | 0.5 | 0.5 | 0.5 | matches_expected | nan | nan | nan | l22mg | l22mg | l22mg | present | False | False | False | Measurement distance: 50 cm from driver. Mic height: L22MG/LM.
juan_l22mg_naked_rear | output/data/polar_data_juan_baffleless.h5 | L22MG (nude) | rear_angles | 0 | 0.5 | 0.5 | 0.5 | matches_expected | nan | nan | nan | l22mg | l22mg | l22mg | present | False | False | False | Measurement distance: 50 cm from driver. Mic height: L22MG/LM.
juan_l22mg_naked_rear | output/data/polar_data_juan_baffleless.h5 | L22MG (nude) | rear_angles | 15 | 0.5 | 0.5 | 0.5 | matches_expected | nan | nan | nan | l22mg | l22mg | l22mg | present | False | False | False | Measurement distance: 50 cm from driver. Mic height: L22MG/LM.
juan_l22mg_naked_rear | output/data/polar_data_juan_baffleless.h5 | L22MG (nude) | rear_angles | 30 | 0.5 | 0.5 | 0.5 | matches_expected | nan | nan | nan | l22mg | l22mg | l22mg | present | False | False | False | Measurement distance: 50 cm from driver. Mic height: L22MG/LM.
juan_l22mg_naked_rear | output/data/polar_data_juan_baffleless.h5 | L22MG (nude) | rear_angles | 45 | 0.5 | 0.5 | 0.5 | matches_expected | nan | nan | nan | l22mg | l22mg | l22mg | present | False | False | False | Measurement distance: 50 cm from driver. Mic height: L22MG/LM.
juan_l22mg_naked_rear | output/data/polar_data_juan_baffleless.h5 | L22MG (nude) | rear_angles | 60 | 0.5 | 0.5 | 0.5 | matches_expected | nan | nan | nan | l22mg | l22mg | l22mg | present | False | False | False | Measurement distance: 50 cm from driver. Mic height: L22MG/LM.
juan_l22mg_naked_rear | output/data/polar_data_juan_baffleless.h5 | L22MG (nude) | rear_angles | 75 | 0.5 | 0.5 | 0.5 | matches_expected | nan | nan | nan | l22mg | l22mg | l22mg | present | False | False | False | Measurement distance: 50 cm from driver. Mic height: L22MG/LM.
juan_l22mg_naked_rear | output/data/polar_data_juan_baffleless.h5 | L22MG (nude) | rear_angles | 90 | 0.5 | 0.5 | 0.5 | matches_expected | nan | nan | nan | l22mg | l22mg | l22mg | present | False | False | False | Measurement distance: 50 cm from driver. Mic height: L22MG/LM.
juan_l22mg_top_front | output/data/polar_data_juan_lx521_top_raw.h5 | L22MG (LX521 top raw) | angles | 0 | 0.5 | 0.5 | 0.5 | matches_expected | nan | nan | nan | l22mg | l22mg | l22mg | matches_expected | False | False | False | PB -40 DB
juan_l22mg_top_front | output/data/polar_data_juan_lx521_top_raw.h5 | L22MG (LX521 top raw) | angles | 15 | 0.5 | 0.5 | 0.5 | matches_expected | nan | nan | nan | l22mg | l22mg | l22mg | matches_expected | False | False | False | Measurement distance: 50 cm. Mic height: L22MG/LM. LX521 top baffle mounted; raw/no crossover/no EQ.
juan_l22mg_top_front | output/data/polar_data_juan_lx521_top_raw.h5 | L22MG (LX521 top raw) | angles | 30 | 0.5 | 0.5 | 0.5 | matches_expected | nan | nan | nan | l22mg | l22mg | l22mg | matches_expected | False | False | False | Measurement distance: 50 cm. Mic height: L22MG/LM. LX521 top baffle mounted; raw/no crossover/no EQ.
juan_l22mg_top_front | output/data/polar_data_juan_lx521_top_raw.h5 | L22MG (LX521 top raw) | angles | 45 | 0.5 | 0.5 | 0.5 | matches_expected | nan | nan | nan | l22mg | l22mg | l22mg | matches_expected | False | False | False | Measurement distance: 50 cm. Mic height: L22MG/LM. LX521 top baffle mounted; raw/no crossover/no EQ.
juan_l22mg_top_front | output/data/polar_data_juan_lx521_top_raw.h5 | L22MG (LX521 top raw) | angles | 60 | 0.5 | 0.5 | 0.5 | matches_expected | nan | nan | nan | l22mg | l22mg | l22mg | matches_expected | False | False | False | Measurement distance: 50 cm. Mic height: L22MG/LM. LX521 top baffle mounted; raw/no crossover/no EQ.
juan_l22mg_top_front | output/data/polar_data_juan_lx521_top_raw.h5 | L22MG (LX521 top raw) | angles | 75 | 0.5 | 0.5 | 0.5 | matches_expected | nan | nan | nan | l22mg | l22mg | l22mg | matches_expected | False | False | False | Measurement distance: 50 cm. Mic height: L22MG/LM. LX521 top baffle mounted; raw/no crossover/no EQ.
juan_l22mg_top_front | output/data/polar_data_juan_lx521_top_raw.h5 | L22MG (LX521 top raw) | angles | 90 | 0.5 | 0.5 | 0.5 | matches_expected | nan | nan | nan | l22mg | l22mg | l22mg | matches_expected | False | False | False | Measurement distance: 50 cm. Mic height: L22MG/LM. LX521 top baffle mounted; raw/no crossover/no EQ.
juan_l22mg_top_rear | output/data/polar_data_juan_lx521_top_raw.h5 | L22MG (LX521 top raw) | rear_angles | 0 | 0.5 | 0.5 | 0.5 | matches_expected | nan | nan | nan | l22mg | l22mg | l22mg | matches_expected | False | False | False | Measurement distance: 50 cm. Mic height: L22MG/LM. LX521 top baffle mounted; raw/no crossover/no EQ.
juan_l22mg_top_rear | output/data/polar_data_juan_lx521_top_raw.h5 | L22MG (LX521 top raw) | rear_angles | 15 | 0.5 | 0.5 | 0.5 | matches_expected | nan | nan | nan | l22mg | l22mg | l22mg | matches_expected | False | False | False | Measurement distance: 50 cm. Mic height: L22MG/LM. LX521 top baffle mounted; raw/no crossover/no EQ.
juan_l22mg_top_rear | output/data/polar_data_juan_lx521_top_raw.h5 | L22MG (LX521 top raw) | rear_angles | 30 | 0.5 | 0.5 | 0.5 | matches_expected | nan | nan | nan | l22mg | l22mg | l22mg | matches_expected | False | False | False | Measurement distance: 50 cm. Mic height: L22MG/LM. LX521 top baffle mounted; raw/no crossover/no EQ.
juan_l22mg_top_rear | output/data/polar_data_juan_lx521_top_raw.h5 | L22MG (LX521 top raw) | rear_angles | 45 | 0.5 | 0.5 | 0.5 | matches_expected | nan | nan | nan | l22mg | l22mg | l22mg | matches_expected | False | False | False | Measurement distance: 50 cm. Mic height: L22MG/LM. LX521 top baffle mounted; raw/no crossover/no EQ.
juan_l22mg_top_rear | output/data/polar_data_juan_lx521_top_raw.h5 | L22MG (LX521 top raw) | rear_angles | 60 | 0.5 | 0.5 | 0.5 | matches_expected | nan | nan | nan | l22mg | l22mg | l22mg | matches_expected | False | False | False | Measurement distance: 50 cm. Mic height: L22MG/LM. LX521 top baffle mounted; raw/no crossover/no EQ.
juan_l22mg_top_rear | output/data/polar_data_juan_lx521_top_raw.h5 | L22MG (LX521 top raw) | rear_angles | 75 | 0.5 | 0.5 | 0.5 | matches_expected | nan | nan | nan | l22mg | l22mg | l22mg | matches_expected | False | False | False | Measurement distance: 50 cm. Mic height: L22MG/LM. LX521 top baffle mounted; raw/no crossover/no EQ.
juan_l22mg_top_rear | output/data/polar_data_juan_lx521_top_raw.h5 | L22MG (LX521 top raw) | rear_angles | 90 | 0.5 | 0.5 | 0.5 | matches_expected | nan | nan | nan | l22mg | l22mg | l22mg | matches_expected | False | False | False | Measurement distance: 50 cm. Mic height: L22MG/LM. LX521 top baffle mounted; raw/no crossover/no EQ.
juan_l10neo_top_front | output/data/polar_data_juan_lx521_top_raw.h5 | L10NEO (LX521 top raw) | angles | 0 | 0.5 | 0.5 | 0.5 | matches_expected | nan | nan | nan | l22mg | l22mg | l22mg | matches_expected | False | False | False | L10NEO (SERIAL A) EN TOP BAFFLE LX521 NO EQ
juan_l10neo_top_front | output/data/polar_data_juan_lx521_top_raw.h5 | L10NEO (LX521 top raw) | angles | 15 | 0.5 | 0.5 | 0.5 | matches_expected | nan | nan | nan | l22mg | l22mg | l22mg | matches_expected | False | False | False | Measurement distance: 50 cm. Mic height: L22MG/LM. LX521 top baffle mounted; raw/no crossover/no EQ.
juan_l10neo_top_front | output/data/polar_data_juan_lx521_top_raw.h5 | L10NEO (LX521 top raw) | angles | 30 | 0.5 | 0.5 | 0.5 | matches_expected | nan | nan | nan | l22mg | l22mg | l22mg | matches_expected | False | False | False | Measurement distance: 50 cm. Mic height: L22MG/LM. LX521 top baffle mounted; raw/no crossover/no EQ.
juan_l10neo_top_front | output/data/polar_data_juan_lx521_top_raw.h5 | L10NEO (LX521 top raw) | angles | 45 | 0.5 | 0.5 | 0.5 | matches_expected | nan | nan | nan | l22mg | l22mg | l22mg | matches_expected | False | False | False | Measurement distance: 50 cm. Mic height: L22MG/LM. LX521 top baffle mounted; raw/no crossover/no EQ.
juan_l10neo_top_front | output/data/polar_data_juan_lx521_top_raw.h5 | L10NEO (LX521 top raw) | angles | 60 | 0.5 | 0.5 | 0.5 | matches_expected | nan | nan | nan | l22mg | l22mg | l22mg | matches_expected | False | False | False | Measurement distance: 50 cm. Mic height: L22MG/LM. LX521 top baffle mounted; raw/no crossover/no EQ.
juan_l10neo_top_front | output/data/polar_data_juan_lx521_top_raw.h5 | L10NEO (LX521 top raw) | angles | 75 | 0.5 | 0.5 | 0.5 | matches_expected | nan | nan | nan | l22mg | l22mg | l22mg | matches_expected | False | False | False | Measurement distance: 50 cm. Mic height: L22MG/LM. LX521 top baffle mounted; raw/no crossover/no EQ.
juan_l10neo_top_front | output/data/polar_data_juan_lx521_top_raw.h5 | L10NEO (LX521 top raw) | angles | 90 | 0.5 | 0.5 | 0.5 | matches_expected | nan | nan | nan | l22mg | l22mg | l22mg | matches_expected | False | False | False | Measurement distance: 50 cm. Mic height: L22MG/LM. LX521 top baffle mounted; raw/no crossover/no EQ.
juan_l10neo_top_rear | output/data/polar_data_juan_lx521_top_raw.h5 | L10NEO (LX521 top raw) | rear_angles | 0 | 0.5 | 0.5 | 0.5 | matches_expected | nan | nan | nan | l22mg | l22mg | l22mg | matches_expected | False | False | False | Measurement distance: 50 cm. Mic height: L22MG/LM. LX521 top baffle mounted; raw/no crossover/no EQ.
juan_l10neo_top_rear | output/data/polar_data_juan_lx521_top_raw.h5 | L10NEO (LX521 top raw) | rear_angles | 15 | 0.5 | 0.5 | 0.5 | matches_expected | nan | nan | nan | l22mg | l22mg | l22mg | matches_expected | False | False | False | Measurement distance: 50 cm. Mic height: L22MG/LM. LX521 top baffle mounted; raw/no crossover/no EQ.
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

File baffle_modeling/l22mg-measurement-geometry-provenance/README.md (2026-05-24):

# L22MG Measurement Geometry Provenance

This report audits where the measurement geometry is stored in the HDF5 files used by the L22MG workflow.

- HDF5 write mode: enabled.
- Structured attrs checked: `measurement_distance_m`, `measurement_height_m`, and `measurement_height_reference`.
- Note-derived fields are parsed from each angle group's `notes` attr and promoted only when the structured attr is missing or an explicit overwrite is requested.

## Summary

| target | HDF5 | group | angles | distance final | distance status | height reference final | height status | wrote attrs |
| --- | --- | --- | ---: | --- | --- | --- | --- | ---: |
| `juan_l22mg_naked_front` | `output/data/polar_data_juan_baffleless.h5` | `L22MG (nude)/angles` | 7 | 0.5 m | matches_expected | l22mg | present | 0 |
| `juan_l22mg_naked_rear` | `output/data/polar_data_juan_baffleless.h5` | `L22MG (nude)/rear_angles` | 7 | 0.5 m | matches_expected | l22mg | present | 0 |
| `juan_l22mg_top_front` | `output/data/polar_data_juan_lx521_top_raw.h5` | `L22MG (LX521 top raw)/angles` | 7 | 0.5 m | matches_expected | l22mg | matches_expected | 0 |
| `juan_l22mg_top_rear` | `output/data/polar_data_juan_lx521_top_raw.h5` | `L22MG (LX521 top raw)/rear_angles` | 7 | 0.5 m | matches_expected | l22mg | matches_expected | 0 |
| `juan_l10neo_top_front` | `output/data/polar_data_juan_lx521_top_raw.h5` | `L10NEO (LX521 top raw)/angles` | 7 | 0.5 m | matches_expected | l22mg | matches_expected | 0 |
| `juan_l10neo_top_rear` | `output/data/polar_data_juan_lx521_top_raw.h5` | `L10NEO (LX521 top raw)/rear_angles` | 7 | 0.5 m | matches_expected | l22mg | matches_expected | 0 |
| `juan_l22_l10_tweeters_top_front` | `output/data/polar_data_juan_lx521_top_raw.h5` | `L22MG+L10NEO+Tweeters (LX521 top raw)/angles` | 7 | 0.5 m | matches_expected | l22mg | matches_expected | 0 |
| `juan_l22_l10_tweeters_top_rear` | `output/data/polar_data_juan_lx521_top_raw.h5` | `L22MG+L10NEO+Tweeters (LX521 top raw)/rear_angles` | 7 | 0.5 m | matches_expected | l22mg | matches_expected | 0 |
| `andres_l22mg_published_parity` | `output/data/polar_data_andres_early_peak_legacy.h5` | `L22MG/angles` | 10 | 1 m | matches_expected | um | matches_expected | 0 |
| `andres_l22mg_legacy_strongest_diagnostic` | `output/data/polar_data_andres.h5` | `L22MG/angles` | 10 | 1 m | matches_expected | um | matches_expected | 0 |

## Interpretation

- Juan's naked L22MG front and rear measurements are structured as 0.50 m source-radius measurements in `output/data/polar_data_juan_baffleless.h5`.
- Juan's LX521 top-baffle raw L22MG, L10NEO, and multi-driver captures are structured as 0.50 m measurements at LM/L22MG height in `output/data/polar_data_juan_lx521_top_raw.h5`.
- Andres' canonical published-parity L22MG target is structured as 1.0 m horizontal radius at UM height (`measurement_height_reference=um`).
- These attrs are provenance for geometry setup only; they do not change the published-parity pressure data or make diagnostic target files acceptance targets.

Files: `measurement_geometry_attrs.csv`.

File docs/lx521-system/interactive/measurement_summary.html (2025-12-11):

# Measurement Summary

### Processing Configuration

Time Gating: Left: 0.5 ms, Right: 3.0 ms

Smoothing: None

## LX521 HIGH MID INV ORIGINAL

Angle | Measurement Name | Notes | Date | Processing Notes
F0 | LX521 0 DEG FRONT | LX521 HIGH MID INV ORIGINAL 0 GRADOS 50 CMS FRONTAL Y 104 ALTURA | 2024-Nov-09 22:17:09
F15 | LX521 15 DEG FRONT | LX521 HIGH MID INV ORIGINAL 15 GRADOS | 2024-Nov-09 22:21:52
F30 | LX521 30 DEG FRONT | LX521 HIGH MID INV ORIGINAL 30 GRADOS | 2024-Nov-09 22:23:58
F45 | LX521 45 DEG FRONT | LX521 HIGH MID INV ORIGINAL 45 GRADOS | 2024-Nov-09 22:25:31
F60 | LX521 60 DEG FRONT | LX521 HIGH MID INV ORIGINAL 60 GRADOS | 2024-Nov-09 22:26:46
F75 | LX521 75 DEG FRONT | LX521 HIGH MID INV ORIGINAL 75 GRADOS | 2024-Nov-09 22:28:15
F90 | LX521 90 DEG FRONT | LX521 HIGH MID INV ORIGINAL 90 GRADOS | 2024-Nov-09 22:29:58
R0 | LX521 0 DEG REAR | LX521 HIGH MID INV ORIGINAL O GRADOS REAR | 2024-Nov-09 22:37:09
R15 | LX521 15 DEG REAR | LX521 HIGH MID INV ORIGINAL 15 GRADOS REAR | 2024-Nov-09 22:39:07
R30 | LX521 30 DEG REAR | LX521 HIGH MID INV ORIGINAL 30 GRADOS REAR | 2024-Nov-09 22:43:12
R45 | LX521 45 DEG REAR | LX521 HIGH MID INV ORIGINAL 45 GRADOS REAR | 2024-Nov-09 22:44:52
R60 | LX521 60 DEG REAR | LX521 HIGH MID INV ORIGINAL 60 GRADOS REAR | 2024-Nov-09 22:46:58
R75 | LX521 75 DEG REAR | LX521 HIGH MID INV ORIGINAL 75 GRADOS REAR | 2024-Nov-09 22:48:28
R90 | LX521 90 DEG REAR | LX521 HIGH MID INV ORIGINAL 90 GRADOS REAR | 2024-Nov-09 22:51:08

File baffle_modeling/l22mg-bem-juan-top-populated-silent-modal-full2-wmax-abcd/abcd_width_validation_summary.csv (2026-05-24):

variant | wmax_mm | note | norm_rms_300_1200 | norm_rms_exact_300_75_removed | norm_rms_deep_null_cluster_removed | norm_rms_target_above_minus20 | norm_rms_through60 | norm_rms_through80 | worst_error_db | worst_freq_hz | worst_angle_deg | mean_f90_minus_f0_db
A | 205.0 | closest shoulder | 4.208945771898522 | 4.206809410197652 | 3.8328596893323454 | 1.911739832805883 | 1.2654043850358194 | 3.5359244563518986 | 18.080921869791197 | 300.2929915487766 | 75.0 | -17.710343577102268
B | 305.0 | actual LX521 | 4.244133457466221 | 4.241915186696222 | 3.8523256970293747 | 1.5867582846375516 | 1.0009753877472303 | 3.507474443316715 | 18.486587112061088 | 300.2929915487766 | 75.0 | -16.47741209781709
C | 405.0 | wide shoulder | 3.904391729731365 | 3.9020429737567093 | 3.4918464741047974 | 1.3234115087040772 | 0.6054242982081479 | 3.2380216890940647 | 18.181767200929798 | 300.2929915487766 | 75.0 | -17.410329302700408
D | 505.0 | widest shoulder | 3.7798155336858428 | 3.777367225975754 | 3.351540071592489 | 1.3736567382268372 | 0.524211443215842 | 3.1558342791818585 | 18.234300439116595 | 300.2929915487766 | 75.0 | -18.089992897903635

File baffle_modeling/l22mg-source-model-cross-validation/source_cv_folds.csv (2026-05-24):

model_id | source_model | rear_phase_mode | side | holdout_angle_deg | fold_status | error | cv_norm_rms_db_300_1200 | cv_norm_mean_db_300_1200 | cv_norm_max_abs_db_300_1200 | cv_norm_rms_db_300_2000 | cv_norm_mean_db_300_2000 | cv_norm_max_abs_db_300_2000
axisymmetric-directivity-table-front-duplicate | axisymmetric-directivity | dipole | front | 15.0 | ok |  | 0.39099200135820433 | -0.3786177670333676 | 0.6679900197956243 | 0.6162303557379316 | -0.5403811543852763 | 1.318272676307231
axisymmetric-directivity-table-front-duplicate | axisymmetric-directivity | dipole | front | 30.0 | ok |  | 0.42963857695282026 | -0.41968262892472347 | 0.6539970053307513 | 0.6858638353210008 | -0.5981730268036826 | 1.3771557453712688
axisymmetric-directivity-table-front-duplicate | axisymmetric-directivity | dipole | front | 45.0 | ok |  | 0.5764260500129381 | -0.5659818119439957 | 1.031945516905381 | 0.941169780481929 | -0.8120919523984855 | 2.1292660924322178
axisymmetric-directivity-table-front-duplicate | axisymmetric-directivity | dipole | front | 60.0 | ok |  | 0.8331189373199294 | -0.68191778044452 | 1.0925498667758333 | 0.7942851318946458 | -0.3489209582565136 | 1.1520537738181815
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

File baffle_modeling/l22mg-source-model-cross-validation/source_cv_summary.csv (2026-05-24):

rank | model_id | source_model | rear_phase_mode | legendre_order | half_depth_mm | ring_radii_mm | front_depth_mm | rear_depth_mm | front_ring_radii_mm | rear_ring_radii_mm | source_point_profile | regularization | smoothness_regularization | svd_rcond | active_surface_mode_count | active_surface_basis_kind | active_surface_azimuth_count | active_surface_quadrature_order | active_surface_side_gap_mm | active_surface_rear_basket_mode_count | source_count | basis_count | acoustic_center_offset_mm | reference_radius_m | failed_fold_count | fit_front_rms_db_300_1200 | fit_rear_rms_db_300_1200 | fit_front_rms_db_300_2000 | fit_rear_rms_db_300_2000 | fit_front_norm_rms_db_300_1200 | fit_rear_norm_rms_db_300_1200 | fit_front_norm_rms_db_300_2000 | fit_rear_norm_rms_db_300_2000 | fit_front_complex_rel_rms_300_1200 | fit_rear_complex_rel_rms_300_1200 | fit_front_complex_rel_rms_300_2000 | fit_rear_complex_rel_rms_300_2000 | fit_front_phase_rms_deg_300_1200 | fit_rear_phase_rms_deg_300_1200 | fit_front_phase_rms_deg_300_2000 | fit_rear_phase_rms_deg_300_2000 | cv_front_fold_rms_db_300_1200 | cv_front_worst_fold_rms_db_300_1200 | cv_rear_fold_rms_db_300_1200 |
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

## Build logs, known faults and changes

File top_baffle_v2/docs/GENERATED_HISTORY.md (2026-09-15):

# Generated-file history

The 2026-09-15 cleanup trims only the 18 unpublished commits after
`3ae20d9`. Published history stays unchanged. Every original source revision,
author, date and commit message is retained; the commit IDs change because
archived and superseded generated files have been removed from their trees.

The pre-H2C source checkpoint is **`e3962a4`**, formerly `c261f32`.
The original checkpoint labels in frozen catalogs and audit reports remain
unchanged so the recorded evidence is not silently rewritten. Use the mapping
below to find the corresponding published source revision. Intermediate
commits contain source history, not a complete collection of past binary
releases; rebuild old exports from the matching source when needed.

## What remains

- Current H2C and earlier printer-facing meshes, editable projects and sliced
  projects. Their geometry and process bytes are unchanged by this cleanup.
- Current CAD authorities, native inputs, profiles, print policies, reports,
  manifests, curated review images and qualification evidence.
- The original retained design package and manufacturer references. The ZIP
  is an immutable source input, not an additional release bundle.
- Explicit review inputs needed by the H2C build, including the Dayton support
  blockers, infill modifier, discovery project and accessory preparation.

Archived review slices, raw G-code, redundant workspaces, trial export meshes
and superseded generated versions are omitted from the unpublished history.
Their source/configuration and compact reports remain. Historical reports may
name local-only workspaces and record hashes of files no longer distributed.
The current H2C catalog references retained, hash-verified inputs.

The original 18 commits are recoverable on the original workstation through
`refs/backup/baffle-before-generated-history-trim-20260915`. Files removed from
tracking remain locally available and ignored. This recovery ref is not
pushed. Nothing is removed from already-published history.

## Storage policy

Current print artifacts use ordinary Git. No CAD, STL, 3MF, G-code or image
LFS rules are added; the repository's existing `.mdat` rule is unchanged.
Archive and slicer-cache exclusions are in the project `.gitignore`, with
explicit exceptions for live inputs. Keep one current reviewed export on the
release shelf and keep disposable slicing workspaces out of commits.

The retained outgoing blob storage estimate fell from 4.77 GB to 1.51 GB
(68% less). These are local stored-blob totals, not an exact network-pack size.
Already-published data and the local recovery copy are unaffected.

## Fresh-checkout validation

From `top_baffle_v2`, use the project's Python environment. The retained
source package is extracted locally and verified before importing the Dayton
geometry helpers; extraction does not rebuild the approved meshes:

```sh
PYTHONPATH=candidates/nd25fn4_crescent python3 -c 'from rebuild import verify_package; print(verify_package())'
python3 scripts/validate_h2c_catalog.py
```

The H2C validator restores disposable plain-G-code caches from the qualified
`.gcode.3mf` files after verifying their hashes. It checks all 45 print jobs,
including the 45 editable projects, 45 slices, 40 distinct meshes and their
retained input authorities. No printer connection is needed.

The earlier artifact facade also links ignored oversized CAD assemblies and
a graded wing plate. A fresh checkout needs to regenerate those optional
local exports before `scripts/build_artifact_catalog.py --check` can pass.
They are not required by the H2C print catalog. See
[repository structure](REPOSITORY_STRUCTURE.md#cleanup-policy).

## Commit mapping

| Original local ID | Rewritten ID | Source change |
|---|---|---|
| `d6ce1e1` | [`8b89640`](https://github.com/antorsae/lx/commit/8b896409f81cc6a8b751b2106a22c53f7b5eca5f) | Slow PETG-GF bridges to 12 mm/s so large duct roofs stop pitting |
| `b32db8d` | [`308f01e`](https://github.com/antorsae/lx/commit/308f01e4c7121c4da5113ece1b3d5df1afa5c059) | Close the two print openings on the keyed floor stand |
| `01dc042` | [`0ea2bf6`](https://github.com/antorsae/lx/commit/0ea2bf62e15d6f324666f6b42d719bb6155a7a31) | Extend the floor stand's flat foot to 130 mm so it cannot tip forward |
| `e03cbc2` | [`e6c9061`](https://github.com/antorsae/lx/commit/e6c9061feb381b1bb16a2dc7f7b1f4925c83ec70) | Move the NL8 service opening to the foot's underside and add an M5 floor anchor |
| `6b8b336` | [`f9f6fa4`](https://github.com/antorsae/lx/commit/f9f6fa4e1ca7790e3c2f7d6f154a5550fcadfeed) | Hollow the boss, anchor the stand with two M5 inserts, bury the LM exit |
| `40ad12b` | [`5c3ddce`](https://github.com/antorsae/lx/commit/5c3ddce812155291de61eede793583f541e6b1c9) | Cut the duct voids as 16-gons so their crowns print in GF-PETG |
| `c4922ec` | [`9dae75f`](https://github.com/antorsae/lx/commit/9dae75fe494c5a8e48bf82edd371246f6b70fa0c) | Remove stale NL8 concept scratch from review |
| `23b0533` | [`d6377a9`](https://github.com/antorsae/lx/commit/d6377a92d63bf660d74b933a1f2c5e5e7a70702e) | File the Purifi, SEAS, Peerless, Dayton and Tectonic driver references under vendor/ with provenance |
| `644839c` | [`d502444`](https://github.com/antorsae/lx/commit/d502444376f10f47943ea987c0e95ea091ac0e5b) | Add the candidate Purifi PTT1.3 dipole crescent generator and artifacts |
| `f6f8ac9` | [`c8d68ee`](https://github.com/antorsae/lx/commit/c8d68eeda07e0f3acf2edf6e4d9608acca2e0c87) | Fasten and duct the PTT1.3 dipole crescent: M3 inserts, minimal ducted foot |
| `77a0a1c` | [`51271ff`](https://github.com/antorsae/lx/commit/51271ff97a52f9f0bc30b9035b10c4e67c07578c) | Route the crescent cables as twin buried arcs and mate the released UM joint |
| `c4a25d8` | [`17a79a3`](https://github.com/antorsae/lx/commit/17a79a3f2b19453cccdc6c17269615897e7b9336) | Bore the driver inserts with the released M3 receiver recipe, mesh-verified |
| `e9e46b4` | [`8a2c66a`](https://github.com/antorsae/lx/commit/8a2c66aae0cb8acd8b1be91f914b6ad9839b1e80) | Thread-form the rim screws into printable pilots and fix the phantom probe |
| `0f0ce1f` | [`d5c7e8f`](https://github.com/antorsae/lx/commit/d5c7e8f406e5c0df63ca8de5713ce964e44d3e03) | Catalog every heat-set insert site and the three insert types |
| `c261f32` | [`e3962a4`](https://github.com/antorsae/lx/commit/e3962a4811035ac1802c3f43451cf9236337062f) | Checkpoint baffle experiments, V4 print revisions and H2 printer studies |
| `07206ed` | [`bda62b3`](https://github.com/antorsae/lx/commit/bda62b3bc20cc0a0e16e148d706a7672a83e43bd) | Generate H2C baffle parts and validated dual-nozzle print release |
| `f35010c` | [`ef44120`](https://github.com/antorsae/lx/commit/ef4412006894812f5aae7a5e22a1be361040f49f) | Document three tweeter families and name Dayton waveguide deliverables |
| `3f835e3` | [`e0bf1cc`](https://github.com/antorsae/lx/commit/e0bf1cc24f806127ffec6a771eefcf6e184bfd10) | Keep local credentials out of baffle release artifacts |

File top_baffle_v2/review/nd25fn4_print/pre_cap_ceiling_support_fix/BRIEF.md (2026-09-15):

# Current revision: insert support exclusion and fair UM / tweeter waist

Cover all twelve insert sites with bore-sized nonprinting support blockers: four UM driver inserts, two LM-to-UM receivers and three inserts on each tweeter, including their narrow tip reliefs. Use the existing Obi-Wan LM and UM projects as the reference for axial coverage and the 0.25 mm clearance plus boolean margin. Inspect the final support extrusion against the actual bore volumes, not just the red preview volumes.

Remove the visible front-edge nick and rear outer-shoulder dent between UM and the lower tweeter. Correct invalid rear-height sampling before constructing the spline; keep its endpoint/derivative witnesses inside the tweeter footprint. Give the outer waist one continuous radial transition into the tweeter instead of exposing the legacy circular cutoff. Preserve the approved driver positions, seats, retention hardware, buried magnets, cable lumens and the flush Z18.30 LM interface. Check exported front/rear/depth profiles through the entire Y414–450 transition, including the outermost shoulders previously outside the curvature checks. Regenerate matching wings as needed, all affected STL/3MF files, actual comparison views and checked viewer links. Keep the existing print preset and regional infill. No ZIP or printer action.

# Previous revision: flush UM / LM interface and updated print jobs

Meet the existing LM top front face at installed Z18.30 mm, without hiding any of its upper front silhouette. Remove the raised overlapping apron. Preserve the exact M3 axes, blind receiver floors, 0.20 mm half-lap clearance, M2 bearing and closed cable handoff in both LM configurations. Keep the approved organic body above the joint: fade the lower rim rise smoothly from zero at Y322 to the existing bowl at Y336 with matched slope and curvature. The exact LM contour takes priority over the raster reference below Y322.

Refit both upper-wing families around the flush foot, retaining the LM magnet cavity and lower split interfaces. Validate actual exported meshes for zero interference, zero LM front-face occlusion, coplanar seam witnesses and unchanged hardware. Inspect actual orthographic front, side and front/below renders and return a working relative-path CAD Viewer link.

Regenerate the affected native P2S 0.6 HF Tinmorry PETG-GF / PLA-interface jobs using the frozen regular Obi-Wan UM process. Keep 100% zig-zag UM infill and the 15% gyroid tweeter modifier above installed Y421. Recompute magnet pauses from the new slices and verify the final print meshes against both LM tops. Publish individual STL and sliced 3MF files, with updated provenance and views. No ZIP, upload or printer start.

# Previous revision: reproduce the latest UM reference outline

Follow `design_inputs/nd25fn4_UM_reference_front_latest.png`, including the actual front silhouette and the broad, smooth face. This overrides the preceding guessed outline. Scale its proportions from the MU10 flange (49.3 mm radius); treat raster-derived dimensions as design intent, not measured hardware. Trace the wider middle, earlier inward sweep below the driver, lower waist that opens slightly into a unified rounded base, and lower upper-neck transition. Compare source-derived front renders and actual projected STL boundaries with the reference using the driver axis/diameter as the shared registration.

Keep front wider than rear with approximately 27° local draft through the free side; use a broad shallow bowl instead of a narrow raised bead. Hide the LM receiver lobes within the new base. If the base extends across the LM silhouette, it must pass in front of the existing LM face with positive clearance; retain the native mating faces, M3 receiver axes/floors, M2 bearing and driver seat/recess/pilots. Added cosmetic material ahead of the receivers may thicken their front walls, but must not obstruct the mounts. Keep the solid underside, closed cable handoff and smooth rear UM/T loft. Move all four buried Ø6×3 magnets to the broad mid-UM shoulders if the narrower lower/upper diagonals no longer provide enough room. Refit both wing families with at least 0.75 mm measured full-pocket cover and no external pads. Trim the over-wide wing backing to blend with the reference. Keep one shared body, individual unsliced STLs, actual top/front/side views and a checked live viewer link; no ZIP or printer action.

Rear-surface implementation: use a direct curvature-matched height loft and evaluate the inclined side at its actual depth, with a rounded rear/side junction. Do not axially warp the narrowing side wall. Check the broad rear loft inside X=±20 mm separately from the sloping perimeter at X=±30/35 mm; retain full-width exported-mesh profiles to catch perimeter creases. Maintain the established 10 mm longitudinal / 50 mm transverse central-loft radius checks. The base apron clears the upper-wing tips with a smooth underside relief while preserving their lower interfaces.

Keep the complete Ø82 driver insertion bore clear of added duct-cover material. The nominal Ø6 UM passage eases to Ø5.4 beside the upper driver pilot, dipping slightly below its floor to preserve the cable wall. It joins the retained T taper at Y439, where the retained radius is approximately 2.70 mm rather than the trunk's maximum 3.40 mm. Match that local radius and its derivatives to avoid a diameter step. Confirm both the driver gauge and cable gauge against the exported body.

# Previous revision: front-wide UM with a consistent draft

Latest clarification overrides the rear-wide section: the front face must be wider than the rear, with relatively constant side slope from the lower neck through the upper shoulder. Use a continuous, rounded draft around the organic front outline, retaining the shallow forward lip. Keep the current approximately 125 mm UM outline, native MU10 seat/bore/pilots, both LM mounts and their exact bearing faces, solid lower annulus, closed cable handoff and smooth upper rear loft. The existing front face is Z18.3 and +Z is forward. Initial free-side target: approximately 0.5 mm of inward recession per millimetre toward the rear (about 27 degrees), rounded into front/rear surfaces. Verify signed taper direction and local draft consistency across many heights, not just a wide-middle silhouette. Reorient the buried D6x3 magnet pairs beneath the inclined skin, adapt both wing families to follow the actual taper, and move the internal gallery only as required for full cover and unchanged driver/LM clearance. All pockets remain closed with at least 0.75 mm actual material cover; no exterior pads. Preserve one shared body, individual unsliced STLs, actual rendered comparisons and a verified live viewer link. No ZIP or printer action.

# Previous revision: slender UM surround with a sloping outer edge

Replace the thick upright UM side wall and padded/lumpy shoulder treatment with a narrow forward lip and a continuous swept outer taper. Keep the shallow bowl direction (outer lip slightly ahead of the fixed Z18.3 driver rim), but make the upper/lower diagonal areas flow into the waist without separate bulges. Use a slimmer outline and substantially reduce the near-vertical span of the free outer wall. Installed axes X lateral/Y up/Z forward, mm; UM driver axis Y366.081. Preserve the D82 bore, D98.6 seat, all native fastener datums, both LM half-laps, closed cable handoff, service clearances and the smooth rear UM/T fusion. Magnets remain fully buried without external pads; move pockets and adapt all four upper wings if necessary. Validate exported-STL edge slopes/sections as well as full pocket cover, cable cover, exact mounts and both LM fits. Inspect front/side/oblique actual geometry before finalizing. Deliver the same one shared body STL and its individual companions, plus current views; no ZIP or sliced-print claim.

Selected source parameters: 62.5 mm central half-width, 63.2 mm upper circular envelope radius, 50.5 mm inner lip radius, Y333/X53.25 lower outline station, quadratic depth sweep with its widest section at 10% of the local rear-to-front span, and a 1.8 mm nominal radial front warp (the actual lip rise is lower because of the taper). Captive Ø6.20×3.10 pockets have axes at Z9.9 and polar angles 22°, 158°, −28°, 208°. The validation target is more than 4 mm lateral recession from Z8 to Z18 and at least 15° lean throughout the measured free wall at Z10–18, plus more than 0.75 mm actual full-cavity material cover.

## Previous revision: buried magnets and a shaped UM depth profile

Follow `design_inputs/nd25fn4_UM_depth_reference.png` and the user's clarified upper/lower shoulder arrows in `design_inputs/nd25fn4_UM_depth_shoulders.png`. The outer rim rises forward to form a shallow bowl. The diagonal upper shoulder and lower neck are fuller toward the rear, with smooth sloping fronts rather than a uniform rounded ring. Blend this depth treatment into the wider middle, existing tweeter waist and LM joints. Preserve the actual UM driver seat/position, flange recess, pilots and exact interfaces to both LM variants. Preserve the filled annular backing, both cable corridors and rounded M2 access.

Eliminate every exterior magnetic plane, pad and rectangular witness. Place four captive magnet pockets wholly behind the same uninterrupted curved surface, with matching pockets in both upper wing families. Check the complete pocket, loading chimney and roof, not just a ray at its centre. Evaluate stronger Superimanes magnets against cover thickness, available material and wing fit; record the selected size, full coverage, magnet separation and the limitation that advertised pull is not assembled retention. Preserve the original LM wing magnets and lower split interfaces. Inspect actual front, side and oblique STL renders and radial sections that demonstrate the different middle/diagonal depth profiles. Deliver individual STL files and refreshed review views, no ZIP. Geometry checking does not qualify the new curved bed-facing surface or captive pocket print process; keep the files marked unsliced.

## Previous revision: sculpted UM silhouette

Follow the blue UM surround in `design_inputs/nd25fn4_organic_UM_outline.png`: a broad rounded middle, gently concave transitions above and below, and lower corners integrated into the side curves. Retain the exact lower LM mating boundary, which limits how far the underside of the receivers can be reshaped. Treat the undimensioned image as a shape reference. Change the source-defined free exterior, maintaining a continuously rolled thickness profile and smooth joins to the existing tweeter waist and lower rear band. The UM driver position, D82 bore, D98.6 recess, pilots, exact LM half-laps, insert receivers and M2 tie remain fixed. Preserve the closed T handoff, buried T gallery, solid seat backing and independent UM lead clearance. Keep magnet pairs on real flat contact patches with verified cover; limit the planes to the magnet depth and fade them before the lips to reduce visible outline scallops; regenerate both wing families to match the new silhouette. Check both LM configurations, all functional gauges, mesh topology, surface continuity and actual front/side/rear views. Deliver one shared STL and individual companion files, with no ZIP and no slicing or print action.

## Previous revision: seamless curved rear lower UM band

Replace the rectangular exposed rear closure-web thickness between the two LM ears with a continuous organic, waveguide-like surface. Reference: `design_inputs/nd25fn4_lower_band_seams.png`. Blend across its upper arc and both end steps, rather than only softening their lighting. Preserve the accepted closed T duct, solid under-seat annulus, separate UM lead corridor, rounded M2 screw access and bearing plane, exact LM half-laps/receivers and normal assembly seam. Do not change the upper rear loft, drivers, magnets or wing interfaces. Validate the actual exported STL for rear surface continuity, solid material, all functional clearances and both LM fits, then inspect rear oblique and close-up snapshots. One shared STL body for both LM configurations; individual files only, no ZIP.

# ND25FN-4 V4 + UM fused body

## Previous revision: closed duct handoff and solid UM seat underside

Close the positive T cable cover at the LM/UM handoff in both standalone Obi-Wan UM carriers and the one shared ND25FN V4 body. Retain only the normal assembly fit seam and the cable lumen; remove the deliberate exposed roof/collar notch. Replace the hollow annulus beneath the MU10 driver seat with solid material down to the rear datum while retaining the D82 bore, D98.6 flange recess, Z14.3 seat, four driver pilots and actual driver/terminal clearance. Keep the M2 LM/UM screw bearing seat and axis fixed, extend its access through the newly solid underside, and round its accessible mouth. Preserve both LM mounts, captive magnets, relocated wing interfaces, lower tweeter placement and the validated broad rear loft. Rebuild the affected source-derived STLs, inspect actual meshes around all three marked areas, and validate passage continuity, residual wall, fastener access and compatibility with both LM assemblies. Deliver individual files without a ZIP. Existing sliced artifacts containing the old UM must not be presented as current.

## Previous revision: broad rear thickness loft

Remove the visible arc junction marked in `design_inputs/nd25fn4_rear_arc_markup.png`. A monotone profile alone is insufficient: the surface angle must change gradually across the rear UM-to-tweeter join. Replace the short thickness transition with a broad curvature-controlled loft, continuing down the upper UM annulus. Preserve the shared STL, both LM interfaces, driver seats and positions, cap rim and retention hardware, magnetic landings, and buried cable gallery. Validate actual rear profile curvature along and across the junction and rendered highlights from the final STL, as well as all fit and cable checks. Require longitudinal curvature radius above 10 mm and transverse radius above 50 mm across the free rear junction, with 0.25 mm STL-ray sampling and a 1.5 mm fitting window to separate the macroscopic shape from tessellation. Keep intentional bore and service-cap edges outside those samples. Deliver one shared body STL and direct companion files, with no ZIP.

## Previous revision: one body for either LM configuration

The optional floor stand belongs to the lower assembly. Deliver a single `STL/01_UM_Crescent_V4.stl` for both LM configurations. Use one canonical UM mechanical source and a fixed upper cable profile so the build cannot create stand-specific upper parts. Verify the same exported body against both released LM mounts, both UM mechanical interfaces and both incoming cable routes. Keep the smooth rear fusion, driver layout, retained service parts, magnets and wings. Archive the two former body files; update manifests, views and instructions to identify one shared part. Deliver individual STL files only, with no ZIP.

## Previous revision: continuous rear UM-to-tweeter sweep

Remove the raised ridge and side bumps marked in `design_inputs/nd25fn4_rear_fusion_markup.png`. The upper rear UM must join the lower rear of the forward tweeter as one smooth surface. Preserve the existing cap boundary, driver retention, LM interface, four shoulder magnet pairs and enclosed cable gallery. Reshape the actual geometry and check the rear profiles and a bare close-up from the final STL. Deliver individual STL files and an index; do not generate a deliverable ZIP. The previous checked revision is recorded in `superseded.json`.

## Previous revision: rolled UM surround and concealed cable gallery

Use `design_inputs/nd25fn4_waveguide_um_markup.png` as the visual direction. Replace the straight-sided mid-UM collar with a continuously rolled, wider organic surround that joins the existing compact tweeter waist. Preserve the UM driver seat, pilots, LM half-laps and both tweeter positions/retention interfaces. Keep the common forward datum at Z=18.3 mm and the overall 35.8 mm depth.

Provide two concealed UM magnets per side near the upper and lower shoulders marked in red, using small flat contact patches tangent to the organic side surface. Retain the proven D5×2 pocket/cradle shape, 0.52 mm face skin and nominal 0.35 mm wing gap. Move both position and burial height as needed for actual wall coverage; regenerate both upper-wing families with matching pockets and preserve their LM pockets and lower split interfaces.

Move the T cable gallery outboard into the wider surround, from the retained LM handoff to the V4 side trunk. Close the obsolete exposed UM route and bury the replacement behind the front surface. Keep the independent UM-driver cable passage and its terminal outlet usable. Validate actual exported mount geometry, driver clearance, four closed body magnet cavities, three closed cavities in each upper wing, paired magnetic axes/skin thickness, cable clearance and cover. Render actual meshes in front, side, top and rear/section views and regenerate the STL package. Previous checked iteration: `review/nd25fn4_iterations/before_waveguide_um_20260911T112132Z`.

## Previous revision: smooth, compact waist

Replace the previous narrow bridge and cylindrical UM exterior with a continuous rounded UM-to-tweeter waist, smooth in both front and side views. Blend the small notches above the two LM attachment ears into this exterior. Preserve the exact LM M3 half-laps, receivers and M2 tie, UM seat, pilots and driver position. Keep only a short flat contact region at each mid-UM side; relocate the two captive UM magnets there and regenerate both upper-wing families, retaining their LM magnets and lower split interfaces.

Lower the complete opposing-tweeter assembly to the closest position allowed by the driver/service envelopes and a nominal 2.4 mm front ligament between the MU10 recess and lower mouth. Interpret “50% more pronounced” as a 1.5× axial-depth/radial-run ratio on the lower flare: its radial expansion from the unchanged 18.6 mm throat radius becomes 14.267 mm, giving a 32.867 mm lower mouth reach. Keep the upper flare, 62 mm opposing-tweeter pitch, 35.8 mm depth, driver seats and retention parts. This changes the lower acoustic contour; acoustic performance is not established by the mechanical checks.

Use installed X lateral/Y up/Z forward in mm. The UM remains at Y=366.081 and the forward face at Z=18.3. The new lower tweeter target is Y=450.648 (20.133 mm lower), subject to exported-mesh clearance checks. Replace the long former cable tail with a C2 connection from the existing UM route to the right-hand V4 trunk. Verify closed meshes, wall/driver/cap clearances, unchanged mounting geometry, closed relocated magnet cavities and their paired alignment, cable clearance, and matching wings. Regenerate source-derived orthographic and oblique images and the checked STL bundle. The earlier fused version is archived under `review/nd25fn4_iterations/before_smooth_compact_20260911T070434Z`.

## Previous fused revision (superseded design record)

Supersede the separated V4 housing/UM candidate. Fuse the actual Obi-Wan UM carrier and retained V4 housing into one printable body, filling the visible gap with a continuous bridge. Keep the existing LM interface, UM driver seat/pilots, side magnet cavities, lower routing and installed driver axes unchanged. Supply separate no-floor and floor-stand versions because their upstream UM cable geometry differs. Reuse the original V4 caps and retainers.

Retained axes and envelope: package X forward/Y lateral/Z up; project X lateral/Y up/Z forward. V4 driver axes remain at project Y=470.781 and 532.781 mm, common forward face Z=18.3. The 134 × 148 × 35.8 mm V4 envelope is retained above the transition. The new web fills the former 10 mm space and absorbs the obsolete UM-to-crescent half-laps. Close their M3 bores and M2 tie pockets. Retain LM rear-driven M3 axes X=±32, Y=315.770102, receiver floor Z=16.4, front Z=18.3, the 0.2 mm half-lap gap and the LM/UM M2 center tie.

A C2 cable transition connects the original UM route to the retained V4 trunk. Replace the now-obsolete free tail; keep both acoustic mouths, driver chambers, retention hardware and cap interfaces unchanged. Boolean-fuse the verified UM mesh without global remeshing so its mounting geometry remains exact. Preserve negative-wound magnet cavity shells.

Recheck and adapt both upper-wing families where needed; preserve their split joints and all magnet cavities. Validate the exported fused meshes, both LM mating states, exact UM preservation below the bridge, driver fits, bridge closure, and an independent wire gauge. Use a front-face-down diagonal print pose if the outline fits; report actual bounds. Outputs are unsliced STL candidates with rigid print authorities, geometry report, source-derived review GLBs/PNGs and a checked STL ZIP. No printer job or promotion is requested.

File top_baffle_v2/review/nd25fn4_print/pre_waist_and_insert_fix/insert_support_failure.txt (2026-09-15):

('Support enters insert bore', 'UM_M3_1', 6.6, -1.326385710599236)

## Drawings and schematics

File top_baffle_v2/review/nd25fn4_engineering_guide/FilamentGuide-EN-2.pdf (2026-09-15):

# Bambu Filament Guide

# Shop All Filaments (https://store.bambulab.com/collections/bambu-lab-3d-printer-filament)

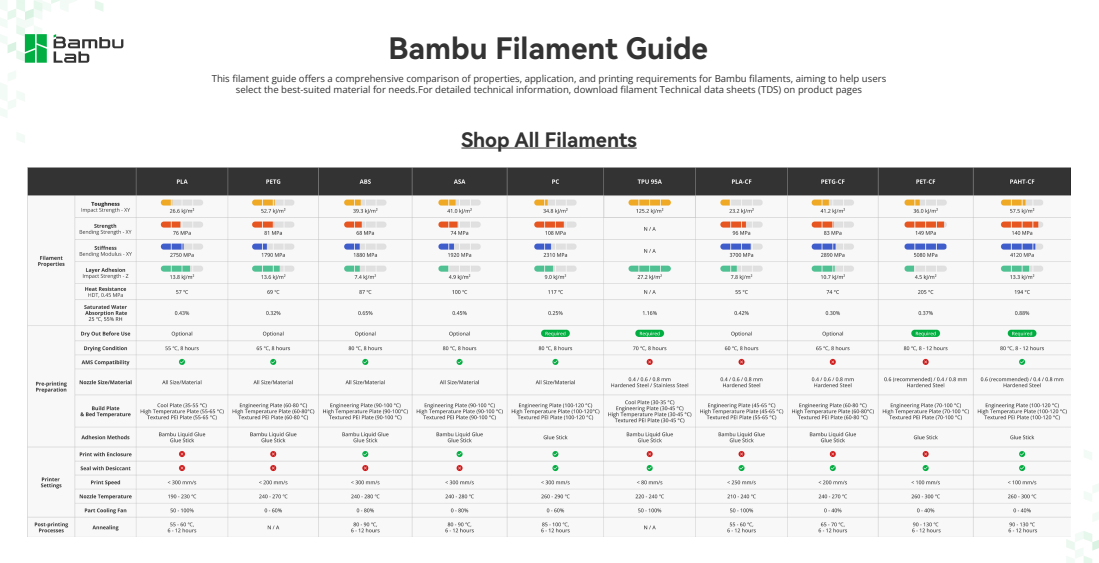
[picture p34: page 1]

This filament guide offers a comprehensive comparison of properties, application, and printing requirements for Bambu filaments, aiming to help users
select the best-suited material for needs.For detailed technical information, download filament Technical data sheets (TDS) on product pages

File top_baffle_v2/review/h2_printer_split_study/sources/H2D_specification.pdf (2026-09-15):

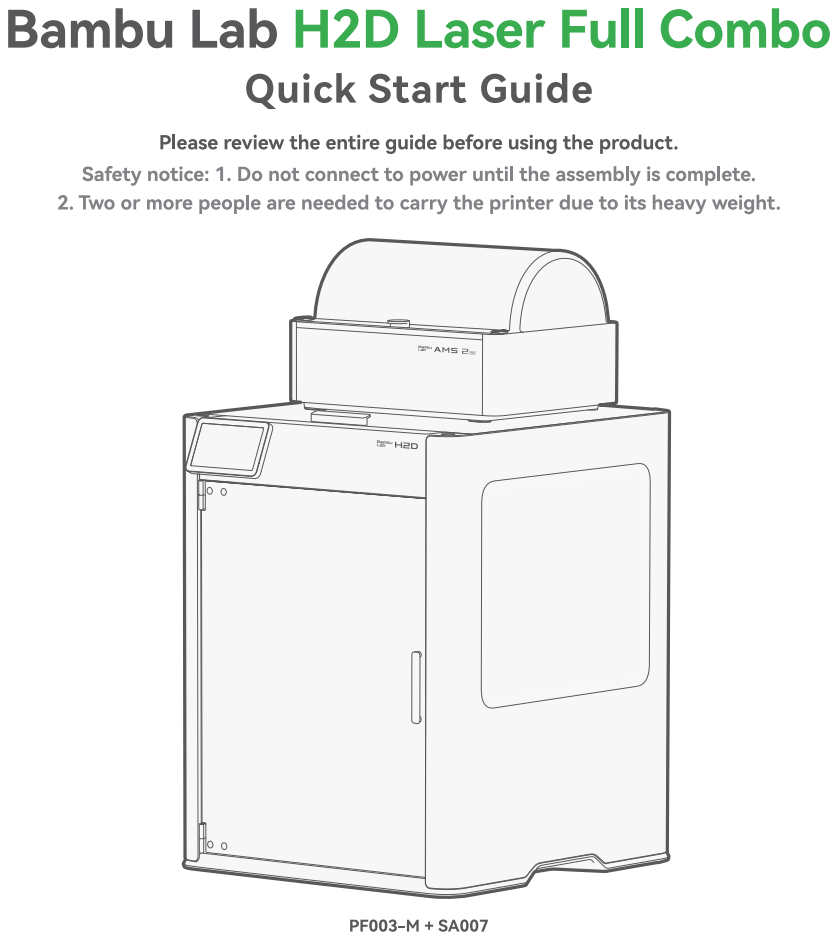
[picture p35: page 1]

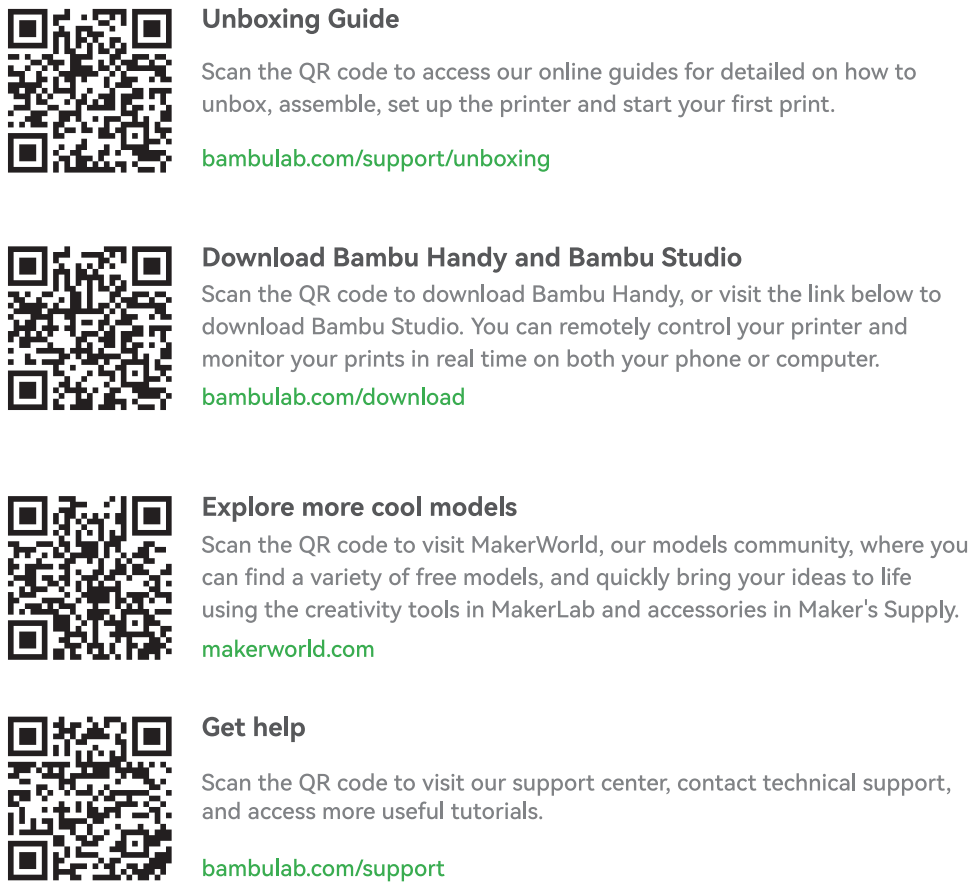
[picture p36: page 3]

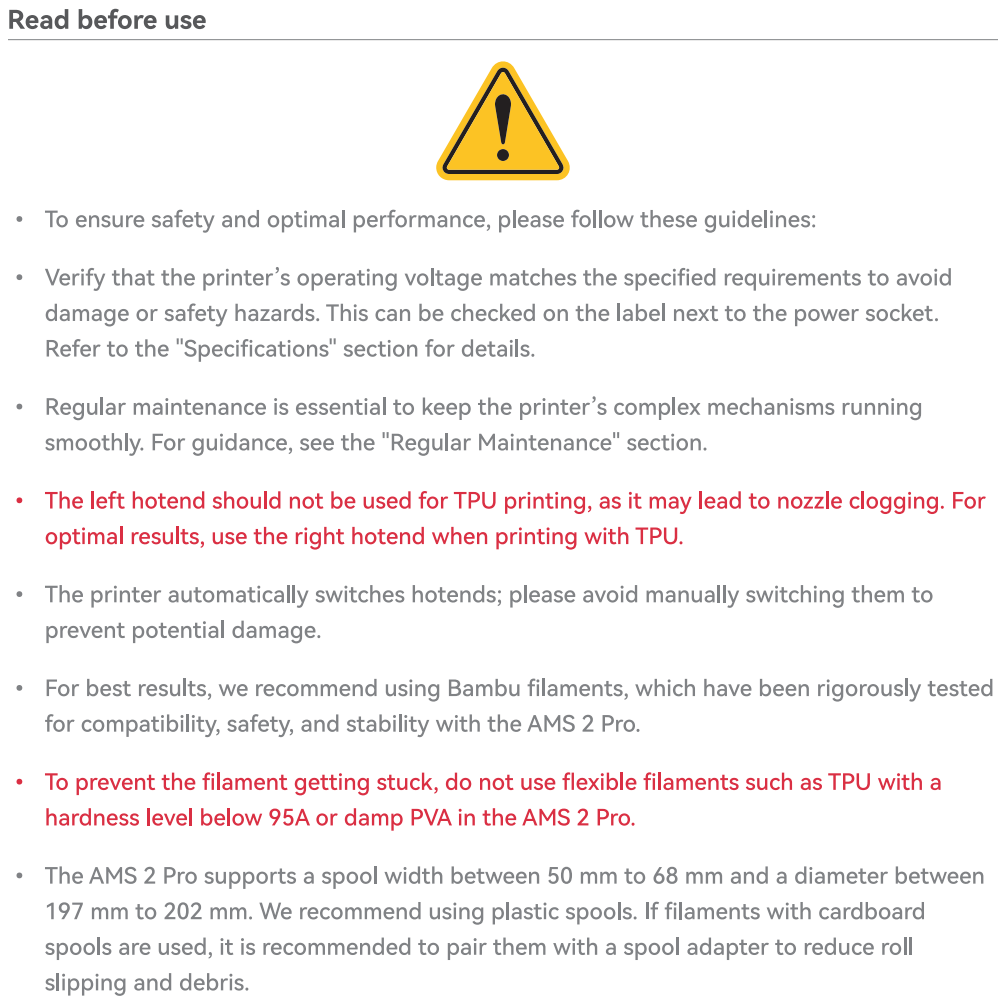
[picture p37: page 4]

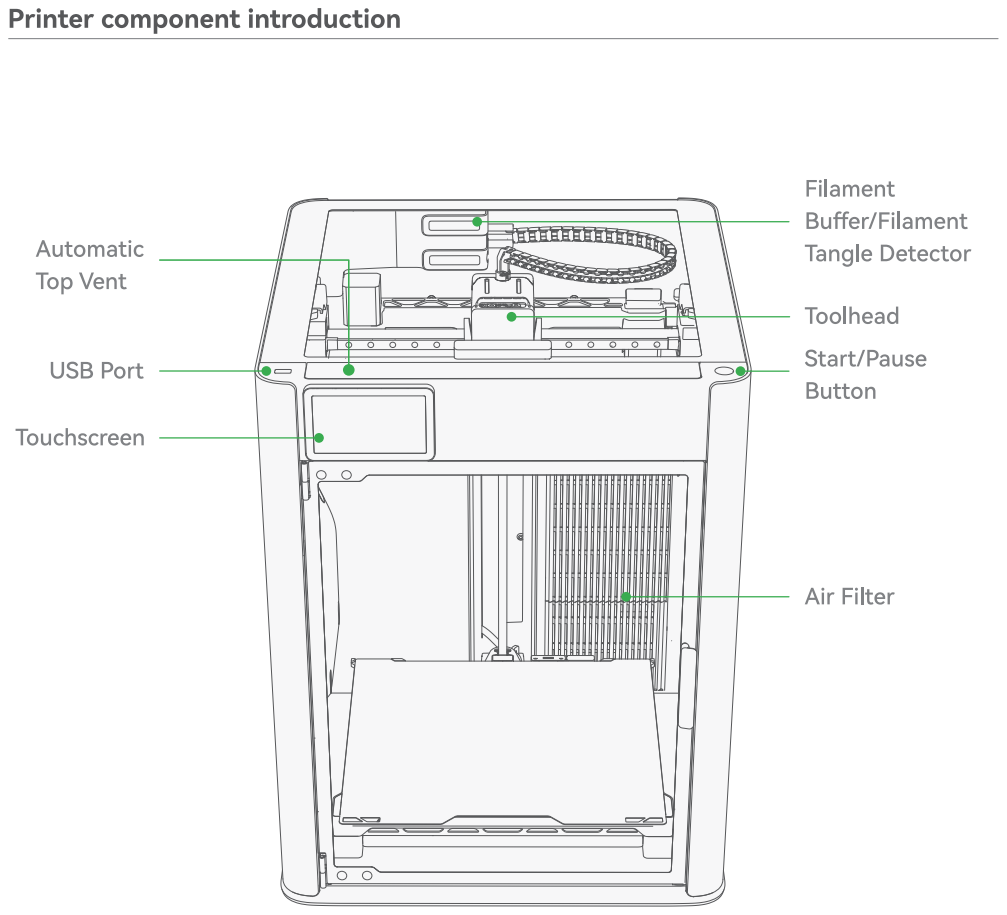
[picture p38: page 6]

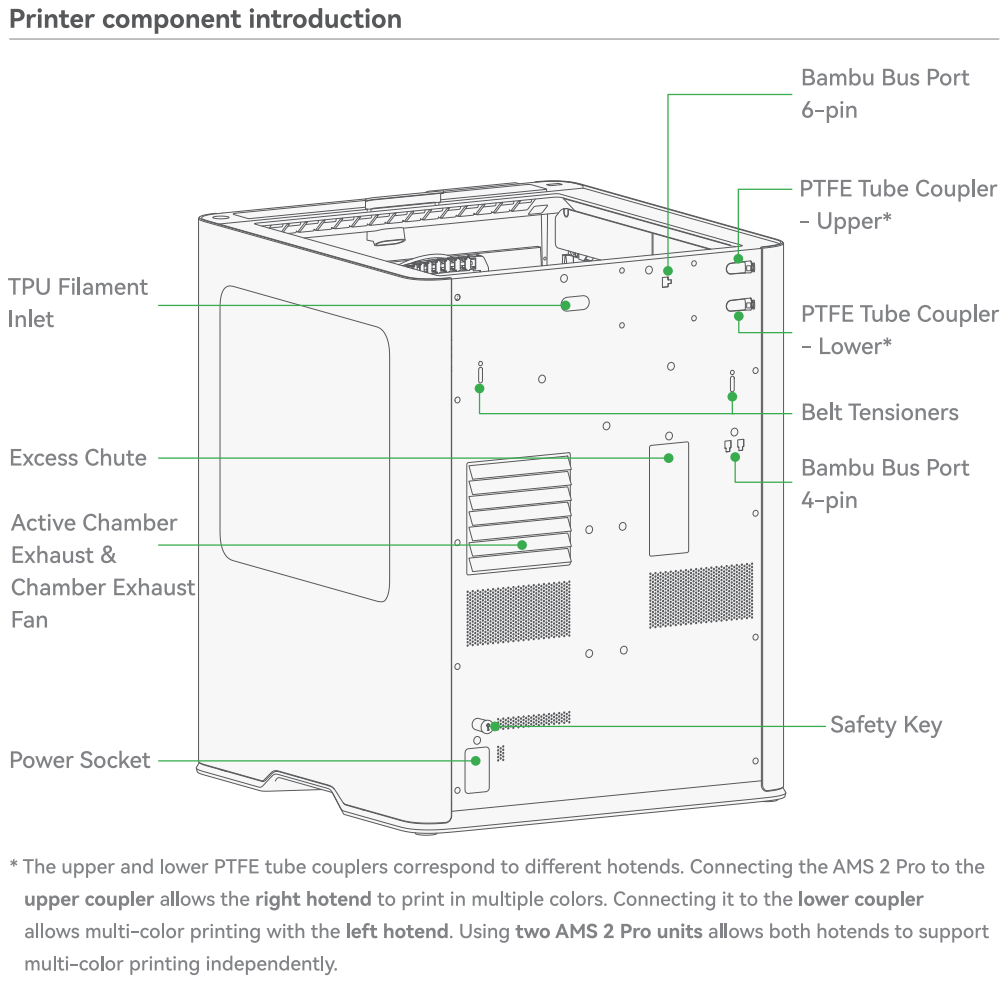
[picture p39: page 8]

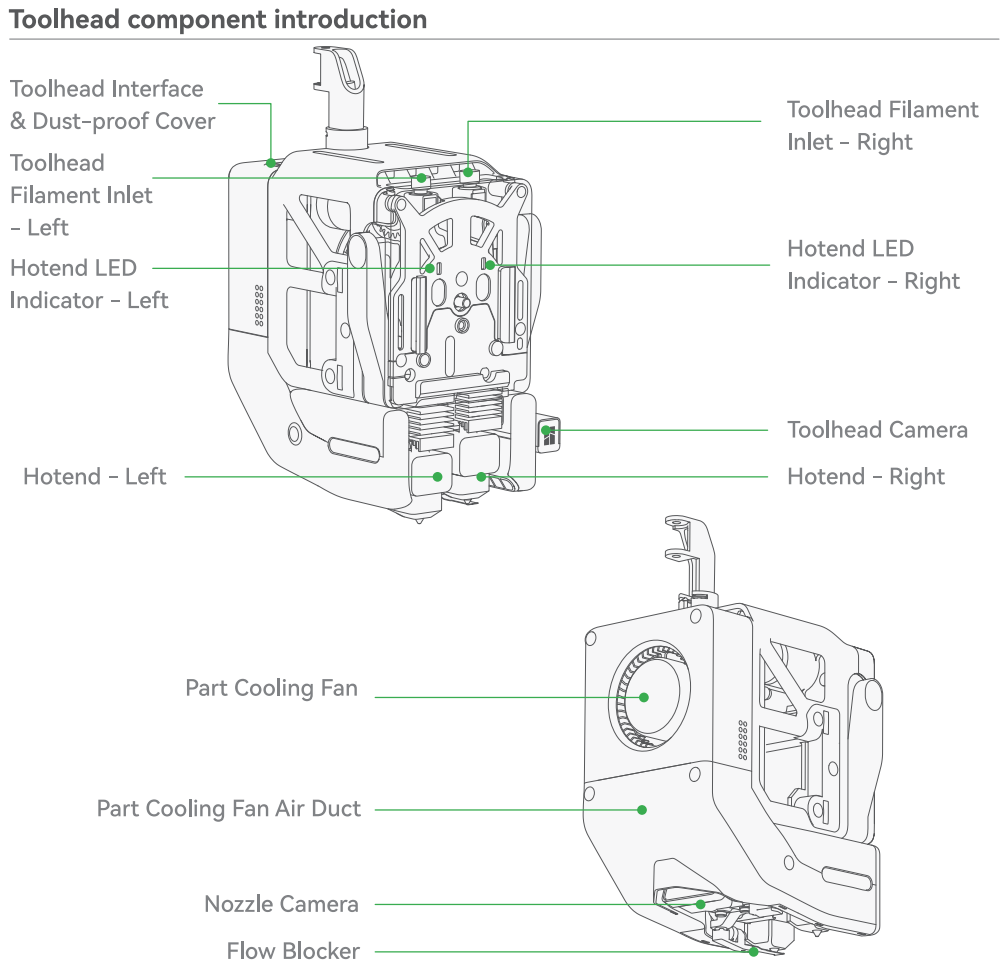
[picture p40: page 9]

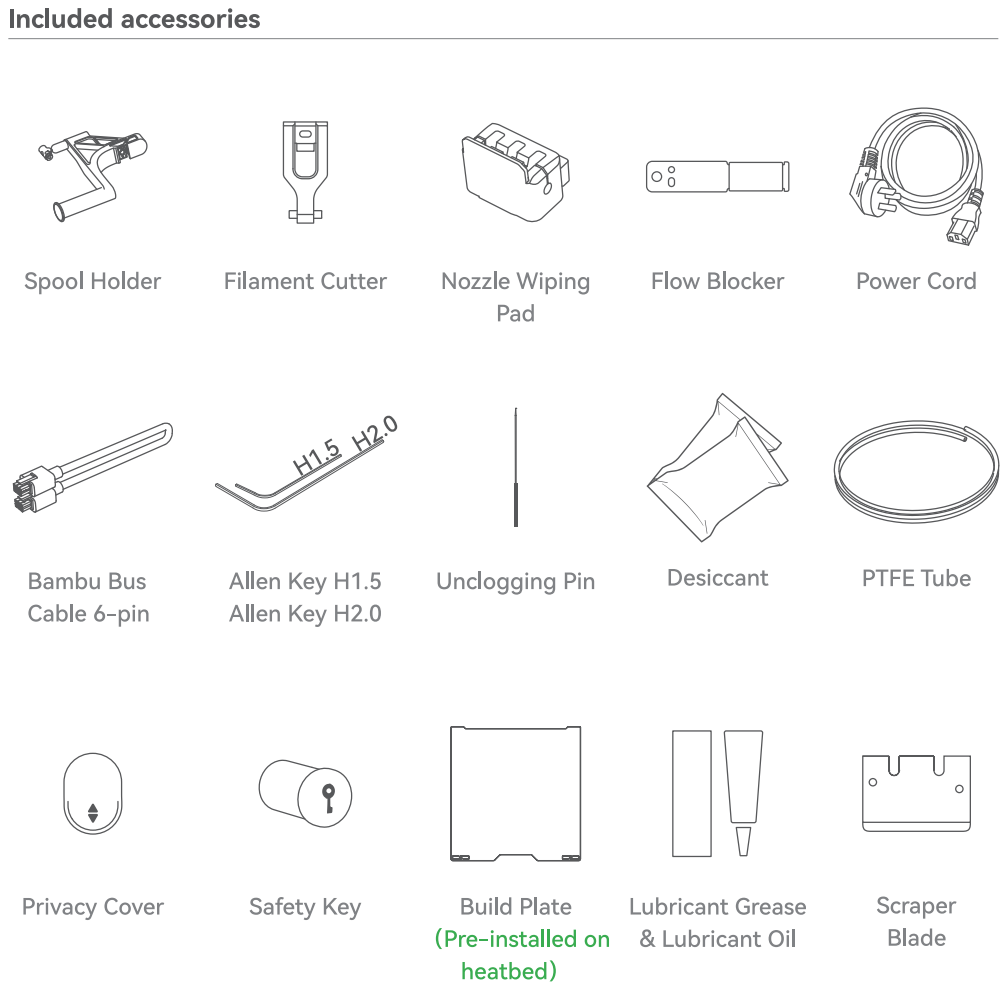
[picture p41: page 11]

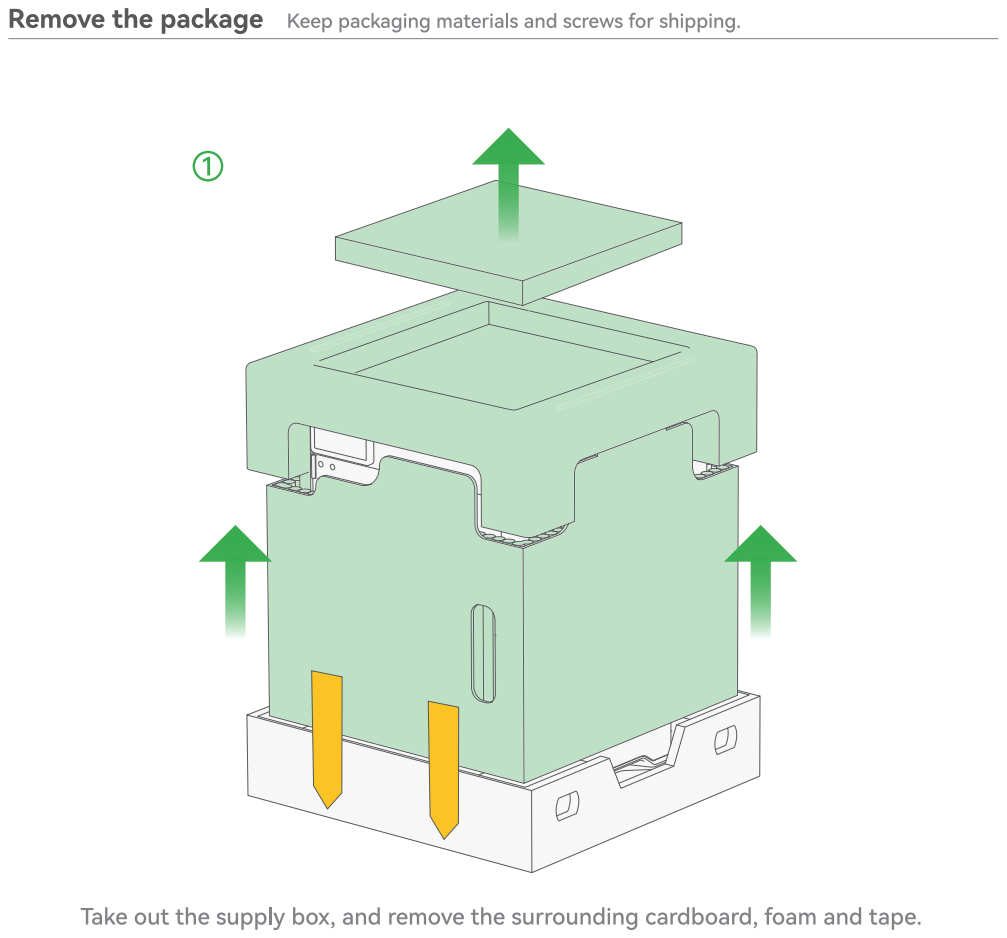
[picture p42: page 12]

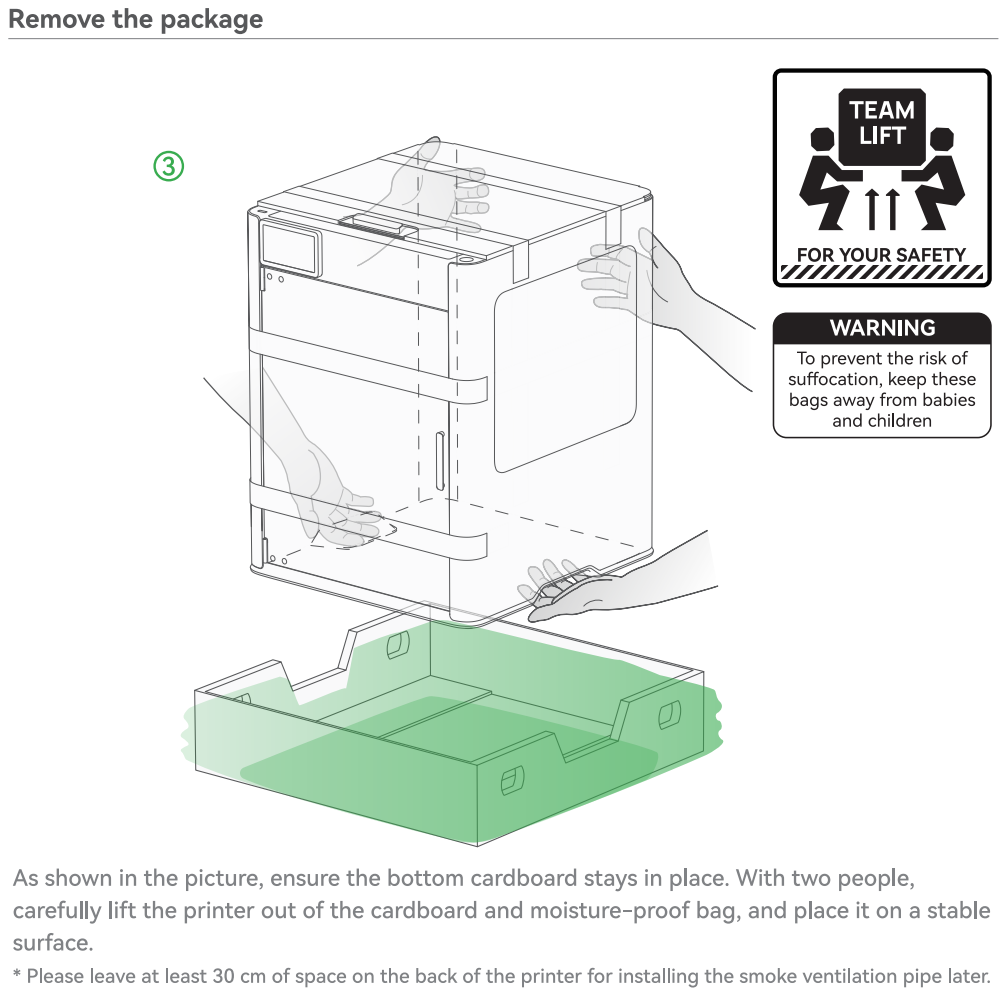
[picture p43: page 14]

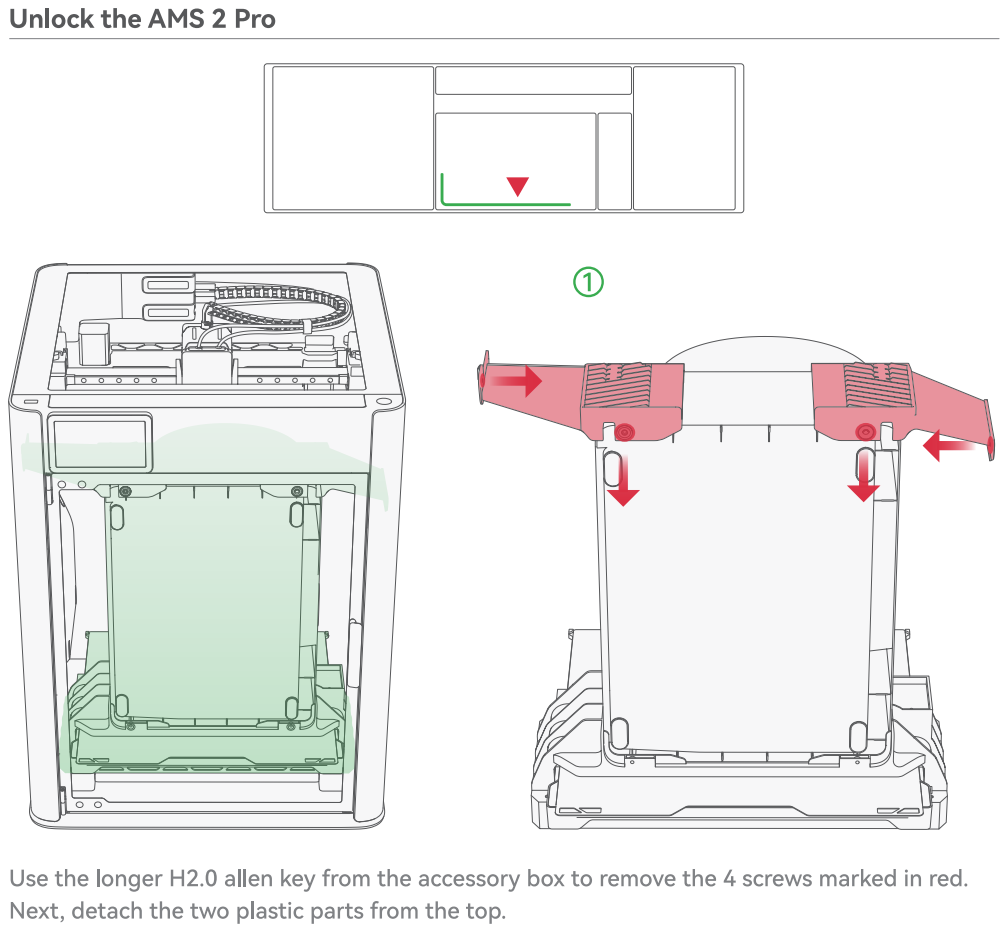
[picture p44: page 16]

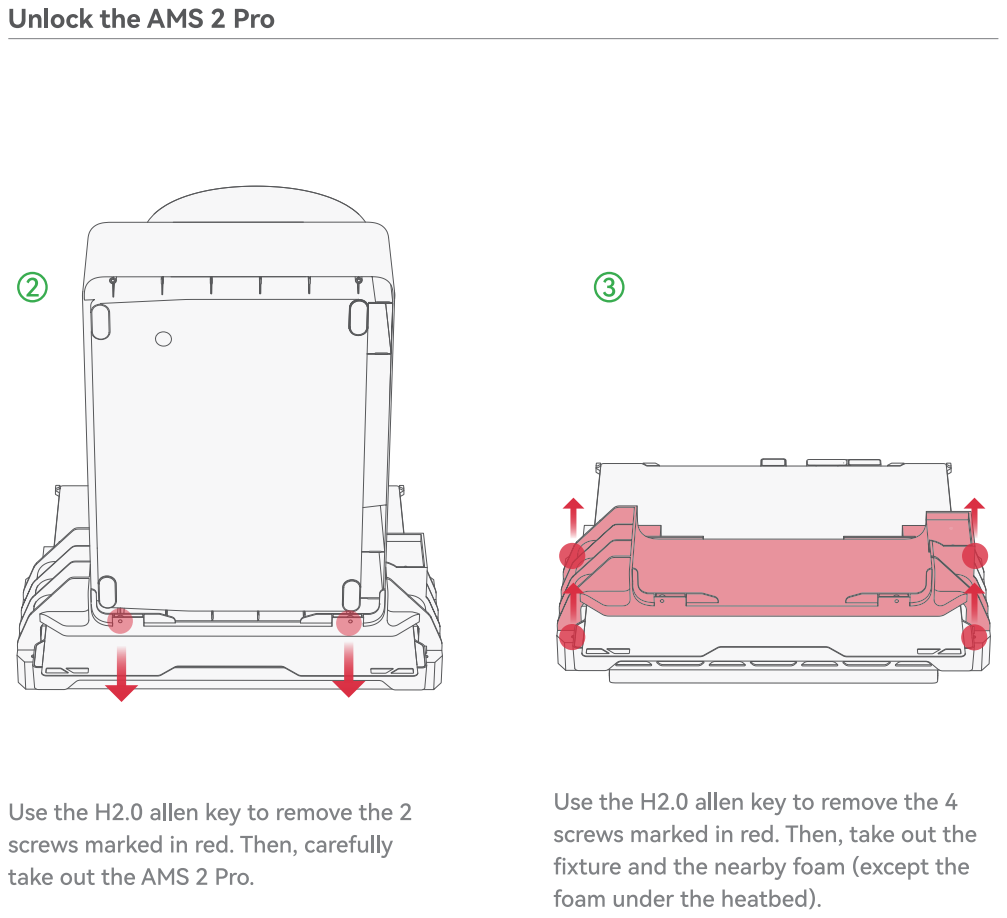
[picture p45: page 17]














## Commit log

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2026-07-04 Make STEP export self-contained (drop CAD-skill dependency)
    Add export_steps.py, which exports each module's gen_step() via
    build123d's native export_step (fixed header timestamp, assembly
    labels preserved). Repoint the Makefile's STEP rules at it instead of
    the external ~/.claude CAD-skill `step` script, so a fresh clone builds
    everything (STL/STEP/PNG) from the committed sources plus pip packages
    alone (build123d, shapely, matplotlib, numpy).
    Since export_steps.py writes only its --output (no shared hidden viewer
    files), the cross-variant STEP serialization is no longer needed --
    all jobs now run fully parallel. Regenerate the 13 STEP artifacts with
    the native exporter; STLs/PNGs are byte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
    [top_baffle_nd25fw4_a_comp.step, top_baffle_nd25fw4_a_comp_assembled.step, top_baffle_nd25fw4_attachments.step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]
2026-07-05 Fix top-baffle magnet receiver wall; add clearance suite
    The attachment-side magnet receiver at the crescent-arc site grazed the
    shoulder/wing chamfer mating face (0.057 mm wall, measured on the built
    solids). Move the site up-arc (theta -71 -> -69.5 deg, now (17.88,
    420.37)), shorten the receiver 3.5 -> 3.2, and raise the bore to
    z=10.7: the wall is now 1.27 mm with 1.74 mm still behind the pocket
    floor to the rear taper.
    Also:
    - Complete the crescent taper fade at r=62 (was 63) so the shoulder
    flank/top edges truly return to full 18.3 depth
    - Add test_clearances.py (make check): duct-duct/pilot separations,
    foot-lane webs, magnet-pocket walls, outline-splice assertions
    - variant_outli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
    [lx521_top_addonA_1of4_shoulder_top_left.stl, lx521_top_addonA_2of4_shoulder_top_right.stl, lx521_top_addonA_3of4_shoulder_bottom_left.stl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]
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2026-07-05 Heat-set inserts both mids; bury all ducts deep; move seam A
    Fastening: W22 on six M5x6xO7 brass heat-sets (O6.4x7.0 bores, floor
    z=11.3, was M5-M8x10 adapters at O7.8x11); 10F on four M3x6xO5
    heat-sets (O4.6x7.0, was M3-M6x10 at O5.8x11) -- unlimited driver R&R,
    inboard wall at the D82 grows 0.85 -> 1.45.
    The shallow pilot floors let every duct run in the full-depth core,
    identically in ALL variants (B2/B1/A-comp/C7 pieces stay drop-in
    compatible):
    - UM: O7.8 (was 8.6) DEEP at z=5.7 on one constant arc r=100.7 hugging
    the D190 rim, passing UNDER the W22 pilot ring (1.7 membrane); one
    smooth bend into the seam-B crossing. Carries twisted 2x2.0 mm^2;
    2x2.5 no longer fits.
    - T1/T2: lowe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
    [lx521_top_base_1of4_bottom.stl, lx521_top_base_2of4_mid_left.stl, lx521_top_base_3of4_mid_right.stl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]
2026-07-05 Add V0 (rear knife bevel) and V1 (11.5 front-flush vase) variants
    V0: minimalist UM vase with a REGULAR ~4 mm rear-side knife band along
    the flare/chamfer outline (same sculpted side as C7/crescent; front
    plane intact; capped by the T lanes). One D5x2 pin magnet per side in
    a vertical rear-face pocket.
    V1: the vase thinned to 11.5 and mounted FRONT-FLUSH (material z
    6.8..18.3): enabled by routing round 3 -- the vase-side ducts step to
    the FRONT half at seam B (T uppers z=10.7, UM z-step to 12.55, exit
    opening z=12 through the 10F basket window zone) and the 10F pilots
    shorten globally to M3 x 3 x O5 heat-sets (O4.6 x 4.0, floor 14.3).
    Crescent taper is now parametric (front/rear mm) and re-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
    [lx521_top_addonA_3of4_shoulder_bottom_left.stl, lx521_top_addonA_4of4_shoulder_bottom_right.stl, lx521_top_addonB1_1of2_wing_left.stl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]
2026-07-06 Round-4 front-datum routing; V1L thin LM section; OOM fixes; PRINTING
    Routing round 4: ALL mains move to the FRONT half so thin variants
    share the front plane (flush driver mounting):
    - LM O8.5 at z=12.15 (plan unchanged).
    - UM O7.8 at z=12.55 END-TO-END on one arc r=119.5 OUTSIDE the W22
    pilot ring, diagonal threading the 0.9 mm window between the 90-deg
    pilot keep-out and the right seam-B key (moved cx 21.5 -> 24), vase
    tail to the D82 exit (opening z=12). The right side carries only
    this route.
    - T1+T2 SHARE one O6.0 duct at z=11.5 up the LEFT flank (the largest
    bore the notch corridor between the D82 rim and the vase chamfer
    admits), with a SINGLE scallop exit at (-3.3, 430)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
    [lx521_top_base_1of4_bottom.stl, lx521_top_base_2of4_mid_left.stl, lx521_top_base_3of4_mid_right.stl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]
2026-07-06 Smooth UM route; route-smoothness guard; sigmoid V1L ramp
    The UM lower route's arc-exit kink (a ~56-deg corner jogging
    horizontally past the 30-deg W22 pilot) is replaced by proper tangent
    geometry: the r=119.5 arc exits at theta=20 through an R50 fillet
    whose pilot clearance (12.1) holds by construction, onto ONE straight
    diagonal tangent to a r=13.5 pilot keep-out, then a single R~10
    window bend threading the 90-deg-pilot / seam-key gap into the vase
    tail. Right B-key moves cx 24 -> 28 to widen that window.
    New guard test_route_smoothness: samples every route's REAL
    interpolated spline (both stand modes) and enforces minimum bend
    radii (lm 25 / um 10 / ts 4.5 / feeders 6). Introducing it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
    [lx521_top_base_1of4_bottom.stl, lx521_top_base_2of4_mid_left.stl, lx521_top_base_3of4_mid_right.stl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]
2026-07-06 Uniform-11.5 thin family; V1 two-pin anchoring; variant catalog
    V1L collapses to t=11.5 = the V1 vase (one plane, NO step at seam B):
    the whole thin baffle is a uniform 11.5 slab from the sigmoid ramp to
    the horn tips. Enabler (option A): the LM duct slims to O8.2 and
    re-centers to z=12.55 (joining UM on one plane) -- keeps the 2x2.5
    mm^2 pair with ~0.4 fishing clearance (leader + lube); entry/exit/
    foot lane retargeted. The front-flush window guard now covers y>=96
    at rear 6.8.
    V1 attachment anchoring goes to TWO pin magnets per side, no lips,
    no bosses: lower site zc=12.5 (wall pockets added to the V1/V1L
    vase; 1.9 wall to the ts duct), upper site zc=14.4 -- INSIDE the
    as-tapered crescent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
    [lx521_top_base_1of4_bottom.stl, lx521_top_c7base_1of4_bottom.stl, lx521_top_v1_4of4_vase.stl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]
2026-07-06 Review closure: 31 doc fixes, margin dashboard, piece IDs, coupon
    Deep-review batch. Docs/comments synchronized with code truth across
    31 findings (cables/V0/V1/V1L/C7/b/b2_split headers, README duct
    table + support-window + V1L sections, VARIANTS anchoring rows,
    PRINTING stiffness note, gen-script legends -- all were describing
    superseded designs after the final iteration sprints). Two code
    findings: EXIT_RAMPS["lm"] dia 9.3 -> 9.0 (the +0.8-over-duct
    convention for the O8.2 LM); C7's dead rib code deleted.
    Verification added this pass: every exported STL manifold-checked
    (all watertight); piece-level duct envelope probe of the uniform-11.5
    set (mains fully buried; only by-design entry-plu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
    [lx521_coupon.stl, lx521_top_addonA_1of4_shoulder_top_left.stl, lx521_top_addonA_2of4_shoulder_top_right.stl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]
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2026-07-07 Coupon fishing blocks; engravings on every piece; C7 lateral duct fix
    Three fixes from a slicer inspection pass:
    1. C7 exposed duct (piece_mid_right flank, y~140-190) -- the real bug.
    The taper slope crosses the UM/TS bores LATERALLY, so the old
    centerline-only containment passed while the bore's outboard flank
    opened into the taper void. thickness_at() now clamps the law along
    both duct corridors (_duct_min_t, full circular envelope + 2.0 law
    skin -> >=1.6 realized on the ruled-loft solid); _profile_pts samples
    the clamped law per-station (denser stations through the pinch);
    test_c7_duct_corridor now checks 5 lateral offsets per point.
    Verified: worst full-width wal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
    [lx521_coupon.stl, lx521_top_addonA_1of4_shoulder_top_left.stl, lx521_top_addonA_2of4_shoulder_top_right.stl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]
2026-07-07 Fix coupon layout: 6 separate bodies, no fusion
    The four fishing-rehearsal blocks and the loose male key had
    overlapping placements -- they fused into 3 merged lumps (5 bodies
    instead of 6), corrupting channels at the seams. Regridded onto
    non-overlapping 44 mm cells below the plate; footprint 190 x 160 mm
    (fits the 256 bed). Now: plate, loose key, and 4 clean fishing blocks
    (entry cluster, UM window bend, TS notch dive, foot R14 elbow).
    [lx521_coupon.stl]
2026-07-07 Split coupon into 6 print-ready STL files
    The single multi-body coupon mixed flat 18.3 mm blocks with a 40 mm
    standing foot block -- they cannot all sit on the bed in one
    orientation. Now export_coupon writes six separate files, each a
    single body laid flat on the bed (bbox at origin, min-Z footprint):
    1_fit_plate, 2_fit_key, 3_fish_entry, 4_fish_um_bend, 5_fish_ts_dive,
    6_fish_foot. The loose key is rebuilt as one clean extrusion (the old
    prism+box union was non-manifold). Makefile target -> .stamp_coupon;
    PRINTING.md updated. All six manifold.
    [lx521_coupon.stl, lx521_coupon_1_fit_plate.stl, lx521_coupon_2_fit_key.stl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]
2026-07-07 Fix coupon key so it actually inserts into the pocket
    The dovetail cross-section already mated correctly (measured 0.11 mm
    gap on all three walls vs the 0.10 spec), but the loose key's grip
    handle was on the NECK side -- dropping the trapezoid into the plate's
    edge slot rammed the handle into the plate body (4375 mm^3 overlap),
    so the key could not be seated. Handle moved to the HEAD side: it now
    protrudes past the edge when the key drops in (interference -> ~1 mm^3
    mesh noise; gaps unchanged at 0.11). Verified by booleaning the mated
    key against the plate.
    [lx521_coupon_2_fit_key.stl]
2026-07-08 W22 inserts: M5 x 5.8 x O6.3, hole O6.4 x 6.8 (was 7.0 deep)
    Match the actual W22 heat-sets (M5 x 5.8 long x O6.3 OD, manufacturer's
    recommended hole O6.4). Only the depth changed (7.0 -> 6.8; diameter
    was already 6.4) -- a shallower blind bore, no clearance impact; floor
    z 11.3 -> 11.5. Updated the constant, the code comment (also cleared a
    stale pre-round-4 "UM passes under the ring" note), README, PRINTING
    fastener table, VARIANTS, the V1L docstring, and the coupon W22 test
    bore. Suite green; all artifacts rebuilt. 10F unchanged (M3 x 3 x O5,
    hole O4.6 x 4.0).
    [lx521_coupon_1_fit_plate.stl, lx521_top_base_1of4_bottom.stl, lx521_top_base_2of4_mid_left.stl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]
2026-07-08 Fix V1 wing not flush with the mid (4.75 mm inner-edge gap)
    The wing's bottom trim cut PARALLEL to the flank offset 2.2 mm normal;
    because the flank is shallow (27.6 deg), that became 2.2/sin(27.6) =
    4.75 mm in X and shaved the wing's entire inner edge, opening a gap to
    the V1L mid all along the seam (mid outer 45.65 vs wing inner 50.40 at
    y=312). Removed the trim: the raw (b1 - b2) wing already sits exactly
    on the B2 flank -- gap now 0.05 mm (== sampling step) -- and tapers
    naturally to the B1/B2 convergence point with no outline step. The two
    past alternatives were both worse (horizontal cut = 4.5 mm notch, the
    earlier "dent"; parallel trim = this gap); the natural taper has
    neither, at th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
    [lx521_top_v1addonB1_wing_left.stl, lx521_top_v1addonB1_wing_right.stl]
2026-07-08 Blunt the V1 wing feather, keep the inner edge flush with the mid
    The wing tapered to a fragile knife feather where B1 meets B2 (~y=306.5).
    Remove it with a cut PERPENDICULAR to the flank through a point on the
    B2 line at y=309.5: the inner edge stays exactly on B2 (flush with the
    V1L mid, +0.05 mm butt both sides), the bottom becomes a ~2.5 mm blunt
    end normal to the taper (no thin line), and there is neither the
    horizontal-cut notch nor the parallel-offset gap. Fixed the mirror
    (plane-based half-space, symmetric L/R). Wings manifold, bed-fit;
    suite green.
    [lx521_top_v1addonB1_wing_left.stl, lx521_top_v1addonB1_wing_right.stl]
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2026-07-08 Driver cable exits come out the REAR, not into the cutout cavity
    The LM and UM exits used to dive INTO the driver cutout at z~12 (LM at
    (-10.6,119), UM at (2.95,332)) -- inside the hole, right where the
    basket sits, so fishing the cable fouled the driver on assembly. Both
    now dive straight BACK to the rear face and open BEHIND the driver, so
    the cable comes out the back and plugs into the rear terminals.
    - LM: straight-back bore at (-10.5, 98), rear face 8.5 mm below its
    cutout; main trimmed to end there (also clears a small pre-existing
    cutout breach at the old y=103 end).
    - UM: the vase's seam-B/cutout band is only 9.4 mm -- too tight for a
    safe rear bore -- so the exit is just belo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
    [lx521_coupon_3_fish_entry.stl, lx521_coupon_4_fish_um_bend.stl, lx521_coupon_6_fish_foot.stl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]
2026-07-09 Seam C: two beefier teeth + snugger 0.05 seam clearance
    The mid_left<->mid_right joint had a SINGLE small dovetail in the ~20 mm
    neck (the only place the halves touch -- the W22 cutout is between them
    below y=296), so the halves could pivot about one fragile nub. Now TWO
    dovetails (y=300.75, 310.75), neck beefed 6 -> 7, heads 8.5, spaced
    with >=1 mm to the cutout, seam B and each other. DOVETAIL_C ->
    DOVETAILS_C (list); _right_region unions all tabs; mid_left gets the
    matching grown pockets automatically. Verified on the solids: both
    pockets at floor -9.7 (tab + 0.05), wall present between them.
    Global seam clearance CLEARANCE_MM 0.10 -> 0.05 for a snug/snappy fit
    on all seams (A/B/C) -- th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
    [lx521_coupon_1_fit_plate.stl, lx521_top_base_2of4_mid_left.stl, lx521_top_base_3of4_mid_right.stl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]
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2026-07-09 Seam A inner teeth: thicken the wall to the LM hole; seam C back to 1 tooth
    Seam A inner dovetails (mid_left's right tab, mid_right's left tab) sat
    ~1.5 mm from the LM cutout -- brittle -- because a depth-5 pocket
    reached up to y=125 where the cutout bulges to x=57. Made the inner
    teeth SHALLOW (depth 3) and moved them to +-66, so the pocket stops at
    y=123 (cutout x=54) -- wall to the hole now ~7 mm (verified on the
    solid). Outer teeth (+-103, depth 5) remain the main anchor; still
    2 teeth per mid, no pivot.
    Seam C reverted to a SINGLE tooth (per request): DOVETAILS_C =
    [(305.0, 7.0, 8.5, 4.0)], centered and beefed. 64/64 STLs manifold;
    suite green; all rebuilt.
    [lx521_top_base_1of4_bottom.stl, lx521_top_base_2of4_mid_left.stl, lx521_top_base_3of4_mid_right.stl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]
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2026-08-09 fix(top-baffle): harden Obi-Wan split interfaces
    Make the LM-to-UM and UM-to-tweeter insert receivers self-contained in their individual printable owners. Enlarge the optional LM registration pins and engagement, add driver-clear support lands plus Ac/Ae relief pockets, and regenerate the validated release artifacts and review images.
    [lx521_coupon_12_obiwan_closed_bore_bump.stl, lx521_coupon_1_fit_plate.stl, lx521_coupon_2_fit_key.stl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]
2026-08-09 Rebuild Obi-Wan magnet interfaces and artifacts
    Replace local LM and UM magnet-pocket bosses with continuous flush ring fairings, update Ac/Ae receiver spacing and metadata, harden release regressions, and regenerate the validated STEP/STL/review catalog.
    [lx521_coupon_12_obiwan_closed_bore_bump.stl, lx521_coupon_7_recess_seat.stl, lx521_top_obiwan_core_1of2_lm_carrier.stl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]
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2026-08-09 Retire C7 and V0 variants and the duplicate standalone V1 vase
    C7 (LM knife taper) and V0 (vase knife band) were design research that
    built, meshed, manifold-checked and STEP-exported for both stand states
    on every release while shipping nothing. Their modules, Makefile
    targets, clearance checks, tracked artifacts and catalog records are
    removed; geometry stays in git history. The standalone V1 vase STL was
    a byte-duplicate of the vase already shipping inside the V1L 04 piece,
    so --variant v1 now emits only the six slim attachment receivers that
    to_print actually sources; V1 geometry modules stay because V1L and the
    slim attachments import them.
    Release inventory pins move in the same chang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
    [lx521_top_c7base_1of4_bottom.stl, lx521_top_c7base_2of4_mid_left.stl, lx521_top_c7base_3of4_mid_right.stl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]
2026-08-09 Adopt product-first naming across the baffle tree
    One mechanical migration, no geometry change. The product words stock,
    slim and obiwan replace the internal code vocabulary everywhere a
    person meets an artifact:
    - 'standard' becomes 'stock' (artifacts/, generated images, catalog
    families, CAD name prefix, clearance check names).
    - Build STL stems are product-first with underscored indices:
    lx521_top_base_1of4_bottom -> stock_1_of_4_bottom,
    lx521_top_v1l_* -> slim_*, v1addon shoulders/wings -> slim_shoulder_*
    / slim_wing_*, lx521_top_obiwan_* -> obiwan_*, wing 'b' split infix ->
    split2. Coupons and the polar rig keep their diagnostic names.
    Embossed piece codes are preserved exa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
    [a_comp.step, attachments.step, b1.step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]
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2026-08-09 Settle post-validation artifact drift
    The proving candidate run re-promoted four assembly STEPs with fresh
    tessellation, refreshed one release-catalog hash, and its complete-root
    promotion dropped the locally-built bridge/root modifier pair, which is
    regenerated here.
    [attachments.step, v1_attachments.step]
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2026-08-09 Settle artifact drift from the Phase 5 proving run
    Re-promoted assembly STEPs with fresh tessellation, the refreshed
    release-catalog source revision, and the locally-rebuilt bridge/root
    modifier the complete-root promotion drops.
    [v1_attachments.step]
2026-08-09 Rename the Obi-Wan wing families to flat and graded
    The constant-depth wing family (formerly Ac) is now 'flat' and the
    weighted-depth family (formerly Ae) is 'graded' — self-describing words
    in place of the last letter codes. Slugs, build/wings and artifacts
    directories, STL/STEP stems, plate names (obiwan_flat_wings_split2_combo),
    release family IDs (Obi-Wan-Flat/Obi-Wan-Graded per the frozen-case
    gate), shelf entries and selections (flat_wing/graded_wing), Makefile
    variable and target families, live-check case names, and the wings
    module's internal vocabulary all move together, with the shelf catalog
    keeping its 51 entries.
    One real fix rode along: the wing-plate builder derived shelf f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
    [monolithic_pair.step, obiwan_flat_wings_split2_combo.stl, obiwan_wing_ac_left_1_of_3_lm_lower.stl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]
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2026-08-09 Strip the BMR crescent to a minimal pod on two struts
    The candidate coaxial crescent no longer carries the released ND
    crescent's silhouette: the inherited M4 tweeter clamp passages are
    deleted (this variant clamps no dome pair) and the outer ring shrinks
    to the unique minimum — the D66 driver land itself, since both faces
    must carry the qualified land and front-face-down printing forbids any
    rearward plan growth. Two drafted struts (8.0 mm tapering to 6.0 on a
    5-degree draft, formed by morphological closing so every blend is an
    exact fillet) connect the pod to the unchanged half-lap ears; their
    minimum section is 1.44x the half-lap's own net ligament, keeping the
    qualified joint governing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
    [obiwan_bmr_crescent_TEBM35C10-4.step, obiwan_bmr_crescent_TEBM35C10-4.stl]
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2026-08-09 Shrink the cable-entry spigot to a stadium collar round the bore
    The entry's carrier is no longer a flat-sided slab: a constant R4.20
    stadium — the bore's own sweep offset by the vase-qualified 1.20 mm
    wall — carries the mouth, clipped to the relieved skirt plan so its
    mate face is the same R51.90 arc and released seam the skirt presents.
    Plan area drops 578 to 82 mm2; the bore itself is untouched. The
    hidden-path gate gains the anti-box test (every non-inherited stretch
    of the collar boundary must lie within 0.01 mm of the constant bore
    offset) and a relief-mirror equivalence check that the silhouette gate
    exposed; the assembled front view is unchanged because the collar is
    invisible fr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
    [attachments.step, captive_magnet_pause_manifest.csv, obiwan_bmr_crescent_TEBM35C10-4.step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]
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2026-08-09 Keep candidate BMR modules out of the release prerequisite groups
    The three bmr_* modules fell through the obiwan-exclusive filter into
    GEOM_SRCS, so every BMR edit invalidated the whole stock/slim/obiwan
    CAD tree remotely despite nothing released importing them. They are
    now filtered out of CAD_SRCS_ALL; the local candidate target keeps its
    own explicit source list. Also settles the proving-run drift.
    [attachments.step, v1_attachments.step]
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2026-08-09 Heal the vase delivery against the current release schema
    The vase CAD tree predated the wing-rename schema change and its
    catalogs carried the stale schema hash, failing the delivery
    validator the new BMR machinery exposed. Rebuilt remotely and
    resliced; both profiles validate again.
    [vase_TEBM35C10-4.gcode.3mf]
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2026-08-09 Regenerate the graded wing artifacts without the uncut rim
    Output of the corrected relief chain: the graded STEP/STL family
    rebuilds with the mask overshoot, floor clamp, and mirrored-frame
    export (flat came back byte-identical as predicted), the release
    audit re-slices the changed graded pieces, and the shelf revalidates
    51/51.
    [audited_slice_project.3mf, captive_magnet_pause_manifest.csv, obiwan_bmr_crescent_TEBM35C10-4.gcode.3mf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]
2026-08-09 Rebuild the stale combo plates and put both BMR crescents on the shelf
    The graded wing combo on the shelf still carried the 10.4 mm phantom
    wall: the plate rebuild had fired against the fixed pieces and FAILED
    on its own hard-pinned triangle count (still expecting the pre-fix
    2,169,008 mesh; the rim fix drops the four split2 pieces to 734,014),
    deleting the stamp but leaving the old plate STL on disk, hard-linked
    into to_print — self-consistent with its own audit, so the shelf
    equivalence gate could not see it. The pin moves with a comment that
    it must travel with any deliberate wing regeneration; all four plates
    are rebuilt from current inputs and the shelf combo now reads
    0.561 mm agains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
    [audited_slice_project.3mf, captive_magnet_pause_manifest.csv, obiwan_bmr_crescent_TEBM35C10-4.gcode.3mf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]
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2026-08-13 Pin the outer wall at the captive-skin width on every lane
    Arachne modulated the outer bead from 0.62 down to 0.52 mm wherever a
    magnet pocket sat behind the surface, printing a visible ghost of every
    station on the exterior. Switching to classic walls would hide it but
    the fixed 0.62 mm bead spills 0.10 mm into the cavity from both skins,
    closing the loading slot below the magnet diameter.
    Pin outer_wall_line_width at 0.52 mm - the captive-skin width - on all
    three slicing profiles instead (audited override plus requirement, with
    the key whitelisted). The outer bead is now uniform across pocket and
    clean regions on both nozzles, so the stations disappear from the
    exterior while inner walls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
    [audited_slice_project.3mf, captive_magnet_pause_manifest.csv, obiwan_bmr_crescent_TEBM35C10-4.gcode.3mf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]
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2026-08-13 Reverse the Obi-Wan M2 ties so a screw can actually reach them
    The ties as first built could not be assembled. Both seated their
    heads against material with no approach corridor: at the T-UM junction
    the buried tweeter cover fills the UM's rear recess completely, so the
    counterbore was a blind pocket in solid material, and at the LM-UM
    crown the same cover crosses the flange void about four millimetres
    under the lip, leaving too little room to introduce an M2 x 8. The
    plan and section audits both passed them, because a declared hole is
    indistinguishable from a reachable one.
    Turn each tie around to the side that has a corridor. The LM-UM head
    now sits just inside the UM driver recess, which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
    [captive_magnet_pause_manifest.csv, obiwan_01_02_03_04_LM_UM_combo_floor_stand.stl, obiwan_01_02_03_04_LM_UM_combo_no_floor_stand.stl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]
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
